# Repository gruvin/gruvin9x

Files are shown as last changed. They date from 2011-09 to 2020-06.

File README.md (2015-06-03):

# This project has been superseded by [openTx](https://github.com/opentx/opentx) and [Fr-Sky's Taranis](http://www.frsky-rc.com/product/pro.php?pro_id=113) RC Transmitter

## gruvin9x
### This outdated archive was recreated from [https://gruvin9x.googlecode.com/](https://gruvin9x.googlecode.com/) for historical reference and for the many still running gruvin9x boards or its dirivitives. A friendly shout out to you all! :-)

<h2>G9X v4.x BOARD (DISCONTINUED)</h2>

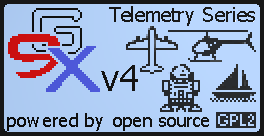
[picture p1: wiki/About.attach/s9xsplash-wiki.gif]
Why? Because there's much better things on the horizon -- we think. Trusted sources confirm the ongoing development of a Fr-Sky X9D transmitter, which we understand will be supporting open9x firmware form launch. The board will be ARM 32-bit based and is rumoured to be targeting sub-USD$100 retail -- complete with Fr-Sky 16-channel transmitter module, built in. If this all turns out to be true, then the complete radio will cost less than the G9X board (in the small qty's we can manage) whilst having all the same features and more. So we wait.

We simply don't know if demand for the G9X system will continue -- or not. Whilst orders seem to still be trickling in -- now even for blank boards (wow!) -- we don't expect that to last. Right or wrong, Gruvin made the choice, not to risk funds on another batch of G9X v4.2 boards. Was it the right choice? Have your say at <a href='http://9xforums.com/forum/viewforum.php?f=66'>9xforums.com</a>.<br>

<h2>We recommend openTx firmware</h2>

Please visit the [openTx website](http://open-tx.org) or the [openTx project on GitHub](https://github.com/opentx/opentx) for more information.

---

<h2>Gruvin9X Project Brief</h2>
<blockquote><i>First off, we especially wish to thank all the amazing original and ongoing work by</i>Thomas Husterer<i>of the <a href='http://code.google.com/p/th9x/'>th9x project</a>. A good number of other people have also contributed ideas, code and more to his, this and other related projects. THANK YOU all!</i></blockquote>

The gruvin9x project was originally forked from <code>er9x v1.1 r262</code> (<a href='http://code.google.com/p/er9x/source/browse/?r=262'>http://code.google.com/p/er9x/source/browse/?r=262</a>) which was based on a earlier version of the original th9x code. A huge amount effort was later put into the gruvin9x code base by contributor bsongis, of the <a href='http://open9x.googlecode.com'>open9x</a> and <a href='http://companion9x.googlecode.com'>companion9x</a> projects, which later became the sole point of focus for our custom hardware firmware support.<br>

<b>Highlights ...</b>
<ul><li><a href='wiki/About.md'>Project Wiki Documentation</a>
</li><li><a href='wiki/ReProgram.md'>Re-programming Your 9X Radio</a> -- firmware downloads, flashing, etc.<br>
</li><li><a href='wiki/PCB.md'>Custom Main Board Development</a> -- <b>upgrade your '9X controller board!</b></li></ul>

<h2>But what <i>is</i> it?</h2>
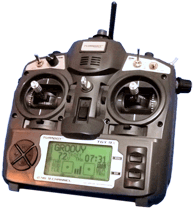
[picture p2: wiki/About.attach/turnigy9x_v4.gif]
In short, this is an RC modeller/hacker's dream come true. We get to use your own custom firmware in our radios, adding features and making changes whenever we like and all (generally) at much lower cost than comparable commercial gear -- especially in terms of firmware features and programmability. We currently support any PPM transmitter module, with a focus on Fr-Sky two-way products, as well as DSM, DSM2 and DSMX 'retro-fitted' modules, usually salvaged from cheap 4-ch bind'n'fly models, as found on eBay.<br>

Open9x firmware is written and maintained by active RC modellers. It is mature, stable and very powerful. Based on th9x's 'multiplexer' implementation, it is arguably a little difficult to learn compared to other systems -- but is much more flexible. Open9x firmware is a significantly more powerful replacement for the comparatively simple default factory firmware that comes with the '9X radios.<br>

The <a href='wiki/PCB.md'>gruvin9x custom controller board</a> was developed using a larger version of the original Atmel AVR chip, to give us more RAM, firmware code space and more I/O connections for additional peripherals, such as telemetry data port, RTC/SD-card interface and more.<br>

If your existing transmitter doesn't do something you wish it would, chances are that open9x already does. If it doesn't, then put in a feature request and, if it makes sense to others, then the firmware will likely soon perform your new function.<br>

Both the open9x firmware and the companion9x (desktop) projects support our poplar <a href='wiki/PCB.md'>G9X v4 Custom Controller board</a>.<br>

<blockquote><i><b>Caveat</b>: Firmware is  half the story -- quality of hardware is not a given and should also be carefully considered. Whilst the build quality of most 9X radios seems just fine, there have been notable exceptions. We therefore strongly recommend that all firmware functions as well as internal radio soldering joints and physical gimbal assembly be carefully checked, before committing a 'cheap' 9X radio controlled aircraft to the skies. SAFETY FIRST!</i></blockquote>

The original <a href='http://code.google.com/p/th9x/'>TH9X project</a> was (and very much still is) about completely replacing the factory supplied operating system in the Turnigy/Eurgle/iMax/Fly-Sky/etc 9X Remote Control transmitter from China -- currently retailing for around USD$40 -- HOW, we do not know!<br>

From there, other projects then spawned (were forked forked) from TH9X, including ER9X and gruvin9x. More are likely to follow as different interest focuses emerge. In our case, the focus was originally on providing practical Fr-Sky telemetry support and more recently, the design and production of an <a href='PCB.md'>custom controller board</a>, to be a drop-in, upgrade replacement for the stock '9X system controller.<br>

There's more about gruvin9x on the <a href='wiki/About.md'>About</a> wiki page.<br>

<h3>Documentation</h3>

## Best Source of Information for openTx (June 2015)
Head over to <a href='http://www.open-tx.org/'>http://www.open-tx.org/</a>

For G9X hardware or historical information, please consult the <a href='wiki/About.md'>project wiki</a> in the first instance, as well as the <a href='firmware/doc'>firmwar/doc/ directory</a>  for ~~all currently available~~ archival gruvin9x documentation.<br>

<h3>Other '9X OS Replacements</h3>

There's also at least one other project taking on the same basic goal, but of completely different design and unrelated to the TH/ER/gruvin9X projects. It's named Radio Clone, can be found at <a href='http://radioclone.sourceforge.net/'>http://radioclone.sourceforge.net/</a> and is well worth checking out.<br>

<h2>Downloading gruvin9x Firmware and Flashing Your Radio</h2>

For details on installing new firmware into you Turnigy/iMax/Eurgle/etc 9X RC Radio, see the <a href='FlashGuide.md'>Flash Guide</a> wiki page.<br>

<h2>Getting the gruvin9x Source Code</h2>
See the <a href='wiki/CompilingFromSource.md'>Compiling from Source</a> wiki page.<br>

<h2>Get Involved!</h2>
An independent group maintain an, 'all things 9X' forum over at <a href='http://openrcforums.com'>http://openrcforums.com</a>. The forum caters to several different firmware projects, has a documentation wiki attached and is probably the most popular hang-out for '9X enthusiasts and much more besides. Frankly, it's freaking AMAZING! Go check it out.

## Gruvin9X Project Wiki</a>
(converted from old Google Code site)

* [About gruvin9x](wiki/About.md)
* [G9X Features](wiki/Features.md)
* [Screen Shots](wiki/Features.md)
* [General FAQ](wiki/FAQ.md)
* [Re-progamming Your Radio](wiki/ReProgram.md)
 * [Latest Stable Binaries](wiki/LatestRelease.md)
 * [Development Binaries](wiki/DevBinaries.md)
 * [Flashing Binary Versions](wiki/FlashGuide.md)
 * [Compiling from Source](wiki/CompilingFromSource.md)
 * [Make Options](wiki/MakeOptions.md)
* [Custom PCB (v4.x)](wiki/PCB.md)
 * [Custom Schematics](wiki/Circuitry.md)
 * [Build Your Own Board](wiki/PcbAssembly.md)
 * [SD Card Installation](wiki/SdcardBoard.md)
 * [9X Reference Data](wiki/TurnigyV2.md)
  * [Reference Images](wiki/ReferenceImages.md)
  * [V2 Circuit Schematic](wiki/SchematicV2.md)
  * *[v4.x Custom Board FAQ](wiki/V41FAQ.md)*
  * *[Get your own PCB made](wiki/PCBFab.md)*
* [USB Programmer](wiki/GProg.md)
* [Telemetry](wiki/Telemetry.md)
 * [Fr-Sky Support](wiki/FrSky.md)
 * [Fr-Sky Interfacing](wiki/FrskyInterfacing.md)
 * [Fr-Sky on your Mac](wiki/FrSkyTerminalOSX.md)
 * [Porting to ER9X](wiki/FrskyToER9X.md)
* [Donator Recognition](wiki/Recognition.md)
* [Random Notes](wiki/RandomNotes.md)
 * [AoA / LRI Notes/Ideas](wiki/AoA.md)
 * [Backlight Information](wiki/BackLight.md)
 * [eePe EEPROM file manager](wiki/eePe.md)
 * [PPM-in Compatibility (Hack)](wiki/PpmIn.md)
 * [Ni-Mh packs! Or not?](wiki/PowerCells.md)
 * [Repeat Delay](wiki/RepeatDelay.md)
 * [Speaker Upgrade](wiki/SpeakerReplacement.md)
 * [Voltage Averaging](wiki/VoltageAveraging.md)

## External Links
 * <a href="http://open-tx.org" rel="nofollow" style="font-size:2.0em"><b>openTx</b></a>
 * <a href='http://code.google.com/p/er9x/'>Original ER9X Project Home</a>
 * <a href='http://code.google.com/p/th9x/'>ORIGINAL, Original TH9X Project Home</a> "Respect!" :-D
 * <a href='http://sourceforge.net/apps/mediawiki/radioclone/'>Radio Clone Project</a> -- Something different and well worth checking out.
 * <a href='http://www.rcmodelreviews.com/tendollarbattery.shtml'>$10 Li-Ion Battery Pack Upgrade</a>
 * <a href="http://code.google.com/p/frsky-terminal/" rel="nofollow">FrSky Terminal (OS X)</a>
 * <a href="http://openpnp.org/wiki/index.php/Main_Page" rel="nofollow">OpenPnP</a>
 * <a href="http://www.rcgroups.com/forums/member.php?u=301789" rel="nofollow">Argos&#39;s &#39;9X Modd&#39;ing Blog</a>
 * <a href="http://code.google.com/p/er9x/" rel="nofollow">er9x</a>
 * <a href="http://code.google.com/p/th9x/" rel="nofollow">th9x</a>
 * <a href="http://radioclone.org/" rel="nofollow">radioclone</a>
 * <a href="http://9xforums.com/forum/" rel="nofollow">9X Forums</a>
 * <a href="http://companion9x.googlecode.com" rel="nofollow">companion9x</a>
 * <a href="http://www.fsf.org/about/what-is-free-software" rel="nofollow">What is &#39;free&#39; software?</a>

```

```
<h3>DISCLAIMER</h3>
Whilst the gruvin9x project owner(s) aim to provide as much help to as many Turnigy/iMax/Eurgle/etc '9X users as practical, any perceived enthusiasm on their part to lure people into using gruvin9x over any other version, would be erroneous. This project was originally created primarily for the author's own use -- and of course to 'give back' to the Open Source Community, as the <a href='http://www.gnu.org/licenses/gpl-2.0.html'>GNU General Public License (V2)</a> requests. Anyone is welcome to use this code according to said license, as is, where is and indeed to submit suggestions for changes, improvements, additions, etc. The author welcomes comments, constructive criticism, assistance and general feedback but accepts no responsibility for anything what-so-ever that use of any information contained on this website may or may not be claimed to cause. Use at your own risk. Any opinions offered by this internet resource are expressly, only opinions. (Any information claiming to be fact but not legally verified as fact in actuality, must of course be considered mere opinion, regardless of context.) All care is taken, but no responsibility is accepted for the level of accuracy of any information here or anywhere the author may post text, images, video, audio or other content. Any and all images, photographs, charts, lists or graphical representations of any kind are intended for educational or indicative purposes only and may or may not accurately represent any given subject, topic or fact at any given time. Indeed, any such depictions are subject to change at any time for any reason without notice. Any monetary figures, presented by whatever means, are for indicative, informational or educational purposes only and all such figures are subject to change at any time without notice. The use of sarcasm may or may not feature throughout this internet resource and other, related or linked media, and as such is intended purely as light-hearted humour. No responsibility is accepted for anything what-so-ever relating to perceived truths related to such believed communications. Reader/viewer/listener beware! Any views expressed by individuals other than project owner(s) may or may not agree with the projects goals, intentions or license and no responsibility is taken for any such view or views under any circumstance. Any views so interpreted as being those of the gruvin9x project owner(s) should be taken as potentially inaccurate and with the acceptance that any views, expressed or implied, are at all times subject to change without notice. This disclaimer falls within the above conditions, being itself subject to change at any time without notice. In light of the afore mentioned disclaimers, readers should take heed of the possibility that they may be, a) potentially crazy for reading this far in the first place and, b) that this disclaimer itself, though quite serious, is in part also intended for entertainment purposes. Etc, etc, blah blah. You know the drill. Love and peace to all! Now let's get on with it. :-D

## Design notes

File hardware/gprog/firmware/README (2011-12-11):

USBasp Firmware, modified for use with gruvin9x custom controller board.

The USBasp original author's project site is at: http://www.fischl.de/usbasp/

NOTES ...

As at 2011-12-11, GPROG is NOT ready for use. There's a problem with the buffer
chip tying up the MOSI/MISO/SCK/RESET lines. The fix will required changed to the
hardware design.

This version of USBasp is based on the original 2009-02-28 version -- the last
one to fit in the ATmega48P -- with the support added from the 2011-05-28
version to implement extended addressing for target AVR chips with greater than
128KBytes Flash, like the ATmega2560 that we use.

There was (still is as at 2011-05-28 version) a bug  in the original USBasp
code for extended addressing in that it assumed that the target chip's extended
address would be automatically reset to 0x00 after power-up and/or entering
programming mode. This is not the case. In fact, I found the extended addresses
contents to be somewhat random, usually causing all the programmed code to wind
up 64KBytes higher in address space than it should have been.

The default SCK clock speed has been increased from 375KHz to 1.5MHz, although
the gain is not that much, due to the software implemented USB stack taking up
quite a lot of CPU time.

Strangely, having the brown-out detector on the ATmega48 enabled causes my
(Gruvin) Mac (running OS X 10.7) to not detect the USBasp device. So I've
disabled the BOD feature, apaprently without ill effect.

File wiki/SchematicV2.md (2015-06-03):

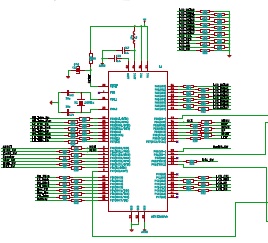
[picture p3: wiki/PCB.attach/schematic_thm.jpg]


<h1>Turnigy/iMax/Eurgle/etc 9X RC Transmitter Version 2 (V2) Schematic</h1>

There exists (in trunk/doc) a PDF circuit schematic, which appears to be from the version 1 radio. Here is link to a V2 schematic, which includes a couple of changes, most notable being the addition of a regulator and voltage-splitter resistor network to drive a 3.3V LCD display.<br>
<br>
Here is a link to the our version of the <a href='https://code.google.com/p/gruvin9x/source/browse/#svn%2Freference%2Fv2_stock_9x'>factory stock 9X schematic</a> files.

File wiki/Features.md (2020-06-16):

# This project has been superseded by [opentx](http://opentx.googlecode.com/) #

The following data is likely obsolete, kept here for mostly just for historical record.

# G9X Features

## Screen Shots

### Main Screen
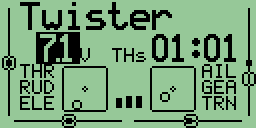
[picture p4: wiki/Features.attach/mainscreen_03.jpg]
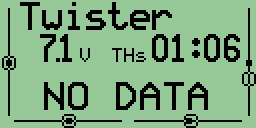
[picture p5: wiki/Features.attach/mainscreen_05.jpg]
 

### Model selection
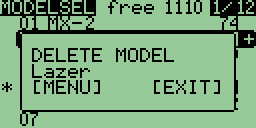
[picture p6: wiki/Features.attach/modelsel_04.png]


### Flight Phases
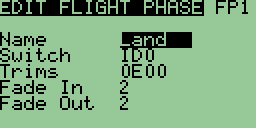
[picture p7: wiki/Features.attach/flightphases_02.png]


### DR/Expos Screens
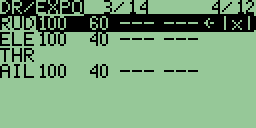
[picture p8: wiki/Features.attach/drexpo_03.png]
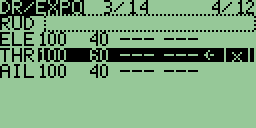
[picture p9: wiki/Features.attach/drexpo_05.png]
 

### Calibration
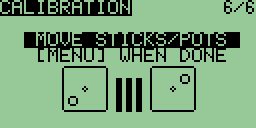
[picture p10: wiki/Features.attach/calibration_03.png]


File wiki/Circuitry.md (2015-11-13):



<h1>Custom '9X Logic Board PCB Schematics</h1>

The custom circuitry for Gruvin's '9X has gone through a number of versions, and continues to evolve.<br>
<br>
<h2>Current Design</h2>
The final version of the G9X board was v4.2d.

- - - -

Archival information ...

Ongoing schematic and PCB design currently takes place at <a href='http://gruvin9x.googlecode.com/svn/trunk/hardware/pcb/'>http://gruvin9x.googlecode.com/svn/trunk/hrdware/pcb/</a>. There you'll find a <a href='http://kicad.sourceforge.net/wiki/Main_Page'>KiCAD</a> project file named <code>gruvin9x.pro</code>, with internal references to <a href='http://gruvin9x.googlecode.com/svn/trunk/pcbv4/gruvin9x.sch'>gruvin9x.sch</a> and <a href='http://gruvin9x.googlecode.com/svn/trunk/hardware/pcb/gruvin9x.pcb'>gruvin9x.pcb</a>.<br>
<br>
<b>As at 22 September 2011, we've progressed to v4.0</b> and are working hard to release a board for general consumption. It is our firm intention to finally do just that with v4.1, hopefully before December, 2011. Version 4.0, final prototypes have been assembled (x4) and are being tested and debugged. A number of beta testers are being lined up for the first few v4.1 production boards. Simply put, we're going as fast as we can.<br>
<br>
You can find detailed information about the new board's intentions, current functionality and progress on the <a href='PCB.md'>Custom PCB</a> wiki page.<br>
<br>
Check out the source tree in the <a href='http://code.google.com/p/gruvin9x/source/browse/#svn%2Ftrunk%2Fhardware%2Fpcb'>/trunk/hardware/pcb</a> folder for the latest work-in-progress design files.<br>
<br>
<h1>Historical Data</h1>

<h2>First Prototype</h2>
The first physical prototype, 'rev 2.14' PCB design, schematic and production files, as sent to the PCB fabrication factory in December of 2010, can be found at <a href='http://gruvin9x.googlecode.com/svn/archive/pcb/pcb-v2.14-frozen'>http://gruvin9x.googlecode.com/svn/archive/pcb/pcb-v2.14-frozen</a>. There's a PDF version of the schematic, <a href='http://gruvin9x.googlecode.com/svn/trunk/pcb/rev2.14-frozen/gruvin9x.pdf'>here</a>.<br>
<br>
<h3>Original 'Hacked' Radio</h3>
Gruvin's original '9X radio was the original test bed for much of pre-v3-PCB work. As such, it remains a reference for people wishing to manually modify factory stock '9X radios for use with Fr-Sky telemetry. There's an historical PDF version of the schematic for this 'hacked' board, <a href='http://gruvin9x.googlecode.com/svn-history/r800/trunk/pcb/hacked/gruvin9x-hacked.pdf'>here</a>.<br>
<br>
If you have a stock '9X radio and would just like to add basic Fr-Sky telemetry functionality to it, then there are (hopefully) easy to follow instructions on the <a href='FrskyInterfacing.md'>Fr-Sky Interfacing</a> wiki page.

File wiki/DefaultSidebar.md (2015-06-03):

# G9X Wiki
## Table Of Contents

* [About gruvin9x](About.md)
* [G9X Features](Features.md)
* [Screen Shots](Features.md)
* [General FAQ](FAQ.md)
* [Re-progamming Your Radio](ReProgram.md)
 * [Latest Stable Binaries](LatestRelease.md)
 * [Development Binaries](DevBinaries.md)
 * [Flashing Binary Versions](FlashGuide.md)
 * [Compiling from Source](CompilingFromSource.md)
 * [Make Options](MakeOptions.md)
* [Custom PCB (v4.x)](PCB.md)
 * [Custom Schematics](Circuitry.md)
 * [Build Your Own Board](PcbAssembly.md)
 * [SD Card Installation](SdcardBoard.md)
 * [9X Reference Data](TurnigyV2.md)
  * [Reference Images](ReferenceImages.md)
  * [V2 Circuit Schematic](SchematicV2.md)
  * *[v4.x Custom Board FAQ](V41FAQ.md)*
  * *[Get your own PCB made](PCBFab.md)*
* [USB Programmer](GProg.md)
* [Telemetry](Telemetry.md)
 * [Fr-Sky Support](FrSky.md)
 * [Fr-Sky Interfacing](FrskyInterfacing.md)
 * [Fr-Sky on your Mac](FrSkyTerminalOSX.md)
 * [Porting to ER9X](FrskyToER9X.md)
* [Donator Recognition](Recognition.md)
 * [Random Notes](RandomNotes.md)
 * [AoA / LRI Notes/Ideas](AoA.md)
 * [Backlight Information](BackLight.md)
 * [eePe EEPROM file manager](eePe.md)
 * [PPM-in Compatibility (Hack)](PpmIn.md)
 * [Ni-Mh packs! Or not?](PowerCells.md)
 * [Repeat Delay](RepeatDelay.md)
 * [Speaker Upgrade](SpeakerReplacement.md)
 * [Voltage Averaging](VoltageAveraging.md)

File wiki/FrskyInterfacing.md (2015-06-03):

# This project has been superseded by [opentx](http://opentx.googlecode.com/) #

The following data is likely obsolete, kept here for mostly just for historical record.

# Fr-Sky Interfacing #

Gruvin (more or less) followed the original TH/ER9X 'JETI' wiring instructions to get RS-232 (TTL level) TX and RX signal for my Fr-Sky two-way transmitter module. Those instructions can be found [here](http://code.google.com/p/er9x/wiki/JETI).

Below, you'll find similar and extra detail of exactly how I hooked up my Fr-Sky unit.

## Accessing TXD and RXD on the ATmega ##

The ATmega RXD and TXD special-purpose pins are used for simple switch inputs in the factory '9X -- namely, Throttle-Cut and Aileron-D/R, respectively.

To free these pins up for use with serial data, we need to move those two switches elsewhere. The two pins chosen for their new home were pins 41 and 42, or PC6 and PC7 respectively.

The modification requires the use of _really fine_ wire. I used 0.2mm, enamelled copper wire. You can also use fine, insulated wire, salvaged from the newer (yet now old) high-density computer IDE cables. Each of these wires is a _single-core_, PVC insulated wire. You most definitely do _not_ want to try and use any kind of multi-strand wire -- no matter how fine it it is.

**IMPORTANT**: The main reason to use _really_ fine wire may not be what you think. It is certainly possible (though more difficult) to use heavier, stronger wire. But doing so will increase the risk of accidentally damaging the delicate ATmega chip's pins. (Think of it as using a wrecking bar to pick your teeth -- or something like that! :P) In practice, the slightest accidental tug by 'big fat, shaky, human hands on a big fat wire', can quite literally rip an ATmega pin right of the chip. Trust me -- _use really fine wire!_

### Re-wiring Procedure ###

Referring to the image below ...

  * Remove the two left-hand-most resistors as indicated in yellow
  * Hot glue a couple of 220ohm resistors (1/8th or 1/4watt are OK) to a nearby, clearish area of the PCB
  * Solder your 'super fine' wires to pins 41 and 42 of the ATmega and connect to the top end of the resistors as shown. Use alcohol if required -- to steady your hands! (Just joking -- but if it works for you -- go right ahead. :p)
> _HINT: Pre-solder the wire end and the ATmega pins. Use a solder sucker or de-soldering wick to clear away excess solder from the two pins and to remove any solder bridge. Then lay the first wire end over the pin and apply the soldering iron directly down on top of it for half a second, then directly straight up -- then let go the wire. Give the wire a gentle tug in the direction directly away from the chip (in line with the pin).If it holds -- you're done. Don't futz with it. If you're right handed, solder the left hand wire first, so the the soldering iron does not lay over the first wire when trying to solder the second._
  * Solder wires from the bottom ends of the hot-glued resistors to the little vias (holes) near where the two removed resistors were, as shown in the image.

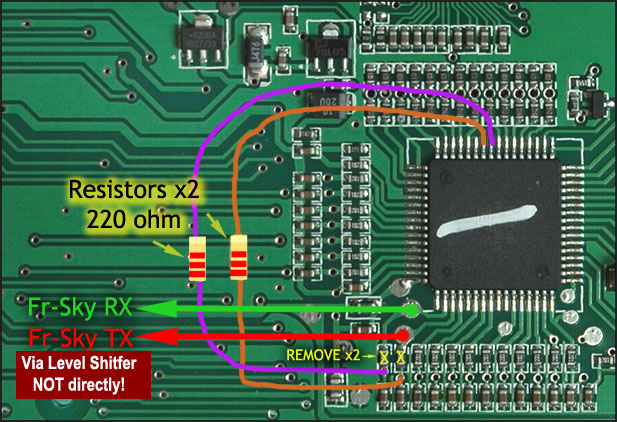
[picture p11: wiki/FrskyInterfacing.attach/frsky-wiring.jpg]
> 

**NOTE:** It pays to use small dabs of hot-glue near the ATmega pins and in a couple of places along the wires to hold them in place. The last thing you want is for something to get hooked under them and rip them off, possibly damaging the ATmega pins in the process!

## The Interface ##

Fr-Sky, in their wisdom, decided to use RS-232 voltage levels for their interface, rather than provide a more modern 5V TTL-to-serial USB interface. We tried to talk them out of it, but they stuck to their guns. Oh well.

What this means is that you need to invert and voltage-shift the signals to and from the Fr-Sky transmitter module, so they can play happily with the 5 Volt ATmega chip. There are specialised 5V TTL to RS-232 chips to do this, "properly". But we show here is a simple and in fact _advantageous_, discrete transistor method.

> _Advantageous? Well yes, actually. The method shown below allows the transmitter module to still operate -- for both hosts simultaneously -- when connected to an external serial interface, say on a computer -- while not having to disconnect the internal wiring to the '9X. With the values shown, most computers will take precedence over the internal 9X ATmega micro in terms of sending (transmitting) data to the Fr-Sky module. **More useful even**, is that you don't have to disconnect the telemetry interface for re-Flashing. Clever huh! (In truth, this was a lucky fluke! :P)_

> _That said, be careful not to have your Fr-Sky two-way receiver switched on during re-flashing, as the stream of data_will_collide with the ISP programming signals and could mess up your ATmega chip._

Here is the discrete transistor circuit ...

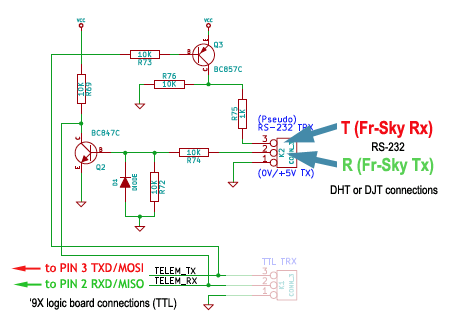
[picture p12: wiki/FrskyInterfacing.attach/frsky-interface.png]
> <br />
**NOTE** An earlier version of the above circuit had the collector and emitter of Q3 reversed. The circuit as shown here now is correct. (This circuit is clipped from the full schematic of the gruvin9x [custom controller board](PCB.md).)

Any general purpose NPN and PNP transistors should work for the components marked Q2 and Q3, respectively. The BC847/857 devices are in fact SMD surface mount versions, as used in the new PCB design we're working on.

For the prototype, Gruvin actually used a dremel too to carve up the mostly unused, legacy PCB mounted inside the '9X rear casing to build the above circuit 'dead bug' style. (A photo is not presently available.)

**ADDENDUM**: A future version of this circuit (v4.2) uses 5.1K-Ohm resistors in place of all the 10K and a 1K across Q3's E/C leads to improve the 'squareness' of the TX signal for use with DSM2 modules at 125,000bps. This change is in no way required for 9600 Baud Fr-Sky operation however.

## Ground Loops (WARNING) ##

Gruvin found that the Fr-Sky module refused to operate correctly if a ground (GND) wire was connected between the Fr-Sky module's rear RX/TX/GND pins and the level-shifting circuit above. The problem was probably RF energy pick-up through the ground-loop created by having two ground wires -- one where the module plugs into the 9X and the other from the serial data port. **Solution:** simply do not connect the ground wire as shown as pin-1 on the connector-K2 in the circuit above. Others have since said that they had no such problem. YMMV

### ER9X Compatible ###

In case you're wondering, this wiring modification is 100% compatible with the JETI and Fr-Sky telemetry extensions in the [ER9X](http://er9x.googlecode.com/) firmware, too.

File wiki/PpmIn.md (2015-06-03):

# This project has been superseded by [opentx](http://opentx.googlecode.com/) #

The following data is likely obsolete, kept here for mostly just for historical record.

# PPM-in Compatibility (Hack) #
**Relates to [Issue 15](https://code.google.com/p/gruvin9x/issues/detail?id=15)**

While working on various problems with PPM-in (aka. trainer/trainee) system, I discovered that Spektrum branded radios do not supply a signal capable of being used by the stock '9X radio's electronics.

Spektrum (and I presume JR? And Futaba?) output their PPM signal (via the phono jack on the back) as an approx. 1.5V peak-to-peak signal, which is also capacitively decoupled.

This scheme actually makes sense to me because it, a) prevents potential damage if the lead is somehow shorted out and, b) is much less likely to in any way inadvertently load or 'spike' the host or slave device in a way that could crash the CPU.

I have no idea what the Futaba/JR/Hi-tech scheme for this is, but I do have two Spektrum radios and I wanted them to be usable as trainer/trainee slaves with my Turnigy '9X. So, out came the soldering iron, once again.

I broke the track leading from the 4066 quad-switch chip (pin 8) and into PE7 on the ATmega, then inserted an NPN buffer transistor -- essentially to 'amplify' the 1.5V signal back up to 5V-TTL for the ATmega. A side-effect of this that the signal gets inverted. (I could have used a PNP transistor to prevent the inversion, but that would have created other issues.) The inversion was easily fixed by changing a single binary bit in the program code. This is optional of course -- please see the notes for `PPMIN=` on the [Make Options](MakeOptions.md) wiki page.

> _As of this writing, this code change is only available in the `branches/frsky` development repository. But I'm sure it will make its way into the `trunk/` area quite soon._

Here is the additional circuitry, which has been tested to work well with two Spektrum and one '9X radio, thus far.

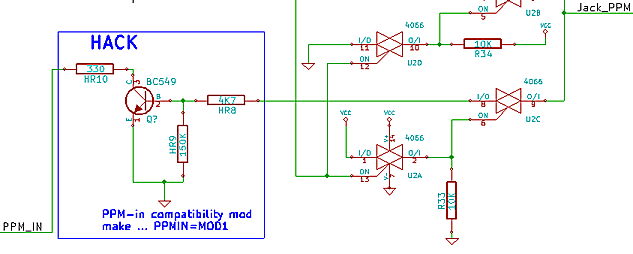
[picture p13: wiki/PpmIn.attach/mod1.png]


> _Resistor HR10 (330ohm is what I had on hand) proved important. Without it, the relatively high current sink from the transistor against the ATmega's internal pull-up was able to spike the ATmega's power supply sufficiently to cause the odd crash. I imagine the net resistance of the 4066 was sufficient 'spike' protection, before this mod. **shrug**_

# The Future (Custom PCB V3+) #

I will definitely include at least this mod in the V3 PCB (after the V2 prototype has had its potential bugs ironed out). I may go further to include a capacitive decoupling arrangement, and hopefully remove the need for the 4066 altogether.

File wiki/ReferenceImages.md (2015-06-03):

# Hardware Reference Images #

Here are some annotated photos of various '9X hardware components to assist with part identification, PCB replication, LCD replacement, etc.

Note: Some of the images are fairly high resolution on purpose.

## LCD Screen ##
We believe the following are the main specifications of this display ...
  * Dimensions:  77 x 48mm.
  * Pixel View Area: 66.52mm x 33.24mm -- 2.9" diagonal (0.48mm sq. pixels with 0.04mm gaps)
  * Front Polariser: Transmissive (Adhesive)
  * Back Polariser: Transflective (Adhesive)
  * Display Mode: FSTN
  * Viewing Angle: 90-degrees perpendicular (6:00 o'clock)
  * Controller IC: **ST7565P** (very common) -- "chip on glass" version
  * Operating Voltage: 3.3V (not 3.0V)
  * Connector: COG+FPC 30-pin, 0.5mm pitch
  * Manufacturer: Unknown
  * [Mechanical data sheet](ReferenceImages.attach/lcd-display-mechanical.pdf) for similar display,  [here](ReferenceImages.attach/lcd-display-mechanical.pdf). (Thanks [@devnow](https://code.google.com/u/100578513419733812290/).)

  * **Replacement part availability** ...
    * Try [eBay.com](http://www.ebay.com)
    * Or [www.BuyDisplay.com](http://www.buydisplay.com). I found nothing the same size with the same 30-pin connector, at BuyDisplay. But there is [this one](http://www.buydisplay.com/default/2-9-inch-cog-lcd-module-128x64-display-arduino-st7565p-white-on-black.html) at US$6.52, which is the right size and controller chip, but a 26 contact cable. :-/ There is also a smaller 2.1" display, which would fit in a '9X and does have the right 30-pin cable.
    * The [R2Hobbies](http://www.r2hobbies.com/eng/proddetail.php?prod=rcps2845001) supply of TH9X spare part displays has dried up.

- - -

I've not personally owned a V1 '9X, but apparently the V2 changed from a 5V LCD screen to a 3.3V version. An additional 3.3V regulator and a bunch of voltage-divider resistors are used to interface this to the 5V ATmega64A MCU.

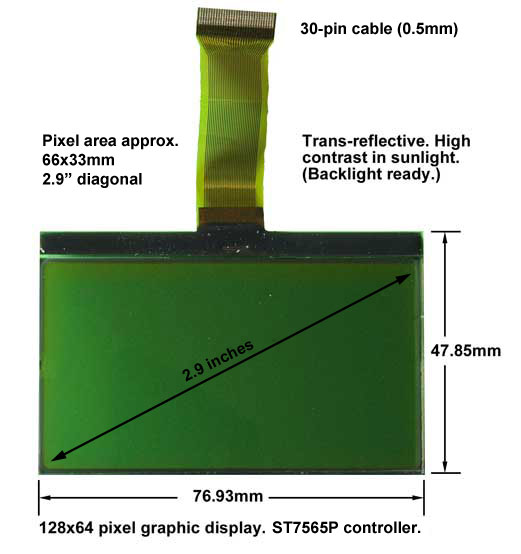
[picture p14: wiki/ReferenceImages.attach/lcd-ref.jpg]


## Connectors ##
See the PCB reference images for approx. dimensions. (Ignore the strange looking coil of wire to the middle-left. It's not part of the stock hardware.)

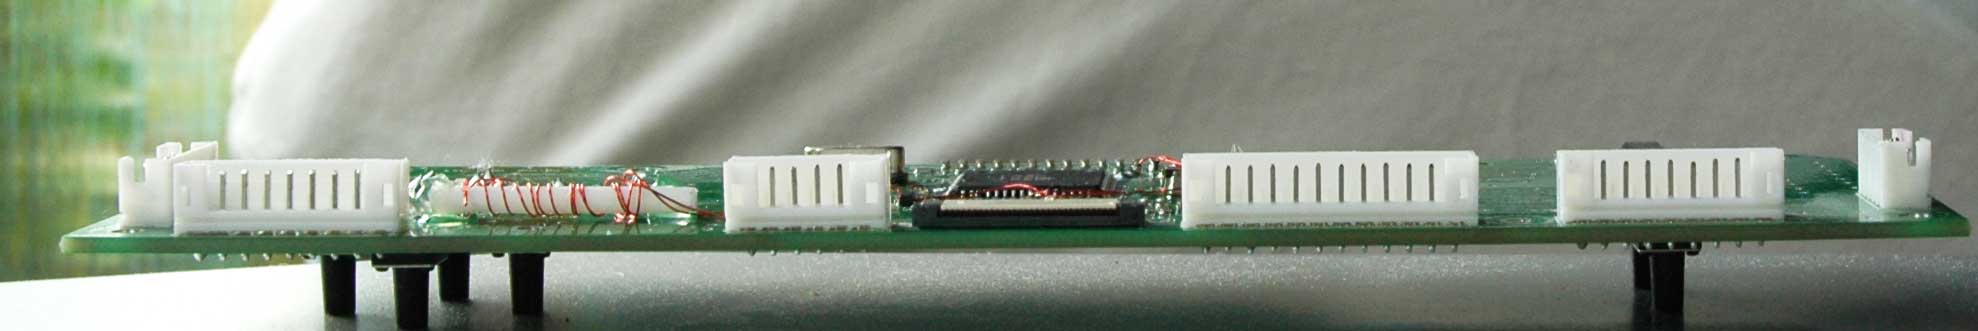
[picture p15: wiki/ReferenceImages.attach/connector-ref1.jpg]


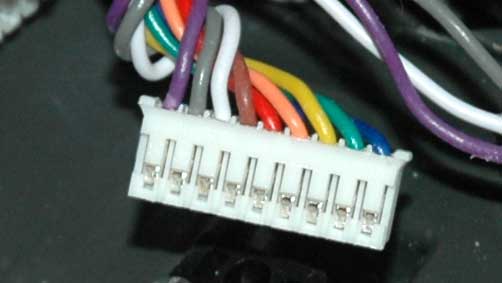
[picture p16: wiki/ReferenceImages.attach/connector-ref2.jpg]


Japanese "JST" brand -- 2mm pitch (there's a larger version as well.) Quite common.<br>
<br>
<h2>Inside</h2>

Inside the front section of the cabinet (main PCB removed).<br>
<br>
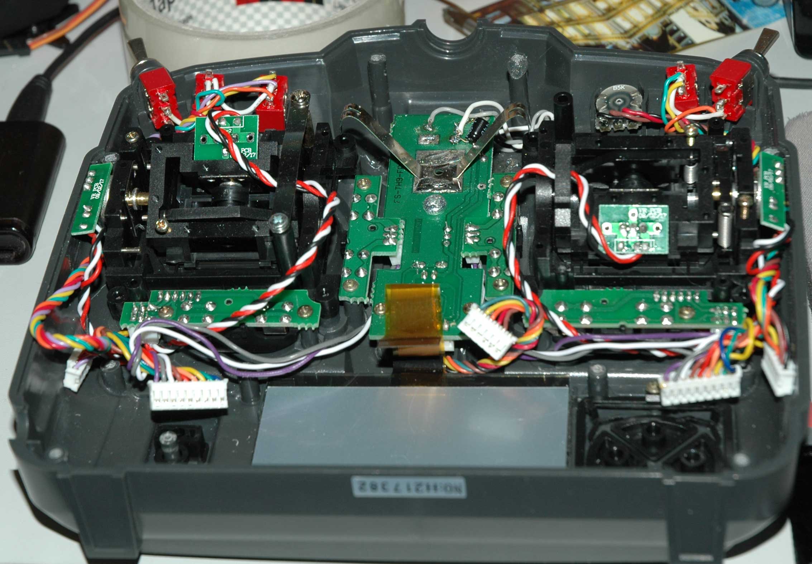
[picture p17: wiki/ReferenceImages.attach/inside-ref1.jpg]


<h2>Main PCB</h2>

My '9X is a Turnigy 9X from HobbyKing.com. This is the "V2" version. Note the additional 3.3V regulator (left of the 5V one) and bunch of resistors above the ATmega64A MCU for driving the 3.3V LCD screen.<br>
<br>
<h3>Top</h3>

NOTE: These images are fairly high resolution -- Right-Click, View Image (or Save as...) to see full size. WARNING: Perspective errors in the camera lens mean the reference lines are approximate only.<br>
<br>
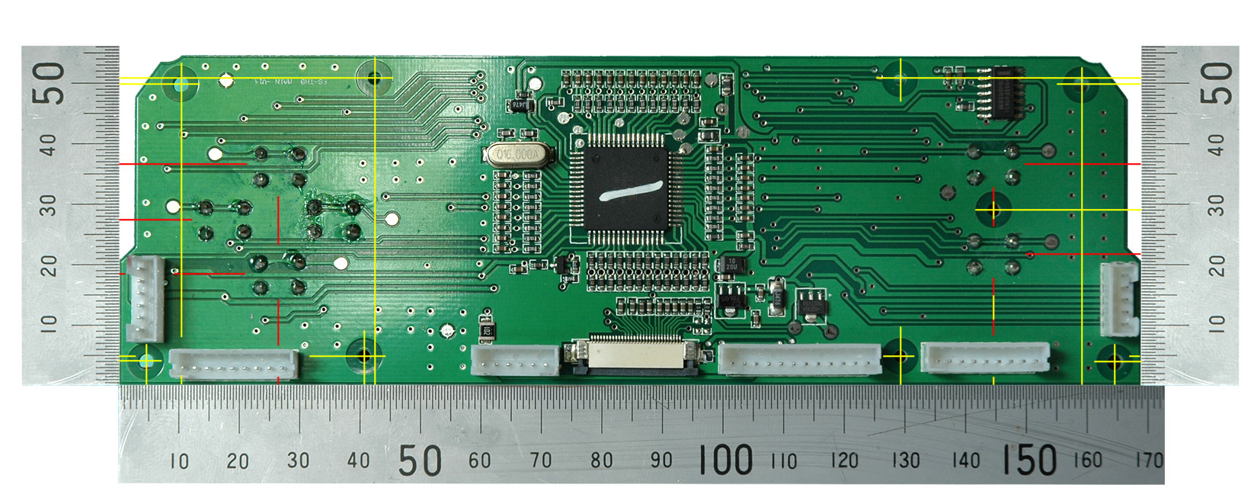
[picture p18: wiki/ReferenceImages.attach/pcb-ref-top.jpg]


<h3>Bottom</h3>

This is the bottom of my second unit (to match image above).<br>
<br>
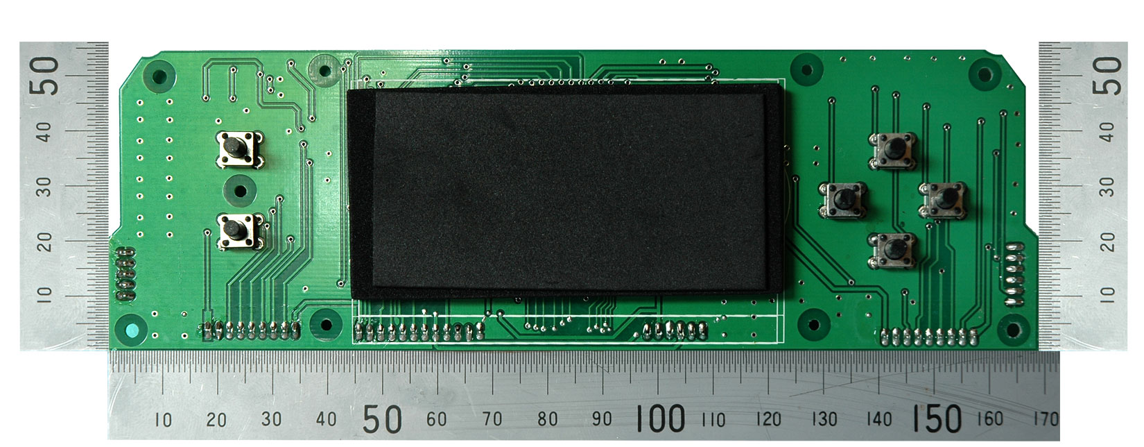
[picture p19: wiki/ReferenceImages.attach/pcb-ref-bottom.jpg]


I removed the LCD screen's foam packer on my original unit to reveal all the traces. (Hi-res.)<br>
<br>
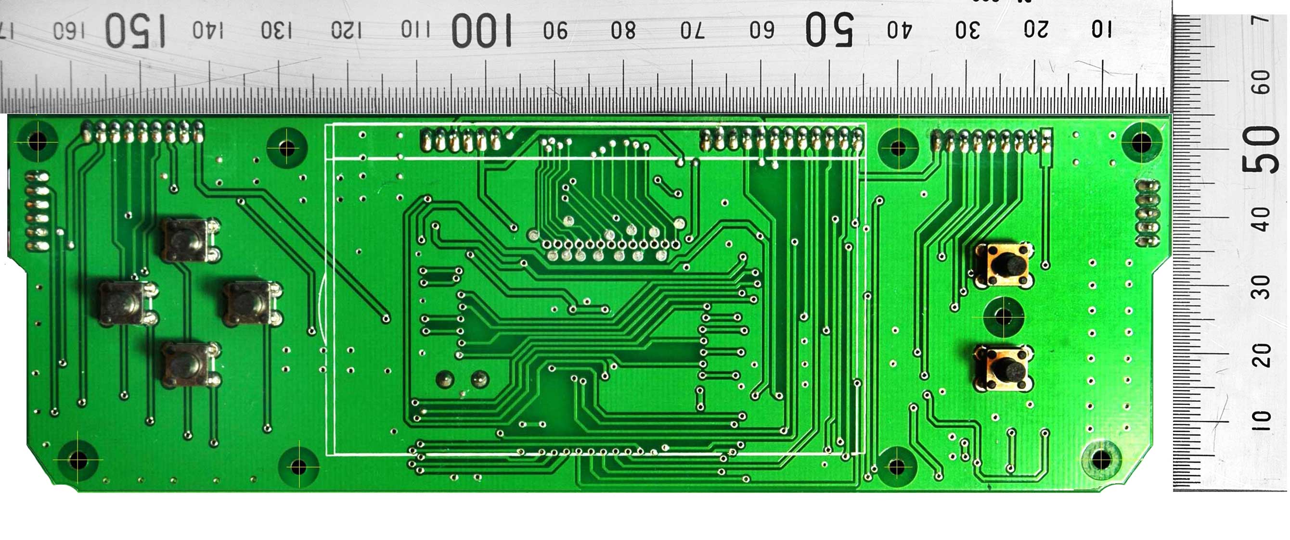
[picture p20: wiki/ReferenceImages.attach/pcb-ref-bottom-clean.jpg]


<h3>PhotoShop Layered Originals</h3>

PhotoShop is one of, if not <i>the</i> most expensive pieces of software I've ever bought. But it's been worth every penny.<br>
<br>
Here are the layered originals of the top and bottom images above -- at double the resolution, too. (Approx. 22MB each.)<br>
<br>
<br>
<a href='ReferenceImages.attach/pcb-ref-top.psd'>pcb-ref-top.psd</a>

<a href='ReferenceImages.attach/pcb-ref-bottom.psd'>pcb-ref-bottom.psd</a>

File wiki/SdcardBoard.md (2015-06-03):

# SD Card / RTC Board Installation #

Here's some pictures showing where Gruvin installed his SD card board -- and where it was designed to fit from the start, if that helps. :-D

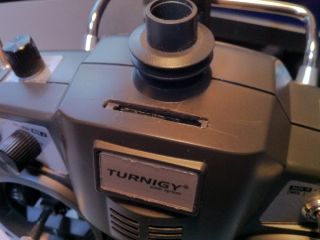
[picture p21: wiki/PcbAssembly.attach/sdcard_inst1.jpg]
|  |
|:------------------------------------------------------------------------------------------------------------------------------------------------------------|
| Almost flush. Could have done better with more care. |

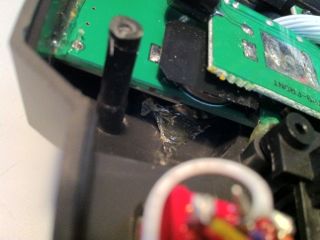
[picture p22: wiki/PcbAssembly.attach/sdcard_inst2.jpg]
|  |
|:------------------------------------------------------------------------------------------------------------------------------------------------------------|
| Speaker is lowest, then SD card, then original power switch board. |

I put tape over the button battery holder, just in case it
shorts out on something. Probably not required.

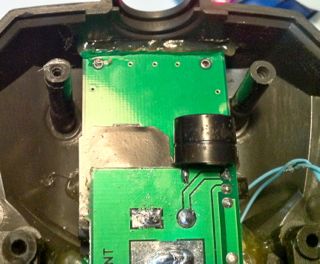
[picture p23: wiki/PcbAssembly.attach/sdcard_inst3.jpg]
|  |
|:------------------------------------------------------------------------------------------------------------------------------------------------------------|
| The original piezo "beeper" is removed and re-soldered as shown, to make room. |

**NOTES**

A recent Turnigy branded '9X was converted and found to have slightly **different piezo beeper circuitry** (a different switching transistor and PCB design around it) which doesn't quite match the photo above. In this case, the piezo was changed by simply 'swapping sides' of the board, such that it end up pointing 'up' (toward the back of the case.)

I probably over-did the hot glue a little. :-D

Oh by the way ... do NOT put a fancy, bulky, plastic connector on the SD card board where the wiring terminates. There isn't room for it. Just solder wires directly and apply some hot-glue to prevent them breaking over time.

An MMC card in an SD-card adapter works just fine. (Gruvin uses a 2GB MMC in this manner.)

The card should be pre-formatted in a computer as "Windows FAT32" -- _not_ NTFS. Most cards are supplied already formatted in FAT32 format. If you have problems, try formatting again yourself. Some people have reported problems with older, slower cards. However, this system should not require anything fancy. Class 2 or higher should be OK -- the higher the better but definitely no need to get the expensive, ultra high speed video recorder versions.

### Some more photos, of a different install ###

These photos show a different installation Gruvin did. Note that the Turnigy power switch board in this one is a later version, with different PCB trace layout around the piezo beeper area. So we simply mount the piezo on the opposite side of the board. **shrug** ...
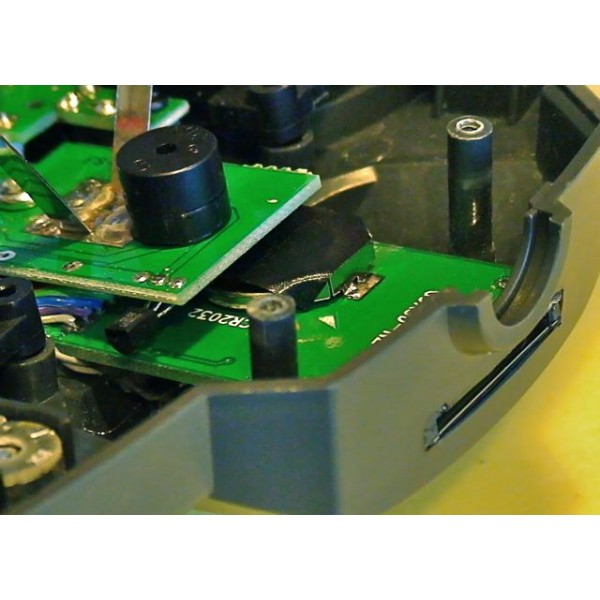
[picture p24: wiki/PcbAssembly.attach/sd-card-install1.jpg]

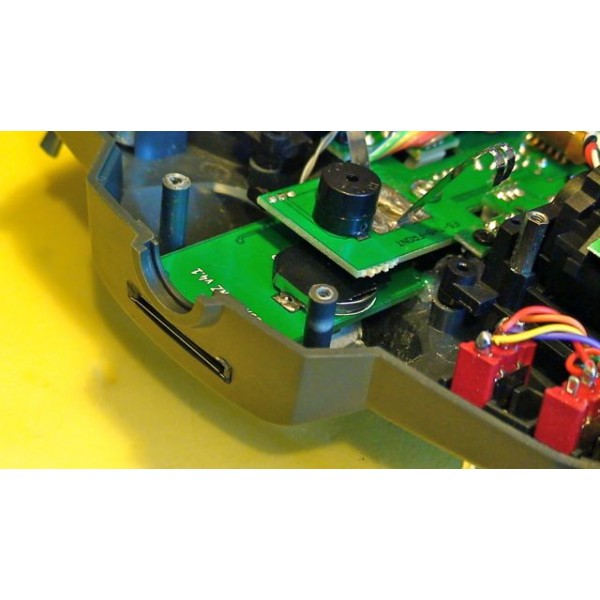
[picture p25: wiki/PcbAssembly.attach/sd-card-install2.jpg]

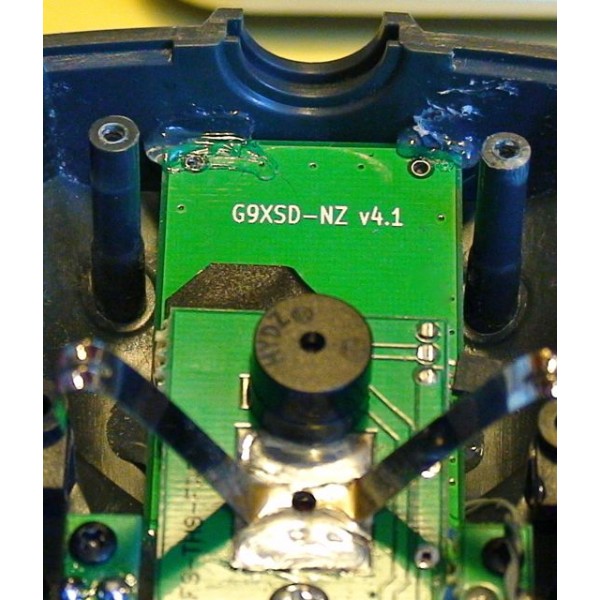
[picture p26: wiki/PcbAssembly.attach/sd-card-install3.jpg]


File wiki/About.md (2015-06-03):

# This project has been superseded by [opentx](https://github.com/opentx/opentx) and [Fr-Sky's Taranis](http://www.frsky-rc.com/product/pro.php?pro_id=113) RC Transmitter

The gruvin9x project was launched in October of 2010 and retired some time in 2012. A massive amount of work has since been done over at the [opentx](https://github.com/opentx/opentx) project, which was forked from gruvin9x by Bertrand Songis, in France. Bertrand is an incredibly talented programmer and has achieved far more than I (Gruvin) ever could have. I fully support [opentx](https://github.com/opentx/opentx) and _highly_ recommend it.

Fr-Sky's [X9D Taranis](http://www.frsky-rc.com/product/pro.php?pro_id=113) is a high quality unit, shipped with open source [opentx](https://github.com/opentx/opentx) firmware as standard. The [Taranis](http://www.frsky-rc.com/product/pro.php?pro_id=113) represents just about everything the gruvin9x project could have ever wished for and at a very fair price. Indeed, the G9X project was originally inspired by our desire to utilise Fr-Sky's two way telemetry radio modules. So we are thrilled that Fr-Sky were the ones to create the world's first commercial open source RC controller and we support their ongoing endeavours enthusiastically.

(Note: Gruvin has absolutely no affiliation with Fr-Sky. I doubt they even know who I am. :P)

The **openrc community** now resides at [Open RC Forums](http://openrcforums.com/forum/). They're a great bunch. Go check them out.

**This site/wiki remains online as a historical record, only.** 

Original content follows ...

<h1>Summary Introduction</h1>
Turnigy 9XThis project started out as a kind of 'place holder' for the author's personal circuitry upgrades, hacks and mods to his [ER9X](http://code.google.com/p/er9x/)-powered Turnigy 9X V2 RC transmitter. Over time, some more supporting documentation and random notes were added. Then Gruvin went kind of crazy one weekend and wondered if he could create a whole new, replacement controller board, to make wiring extra things to his transmitter easier. KiCAD PCB design software was chosen, because it is open source. A few prototype boards came to fruition. Then Cam (UK) came along and asked if it would be OK to have a go at installing the 100-pin ATmega2560 MCU, instead of the 64-pin ATmega2561, which Gruvin used. "Sure! Go for you life!" Cam did a great job and all that eventually resulted in what the, "G9X v4.2 Custom Controller Board".<br>
<br>
Several additional utility board designs were started and added to the project, including an RTC/SD-card interface, a custom USBasp Flash programmer and a multiplexer system, which enables the splitting of a single receiver channel into several additional control outputs. There's also been work on an audio playback module (for spoken telemetry warning etc) which appears to have mostly moved to the open9x project, as at this writing.<br>
<br>
<h1>Project Detail</h1>

The initial main focus was around adding and enhancing Fr-Sky telemetry support and the development of an <a href='PCB.md'>upgraded main logic board</a> -- for <a href='Telemetry.md'>telemetry</a> support in general, as well as a better ATmega chip and MMC/SDCARD support for model data and general mass storage in FAT16/32 format.<br>
<br>
Compatibility with the stock V2 '9X transmitter will be retained as far as possible. So fear not. There will "always" be a gruvin9x version available to run on the stock unit. There will also be different binary versions available to support the most common manual circuit hacks for telemetry (and other things) that do <i>not</i> require the <a href='PCB.md'>new PCB</a>.<br>
<br>
The first true stable, public release of gruvin9x was made in January, 2012. The release is code named, 'Frisky', is community verified 'stable' and thus believed to be essentially 'bug free'. (I hope I haven't jinxed anything by typing that! :-P)<br>
<br>
Work continues for the next version, being mostly focussed on the new V4 custom controller board, though with improvements and added features also slated for the stock radio controller board.

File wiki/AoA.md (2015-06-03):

# This project has been superseded by [opentx](http://opentx.googlecode.com/) #

The following data is likely obsolete, kept here for mostly just for historical record.

# DIY AoA Sensor Ideas / Notes #

## Links ##

  * http://diydrones.com/forum/topics/angle-of-attack-sensor

  * [Apparently working sensor using magnetic Hall effect sensors and magnets](http://www.charlesriverrc.org/articles/asfwpp/lelke_launch.htm)

> The [9SS series magnetic flux sensor](http://www.honeywell-sensor.com.cn/prodinfo/magnetic_position/installation/p87644_1.pdf) (though they call it a micro switch) used in this project has a magnetic 'input' range of -400 to +400 gauss. Plenty! The output is said to be linearly associated with input gauss, with 0 gauss being at about half the supply voltage -- 8-16V at 15mA (max).

> The AoA design uses two magnets and one Honeywell 9SS-series sensor. No detail seems to be provided as to how the magnet poles should be oriented. I'm guessing that one is configured 180 deg. (north vs. south) to the other, such that as one magnet moves away from the Hall sensor, the other gets closer. That would seem to make sense.

## Random Notes (changes regularly) ##

I dreamt up an idea involving two LDR's (light dependant resistors) with a wedge shaped 'light-blocker' that swings into the light path of one or the other, depending on the AoA. The more light that gets blocks, the higher the resistance becomes. Given a constant internal light source and the two LDR's wired as a resistive divider, this should produce some form of AoA:voltage output. I'm certain it will be anything but linear, no matter how I try to shape the light-path-blocker bit. But it might work. Experimentation is needed.

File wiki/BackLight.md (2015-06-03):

# This project has been superseded by [opentx](http://opentx.googlecode.com/) #

The following data is likely obsolete, kept here for mostly just for historical record.

# Backlight Information #

**BRIEF NOTES ONLY**

## 9x Add-on Board with built-in Programmer and EL Back-light ##

[SmartieParts.com](http://SmartieParts.com) (Steven / s\_mack on [RCGroups forum](http://www.rcgroups.com/forums/)) designed and sells a really cool, solder-less PCB that includes EL backlight driver, USB programmer interface. The board makes all its connections to your '9X PCB without a drop of solder -- using '[Pogo-pins](http://en.wikipedia.org/wiki/Pogo_pin)' -- gold plated, spring loaded, electrical contacts. (This is how the factory or retailer makes connection to the board for testing or for firmware upgrade, etc.)

See [here](http://www.rcgroups.com/forums/showthread.php?t=1338412#post16549680) for some detailed information with images, in the form of an mini-review, by Erazz (of ER9X).

I don't know how SmartieParts gets the price so low -- but I aim to find out! :-D

## Stand-alone EL Driver and EL Panel ##

If you just want an inverter and EL panel to add to your already custom '9X, [SmartieParts.com](http://SmartieParts.com) can sort you out there too. This is [revision 2](https://code.google.com/p/gruvin9x/source/detail?r=2) of Steven's design and is, by all accounts, excellent. The board includes a low-level drive control input, which you can connect directly to PB7 to control the back-light using ER/gruvin9x (and now TH9X, I think) firmware.

See [here](http://www.rcgroups.com/forums/showpost.php?p=16713596&postcount=3265) for information or [here](http://www.smartieparts.com/shop/index.php?main_page=product_info&cPath=3&products_id=333) to order.

## trunk/doc/Backlight Installation.pdf ##

There's also a back-light installation how-to written by Earl in the project documentation folder. See [/doc/Backlight Installation.pdf](http://gruvin9x.googlecode.com/svn/trunk/doc/Backlight%20Installation.pdf).

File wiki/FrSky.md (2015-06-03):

# This project has been superseded by [opentx](http://opentx.googlecode.com/) #

The following data is likely obsolete, kept here for mostly just for historical record.

# Fr-Sky Two-Way Telemetry Module Support #

The gruvin9x project was born mostly out of a desire to add support for [Fr-Sky](http://www.frsky-rc.com) telemetry data, including the ability to program the built-in [Fr-Sky](http://www.frsky-rc.com) alarm settings and utilise 'User Data' sent through the system for some purpose.

As of `trunk/` [r377](https://code.google.com/p/gruvin9x/source/detail?r=377), the above goals have been completed (excluding User Data).

Bearing in mind that one would not typically be looking at the '9X LCD screen while actually flying a plane, for example, following is how it looks, so far ...

## Screen Shots ##

### The Main FRSKY Page ###
After pressing `[DOWN (LONG)]`, one is presented with the **FRSKY 1/3** menu page.

> 

Here, we see the page with the Fr-Sky receiver powered off and thus no telemetry data being received. In this state, a large "NO DATA" message is displayed and the last known values, for A1, A2, RSSI, RX Batt and the graphical voltage bar, blink on and off to further accentuate the fact that data in this state is out of date.

And here is the same page with the Fr-Sky receiver powered on ...

> 

### FRSKY SETTINGS ###
Pressing `[RIGHT]` takes us to the **FRSKY SETTINGS 2/3 menu page.**

> 

Here we can set ...
  * which analog port (A1 or A2) is used for battery voltage (if any)
  * the maximum electrical voltage for the voltage adapter in use
  * a voltage calibration offset in 0.1V increments
  * the minimum and maximum voltages for the graphical voltage bar on page 1/3
  * whether or not we want an audible alarm when no telemetry data is being received

(I suppose that support for a second voltage display on the other available channel should be added. I'll wait to see how much interest there is, since the entire layout of this screen is bound to change anyway.)

### FRSKY ALARMS ###
Pressing `[RIGHT]` again takes us to the **FRSKY ALARMS 3/3 menu page.**

> 

Here we immediately see existing alarms values, as retrieved from the Fr-Sky transmitter module. (If for some reason you want to manually reload that data, you can press `[MENU (LONG)]`, while at the page/pages position, top right.)

Each of the four alarms as supported by the Fr-Sky transmitter module can be configured with a "Level" (of urgency), a mode -- greater than or less than -- and the value to which that mode applies. Each of the corresponding fields on this screen is editable. Select a field using `[UP]`, `[DOWN]`, `[LEFT]` and `[RIGHT]`. Press `[MENU]` to enter edit mode and make your selection using `[LEFT]` and `[RIGHT]`.

Pressing `[MENU]` again exits edit mode and it is at this point that the new alarm settings for that row are written out to the Fr-Sky transmitter module.

In case you're wondering, the 'GT' and 'LT' letters are '>' and '<' symbol memory aids, for those who may need same. **GT** stands for '<b>G</b>reater <b>T</b>han' and **LT** is for '<b>L</b>ess <b>T</b>han'.

Incidentally, the ordering of the alarm settings -- with A2 above A1 -- is intentional. For some reason, the Chinese designers ordered things in this way numerically, and it simply saves code and RAM space to not bother buffering and re-organising that fact for display. Even on the receiver casing, we see the input channels labelled 'backwards' (to the Western mind?) -- 'A2 A1', left to right. `*shrug*`

# TO DO #

  * Addition of graphical bar for signal strength

  * Allowance for two voltage bars, example: receiver batt. and main batt.

As at [r377](https://code.google.com/p/gruvin9x/source/detail?r=377), these TODOs have been postponed, pending user interest.

## Miscellaneous ##

The Fr-Sky Settings (page 2/3)are stored in local EEPROM. When I started developing this, there were two file types in use by the dynamic file storage system created by TH. These are, 'Type 1' -- for General Settings and 'Type 2' -- for Model data. I've now added a 'Type 3' -- for Fr-Sky settings.

> (As at [r377](https://code.google.com/p/gruvin9x/source/detail?r=377), EEPROM Fr-Sky Settings file format "3" has now been finalised. Changes to the format will include incrementing the the file's `myvers` field. So it should be safe to to write code for or record backups of EEPROM files including Fr-Sky settings as of [r377](https://code.google.com/p/gruvin9x/source/detail?r=377),as future code will try to be backward compatible and perform auto-format-upgrades where needed.)

Since my last update, I've also discovered TH's Ruby script, 'eeprom.rb'. The script analyses a binary dump file of the '9X EEPROM data and shows us the contents. (It's also for debugging data issues and converting data versions, I think.)

Here's what the output of eeprom.rb produces (having been upgraded to gruvin9x awareness) ...

```
   version     4 0x4 (Uint8_t)
    mySize    64 0x40 (Uint8_t)
  freeList    35 0x23 (Uint8_t)
        bs    16 0x10 (Uint8_t)

freeBlks=90 freeSz=1440
allocation map
////////////////r00 r01 r02 r03 c12 c13 b03 a00 a01 a02 a03 a04 
b04 r04 b05 b02 c03 b06 c04 c05 c06 c07 c08 c09 c10 c00 c01 c02 
b00 b01 s00  +1  +1  +1  +1  +1  +1  +1  +2 c11  +2 c14  +3 c15 
 +2  -1  +1  +1  +1  +1  +1  +1  +1  +1  +1  +1  +1  +1  +1  +1 
 +1  +1  +1  +1  +1  +1  +1  +1  +1  +1  +1  +1  +1  +1  +1  +1 
 +1  +1  +1  +1  +1  +1  +1  +1  +1  +1  +1  +1  +1  +1  +1  +1 
 +1  +1  +1  +1  +1  +1  +1  +1  +1  +1  +1  +1  +1  +1  +1  +1 
 +1  +1  +1  +1  +1  +1  +1  +1  +1  +1  +1  +1  +1  +1  +1 -127 

name sz typ sz2 Comments                   blocks
-------------------------------------------------
a    61  1   76 EEGeneral_r250             11, 12, 13, 14, 15,
b    99  2  619 ModelData_r250'GROOVY    ' 32, 33, 19, 10, 16, 18, 21,
c   238  2  619 ModelData_r250'TREX500   ' 29, 30, 31, 20, 22, 23, 24, 25, 26, 27,
d     0  2    0 
e     0  0    0 
f     0  0    0 
g     0  0    0 
h     0  0    0 
i     0  0    0 
j     0  0    0 
k     0  0    0 
l     0  0    0 
m     0  0    0 
n     0  0    0 
o     0  0    0 
p     0  0    0 
q     0  0    0 
r    61  1   76 EEGeneral_r250             4, 5, 6, 7, 17,
s     8  3    7 Freesky_r250               34,[Ver:1 Ch:A1 Vmax:6.6 Vofs:-0.10 BMin:4.0 BMax:6.6]
t     0  0    0 
```

**Even more impressive** is Erazz's `eePe` software, which I have not yet had time to teach about the new 'file type 3' for Fr-Sky settings. See [here](eePe.md) for more details.

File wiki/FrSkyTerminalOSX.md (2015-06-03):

# Fr-Sky Terminal for OS X #

I (Gruvin) wanted a Mac OS X native application for viewing Fr-Sky telemetry data and setting the transmitter module's four on-board alarms. Thus was born, "Fr-Sky Terminal for OS X"

This application now has its own open source project site at http://code.google.com/p/frsky-terminal/. Full usage and downloading information can be be found there on the [About](http://code.google.com/p/frsky-terminal/wiki/About) wiki page.

# Screen-Shot #



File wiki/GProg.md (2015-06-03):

# G9X USBasp Compatible Programmer #
**gProg v1.2 Release** (now available from http://gruvin9x.com)

**gProg** is another freely published part of our open hardware project. It is based on the popular [USBasp open source project](http://www.fischl.de/usbasp/). This AVR programmer board is designed to be used with [companion9x](http://companion9x.googlecode.com) or any other AVRDUDE compatible system. With it, you can upload and download EEPROM stored model data as well as perform firmware upgrades. The device is especially designed to fit the [G9X v4.x custom controller board](PCB.md), but could also be used as a generic AVR flash programmer.

This board has a couple features compared to most USBasp programmers at the time of writing.

  1. A bug in the USBasp firmware preventing proper addressing of Flash memory on ATmega devices with more than 64Kbytes ROM has been fixed.

> 2. gProg has a switched buffer interface, enabling it to remain connected permanently to its host MCU without drawing power or otherwise interfering with the MISO/MOSI/CLK lines.

You can build your own gProg or buy one from our online [gruvin9x online store](http://gruvin9x.com/). Blank PCB's can be supplied upon request -- or use the excellent [ITead Studio PCB prototype service](http://imall.iteadstudio.com/open-pcb/pcb-prototyping.html).

> _Special thanks to Jim (JWB) of Spring Valley, CA, USA for his proactive and generous assistance in this project._

**Image of the version 1.1 prototype**


**The prototype gProg installed atop a hand-built v4.1 main board**


The white, tubular stand-off shown in the above image (beneath the gProg the mounting screw) is 10.5 - 11mm in length -- PVC 2.5mm I.D. tubing, available from most model shops. The screw itself is a (USA) 2-56 (2.2mm) x 3/4 inch. A 2mm x 20mm hex-head machine screw is also suitable (even though it's longer) and actually screws in a little easier.

**The USB socket can be mounted in the battery compartment.**


> This idea was shamelessly copied from SmartieParts.com "pogo board", which is an excellent solution for stock standard '9X controller boards. (Full product name, _**9x Solderless Programmer Board with LED Backlight Support**_. Check it out [here](http://www.smartieparts.com/shop/index.php?main_page=product_info&cPath=3&products_id=331).)

**WARNING** To get a snug _**but not too tight**_ fit in the slot, you may need to file down one or both sides of the USB socket carrier board, a little. DO NOT apply any pressure directly to the USB socket itself. Use a broad, blunt tool, like large, flat edge screwdriver and apply only low to moderate force. If the board does not slide in easily, then STOP and file the board, else something _will_ break.

If you end up with too loose a fit, then try the other slot (one is a little more narrow than the other) or use hot-glue or a drop of blue thread locking cement (loctite™ 243) to secure the board, yet enable later removal if needed.

Of course, you cn also mount the USB socket almost anywhere else you like, using hot-glue or some other supporting arrangement, along with a suitable access hole, for example.

## Wiring gProg to a stock standard '9X ... ##





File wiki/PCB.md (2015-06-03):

<h1>Custom Main Board Development</h1>

<i>Photo to the right is the v4.0 prototype (R.I.P). An image of the V4.1 board can be found below, in the 'Progress' section.</i>
```

```
<h2>Update 2012-09-23</h2>
The second batch of <a href='http://gruvin9x.com/shop/gruvin9x/22-gruvin9x-v41-pcb-fully-assembled.html'>G9X v4.2 fully assembled and tested boards</a> have been on sale at gruvin9x.com for a few weeks now. Sales are progressing steadily, indicating continually expanding interest.<br>
<br>
Meanwhile, we are having the Chinese factory also do small runs of the RTC/SD-card and gProg boards, which should result in further resale price reductions. <i>Yay!</i> \o/ More to come on this, as information comes to hand.<br>
<br>
<h2>Past Update 2012-05-14</h2>
The first test run of v4.1 fully assembled boards is sold out. We are in the quoting phase with the factory over the latest v4.2 design. (Very little difference from v4.1.) We hope to have some stock of the v4.2 boards by the end of July. Timing is very difficult to predict, due to several factors.<br>
<br>
Blank v4.1 boards are still available for purchase at <a href='http://gruvin9x.com/shop'>http://gruvin9x.com/shop</a>. There's also still the "pre-soldered tricky parts" version, with the MCU and LCD ZIF socket pre-soldered, while stocks last.<br>
<br>
<b>gruvin9x firmware is now <a href='http://en.wikipedia.org/wiki/Deprecation'>deprecated</a></b>, having been replaced by the far more advanced <a href='http://open9x.googlecode.com'>open9x</a>.<br>
<br>
<i>Gruvin</i>

<hr />

<h2>Why a custom PCB?</h2>

The primary intention with this new main board is to provide a more powerful and flexible platform for the TH/ER/gruvin9x/(RadioClone?) open source firmware to run on – basically, because we want to and we can. :p (See project home page if you don't know what that even is :-)<br>
<br>
The design is "open", so you can follow its progress in all details, as well as make requests and suggestions for additions or improvements – and, of course, you can get involved more directly and do those for yourself. (There are currently two contributors working on the PCB board design.)<br>
<br>
Initial intentions were to ...<br>
<br>
<ul><li>provide a programming header capable of supporting an onboard USB programming board. (For now, this header simply enables connection of an AVR ISP programmer.) <b>done</b>
</li><li>add RS-232 and TTL level telemetry serial data send/receive ports <b>done</b>
</li><li>free up most of PORTB for use with an MM/SD card interface for mass storage <b>done</b>
</li><li>upgrade the processor for more program, RAM and EEPROM storage memory <b>done</b> (v3.2)<br>
</li><li>upgrade processor yet again to 100-pin version, for even greater "plug'n'play" flexibility. <b>done</b> (v4.0)</li></ul>

Thanks to the enthusiastic support of several people over the months, there have been many ideas to come along since those first intentions were realized. These include ...<br>
<br>
<ul><li>USB port for potential 'game controller' interface -- for use with PC flight simulators, giving access to all switches and rotary inputs controls. <i><code>[</code> Sadly, a USB boot loader cannot happen due to space needed for SD card version of the same.<code>]</code></i>
</li><li>SD card boot loader. This would allow re-Flashing by simply copying the firmware file to the SD card. No more programmers or cables to connect and get working.<br>
</li><li>Two continuous rotation control dials with push switch action (rotary encoders) for improved menu navigation, value settings and in flight adjustment (yet to be coded.)<br>
</li><li>At least eleven (11) spare I/O ports including three ADC inputs for uses mostly not even planned yet.<br>
</li><li>Onboard support for both the Smartieparts.com EL backlight board and also now a dedicated LED backlight regulator.<br>
</li><li>Support for both the stock buzzer and a variable tone speaker at the same time, as well as a separate vibrator motor port with it's own regulated supply.<br>
</li><li>JTAG programming/debug port in addition to the separate SPI programming port. (Should prove invaluable for the code developers.)<br>
</li><li>RS232 and TTL level telemetry data interface, supporting shared simultaneous three-way connection with a host computer for debugging and analysis<br>
</li><li>Onboard precision voltage refserence to improve safety main battery voltage monitoring over the Atmega's slow-to-stabalise internal band gap reference.<br>
</li><li>A theoretically much more robust and multi-vendor compatible trainer port circuit, hopefully meaning that your upgraded '9X will work seamlessly with just about any other make of radio currently on the market.</li></ul>

... and more besides.<br>
<br>
<b>Why not an ARM chip?</b>

We looked at basing the new board around a STM32 ARM based chip. But we decided against this, for a number of reasons. The ATmega2560 chip will do everything we need with the confidence that our highly timing-sensitive code is already tested and reliable on the ATmega platform.<br>
<br>
When we want more CPU power, say for on-board wireless video feed processing and other advanced features we have in mind, then we're more likely to add a second processor, so as to maintain the required high reliability of the core function -- that is, solid and safe remote control of our models.<br>
<br>
<h2>License</h2>

The custom board design is licensed under the <a href='http://www.tapr.org/TAPR_Open_Hardware_License_v1.0.txt'>TAPR Open Hardware License v1.0</a>. The license is very similar to the GPL of this project's related firmware source code, but includes additional protection against what your author terms, 'hostile patent acts'. In other words, like the GPL license for software source code, the TAPR Open Hardware License seeks to ensure that the openness of the design will endure. The license is NOT a non-commercial license. This design <i>is</i> able to be used by licensees for commercial purposes, under the terms of the <a href='http://www.tapr.org/TAPR_Open_Hardware_License_v1.0.txt'>OHL License</a>.<br>
<br>
<h2>Where it Started</h2>

As a starting point -- and in fact initially only as a test case to help learn to use the CAD software -- a PCB design was worked up from scratch in <a href='http://kicad.sourceforge.net/'>KiCAD</a> (itself also open source) to closely replicate the wiring and functions of Turnigy V2 '9X logic board. See <a href='http://code.google.com/p/gruvin9x/source/browse/#svn/trunk/pcb/original'>/trunk/pcb/original/</a> (as of <a href='https://code.google.com/p/gruvin9x/source/detail?r=155'>r155</a>). From there, things just kept growing, with numerous changes and additions being made, until eventually an actual new board ended up being produced.<br>
<br>
The first custom prototype PCB actually built was (somewhat oddly) named, "version 2.14". This was Gruvin's first ever PCB using tiny surface mount components and a lot was learned through the exercise. That said, the board fired up and worked from the moment power was first connected, which was quite astonishing at the time, to say the least! A few minor bugs were found, additions and changes made and another design quickly got underway.<br>
<br>
Version 3.2 used the same ATmega2561 chip, which was an upgrade over the original but with still only 64 pins. At the time, Gruvin was basically too scared to attempt a design for the 100 pin ATmega2560 version of the chip. As fate would have it however, a British gent by the name of Cameron happened across the project and asked if he might have a crack at the 100 pin design. "Well sure you can!" The rest is now history and as of 2011-09-13, we're about to start beta testing custom PCB version 4, which will finally (most hopefully) be offered up for retail, as a fully assembled unit. (As of said date, the first v4 test board is already up and running with no bugs yet found.)<br>
<br>
- - - -<br>
<br>
<blockquote>I was asked to make a video of the actual v3.2 board that I had hand constructed.<br>
Here it is ...</blockquote>

<blockquote> -- gruvin (on a bad hair day.)</blockquote>

<blockquote>Note: Video is X-Y mirrored, for some strange reason.</blockquote>

<blockquote>- - - -</blockquote>

<blockquote>And here I am again, flipped 'round the right way this time, showing the v4.1 board ...</blockquote>

<blockquote></blockquote>

<h2>Progress</h2>
<h3>The V4.1 Board -- Now Available</h3>

The v4.1 (final v4 production version) board is now available for purchase at <a href='http://gruvin9x.com/shop'>http://gruvin9x.com/shop</a>. We encourage all early adopters and home electronics constructors to grab yourselves a board or two and get building. :-D We'll be here to assist with any problems.<br>
<br>


A high resolution version of the above photo is available <a href='PCB.attach/pcbv41_photo_fs.jpg'>here</a>.<br>
<br>
Interestingly, this board was mainly constructed through concurrent, ambidextrous use of two hand soldering irons (one in each hand), to transfer components from the v4.0 prototype to the new v4.1 PCB. The process took about four hours in total. One resistor was apparently heat-damaged and needed replacing. Everything else seems to be working 100%. Yay \o/<br>
<br>
The back of the board has the HobbyKing LED back-light kit supplied self-adhesive foam pad stuck to it. I would recommend that specific LED back-light kit to all V4.1 board adopters. There's a dedicated driver output for it at the upper right of the board. <i>Be SURE to use the center GND and <b>RIGHT</b>-hand pin to get the current limited LED-safe connection</i> -- because the left terminal is a full current, 5V supply!<br>
<br>


<h3>The v4.0 Prototype Board</h3>

Here's a recent V4.0 3D visualization from KiCAD...<br>
<br>


<h2>Current Status</h2>

2011-12-08: First v4.1 board fully built and tested all OK. Boards in stock and available for purchase at <a href='http://gruvin9x.com/shop'>http://gruvin9x.com/shop</a>

2011-11-16: v4.1 blank production boards have arrived. Also, v4.1 factory assembled 'beta' boards are underway and expected before Christmas.<br>
<br>
2011-10-11: We are satisfied that the v4.1 board is ready for its first test factory production run of ten Beta test boards. All of the testing is finished and the bugs found have been corrected. Meanwhile, we continue to develop and test on the three existing and working v4.0 boards, which have all been patched using track-cuts and wire links to the new v4.1 bug-fixed design version. It is likely that Cam will finalise the decision to freeze and deliver the v4.1 design to Leo for factory processing within the next 24 hours.<br>
<br>
2011-09-22: A number of circuitry bugs have been found and corrected, as testing continues on schedule. Four v4.0 boards are known to exist at this time. We expect to be ordering the first small factory test batch by mid October, but will not rush the date if all testing has not been completed satisfactorily.<br>
<br>
2011-09-13: The first v4.0 beta test board was assembled and powered up by Gruvin in New Zealand, who was excited to see it perform all its primary functions without fault, right from the get go! :-D The additional v4 features are yet to be tested. There are two or three others at different locations around the globe also building the same v4 board as this is being typed. Assuming all goes well, thanks to a generous donation offered by Swiss supporter, Leo, ten v4.1 boards are planed to be factory assembled in China, with about half of those being offered at near cost to the first group of beta testers outside of the core project team. If all that goes well, then we plan to try and raise funds for assembly batches of 50 to 100 boards at a time, with a target retail price of around USD$149. No promises can be made at this stage.<br>
<br>
<b>Past Milestones in descending date order ...</b>

2011-08-21: The fist ten (blank) V4 prototype boards have arrived in cam's hands. At least two other project followers have asked for blank boards to build up from scratch themselves. Great stuff -- more beta testers! :D<br>
<br>
In the meantime, we have received several expressions of interest from people wanting to purchase a new controller board for themselves. <b>But we are not currently accepting pre-orders</b>. We need to wait until, a) the V4 board is tested to be without errors, b) the Chinese manufacturer lined up to assemble the small quantities of boards involved has proven practical and c) a fair and proper mechanism for placing orders is available. We're working on it. Please be patient. We do hope to have assembled and tested boards available before the end of 2011.<br>
<br>
2011-07-07: First test run V3 PC boards confirmed in production.<br>
<br>
2011-07-04: New SD card board (smaller/better size) sent away for production. Also, Cam has made an alternative design for UK builders who, like him, cannot find local stock for the SD card socket used in the previous design.<br>
<br>
2011-06-25: SD card PCB assembled, installed and test OK. Physical size of board found to be 8mm too long for its decided installation position and the SD card socket should protrude beyond the board edge by 2.5mm also. Changes made to the design accordingly, awaiting ordering process. (Real Time Clock (RTC) on the same board also tested and working.)<br>
<br>
2011-06-01: SD card prototype PCBs arrive. Construction begins, noting that the custom component pads are all perfectly correct. Yay \o/.<br>
<br>
2011-01-14: First prototype board fully constructed, code updated and functioning. There were some issues with the wiring layout of the trim switches that will need to be fixed on the V3 board. But otherwise, everything seems to be working.  All in all, it doesn't make much sense to produce another V2 prototype board, since the V3 board will include several fixes and enhancements.<br>
<br>
Next step is probably going to be to take advantage of the extra Flash space (now 256KBytes) and start playing with MM/SDCARD mass storage.<br>
<br>
2010-12-30: Components and PCBs have arrived (ahead of schedule). Have ordered components to make up the 'plug' end of the 2-way, 3-way and 8-way JST sockets, which I had thought were included with same. I'm elated to report that the PCB mounting holes and push-button-switch physical locations are within spec and fit well into the actual radio '9X cabinet. (That had been one of my greater concerns during the design process.)<br>
<br>
2010-12-22: <a href='http://gruvin9x.googlecode.com/svn/trunk/pcb/rev2.14-frozen/production/gruvin9x-bom.xls'>Components</a> to build three prototypes ordered from Digikey.com<br>
<br>
2010-12-15: A first batch of 10 (MOQ) prototype PCB's (<a href='http://gruvin9x.googlecode.com/svn/trunk/pcb/rev2.14-frozen'>rev2.14</a>) ordered.<br>
<br>
<h2>Schematics and PCB Design Files</h2>

See the <a href='Circuitry.md'>Custom Schematics</a> page for details.<br>
<br>
<br>
<h1>Historical Data</h1>
<h2>Preview</h2>

2010-12-02: A final draft of the PCB based on <a href='http://gruvin9x.googlecode.com/svn/trunk/pcb/rev2.1/gruvin9x_rev21.pdf'>schematic rev2.1</a> has been completed. (All files updated in <code>/trunk/pcb</code> as at <a href='https://code.google.com/p/gruvin9x/source/detail?r=159'>r159</a>). I'm waiting on some peer review and comments before committing this to a manufacturer. Time frame unknown.<br>
<br>
The board includes the total re-wire of all trim and button switches into a 4x4 scanned matrix to free up most of Port B. This gives us dedicated I/O ports for the MMC/SDCARD and a couple spares as well -- with theoretically only very minor CPU load for scanning the inputs.<br>
<br>
The connector for the MMC/SDCARD interface can be seen at lower/middle of the image below. The two connectors to the lower right are the TTL and RS-232 level telemetry TX/RX ports. A 2-pin connector on the upper edge is for the left-hand and right-hand trim switch 'common' connections. These replace their respective connections to ground, in order to work with the new 4x4 input matrix.<br>
<br>
This new main board will receive an <b>ATmega2561</b> (256K Flash, 4K EEPROM, 8K SRAM). I have thus far decided to keep ATmega running at 5V, though it's certainly tempting to move down to 3.3V, since the LCD screen and SDCARD currently need a total of 31 resistors just to down-convert the voltage! However, I'm concerned about possible noise increase on the ADC inputs, should the operating voltage be lowered, and a couple of other minor issues too. So at 5 Volts we stay.<br>
<br>
<b>The 3D image from KiCAD</b> as at <a href='https://code.google.com/p/gruvin9x/source/detail?r=155'>r155</a> ...<br>
<br>


NOTE: Since moved on to rev2.11 with a few minor changes/additions, like RF decoupling caps on the KEYXn inputs and some tidying up here and there. Work continues! :-D<br>
<br>
<br>
<h3>Previously</h3>

NOTE: These images (below) as at <a href='https://code.google.com/p/gruvin9x/source/detail?r=122'>r122</a> ...<br>
<br>


The above image is merely a PhotoShop mock-up based on the various layer outputs from KiCAD.<br>
<br>
<h3>Cost</h3>

The present best quote for low volume PCB manufacture is around the USD$15 mark -- for one of 10 boards with no components installed. Manufacturing of a prototype board will likely not happen until at least the telemetry and mass storage mods have been done. That will include break-outs for any remaining spare port pins and should get the hardware to a point where nothing additional is needed.<br>
<br>




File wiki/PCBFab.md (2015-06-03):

# Getting your own G9X v4.2d PCB's made #

A Hong Kong based organisation, "ITead Studio" is the cheapest
and most accessible PCB prototyping service we have yet found. They can supply
five (5) HASL (hot air solder levelled) professionally produced and fully silk screened etc
G9X v4.2d PCBs for about USD$61, plus shipping. Shipping costs are typically under USD$10 for
registered air mail.

That's less than USD$15 for each board, landed at your door! Here's how you do it ...

## How to Order five G9X v4.2d Boards from ITead Studio ##

Go to http://imall.iteadstudio.com/open-pcb/pcb-prototyping/im120418010.html

That should be a direct link to their PCB prototyping service, for _2LAYER PCB
LARGER THAN 10CM X 10CM._

You need to select some options. Here's an image of that, which I just did on
their site ...



Once you have paid for your order, ITead will send a confirmation email
containing instructions for sending the Gerber files to them. That amounts to
sending an email to pcb[=at=]iteadstudio[=dot=]com, with the Gerber
files attached. Put your order number in the subject and message body.

Here is a link to the Gerbers files, already in a convenient ZIP file.  <a href="../archive/pcb-v4.2d-frozen/production/g9x_v4-2d_gerbers.zip?raw=true">ZIPped Gerber files for ITead</a>

Just send the ZIP as a single file.

That's it!

Time from placing order to receiving the boards (way down here in New Zealand)
is usually inside two weeks. (They come from Hong Kong, China.)

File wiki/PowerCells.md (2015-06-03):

# Ni-Mh vs. Other Power Sources #

**In brief:** Dry-Cell < Alkaline < Ni-MH < Ni-Cd (!) < Li-Fe-PO4 < BEC

It is surprising to see how various types of power cells allow an RC model receiver's operating voltage to dip when moving three servos about. This dip can be _significant_ and even _dangerous_.

Using four alkaline cells, for example, with just a little load on a couple of servos, one can observe receiver voltage dip right down below 4.2 Volts!

This is due to the relatively high internal resistance of such cells.

**Word to the wise:** I certainly wouldn't recommend using alkaline cells to power a 2.4GHz, CPU-utilising receiver in a model air plane!

Shock of horrors! -- It turns out that Ni-Mh cells aren't actually that much better -- especially not the more expensive, longer shelf life versions it seems!

A 4.8V (4S) Ni-Mh pack can readily be made to dip way below 3.6V with only moderate load on three or four servos. This is bad news for RC receivers that will fail or reset when even the shortest, intermittent pulse below about 3.8V occurs. (Think Spektrum DSM2 receivers for just one example -- and just about all modern 2.4GHz, CPU employing receivers not far behind.)

What's the best solution to protect your receiver from possible brownouts under load? In my opinion, that would be either running 2 x Li-Fe-PO4 (A123) cells (make sure your servos can in fact operate above 5V. Not all can!), or doing what electric models do -- use a 7.4V (2S) or 11.1V (3S) Li-Po and a 5V or 6V (S/U)BEC.

In the latter case, assuming your total load is under the stated capabilities of the BEC in question, you will get a (nearly) rock-solid receiver and servo power supply -- right up to maximum stated load. You'll also enjoy better peace of mind and faster, more responsive servos as a bonus.

**So then, another word to the wise:** This is why more and more people are becoming convinced of the merits of moving up to a 5S Ni-Mh pack for their on-board power supply in nitro propelled planes -- or better, as mentioned above.

> _Perhaps surprisingly, as a direct replacement for Ni-Mh cells, modern Ni-Cd cells are actually among the best technology available for low internal resistance and current output current. They're more robust than Li-Ion solutions, though of course also heavier. My point here is that, **just because everyone's using them, doesn't mean that Ni-Mh are necessarily the best**._

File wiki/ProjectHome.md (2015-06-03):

<h2>G9X v4.x BOARD (DISCONTINUED)</h2>

Why? Because there's much better things on the horizon -- we think. Trusted sources confirm the ongoing development of a Fr-Sky X9D transmitter, which we understand will be supporting open9x firmware form launch. The board will be ARM 32-bit based and is rumoured to be targeting sub-USD$100 retail -- complete with Fr-Sky 16-channel transmitter module, built in. If this all turns out to be true, then the complete radio will cost less than the G9X board (in the small qty's we can manage) whilst having all the same features and more. So we wait.<br>
<br>
We simply don't know if demand for the G9X system will continue -- or not. Whilst orders seem to still be trickling in -- now even for blank boards (wow!) -- we don't expect that to last. Right or wrong, Gruvin made the choice, not to risk funds on another batch of G9X v4.2 boards. Was it the right choice? Have your say at <a href='http://9xforums.com/forum/viewforum.php?f=66'>9xforums.com</a>.<br>
<br>
<br>
<h2>We recommend open9x firmware</h2>

Please visit the open9x <a href='http://open9x.googlecode.com'>project site</a> for more information.<br>
<br>
Also highly recommended is the <a href='http://companion9x.googlecode.com'>companion9x</a> project -- the easiest way to obtain the latest release version of open9x firmware for your radio -- and much more. (Based on the original eePe from er9x.)<br>
<br>
<h2>Project Brief</h2>
<blockquote><i>First off, we especially wish to thank all the amazing original and ongoing work by</i>Thomas Husterer<i>of the <a href='http://code.google.com/p/th9x/'>th9x project</a>. A good number of other people have also contributed ideas, code and more to his, this and other related projects. THANK YOU all!</i></blockquote>

The gruvin9x project was originally forked from <code>er9x v1.1 r262</code> (<a href='http://code.google.com/p/er9x/source/browse/?r=262'>http://code.google.com/p/er9x/source/browse/?r=262</a>) which was based on a earlier version of the original th9x code. A huge amount effort was later put into the gruvin9x code base by contributor bsongis, of the <a href='http://open9x.googlecode.com'>open9x</a> and <a href='http://companion9x.googlecode.com'>companion9x</a> projects, which later became the sole point of focus for our custom hardware firmware support.<br>
<br>
<b>Highlights ...</b>
<ul><li><a href='About.md'>Project Wiki Documentation</a>
</li><li><a href='ReProgram.md'>Re-programming Your 9X Radio</a> -- firmware downloads, flashing, etc.<br>
</li><li><a href='PCB.md'>Custom Main Board Development</a> -- <b>upgrade your '9X controller board!</b></li></ul>

<h2>But what <i>is</i> it?</h2>
In short, this is an RC modeller/hacker's dream come true. We get to use your own custom firmware in our radios, adding features and making changes whenever we like and all (generally) at much lower cost than comparable commercial gear -- especially in terms of firmware features and programmability. We currently support any PPM transmitter module, with a focus on Fr-Sky two-way products, as well as DSM, DSM2 and DSMX 'retro-fitted' modules, usually salvaged from cheap 4-ch bind'n'fly models, as found on eBay.<br>
<br>
Open9x firmware is written and maintained by active RC modellers. It is mature, stable and very powerful. Based on th9x's 'multiplexer' implementation, it is arguably a little difficult to learn compared to other systems -- but is much more flexible. Open9x firmware is a significantly more powerful replacement for the comparatively simple default factory firmware that comes with the '9X radios.<br>
<br>
The <a href='PCB.md'>gruvin9x custom controller board</a> was developed using a larger version of the original Atmel AVR chip, to give us more RAM, firmware code space and more I/O connections for additional peripherals, such as telemetry data port, RTC/SD-card interface and more.<br>
<br>
If your existing transmitter doesn't do something you wish it would, chances are that open9x already does. If it doesn't, then put in a feature request and, if it makes sense to others, then the firmware will likely soon perform your new function.<br>
<br>
Both the open9x firmware and the companion9x (desktop) projects support our poplar <a href='PCB.md'>G9X v4 Custom Controller board</a>.<br>
<br>
<blockquote><i><b>Caveat</b>: Firmware is  half the story -- quality of hardware is not a given and should also be carefully considered. Whilst the build quality of most 9X radios seems just fine, there have been notable exceptions. We therefore strongly recommend that all firmware functions as well as internal radio soldering joints and physical gimbal assembly be carefully checked, before committing a 'cheap' 9X radio controlled aircraft to the skies. SAFETY FIRST!</i></blockquote>

The original <a href='http://code.google.com/p/th9x/'>TH9X project</a> was (and very much still is) about completely replacing the factory supplied operating system in the Turnigy/Eurgle/iMax/Fly-Sky/etc 9X Remote Control transmitter from China -- currently retailing for around USD$40 -- HOW, we do not know!<br>
<br>
From there, other projects then spawned (were forked forked) from TH9X, including ER9X and gruvin9x. More are likely to follow as different interest focuses emerge. In our case, the focus was originally on providing practical Fr-Sky telemetry support and more recently, the design and production of an <a href='PCB.md'>custom controller board</a>, to be a drop-in, upgrade replacement for the stock '9X system controller.<br>
<br>
There's more about gruvin9x on the <a href='About.md'>About</a> wiki page.<br>
<br>
<h3>Documentation</h3>

For G9X hardware or historical information, please consult the <a href='About.md'>project wiki</a> in the first instance, as well as the <a href='http://code.google.com/p/gruvin9x/source/browse/#svn%2Ftrunk%2Fdoc'>doc/ directory</a> in the source tree for all currently available gruvin9x documentation.<br>
<br>
There is also now a growing user maintained wiki documentation project over at <a href='http://9xforums.com'>9xforums.com</a>. The wiki could use <i>your</i> input.  Please consider helping out by providing your own documentation, as you gain familiarity with the related projects.<br>
<br>
<h3>Other '9X OS Replacements</h3>

There's also at least one other project taking on the same basic goal, but of completely different design and unrelated to the TH/ER/gruvin9X projects. It's named Radio Clone, can be found at <a href='http://radioclone.sourceforge.net/'>http://radioclone.sourceforge.net/</a> and is well worth checking out.<br>
<br>
<br>
<h2>Downloading gruvin9x Firmware and Flashing Your Radio</h2>

For details on installing new firmware into you Turnigy/iMax/Eurgle/etc 9X RC Radio, see the <a href='FlashGuide.md'>Flash Guide</a> wiki page.<br>
<br>
<br>
<h2>Getting the gruvin9x Source Code</h2>

See the <a href='CompilingFromSource.md'>Compiling from Source</a> wiki page.<br>
<br>
<br>
<h2>Get Involved!</h2>

An independent group maintain an, 'all things 9X' forum over at <a href='http://9xforums.com/'>9xforums.com</a>. The forum caters to several different firmware projects, has a documentation wiki attached and is probably the most popular hang-out for '9X enthusiasts nowadays.<br>
<br>
There is also the original <a href='http://groups.google.com/group/gruvin9x-discuss'>gruvin9x discussion group</a>. All you need to participate there is a valid Google account.<br>
<br>
To <b>submit bug reports</b> or <b>feature requests</b>, please use the <a href='http://code.google.com/p/gruvin9x/issues'>issues</a> menu link. The issues area lets you log bug reports and make feature requests in an organised and trackable manner. Don't be shy! Give it a go.<br>
<br>
<h2>External Links</h2>

<ul><li><a href='http://code.google.com/p/er9x/'>Original ER9X Project Home</a>
</li><li><a href='http://code.google.com/p/th9x/'>ORIGINAL, Original TH9X Project Home</a> "Respect!" :-D</li></ul>

<ul><li><a href='http://sourceforge.net/apps/mediawiki/radioclone/'>Radio Clone Project</a> -- Something different and well worth checking out.</li></ul>

<ul><li><a href='http://www.rcmodelreviews.com/tendollarbattery.shtml'>$10 Li-Ion Battery Pack Upgrade</a></li></ul>

.<br>
.<br>
.<br>
<br>
<h3>DISCLAIMER</h3>
Whilst the gruvin9x project owner(s) aim to provide as much help to as many Turnigy/iMax/Eurgle/etc '9X users as practical, any perceived enthusiasm on their part to lure people into using gruvin9x over any other version, would be erroneous. This project was originally created primarily for the author's own use -- and of course to 'give back' to the Open Source Community, as the <a href='http://www.gnu.org/licenses/gpl-2.0.html'>GNU General Public License (V2)</a> requests. Anyone is welcome to use this code according to said license, as is, where is and indeed to submit suggestions for changes, improvements, additions, etc. The author welcomes comments, constructive criticism, assistance and general feedback but accepts no responsibility for anything what-so-ever that use of any information contained on this website may or may not be claimed to cause. Use at your own risk. Any opinions offered by this internet resource are expressly, only opinions. (Any information claiming to be fact but not legally verified as fact in actuality, must of course be considered mere opinion, regardless of context.) All care is taken, but no responsibility is accepted for the level of accuracy of any information here or anywhere the author may post text, images, video, audio or other content. Any and all images, photographs, charts, lists or graphical representations of any kind are intended for educational or indicative purposes only and may or may not accurately represent any given subject, topic or fact at any given time. Indeed, any such depictions are subject to change at any time for any reason without notice. Any monetary figures, presented by whatever means, are for indicative, informational or educational purposes only and all such figures are subject to change at any time without notice. The use of sarcasm may or may not feature throughout this internet resource and other, related or linked media, and as such is intended purely as light-hearted humour. No responsibility is accepted for anything what-so-ever relating to perceived truths related to such believed communications. Reader/viewer/listener beware! Any views expressed by individuals other than project owner(s) may or may not agree with the projects goals, intentions or license and no responsibility is taken for any such view or views under any circumstance. Any views so interpreted as being those of the gruvin9x project owner(s) should be taken as potentially inaccurate and with the acceptance that any views, expressed or implied, are at all times subject to change without notice. This disclaimer falls within the above conditions, being itself subject to change at any time without notice. In light of the afore mentioned disclaimers, readers should take heed of the possibility that they may be, a) potentially crazy for reading this far in the first place and, b) that this disclaimer itself, though quite serious, is in part also intended for entertainment purposes. Etc, etc, blah blah. You know the drill. Love and peace to all! Now let's get on with it. :-D

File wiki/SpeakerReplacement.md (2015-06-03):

# This project has been superseded by [opentx](http://opentx.googlecode.com/) #

The following data is likely obsolete, kept here for mostly just for historical record.

# Replacing the Stock Beeper with a Speaker #

## Why? ##

One could easily wonder why beeps and buzzes are so important that I had to write a bunch of code and change my hardware for it. Well, let me explain my motives ...

 Aside from replicating features found on other brand radios, such as low/mid/high point trim tones and the like, the one thing I have always most wanted from telemetry is an AoA (<a href='http://en.wikipedia.org/wiki/Angle_of_attack'>Angle of Attack</a>) instrument. What's an AoA instrument? ... Well in short, it's used to assist in landing and as I understand it, is usually calibrated as a Lift Reserve Indicator or LRI.<br>
<br>
AoA or LRI is an analogue feedback device, intended to be superior to the basic stall warning. Many argue that's it's completely redundant and that we've got along fine for years without it. However, I'm not one of them and this project is not about full-size air craft anyway.<br>
<br>
Now, I am perfectly capable of putting most any plane down like a feather just visually from my years of experience to date. And I no longer care much for stall warning switches or airspeed indication, as I've come to doubt such would really help much in practice, if at all. Never the less, at this stage, I still believe that appropriately configured audio LRI feedback could at least be fun, if not reassuring. It should not even need much calibration, since our ears/brain will remember what sounds 'about right', near the point of minimum lift reserve, after a just a few landings.<br>
<br>
<h2>How?</h2>

Some kind of AoA sensor will be added to an available model plane, in at least the 40-size category. Fr-Sky telemetry will be used to send data back to my custom '9X radio.<br>
<br>
What I plan is to use varying pitch tones, similar to the sensitive rise/sink tones from a modern sail plane variometer. Typically, sink comes across as a constant, relatively low tone, falling more in pitch as the sink is greater. Rise is usually an intermittent "bip bip bip" tone, rising in pitch and frequency as lift increases. The sounds are very intuitive and allow you to know exactly what's going on without staring at an instrument panel. Of course, my tones will aim to indicate relative angle-of-attack or lift reserve, not rise/sink.<br>
<br>
With that, and a suitably functional AoA sensor on my aircraft (and that's a whole other story!) ... I should be able to gauge an appropriate landing approach for the plane with more certainty. In general of course, my own eyes and brain can do this pretty well, most of the time.<br>
<br>
Now, if you fly on a relatively flat chunk of land somewhere, you might be wondering what this is really all about. Well, I/we don't have such luxuries around here. One of the fields (especially) that I frequent is located in an undulated area of varying ground types, including water. One experiences a multitude of essentially unpredictable lift, sink, rotor and general turbulence, often on final approach. We cope with it all perfectly well without fancy AoA gadgets of course. But that's besides the point. :-D<br>
<br>
Now, I don't know if, in practice, any LRI feedback system of my own design will be accurate or responsive enough, or even help much at all for that matter. But I do want to find out. Will it make my landings any better and will anyone else even care? Well, maybe not. But I'm going to have fun making it all happen. That much is certain.<br>
<br>
<br>
<h2>Speaker Installation</h2>

Below is an image showing the first ugly speaker install I did. Hey! It works mmmkay? :-P Later I'll probably add some resistor and another capacitor or two to smooth out the square wave for a nicer tone.<br>
<br>


<h2>Results to Date</h2>

As of gruvin9x <a href='https://code.google.com/p/gruvin9x/source/detail?r=46'>r46</a>, all trim switches and general +/- keypad operations have lower/mid/higher tone for down/reached-zero/up value inputs respectively. The tones are much more pleasant to the ear (IMHO) than the stock internal beeper. (I have since also noted that different batches of these '9X radios can have significantly different sounding beepers. Some of them aren't actually that bad. Mine was truly horrid. :-/)

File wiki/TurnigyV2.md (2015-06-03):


<h1>The Turnigy 9X</h1>
<i>Also marketed under brand names: Eurgle, iMax, FlySky and others</i>

The author purchased his '9X radio set from <a href='http://hobbyking.com'>HobbyKing.com</a>, where they sell it under the brand name 'Turnigy'.<br>
<br>
<h2>Reference Images</h2>
Some <a href='ReferenceImages.md'>reference images</a> of the internals of the '9X hardware (including some detail about the LCD display) are posted <a href='ReferenceImages.md'>here</a> for convenient reference. (It saves opening up the case every time we need to check some minor detail.)<br>
<br>

<hr />


<h2>Circuit Schematics</h2>

A TH/ER9X project contributor(?) provided PDF circuit schematics of the V1(?) stock transmitter and receiver. You can find this <a href='http://gruvin9x.googlecode.com/svn/trunk/doc/9X_Schematic.pdf'>here</a>.<br>
<br>
The V2 circuitry is almost identical, except it has a new 3.3V LCD display plus supporting components. <a href='Circuitry.md'>More information</a>, including a <a href='http://gruvin9x.googlecode.com/svn/trunk/pcb/actual_v2_9x/gruvin9x_v2_actual.pdf'>new V2 schematic</a> for the V2 hardware is <a href='Circuitry.md'>here</a>.<br>
<br>
<br>
<h1>Turnigy V2 Firmware Backup</h1>

Having originally managed to lose my factory Turnigy 9X V2 firmware, I eventually purchased another unit and this time took a full backup and copied it up to the wiki, lest I lose it again! (A year later now and I've never had a desire to even look at this again. Oh well.)<br>
<br>
<a href='TurnigyV2.attach/Turnigy9X_V2.zip'>Turnigy9X_2.zip</a> contains all the <code>.bin</code> files from said backup.<br>
<br>
Or you can browse the individual files at <a href='http://code.google.com/p/gruvin9x/source/browse/#svn/wiki/TurnigyV2.attach'>http://code.google.com/p/gruvin9x/source/browse/#svn/wiki/TurnigyV2.attach</a>.

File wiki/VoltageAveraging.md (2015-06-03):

# This project has been superseded by [opentx](http://opentx.googlecode.com/) #

The following data is likely obsolete, kept here for mostly just for historical record.

**NOTE:** Much of this is no longer relevant since incorporating new code to work with self-calibrating band gap reference, which was done to prevent falsely high battery voltage levels when actually below 6v -- when the external ADC reference voltage also starts to fall.

# Why #

Whilst my own Lithium-Ion powered '9X seems fairly stable when taking ADC samples of battery voltage, I've come across several that have considerably more 'jitter' -- especially when powered by relatively high internal resistance cells, like alkaline AA-8-packs for example.

This results in the battery voltage flickering up and down significantly -- in one example, between 8.8V and 9.4V, when a fluke multimeter sat on a steady 9.2V.

Apart from the displeasing visual effect this has for the user, it can also cause annoying intermittent and false low-bat alarms. Not so good.

# The Fix #

Implemented a simple running average -- `new_value = (last_value * 7 + new_sample) / 8`.

The use of 7 'virtual' last values vaguely simulates recording of 7 previous samples and slows down the response to rapidly changing samples -- but is not _too_ slow. This effectively eliminates 'the jitters', where unstable battery voltage samples are occurring, for whatever reason.

## Make Options ##

None. The option to turn this feature off using a `Make` directive was removed some time around [r200](https://code.google.com/p/gruvin9x/source/detail?r=200). Why? Because too many `Make` directives was getting messy and I felt this feature was of benefit to everyone.

# Overflow Bug for Some 8-pack Alkaline Installations #

Interesting fault with new unit. Sample is reading `0x06D0` (around 12.3V) but we're only seeing around 0.2V displayed! (Calibrate = 0)

Long story short, the higher voltage of the new 8-pack of AA alkaline cells I put in the stock'9X, plus just a tiny bit of calibration applied, were causing an overflow in the 16-bit math, causing a wrap-around to a very small voltage. I fixed this, in the end, by changing (improving?) the way I handle calibration.

> READ NO FURTHER, unless you want to waste away some time :-P ...

So, here's an edit of my notes as I worked through this problem ...

The original code comments mention voltage divider resistor values of 5.07K and 2.65K, which I presume must have measured, since the components are marked 502 (5.1K) and 272 (2.7K). My Fluke meter tells me 5.08K and 2.70K for my particular unit. I think we should go with the marked values, using calibration to account for any variances.

So here's me working it out in my slow, half dead brain in the hot, muggy weather of the time ...

> `(2.7+5.1)/2.7*5/1024*1000` -> 14.105V maximum possible reading (assuming perfect resistors and a perfect 5.00V reference.)
> -- therefore, `vbatVolts = 78 * sampleVolts / 27` (tested with sample - 4.27 to yield 12.33V. CORRECT)
> -- therefore, `vbat100mV = 780 * sampleVolts / 27`
> -- where `sampleVolts = sampleValue * 5 / 2048` (because are samples are x2 normalised)
> -- thus `vbat100mV = 780 * sampleValue * 5 / 2048  / 27`
> (Checked with 1744 sample val. to yield 123. CORRECT)

Simplifying that, we come down to...

> `vbat100mV = sampleValue * 3900 / 2048 / 27` (checked)

, therefore

> `vbat100mV = sampleValue * 190 / 2700` (accuracy approx. +/-50mV)

To make the final divide less resource hungry, we'll normalise to an even power of 2. Thus we get,

> `g_vbat100mV = ((uint32_t)ab + 4 * g_eeGeneral.vBatCalib) * 144 / 2048`

Phew! Now onto calibration.

The original code allows adding entire 0.1V steps at each click -- so plus or minus a whopping 12.7V. I don't really need (or like) that, so will likely change it. But first to figure out this overload issue ...

Ah ... the `(ad*35 + ad / 4 * vBatCalib)` in the original code is overflowing on higher voltages if even just one (positive) click of calibration is in effect.

> Example: An input voltage of 12.30V was seen to provide a sample of 1744 (decimal). Thus, `1744*35 + 1744 / 4 * 1 = 76,300` -- more than the 65,535 maximum. Oops.

I originally fixed this by simply type-casting to 32-bit math. But that chews up more RAM than I hoped would be necessary. So I'll keep playing around.

`[Hint: By total fluke, changing the calibration scheme (as below) fixed the problem on its own -- for voltages up to about 13.8V.]`

Moving on then ...

Turns out `vBatCalib` is a signed 8-bit (int8\_t), allowing for values in the range -127 to +127, which if added to the initial sample gives +/-0.89V (after the above math has been applied.) A reasonable calibration range might be +/-3.56V, or in this case +/-(127x4)

Thus, we arrive at `vbat100mV = (sampleValue + 4 x vBatCalib) * 144 / 2048`.

But this still requires 24-bit math for higher voltages, whereas we want to keep within 16-bit. OK then ...

> `g_vbat100mV = ((uint32_t)ab + 4 x g_eeGeneral.vBatCalib) x 36 / 512`

..., which should be good to about 13.8V without overflowing -- including +127 calibration offset to get to that figure. Input voltages above 13.8V _will_ surely still be a problem. But I think I can live with that, in all practicality!

Wow. So, in the end, all I really changed is how the calibration figure affects the final result -- which just happens to have fixed the original overflow issue.

For people who prefer the original system, and who have 7.4V batteries (I guess!), TH's original formula has been reserved and can be used instead by supplying a `-DTHBATVOLTS` command line directive to the compiler.

Some time after the above brain exercise, we added the bandgap reference thing into the mix and I pretty much lost it about there. It took me another day of massive frustration to work out how to make that work to 2 decimal places for calibration (with rounding, I think) and I honestly cannot remember how I did it or how to do it again for these notes. **sigh**

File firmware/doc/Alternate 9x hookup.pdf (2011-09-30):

Alternate Hookup for Flashing the 9x Transmitter

The guide that I wrote has the most straightforward connection between the programmer and the 9x that I could come up with. The color coding makes things easy to hook up, with little chance of getting the wiring wrong if you hook up to the right pads on the 9x. The only problem with it is getting access to the programming connector from the outside requires making a pretty large hole in the bottom of the case of the transmitter. It is difficult to make it neat and pretty. In addition, the 4x2 connector is not particularly cheap. The following method is pretty easy, and is neat and clean as the pictures show. It requires you to fabricate a custom cord between your programmer and the connector on the bottom of the 9x, which requires you to use a volt-ohm meter to figure out the hookup. This guide assumes you have read and understand the main guide on flashing the 9x. This guide only covers the mechanical differences in hookup.

Here's a couple of pictures to get your interest.


Hardware

You will need the following items from DigiKey:

Mini DIN Receptacle, 6 pin; CP-2960-ND: http://search.digikey.com/scripts/DkSearch/dksus.dll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 (http://search.digikey.com/scripts/DkSearch/dksus.dll?WT.z_header=search_go%E2%8C%A9=en&site=us&x=0&y=0)

5x2 Socket Assembly with polarizing key and strain relief; H1DXH-1036M-ND http://search.digikey.com/scripts/DkSearch/dksus.dll?vendor=0&keywords=H1DXH-1036M-ND
It will look something like this when you get it, only it will have a 36” long piece of multicolor ribbon cable on it.


Keyboard Extension Cable, PS/2 http://search.digikey.com/scripts/DkSearch/dksus.dll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 (http://search.digikey.com/scripts/DkSearch/dksus.dll?WT.z_header=search_go%E2%8C%A9=en&site=us&x=0&y=0)

Heat shrink tubing of various sizes.


15-30 watt GROUNDED soldering pencil iron.

Rosin core solder.

Various drill bits, small sheet metal screws, small side cutters, wire strippers, etc.

Optional:
Spare Connector with strain relief for ribbon cable in case you screw something up!; HKR10H-ND: http://search.digikey.com/scripts/DkSearch/dksus.dll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 (http://search.digikey.com/scripts/DkSearch/dksus.dll?WT.z_header=search_go%E2%8C%A9=en&site=us&x=0&y=0)

Installation

As you can see, this uses a nice 6 pin mini-DIN connector to use on the 9x. You use the 5x2 cable assembly, along with a section of the PS/2 keyboard extension cable to make an adapter cable from your programmer to the mini-DIN connector on the 9x. The good news is that the min-DIN connector already has the wires you need to solder to the mainboard on the 9x. The bad news is that the PS/2 extension cables, do NOT use the same color code, hence the need for a volt-ohm meter to figure out the right connections.

Plug in your soldering iron, and let it get hot.

The first step in this case is to make the adapter cable between the programmer and the mini-DIN connector. Do NOT solder the mini-DIN connector in the 9x yet! Using your side cutters, cut off one end of the PS/2 cable, about 6-8” from the end. Carefully strip the outer insulation off the cable about 1 “ from the end of the cable. Note that there will be an uninsulated ground wire along with the colored wires inside the cable. You don't need it, so cut it off close to where the wires come out of the cable. Strip each wire about 1/8” from the end.

Now plug the cable you just prepared into the min-DIN socket assembly. You are now going to check continuity on each wire end to end to figure out what color wire on the mini-DIN connector matches what color wire on the cable. Write this down as you will need it in a couple of minutes. You notes should look something like this:

Mini-DIN | Cable
Black | Red
Yellow | Yellow
Red | Green
White | Brown
Brown | Black
Green | Orange

Please note that the above is ONLY an example. Yours may, and probably will be different, especially if you got your cable from a source other than DigiKey. Check and recheck your setup carefully.

Now take your 5x2 connector assembly with the colored ribbon cable. We are going to match the colors between the mini-DIN cable and the ribbon cable as best we can. Given that, add another column to your color code notes as above:

Mini-DIN | PS/2Cable | 5x2 Ribbon Cable assembly
Black | Red | Black
Yellow | Yellow | Purple
Red | Green | Red
White | Brown | White
Brown | Black | Brown
Green | Orange | Green

Note that all of the colors in the first column align with the last column, except for purple. So now you will solder Red on the PS/2 cable to Black on the Ribbon cable, Yellow to Purple, Green to Red, etc. Again, check your own cables!

Cut the ribbon cable about 6” from the end of the cable. Carefully separate each of the wires in the ribbon to about 1” from the end. You won't need any colors except the ones above in the last column, so cut off the rest of them back to the separation point. Strip each wire about 1/8”. Tin each of the wires on the ribbon cable and the PS/2 cable. Cut 6, 1/2” pieces of small heatshrink tubing and push one piece over each of the wires you separated on the ribbon cable back to the separation point.


You can also tin the ends on the mini-DIN cable while you are at it, but you won't be soldering anything to it at the moment. Cut a 3” piece of 3/8” heat shrink tubing, and push it over the PS/2 cable end.


Now solder each of the wires in column two to those in column three. Check each wire to wire connection against the color codes above carefully. After you are SURE you connected the correct wires, push the small heat shrink over each solder joint.

Use a heat gun and shrink the tubing, making sure each solder joint is completely insulated. Now push the 3/8” heat shrink over the whole joint, and shrink it down. You should end up with a cable looking like this:

Now, you are ready to mount the PS/2 cable assembly in your 9x. This is a case of measure twice and cut once. I made a small mistake on mine, and mounted the connector assembly too close to the opening on the back. I should have mounted it as close to the circuit board as I could to keep it from interfering with the battery compartment. As it is, I had to slightly shave both the connector and the compartment to clear.


After measuring twice to ensure everything will clear, drill a hole in the bottom of the case, starting with about a 1/8” bit, and enlarging until the barrel of the connector on the cable will clear it and go into the connector held in place in the case. Once you have done that, drill two smaller holes and use small sheet metal screws to hold it in place.

Refer to the soldering guide in my main flashing document on where to solder the various wires. The ONLY difference in colors is replacing the purple wire in the original guide, with the yellow wire from the mini-DIN connector.


Hook everything up, and test it out, as I explain in my main guide.

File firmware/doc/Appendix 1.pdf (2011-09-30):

Installing the AVR Pocket Programmer Drivers on a Vista/Windows 7 x64 System

Unfortunately, Microsoft has seen fit to make installation of so-called unsigned drivers on x64 systems a real pain. Unless a driver is signed, a process which can cost a developer several hundred dollars to let Microsoft “bless” it, it can be put on the system, but Windows refuses to use it because it may be a security risk. Why this is different than a x86 system is beyond me. Anyway, the Pocket Programmer drivers are unsigned as are most others for programmers. Several people have asked Sparkfun to make a signed driver, but they haven't done so yet, and I wouldn't hold your breath.

My recommendation is to skip this headache if you have a 32bit system you can use. If the only thing you've got is a x64 system, then you will have to go thru this.

I have not included all of the dialog boxes and graphics in this guide. If there is enough demand, I will do so. But if you are here, you are willing to wade in pretty deep into the bowels of Windows anyway, so following these instructions shouldn't phase you.

You will need two more programs to fool Windows into thinking your driver is signed, and get rid of a “watermark” that Windows puts on your desktop as a result of this fix. Get the following programs:

Driver Signature Enforcement Overrider 1.3b, available here: http://www.softpedia.com/get/Tweak/Video-Tweak/Driver-Signature-Enforcement-Overrider.shtml

RemoveWatermark
http://soft3.wmzhe.com/download/deepxw/RemoveWatermark_20090509.zip

I successfully did this on an x64 computer I have. There have been no ill effects of doing this, but your experiences may be very different from mine.

Instructions:

Follow my guide for 32 bit systems for installing the driver for the Pocket Programmer. Windows will still complain about unsigned drivers, and will install the the x64 version, and you will think all is good. But, it won't actually use them. They will be blocked from working, if you look in the Device Properties for the Pocket AVR.

First, go to the Start menu, and select items in the following order:

Start/Control Panel/User Accounts/Change User Account Control settings

In the resulting dialog box, set the control to “Never Notify”. You can change this back later if you wish.

Right click on the Driver Signature Enforcement Overrider (dseo) Program that you downloaded, titled “dseo13b.exe”. Select “Run as Administrator” in the menu that comes up. You will get the usual Windows warning, click thru it, and then you will get a couple of windows from dseo itself. Good reading if you are so inclined. Anyway, click thru them, and you will get a dialog box with a bunch of buttons.

Select “Enable TestMode”, and click Next.

You will get a dialog box, saying that TestMode has been enabled, and restart the computer. Go ahead and do so now.

After restarting the computer, restart dseo as an administrator, and select the button “Sign a System File”, and click Next. You will now get a dialog box where you have to type in the complete path to the file you want to sign. So what files do you sign? Well, go to the Device Manager in the Control Panel, and click on “LibUSB-Win32 Devices”. “AVR Pocket Programmer” should now appear. Double click on it, and select the “Driver” tab in the resulting window. Click on the “Driver Details” button in the resulting window. The three driver files there, with their paths (e.g. c:\Windows\System32\drivers\libusb0.sys) are the ones you have to type in the the dseo window. I haven't been able to figure out how to cut and paste them from the window, so just type them into dseo EXACTLY as they appear. Type in the first one, and hit “Ok”. You will get a window saying that it has been fixed, and that if you restart, it should load. Don't restart yet. Click ok, and do the same thing for the other two files in the Driver File Details window. After you have done all three, restart your computer. Now if you go to the Device manager and look at the AVR Pocket Programmer info, it should be loaded.

HOWEVER, now you will probably have a watermark in the lower right hand portion of your screen with “Test Mode” and some other info in it. It won't harm anything, but if you want to get rid of it, do the following:

Open the folder for RemoveWatermark_20090509. I'd advise reading the ReadMeEn.txt file. Right click on the “RemoveWatermarkx64.exe” program you downloaded. It will start up a command line window. Type “y” . It will run a few seconds, and complete. Close the window, and restart your computer. If the watermark is still there, restart RemoveWatermark64, and hit “R” . It will take a few seconds and rebuild a cache. When it is done, either log off and back on, or restart. Now your watermark should be gone.

By the way, dseo has a button called “Remove Watermark” but all it does is take you to webpage to download RemoveWatermark.

The rest of my regular guide should now work ok.

Now wasn't that a pain in the butt? Why Microsoft made x64 different than x86, I don't know.

Version 1, 20 Sep 2010

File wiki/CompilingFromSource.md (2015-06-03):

# This project has been superseded by [opentx](http://opentx.googlecode.com/) #

The following data is likely obsolete, kept here for mostly just for historical record.

# Compiling gruvin9x from Source #
**NOTE:** Intended for Mac OS X audiences. Details for Windows (and mention of Linux) can be found in the original TH/ER9X project document [Flashing the 9x.pdf](http://gruvin9x.googlecode.com/svn/trunk/doc/Flashing%20the%209x.pdf).

## Downloading the gruvin9x Source Code ##

The gruvin9x project is fully version-tracked using Subversion, or `svn`. There are various way s of getting Subversion installed on your Mac, but in the author's opinion, the best way for a OS X based code developer is to simply install Apple's Xcode AKA Apple Developer Tools, with the Unix Dev option ticked. Xcode comes free with each version of OS X on the installation DVD. Subversion will be installed as part of all that.

To download the complete gruvin9x project source, enter the following command at a shell prompt ...

```
~$ svn checkout http://gruvin9x.googlecode.com/svn/trunk/ gruvin9x
```

This will create a folder named `gruvin9x` in the folder you were in when you ran the command. Of course, the gruvin9x folder can then be safely renamed or moved anywhere you like.

To build the firmware code ready for programming (having first installed [CrossPack](http://www.obdev.at/products/crosspack/) for that purpose), change to the `gruvin9x/src/` directory and execute `make`. Briefly ...

Our default Makefile is supplied as Makefile.dist. So you should initially copy that to Makefile ...

```
cp Makefile.dist Makefile
```

To build the correct version of gruvin9x to work on an not-modified, factory standard '9X, use ...

```
make clean; make PCB=STD
```

or, if you want variable tone frequency beeps etc., this will also work without installing a speaker ...

```
make clean; make PCB=STD BEEPER-SPEAKER
```

To build for the v4.1 custom controller board (with all default feature options) ...

```
make clean; make PCB=V4
```

Running make with no parameters is not really encouraged. Doing so will build the project in such a way as matches the latest development controller board and Gruvin's default options.

To build gruvin9x for a modified stock controller board, with the [telemetry](TelemetryMod.md) and [speaker](SpeakerReplacement.md) mods enabled ...

```
make clean; make PCB=STD EXT=FRSKY BEEPER=SPEAKER
```

Please see the comments throughout `Makefile.dist` itself or the [Make Options](MakeOptions.md) wiki page for more detail.

## Flashing the 9X Using Make ##

You can manually flash the ATmega64A using AVRDUDE as described on the [Connecting a Flash programmer to your '9X](FlashGuide.md) wiki page. Or you can use the more conveninet `make` method, which includes all the necessary options for you. (You may want to edit Makefile for your particular programmer set-up.) ...

```
make wflash
```

HINT: Add something like `AVRDUDE_PROGRAMMER=usbtiny` to specify a different programmer, or edit Makefile to change the default.
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

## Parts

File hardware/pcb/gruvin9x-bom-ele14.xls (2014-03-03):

nz.element14.com 'next day delivery' cheapest pricing BOM
v4.2 Main and RTC/SD-card Boards |  |  |  | as at 2012-04-17
 |  |  |  | Farnell UK |  |  |  |  | Pricing |  | significant | Pricing for 10 units
Farnell Part No. | Price Ea. | MOQ | Qty | Manufacturer Name | Mfr Part No. | Description | Value | Footprint | Raw Amount | MOQ Amount | MOQ impact | Raw Amount | MOQ Amount
MAIN BOARD V4.1
1710190 (http://nz.element14.com/multicomp/mc0603n180k500ct/capacitor-ceramic-18pf-50v-c0g/dp/1710190) | 0.03 | 1 | 2 | Multicomp | MC0603N180K500CT | Capacitor ceramic | 18pF | SM0603 | 0.06 | 0.06 |  | 0.60 | 0.60
1709957 (http://nz.element14.com/multicomp/mc0603b104m250ct/capacitor-ceramic-0-1uf-25v-x7r/dp/1709957) | 0.03 | 1 | 51 | Multicomp | MC0603B104M250CT | Capacitor ceramic | 0.1uF 25V | SM0603 | 1.53 | 1.53 |  | 15.30 | 15.30
1710292 (http://nz.element14.com/multicomp/mc0603x105m160ct/capacitor-ceramic-1uf-16v-x5r-0603/dp/1710292) | 0.057 | 1 | 11 | Multicomp | MC0603X105M160CT | Capacitor ceramic | 1uF 16V | SM0603 | 0.63 | 0.63 |  | 6.27 | 6.27
1759445 (http://nz.element14.com/multicomp/mcca000564/mlcc-12065v-16v-10uf/dp/1759445) | 0.156 | 10 | 4 | Multicomp | MCCA000564 | Capacitor ceramic | 10uF 16V | SM1206 | 0.62 | 1.56 |  | 6.24 | 6.24
1844348 (http://nz.element14.com/tdk/c3225x5r1c226k/capacitor-ceramic-22uf-16v-x5r/dp/1844348) | 1.18 | 1 | 1 | TDK | C3225X5R1C226K | Capacitor ceramic | 22uF 16V | SM1210 | 1.18 | 1.18 |  | 11.80 | 11.80
1432351 (http://nz.element14.com/avx/taja476k006rnj/capacitor-case-a-47uf-6-3v/dp/1432351) | 0.396 | 1 | 4 | AVX | TAJA476K006RNJ | Capacitor tant | 47uF 6.3V | SM1206 | 1.58 | 1.58 |  | 15.84 | 15.84
1692453 (http://nz.element14.com/multicomp/mc0603wg00000t5e-tr/resistor-0603-0-063w-0r/dp/1692453) | 0.01 | 50 | 4 | Multicomp | MC0603WG00000T5E-TR | Resistor | 0R | SM0603 | 0.04 | 0.50 |  | 0.40 | 0.50
9331484 (http://nz.element14.com/multicomp/mc-0-063w-0603-1-68r/resistor-0603-68r/dp/9331484) | 0.01 | 50 | 2 | Multicomp | MC 0.063W 0603 1% 68R | Resistor | 68R | SM0603 | 0.02 | 0.50 |  | 0.20 | 0.50
9330364 (http://nz.element14.com/multicomp/mc-0-063w-0603-1-100r/resistor-0603-100r-0-063w-1/dp/9330364) | 0.01 | 50 | 2 | Multicomp | MC 0.063W 0603 1% 100R | Resistor | 100R | SM0603 | 0.02 | 0.50 |  | 0.20 | 0.50
9330755 (http://nz.element14.com/multicomp/mc-0-063w-0603-1-200r/resistor-0603-200r/dp/9330755) | 0.01 | 50 | 40 | Multicomp | MC 0.063W 0603 1% 200R | Resistor | 200R | SM0603 | 0.40 | 0.50 |  | 4.00 | 4.00
9330380 (http://nz.element14.com/multicomp/mc-0-063w-0603-1-1k/resistor-0603-1k-0-063-1/dp/9330380) | 0.01 | 50 | 5 | Multicomp | MC 0.063W 0603 1% 1K | Resistor | 1K | SM0603 | 0.05 | 0.50 |  | 0.50 | 0.50
9330607 (http://nz.element14.com/multicomp/mc-0-063w-0603-1-1k5/resistor-0603-1k5/dp/9330607) | 0.01 | 50 | 1 | Multicomp | MC 0.063W 0603 1% 1K5 | Resistor | 1K5 | SM0603 | 0.01 | 0.50 |  | 0.10 | 0.50
9330925 (http://nz.element14.com/multicomp/mc-0-063w-0603-1-2k7/resistor-0603-2k7/dp/9330925) | 0.01 | 50 | 1 | Multicomp | MC 0.063W 0603 1% 2K7 | Resistor | 2K7 | SM0603 | 0.01 | 0.50 |  | 0.10 | 0.50
9331301 (http://nz.element14.com/multicomp/mc-0-063w-0603-1-5k1/resistor-0603-5k1/dp/9331301) | 0.01 | 50 | 31 | Multicomp | MC 0.063W 0603 1% 5K1 | Resistor | 5K1 | SM0603 | 0.31 | 0.50 |  | 3.10 | 3.10
9330399 (http://nz.element14.com/multicomp/mc-0-063w-0603-1-10k/resistor-0603-10k-0-063w-1/dp/9330399) | 0.01 | 50 | 15 | Multicomp | MC 0.063W 0603 1% 10K | Resistor | 10K | SM0603 | 0.15 | 0.50 |  | 1.50 | 1.50
1170889 (http://nz.element14.com/multicomp/mc-0-063w-0603-1-10k2/resistor-0603-10k2/dp/1170889) | 0.01 | 50 | 3 | Multicomp | MC 0.063W 0603 1% 10K2 | Resistor | 10K2 | SM0603 | 0.03 | 0.50 |  | 0.30 | 0.50
9330402 (http://nz.element14.com/multicomp/mc-0-063w-0603-1-100k/resistor-0603-100k-0-063w-1/dp/9330402) | 0.01 | 50 | 5 | Multicomp | MC 0.063W 0603 1% 100K | Resistor | 100K | SM0603 | 0.05 | 0.50 |  | 0.50 | 0.50
9330623 (http://nz.element14.com/multicomp/mc-0-063w-0603-1-150k/resistor-0603-150k/dp/9330623) | 0.01 | 50 | 2 | Multicomp | MC 0.063W 0603 1% 150K | Resistor | 150K | SM0603 | 0.02 | 0.50 |  | 0.20 | 0.50
9330739 (http://nz.element14.com/multicomp/mc-0-063w-0603-1-180k/resistor-0603-180k/dp/9330739) | 0.01 | 50 | 1 | Multicomp | MC 0.063W 0603 1% 180K | Resistor | 180K | SM0603 | 0.01 | 0.50 |  | 0.10 | 0.50
1081244 (http://nz.element14.com/nxp/bc857/transistor-pnp-sot-23/dp/1081244?Ntt=1081244) | 0.091 | 10 | 1 | NXP | BC857C | Transistor | PNP gen. purp. switch | SOT-23 | 0.09 | 0.91 |  | 0.91 | 0.91
1081235 (http://nz.element14.com/nxp/bc847c/transistor-npn-sot-23-45v/dp/1081235) | 0.1 | 10 | 7 | NXP | BC847C | Transistor | NPN gen. purp. switch. | SOT-23 | 0.70 | 1.00 |  | 7.00 | 7.00
1456534 (http://nz.element14.com/bourns/cd0603-b00340/diode-schottky-30ma-45v-603/dp/1456534?Ntt=1456534) | 0.45 | 1 | 3 | BOURNS | CD0603-B00340 | Diode | Schottky 30mA | SM0603 | 1.35 | 1.35 |  | 13.50 | 13.50
1456535 (http://nz.element14.com/bourns/cd0603-s01575/diode-signal-150ma-100v-603/dp/1456535) | 0.149 | 1 | 1 | BOURNS | CD0603-S0180 | Diode | Silicone signal (150mA) | SM0603 | 0.15 | 0.15 |  | 1.49 | 1.49
8735654 (http://nz.element14.com/nxp/bzx384-c3v6/diode-zener-3-6v-5-sod-323/dp/8735654) | 0.174 | 10 | 2 | NXP | BZX384-C3V6 | Diode | Zener 3.6v | SOD323 | 0.35 | 1.74 | 1.39 | 3.48 | 3.48
8735735 (http://nz.element14.com/nxp/bzx384-c5v1/diode-zener-5-1v-5-sod-323/dp/8735735) | 0.174 | 10 | 1 | NXP | BZX384-C5V1 | Diode | Zener 5.1v | SOD523 | 0.17 | 1.74 | 1.57 | 1.74 | 1.74
9491856 (http://nz.element14.com/jst-japan-solderless-terminals/b2b-ph-k-s-lf-sn/header-top-entry-2way-2mm/dp/9491856) | 0.329 | 10 | 2 | JST | B2B-PH-K-S(LF)(SN) | JST PH series header | 2-way | SIL 2mm | 0.66 | 3.29 |  | 6.58 | 6.58
9492429 (http://nz.element14.com/jst-japan-solderless-terminals/b3b-ph-k-s-lf-sn/header-top-entry-3way/dp/9492429) | 0.435 | 10 | 4 | JST | B3B-PH-K-S(LF)(SN) | JST PH series header | 3-way | SIL 2mm | 1.74 | 4.35 |  | 17.40 | 17.40
9492437 (http://nz.element14.com/jst-japan-solderless-terminals/b4b-ph-k-s-lf-sn/header-top-entry-4way-2mm/dp/9492437) | 0.541 | 10 | 2 | JST | B4B-PH-K-S(LF)(SN) | JST PH series header | 4-way | SIL 2mm | 1.08 | 5.41 |  | 10.82 | 10.82
9492445 (http://nz.element14.com/jst-japan-solderless-terminals/b5b-ph-k-s-lf-sn/header-top-entry-5way/dp/9492445) | 0.764 | 10 | 2 | JST | B5B-PH-K-S(LF)(SN) | JST PH series header | 5-way | SIL 2mm | 1.53 | 7.64 |  | 15.28 | 15.28
9492453 (http://nz.element14.com/jst-japan-solderless-terminals/b6b-ph-k-s-lf-sn/header-top-entry-6way/dp/9492453) | 0.859 | 10 | 2 | JST | B6B-PH-K-S(LF)(SN) | JST PH series header | 6-way | SIL 2mm | 1.72 | 8.59 |  | 17.18 | 17.18
9492461 (http://nz.element14.com/jst-japan-solderless-terminals/b8b-ph-k-s-lf-sn/header-top-entry-8way/dp/9492461) | 1.09 | 10 | 1 | JST | B8B-PH-K-S(LF)(SN) | JST PH series header | 8-way | SIL 2mm | 1.09 | 10.90 |  | 10.90 | 10.90
9491872 (http://nz.element14.com/jst-japan-solderless-terminals/b9b-ph-k-s-lf-sn/header-top-entry-9way/dp/9491872) | 1.18 | 10 | 2 | JST | B9B-PH-K-S(LF)(SN) | JST PH series header | 9-way | SIL 2mm | 2.36 | 11.80 |  | 23.60 | 23.60
9492470 (http://nz.element14.com/jst-japan-solderless-terminals/b12b-ph-k-s-lf-sn/header-top-entry-12way/dp/9492470) | 0.56 | 10 | 1 | JST | B12B-PH-K-S(LF)(SN) | JST PH series header | 12-way | SIL 2mm | 0.56 | 5.60 |  | 5.60 | 5.60
3616186 (http://nz.element14.com/jst-japan-solderless-terminals/phr-2/housing-2way-2mm/dp/3616186?Ntt=3616186) | 0.101 | 1 | 2 | JST | PHR-2 | JST PH series housing | 2-way | SIL 2mm | 0.20 | 0.20 |  | 2.02 | 2.02
3616198 (http://nz.element14.com/jst-japan-solderless-terminals/phr-3/housing-3way-2mm/dp/3616198?Ntt=3616198) | 0.122 | 1 | 4 | JST | PHR-3 | JST PH series housing | 3-way | SIL 2mm | 0.49 | 0.49 |  | 4.88 | 4.88
3616204 (http://nz.element14.com/jst-japan-solderless-terminals/phr-4/housing-4way-2mm/dp/3616204?Ntt=3616204) | 0.122 | 1 | 2 | JST | PHR-4 | JST PH series housing | 4-way | SIL 2mm | 0.24 | 0.24 |  | 2.44 | 2.44
3617210 (http://nz.element14.com/jst-japan-solderless-terminals/bph-002t-p0-5s/contact-loose-piece-0-05-0-22mm/dp/3617210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) | 0.061 | 1 | 29 | JST | BPH-002T-P0.5S | Terminals (JST) | JST 28-24-AWG | N/A | 1.77 | 1.77 |  | 17.69 | 17.69
1509141 (http://nz.element14.com/molex/52435-3071/socket-zif-0-5mm-30way/dp/1509141?Ntt=1509141) | 4.84 | 1 | 1 | MOLEX | 52435-3071 | Connector | 30-way flat ZIF | Contacts on TOP | 4.84 | 4.84 |  | 48.40 | 48.40
3418510 (http://nz.element14.com/te-connectivity-amp/826632-5/header-2row-10way/dp/3418510) | 0.772 | 1 | 1 | AMP | 826632-5 2ROW 10WAY (Gold) | 5x2 + 3x2 Header (pins) | Split into a 2x3 and a 2x5 | 2.54mm male pins | 0.77 | 0.77 |  | 7.72 | 7.72
1463501 (http://nz.element14.com/taiyo-yuden/lb2012t100kr/wirewound-inductor-10uh-100ma-10/dp/1463501?Ntt=1463501) | 0.865 | 1 | 2 | TAIYO YUDEN | LB2012T100KR | Inductor/Choke | 10uH 60mA +/-20% | SM0805 | 1.73 | 1.73 |  | 17.30 | 17.30
1842216 (http://nz.element14.com/txc/9b-16-000maaj-b/xtal-16-000mhz-18pf-hc-49s/dp/1842216?Ntt=1842216) | 0.867 | 1 | 1 | TXC | 9B-16.000MAAJ-B | Crystal | 16MHz 18pF +/-50ppm | HC-49US | 0.87 | 0.87 |  | 8.67 | 8.67
1555985 (http://nz.element14.com/te-connectivity-alcoswitch/fsm8jh/switch-tactile-spno/dp/1555985?Ntt=FSM8JH) | 0.256 | 25 | 6 | TE Connectivity | FSM8JH | Push Switch NO/MC | TACT 6MM BLACK 160GF | 6x4mm pins 9.5mm H. | 1.54 | 6.40 | 4.86 | 15.36 | 15.36
3605772 (http://nz.element14.com/torex/xc6202p502pr/v-reg-ldo-5-0v-smd-6202-sot893/dp/3605772?Ntt=3605772) | 2.9 | 1 | 2 | TOREX | XC6202P502PR | 5 Volt Regulator 200mA | 5V LDO OUT / GND / IN | SOT-89-3 | 5.80 | 5.80 |  | 58.00 | 58.00
3605784 (http://nz.element14.com/torex/xc6203e332pr/v-reg-ldo-3-3v-smd-6203-sot893/dp/3605784?Ntt=3605784) | 2.9 | 1 | 1 | TOREX | XC6203E332PR | 3.3V Regulator 400mA | 3.3V LDO GND / IN / OUT | SOT-89-3L | 2.90 | 2.90 |  | 29.00 | 29.00
1235041 (http://nz.element14.com/texas-instruments/tps77601dg4/ic-v-reg-ldo-0-5a-adj-smd-soic8/dp/1235041?Ntt=1235041) | 5.38 | 1 | 1 | Texas Instruments | TPS77601DG4 | Variable regulator | With Enable | SOIC-8 | 5.38 | 5.38 |  | 53.80 | 53.80
1288330 (http://nz.element14.com/atmel/atmega2560-16au/8bit-mcu-256k-flash-5v-smd-2560/dp/1288330?Ntt=1288330) | 33.28 | 1 | 1 | Atmel | ATMEGA2560-16AU | IC (MCU) | ATmega2560 | TQFP 0.5mm | 33.28 | 33.28 |  | 332.80 | 332.80
1838961 (http://nz.element14.com/bourns/pec11-4220f-s0012/increm-encoder-dual-60rpm-12mm/dp/1838961?Ntt=1838961) | 2.9 | 1 | 2 | Bourns | PEC11-4220F-S0012 | Rotary encoder | Bi-Phase with switch (must have a detent-to-pulse ratio of 2:1 to work with the current code) | NO STOCK | 5.80 | 5.80 |  | 58.00 | 58.00
1282553 (http://nz.element14.com/mentor/505-613/knob-aluminium-setscrew/dp/1282553?Ntt=1282553) | 4.34 | 1 | 2 | Mentor | 505.613 | Knob | Splined with 6mm bore | 6 - 7 days delivery | 8.68 | 8.68 |  | 86.80 | 86.80
1858942 (http://nz.element14.com/vishay-siliconix/si2319cds-t1-ge3/mosfet-p-ch-40v-4-4a-diode-sot23/dp/1858942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) | 0.78 | 1 | 2 | Vishay/Siliconix | SI2319CDS-T1-GE3 | P-Channel MOSFET | Si2319DS | SOT-23 | 1.56 | 1.56 |  | 15.60 | 15.60
1234836 (http://nz.element14.com/texas-instruments/ref3012aidbztg4/ic-sm-volt-ref-1-25v/dp/1234836) | 4.32 | 1 | 1 | Texas Instruments | REF3012AIDBZTG4 | Voltage Reference | REF3012 | SOT-23 | 4.32 | 4.32 |  | 43.20 | 43.20
1596990 (http://nz.element14.com/littelfuse/1206l025yr/fuse-resettable-1206-16v-250ma/dp/1596990?Ntt=1596990) | 0.546 | 10 | 1 | Littlefuse | 1206L025YR | Fuse | 250mA | SM1206 | 0.55 | 5.46 | 4.91 | 5.46 | 5.46
 |  |  |  |  |  |  |  |  | 100.99 | 168.00 | 12.736 | 1009.87 | 1012.27
 |  |  |  |  |  |  |  |  |  |  |  |  | 101.23 | ea.
RTC/SD-card Board v4.1
1709957 (http://nz.element14.com/multicomp/mc0603b104m250ct/capacitor-ceramic-0-1uf-25v-x7r/dp/1709957) | 0.03 | 1 | 2 | Multicomp | MC0603B104M250CT | Capacitor ceramic | 0.1uF 25V | SM0603 | 0.06 | 0.06 |  | 0.60 | 0.60
9330380 (http://nz.element14.com/multicomp/mc-0-063w-0603-1-1k/resistor-0603-1k-0-063-1/dp/9330380) | 0.01 | 50 | 1 | Multicomp | MC 0.063W 0603 1% 1K | Resistor | 1K | SM0603 | 0.01 | 0.50 |  | 0.10 | 0.50
9331301 (http://nz.element14.com/multicomp/mc-0-063w-0603-1-5k1/resistor-0603-5k1/dp/9331301) | 0.01 | 50 | 4 | Multicomp | MC 0.063W 0603 1% 5K1 | Resistor | 5K1 | SM0603 | 0.04 | 0.50 |  | 0.40 | 0.50
9330399 (http://nz.element14.com/multicomp/mc-0-063w-0603-1-10k/resistor-0603-10k-0-063w-1/dp/9330399) | 0.01 | 50 | 5 | Multicomp | MC 0.063W 0603 1% 10K | Resistor | 10K | SM0603 | 0.05 | 0.50 |  | 0.50 | 0.50
1379714 (http://nz.element14.com/maxim-integrated-products/ds1338z-33/rtc-56b-nvram-i2c-1338-soic8/dp/1379714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) | 6.32 | 1 | 1 | Maxim | DS1338Z-33+ | RTC | DS1338-33 | 8-SOIC 3.90mm | 6.32 | 6.32 |  | 63.20 | 63.20
1278036 (http://nz.element14.com/epson-toyocom/fc-135-32-768khz-20ppm-12-5pf/crystal-sm-watch/dp/1278036?Ntt=1278036) | 4.06 | 1 | 1 | Epson Toyocom | FC-135 32.768KHZ | Xtal | 32.768KHz 12.5pf | 2-SMD 3.2x2.5mm | 4.06 | 4.06 |  | 40.60 | 40.60
3616241 (http://nz.element14.com/jst-japan-solderless-terminals/phr-8/housing-8way/dp/3616241?Ntt=3616241) | 0.202 | 1 | 1 | JST | PHR-8 | JST PH series housing | 8-way | SIL 2mm
3617210 (http://nz.element14.com/jst-japan-solderless-terminals/bph-002t-p0-5s/contact-loose-piece-0-05-0-22mm/dp/3617210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) | 0.061 | 1 | 8 | JST | BPH-002T-P0.5S | Terminals (JST) | JST 28-24-AWG | N/A | 0.49 | 0.49 |  | 4.88 | 4.88
1650693 (http://nz.element14.com/keystone/3002/battery-smd-retainer-20mm/dp/1650693?Ntt=1650693) | 1.54 | 1 | 1 | Keystone | 3002 | Battery Holder | Metal frame-only type | 20MM COIN CR2032 | 1.54 | 1.54 |  | 15.40 | 15.40
9186174 (http://nz.element14.com/multicomp/sdbmf-00915b0t2/pcb-socket-connector-9way/dp/9186174?Ntt=9186174) | 8.17 | 1 | 1 | Mutlicomp | SDBMF-00915B0T2 | SD Card Socket |  | SMD see datasheet | 8.17 | 8.17 |  | 81.70 | 81.70
1823479 (http://nz.element14.com/renata/cr-2032-mfr-1bl/cell-lithium-button-3v/dp/1823479?Ntt=1823479) | 1.93 | 1 | 1 | Renata | CR 2032 MFR (1BL) | Lithium Battery | 3V 20mm |  | 1.93 | 1.93 |  | 19.30 | 19.30
 |  |  |  |  |  |  |  |  | 22.67 | 24.07 |  | 226.68 | 227.18
The Atmega2560 is about US$11 ea. from DigiKey, who have a US$33 shipping fee. Better to use Digikey if ordering in quantity. The 6mm Knob is non-essential. Buy it locally or select alternate part from nz.element14.com catalogue. |  |  |  |  |  |  | 1833023 (http://nz.element14.com/abracon/abs09-32-768khz-t/crystal-32-768khz-12-5pf-smd/dp/1833023?Ntt=1833023) | $1.69 |  |  |  |  | 22.718 | ea.
 |  |  |  |  |  | NOTE: A cheaper Xtal exists: 1833023. But it's 4.1x1.5mm and wont quite fit. :-( However, the originally specified Xtal is available from Digikey at under $2.
NOTE: These parts go with Cam's UK version of the SD card PCB, because the DigiKey (Asia) versions are not available from element14 / Farnell. (By the way, Gruvin prefers the spring-loaded ejection, DigiKey socket.)
 |  |  |  |  |  |  |  |  | Pricing
Expensive but better(?) alternatives ... |  |  |  |  |  |  |  |  | Raw Amount | MOQ Amount
1248132 (http://nz.element14.com/te-connectivity-amp/826925-3/header-straight-2x3way/dp/1248132) | 0.95 | 10 | 1 | AMP | 826925-3 | Header 2ROW, 3WAY | ISP Header | 2.54mm 3x2 IDC header | 0.95 | 9.50
1022235 (http://nz.element14.com/harwin/m20-9980545/header-2row-5way/dp/1022235) | 2.01 | 10 | 2 | AMP | M20-9980545 | Header 2ROW, 5WAY | JTAG Header | 2.54mm 5x2 IDC header | 4.02 | 20.10

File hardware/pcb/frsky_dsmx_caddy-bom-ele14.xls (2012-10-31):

nz.element14.com 'next day delivery' cheapest pricing BOM
Fr-Sky DSM2 TX Module Caddy Board v2.0 |  |  |  | as at 2012-10-29
nz.element14.com
ele14 Part No. | Price Ea. | MOQ | Qty | Manufacturer Name | Mfr Part No. | Description | Value | Footprint
1236598 (http://nz.element14.com/texas-instruments/ua78m05cdcyg3/v-reg-0-5a-5-0v-smd-sot-223-4/dp/1236598) | 0.74 | 1 | 1 | Texas Instruments | UA78L05ACPKG3 | 1A linear regulator | 5V | TO-223

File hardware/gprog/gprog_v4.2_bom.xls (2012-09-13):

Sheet: nz.element14.com
GPROG v1.20 Bill of Materials |  | See second Worksheet for DigiKey USA version.
2012-04-17 (Gruvin)
 |  |  |  |  | nz.element14.com
Description | Value | Qty | Package |  | Part No. | Price ea. | MOQ | Amount
Capacitor (ceramic) | 18p | 2 | SM0603 | C3, C4 | 721992 (http://nz.element14.com/yageo-phycomp/cc0603jrnpo9bn180/capacitor-0603-18pf-50v/dp/721992) | 0.057 | 10 | 0.57
Capacitor (ceramic) | 0u1 | 2 | SM0603 | C1, C5 | 1362556 (http://nz.element14.com/yageo-phycomp/cc0603krx7r9bb104/capacitor-0603-100nf-50v-x7r/dp/1362556) | 0.051 | 10 | 0.51
Capacitor (tantalum) | 22u | 1 | SM1210 | C2 | 1862119 (http://nz.element14.com/avx/tajb226k016rnj/capacitor-tant-22uf-16v-2-3ohm/dp/1862119) | 0.939 | 1 | 0.94
Resistor (thick-film) | 27R | 2 | SM0603 | R1, R2 | 9330950 (http://nz.element14.com/multicomp/mc-0-063w-0603-1-27r/resistor-0603-27r/dp/9330950) | 0.01 | 50 | 0.50
Resistor (thick-film) | 47R | 2 | SM0603 | R5, R6 | 9332138 (http://nz.element14.com/multicomp/mc-0-063w-0603-5-47r/resistor-0603-47r/dp/9332138) | 0.01 | 50 | 0.50
Resistor (thick-film) | 1K | 2 | SM0603 | R4, R9 | 9330380 (http://nz.element14.com/multicomp/mc-0-063w-0603-1-1k/resistor-0603-1k-0-063-1/dp/9330380) | 0.01 | 50 | 0.50
Resistor (thick-film) | 3K9 | 1 | SM0603 | R3 | 9331140 (http://nz.element14.com/multicomp/mc-0-063w-0603-1-3k9/resistor-0603-3k9/dp/9331140) | 0.01 | 50 | 0.50
Resistor (thick-film) | 5K6 | 2 | SM0603 | R7, R8 | 9331352 (http://nz.element14.com/multicomp/mc-0-063w-0603-1-5k6/resistor-0603-5k6-1-0-063w/dp/9331352) | 0.01 | 50 | 0.50
LED | RED | 2 | SM1206 | D5 | 1318257 (http://nz.element14.com/kingbright/kpc-3216src-prv/led-algaas-smd-red/dp/1318257) | 0.133 | 10 | 1.33
LED | GREEN | 2 | SM1206 | D6 | 1318255 (http://nz.element14.com/kingbright/kpc-3216sgd/led-smd-1206-diffused-green/dp/1318255) | 0.212 | 10 | 2.12
Zenor Didoe 3.6V | DO-213AC (Glass) | 2 | SM1206 | D3, D4 | 8735450 (http://nz.element14.com/nxp/bzv55-c3v6/diode-zener-3-6v-5-sod-80/dp/8735450) | 0.061 | 5 | 0.30
Schottky Diode (fast recovery) | Sctky 30mA | 2 | SM0603 | D1, D2 | 1456534 (http://nz.element14.com/jsp/search/productdetail.jsp?sku=1456534) | 0.441 | 1 | 0.88
Schottky Diode | Sctky 500mA | 1 | SM1206 | D7 | 1863141 (http://nz.element14.com/taiwan-semiconductor/b0520lw/diode-rectif-20v-0-5a-sod123/dp/1863141) | 0.174 | 1 | 0.17
ATmega88P (20MHz) | ATMEGA88P-20AU | 1 | 32QFN | IC1 | 1636946 (http://nz.element14.com/atmel/atmega88p-20au/8-bit-mcu-8k-fla-2-7-5-5v-tqfp32/dp/1636946) | 7.98 | 1 | 7.98
4-way tri-state buffer | SN74HC125DR | 1 | 14-TSSOP (4.40mm) | U1 | 1607617 (http://nz.element14.com/fairchild-semiconductor/mm74hc125mtc/ic-sm-logic-74hc-buffer/dp/1607617) | 0.865 | 1 | 0.86
Cystal | 12MHz / 18pf | 1 | HC49/US | X1 | 7940142 (http://nz.element14.com/abracon/abl-12-000mhz-b2/crystal-12mhz-18pf-through-hole/dp/7940142) | 0.919 | 1 | 0.92
USB-B mini socket | USB-B mini | 1 | SMD | USB | 1125348 (http://nz.element14.com/molex/675031020/socket-usb-mini-b-smt-w-pegs/dp/1125348) | 2.88 | 1 | 2.88
Target ISP Header | 2.54mm hdr 3x1 | 2 | 2 x 3:1 is cheaper | P1 | 1513501 (http://nz.element14.com/molex/90147-1103/header-pcb-3way/dp/1513501) | 0.7 | 1 | 1.40
USB Header (male) | 2.54mm hdr 4x1 | 1 | Unshrouded | P2 | 9733469 (http://nz.element14.com/molex/90121-0764/header-right-angle-1row-4way/dp/9733469) | 0.464 | 2 | 0.93
 |  |  |  |  |  |  | TOTAL | 23.37
USB Board to Programmer Wiring Options ...
The cheap, easy way ...
eBay item 280777612850 "10pcs 4pin Arduino 30cm jumper wire for Shield or EQUIV" $4.50
This will get you 20 sockets with wires already attached! Just cut the cables in half.
The hard, expensive way ....
Crimp Housing (4-way) | 2.54mm hdr 4x1 | 1 | Plastic |  | 1822585 (http://nz.element14.com/te-connectivity-amp/102241-2/wire-board-connector-receptacle/dp/1822585) | 1.06 | 1 | 1.06
Crimp sockets | 24-28AWG | 4 | N/A |  | 1823218 (http://nz.element14.com/te-connectivity-amp/87756-7/crimp-socket-26-22awg/dp/1823218) | 0.304 | 10 | 3.04
Optional ...
Hook-up Wire 26AWG x 25ft | Black | 1 | Reel |  | 1662108 (http://nz.element14.com/nte-electronics/wh26-00-25/hook-up-wire-25ft-26awg-cu-black/dp/1662108) | 8.92 | 1 | 8.92
Hook-up Wire 26AWG x 25ft | Green | 1 | Reel |  | 1662115 (http://nz.element14.com/nte-electronics/wh26-05-25/hook-up-wire-25ft-26awg-cu-green/dp/1662115) | 9.35 | 1 | 9.35
Hook-up Wire 26AWG x 25ft | Red | 1 | Reel |  | 1662110 (http://nz.element14.com/nte-electronics/wh26-02-25/hook-up-wire-25ft-26awg-cu-red/dp/1662110) | 8.92 | 1 | 8.92
Hook-up Wire 26AWG x 25ft | Yellow | 1 | Reel |  | 1662113 (http://nz.element14.com/nte-electronics/wh26-04-25/hook-up-wire-25ft-26awg-cu-yellow/dp/1662113) | 9.35 | 1 | 9.35
Or ...
Ribon Cable - 4-way / 4 colour | (per metre) | 1 |  |  | 150431 (http://nz.element14.com/pro-power/05006684/ribbon-cable-4way-per-m/dp/150431) | 1.32 | 5 | 6.60

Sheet: DigiKey USA
GPROG v1.00 Bill of Materials -- DigiKey USA Version
2012-09-13 (Original by JWB. Updated by Gruvin.)
Main Board
DigiKey Part No. | Manufacturer Name | Mfr Part No. | Description | Value | Package | Qty
609-3582-ND (http://search.digikey.com/scripts/DkSearch/dksus.dll?Detail&name=609-3582-ND) | FCI (http://digikey.com/Suppliers/nz/FCI.page?lang=EN) | 68002-303LF | 2x3 fPCB | P1 ISP out | 2.54mm female pins | 1
609-3312-ND (http://search.digikey.com/scripts/DkSearch/dksus.dll?Detail&name=609-3312-ND) | FCI (http://digikey.com/Suppliers/nz/FCI.page?lang=EN) | 68002-104HLF | 1 x 4pin | P2 USB in | 2.54mm male pins | 1
ATMEGA88PA-AU-ND (http://search.digikey.com/scripts/DkSearch/dksus.dll?Detail&name=ATMEGA88PA-AU-ND) | Atmel (http://digikey.com/Suppliers/us/Atmel.page?lang=EN) | ATmega88PA | Micro |  | TQFP | 1
296-26462-1-ND (http://www.digikey.com/product-detail/en/SN74HC126PWR/296-26462-1-ND/2255010) | Texas Instruments (http://digikey.com/Suppliers/us/Texas-Instruments.page?lang=EN) | SN74HC126PWR | Buffer driver non-invert | U1 | TSSOP | 1
641-1006-1-ND (http://search.digikey.com/scripts/DkSearch/dksus.dll?Detail&name=641-1006-1-ND) | Comchip Technology (http://digikey.com/Suppliers/us/Comchip-Technology.page?lang=EN) | CDBU00340 | Diode | Schottky | SM0603 | 2
BZV55C3V6-TPMSCT-ND (http://search.digikey.com/scripts/DkSearch/dksus.dll?Detail&name=BZV55C3V6-TPMSCT-ND) | Micro Commercial Co (http://digikey.com/Suppliers/us/Micro-Commercial-Components.page?lang=EN) | BZV55C3V6-TP | 3.6vz | Zener Diode | DO-213AC (Glass) | 2
P27GCT-ND (http://search.digikey.com/scripts/DkSearch/dksus.dll?Detail&name=P27GCT-ND) | Panasonic - ECG (http://digikey.com/Suppliers/us/Panasonic-Industrial-Products.page?lang=EN) | ERJ-3GEYJ270V | Resistor | 27R | SM0603 | 2
P47GCT-ND (http://search.digikey.com/scripts/DkSearch/dksus.dll?Detail&name=P47GCT-ND) | Panasonic - ECG (http://digikey.com/Suppliers/us/Panasonic-Industrial-Products.page?lang=EN) | ERJ-3GEYJ470V | Resistor | 47R | SM0603 | 2
P1.0KGCT-ND (http://search.digikey.com/scripts/DkSearch/dksus.dll?Detail&name=P1.0KGCT-ND) | Panasonic - ECG (http://digikey.com/Suppliers/us/Panasonic-Industrial-Products.page?lang=EN) | ERJ-3GEYJ102V | Resistor | 1K0 | SM0603 | 2
P3.9KGCT-ND (http://search.digikey.com/scripts/DkSearch/dksus.dll?Detail&name=P3.9KGCT-ND) | Panasonic - ECG (http://digikey.com/Suppliers/us/Panasonic-Industrial-Products.page?lang=EN) | ERJ-3GEYJ392V | Resistor | 3K9 | SM0603 | 1
P5.6KGCT-ND (http://search.digikey.com/scripts/DkSearch/dksus.dll?Detail&name=P5.6KGCT-ND) | Panasonic - ECG (http://digikey.com/Suppliers/us/Panasonic-Industrial-Products.page?lang=EN) | ERJ-3GEYJ562V | Resistor | 5K6 | SM0603 | 2
445-1272-1-ND (http://search.digikey.com/scripts/DkSearch/dksus.dll?Detail&name=445-1272-1-ND) | TDK Corporation (http://digikey.com/Suppliers/us/TDK.page?lang=EN) | C1608C0G1H180J | Capacitor ceramic | 18pF | SM0603 | 2
445-5122-1-ND (http://search.digikey.com/scripts/DkSearch/dksus.dll?Detail&name=445-5122-1-ND) | TDK Corporation (http://digikey.com/Suppliers/us/TDK.page?lang=EN) | C1608X7R1C104M | Capacitor ceramic | 0.1uF 16V | SM0603 | 2
478-1682-1-ND (http://search.digikey.com/scripts/DkSearch/dksus.dll?Detail&name=478-1682-1-ND) | AVX Corporation (http://digikey.com/Suppliers/us/AVX.page?lang=EN) | TAJB226K016RNJ | Capacitor tant | 22uF 16V | SM1210 | 1
XC1744-ND (http://search.digikey.com/scripts/DkSearch/dksus.dll?Detail&name=XC1744-ND) | ECS Inc (http://digikey.com/Suppliers/us/ECS.page?lang=EN) | ECS-120-18-23A-TR | Crystal | 12MHz 18pF +/-50ppm | HC-49S | 1
DFLS140DICT-ND (http://search.digikey.com/scripts/DkSearch/dksus.dll?Detail&name=DFLS140DICT-ND) | Diodes Inc (http://digikey.com/Suppliers/us/Diodes.page?lang=EN) | DFLS140-7 | Diode | Schottky | DI123 | 1
160-1405-1-ND (http://search.digikey.com/scripts/DkSearch/dksus.dll?Detail&name=160-1405-1-ND) | Lite-On Inc (http://digikey.com/Suppliers/us/Lite-On.page?lang=EN) | LTST-C150KRKT | Diode | LED Red | SM1206 | 1
160-1404-1-ND (http://search.digikey.com/scripts/DkSearch/dksus.dll?Detail&name=160-1404-1-ND) | Lite-On Inc (http://digikey.com/Suppliers/us/Lite-On.page?lang=EN) | LTST-C150KGKT | Diode | LED Green | SM1206 | 1
USB Socket Board
DigiKey Part No. | Manufacturer Name | Mfr Part No. | Description | Value | Package | Qty
670-1190-1-ND (http://search.digikey.com/scripts/DkSearch/dksus.dll?Detail&name=670-1190-1-ND) | JAE Electronics (http://digikey.com/Suppliers/us/JAE-Electronics.page?lang=EN) | DX2R005HN2E700 | miniUSB | miniUSB comm | miniUSB | 1
609-2339-ND (http://search.digikey.com/scripts/DkSearch/dksus.dll?Detail&name=609-2339-ND) | FCI (http://digikey.com/Suppliers/us/FCI.page?lang=EN) | 65039-033LF | 1x4 female | USB conn (+cable,pins) | 2.54mm female conn | 1
609-4536-1-ND (http://search.digikey.com/scripts/DkSearch/dksus.dll?Detail&name=609-4536-1-ND) | FCI (http://digikey.com/Suppliers/us/FCI.page?lang=EN) | 75231-013LF | USB connector pin | USB conn pin | 2.54mm female pins | 4
 |  |  |  |  | Total Part Count | 32
Alternate Items
DigiKey Part No. | Manufacturer Name | Mfr Part No. | Description | Value | Package | Qty
EDZTE613.6BCT-ND (http://search.digikey.com/scripts/DkSearch/dksus.dll?Detail&name=EDZTE613.6BCT-ND) | Rohm Semiconductor (http://digikey.com/Suppliers/us/ROHM.page?lang=EN) | EDZTE613.6B | 3.6vz | Zener Diode |  | 2
609-3253-ND (http://search.digikey.com/scripts/DkSearch/dksus.dll?Detail&name=609-3253-ND) | FCI (http://digikey.com/Suppliers/nz/FCI.page?lang=EN) | 68002-120LF | 1x20pin, 2x3 (optional) | P3 ISP in | 2.54mm male pins | 1

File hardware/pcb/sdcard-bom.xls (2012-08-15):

SD Card Board | 2011-08-15
v4.2 NZ / DigiKey version
Digi-Key Part No. | MOQ | Qty | Manufacturer Name | Mfr Part No. | Description | Value | Footprint
445-5122-1-ND (http://search.digikey.com/scripts/DkSearch/dksus.dll?Detail&name=445-5122-1-ND) |  | 2 | TDK Corporation (http://digikey.com/Suppliers/us/TDK.page?lang=EN) | C1608X7R1C104M | Capacitor | 0.1uF 16v | SM0603
P1.0KGCT-ND (http://search.digikey.com/scripts/DkSearch/dksus.dll?Detail&name=P1.0KGCT-ND) |  | 1 | Panasonic - ECG (http://digikey.com/Suppliers/us/Panasonic-Industrial-Products.page?lang=EN) | ERJ-3GEYJ103V | Resistor | 1K | SM0603
P5.1KGCT-ND (http://search.digikey.com/scripts/DkSearch/dksus.dll?Detail&name=P5.1KGCT-ND) |  | 4 | Panasonic - ECG (http://digikey.com/Suppliers/us/Panasonic-Industrial-Products.page?lang=EN) | ERJ-3GEYJ512V | Resistor | 5K1 | SM0603
P10KGCT-ND (http://search.digikey.com/scripts/DkSearch/dksus.dll?Detail&name=P10KGCT-ND) |  | 5 | Panasonic - ECG (http://digikey.com/Suppliers/us/Panasonic-Industrial-Products.page?lang=EN) | ERJ-3GEYJ103V | Resistor | 10K | SM0603
DS1338Z-33+-ND (http://search.digikey.com/scripts/DkSearch/dksus.dll?Detail&name=DS1338Z-33%2B-ND) |  | 1 | Maxim Integrated Products (http://digikey.com/Suppliers/us/Maxim.page?lang=EN) | DS1338Z-33+ | RTC | DS1338-33 | 8-SOIC 3.90mm
300-8340-1-ND (http://www.digikey.com/product-detail/en/CMR200T-32.768KDZF-UT/300-8340-1-ND/862984) | 1 | 1 | Citizen Finetech Miyota (http://digikey.com/Suppliers/us/Citizen.page?lang=EN) | CMR200T-32.768KDZF-UT | Xtal | 32.768KHz 12.5pf | CMR200T
BAT-HLD-001-ND (http://search.digikey.com/scripts/DkSearch/dksus.dll?Detail&name=BAT-HLD-001-ND) |  | 1 | Linx Technologies Inc (http://digikey.com/Suppliers/nz/Linx-Technologies.page?lang=EN) | BAT-HLD-001 | Battery Holder | frame-only type | 20MM COIN CR2032
609-3956-1-ND (http://search.digikey.com/scripts/DkSearch/dksus.dll?Detail&name=609-3956-1-ND) |  | 1 | FCI (http://digikey.com/Suppliers/nz/FCI.page?lang=EN) | 10067847-001RLF | SD Card Socket |  | SMD see datasheet
P189-ND (http://search.digikey.com/scripts/DkSearch/dksus.dll?Detail&name=P189-ND) |  | 1 | Panasonic - BSG (http://digikey.com/Suppliers/nz/Panasonic-Industrial-Products.page?lang=EN) | CR2032 | Lithium Battery | 3V 20mm
TThese part numbers are for sdcard.brd only |  |  | The reason for the two designs is we couldn't find a UK source for the parts highlighted here.
Other parts are common to both designs. |  |  | The NZ version was also later updated to use a cheaper, barrel type crystal.
\ |  |  | The two designs share identical schematic. It's only the PCB layout that differs.
Xtalk also available from element14 ...
nz.element14 Part No. |  |  | Manufacturer Name | Mfr Part No.
1078958 (http://nz.element14.com/citizen-america/cmr200t32-768kdzf-ut/crystal-32-768khz-12-5pf-smd/dp/1078958) | 1 | 1 | Citizen America | CMR200T32.768KDZF-UT

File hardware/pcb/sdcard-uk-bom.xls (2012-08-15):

SD Card Board | 2012-08-15
v4.2 UK / Farnel version
Farnell Part No. | MOQ | Qty | Manufacturer Name | Mfr Part No. | Description | Value | Footprint
1740612 (http://uk.farnell.com/avx/0603yc104jat2a/capacitor-mlcc-0603-16v-100nf/dp/1740612) | 10 | 2 | AVX | 0603YC104JAT2A | Capacitor | 0.1uF 16v | SM0603
1469740 (http://uk.farnell.com/vishay-draloric/crcw06031k00fkea/resistor-0603-1kr-1-0-1w/dp/1469740) | 50 | 1 | VISHAY DRALORIC | CRCW06031K00FKEA | Resistor | 1K | SM0603
1469819 (http://uk.farnell.com/vishay-draloric/crcw06035k10fkea/resistor-0603-5-1kr-1/dp/1469819) | 50 | 4 | VISHAY DRALORIC | CRCW06035K10FKEA | Resistor | 5K1 | SM0603
1469749 (http://uk.farnell.com/vishay-draloric/crcw060310k0jnea/resistor-10kr-0-1w-5/dp/1469749) | 50 | 5 | VISHAY DRALORIC | CRCW060310K0JNEA | Resistor | 10K | SM0603
1379714 (http://uk.farnell.com/maxim-integrated-products/ds1338z-33/rtc-56b-nvram-i2c-1338-soic8/dp/1379714) | 1 | 1 | Maxim | DS1338Z-33+ | RTC | DS1338-33 | 8-SOIC 3.90mm
1278036 (http://uk.farnell.com/epson-toyocom/fc-135-32-768khz-20ppm-12-5pf/crystal-sm-watch/dp/1278036) | 1 | 1 | Epson Toyocom | FC-135 32.768KHZ | Xtal | 32.768KHz 12.5pf | SMD-2
1650693 (http://uk.farnell.com/jsp/search/productdetail.jsp?sku=1650693) | 1 | 1 | Keystone | 3002 | Battery Holder | Metal frame-only type | 20MM COIN CR2032
9186174 (http://uk.farnell.com/jsp/search/productdetail.jsp?sku=9186174) | 1 | 1 | Mutlicomp | SDBMF-00915B0T2 | SD Card Socket |  | SMD see datasheet
1823479 (http://uk.farnell.com/renata/cr-2032-mfr-1bl/cell-lithium-button-3v/dp/1823479) | 1 | 1 | Renata | CR 2032 MFR (1BL) | Lithium Battery | 3V 20mm
These part numbers are for sdcard_uk.brd only |  |  | The reason for the two designs is we couldn't find a UK source for the parts highlighted here.
Other parts are common to both designs. |  |  | The NZ version was also later updated to use a cheaper barrel type crystal.
 |  |  | The two designs share identical schematic. It's only the PCB layout that differs.

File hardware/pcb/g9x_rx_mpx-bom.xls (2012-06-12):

RX MPX Baord | V1.0
 |  |  | Digi-Key |  |  |  |  | Farnell UK
Digi-Key Part No. | MOQ | Qty | Manufacturer Name | Mfr Part No. | Farnell Part No. | MOQ | Qty | Manufacturer Name | Mfr Part No. | Description | Value | Footprint
445-5122-1-ND (http://search.digikey.com/scripts/DkSearch/dksus.dll?Detail&name=445-5122-1-ND) | 1 | 6 | TDK Corporation (http://digikey.com/Suppliers/us/TDK.page?lang=EN) | C1608X7R1C104M | 1740612 (http://uk.farnell.com/avx/0603yc104jat2a/capacitor-mlcc-0603-16v-100nf/dp/1740612) | 10 | 6 | AVX | 0603YC104JAT2A | Capacitor ceramic | 0.1uF 16V | SM0603
445-5156-1-ND (http://search.digikey.com/scripts/DkSearch/dksus.dll?Detail&name=445-5156-1-ND) | 1 | 1 | TDK Corporation (http://digikey.com/Suppliers/us/TDK.page?lang=EN) | C1608X5R1C105M | 1828801 (http://uk.farnell.com/murata/grm188r61c105ka93d/capacitor-0603-x5r-16v-1uf/dp/1828801) | 10 | 1 | MURATA | GRM188R61C105KA93D | Capacitor ceramic | 1uF 16V | SM0603
587-2253-1-ND (http://search.digikey.com/scripts/DkSearch/dksus.dll?Detail&name=587-2253-1-ND) | 1 | 1 | Taiyo Yuden (http://digikey.com/Suppliers/us/Taiyo-Yuden.page?lang=EN) | EMK316BJ106ML-T | 1463365 (http://uk.farnell.com/kemet/c1206c106k4pac-tu/capacitor-1206-10uf-16v-x5r/dp/1463365) | 1 | 1 | KEMET | C1206C106K4PAC-TU | Capacitor ceramic | 10uF 16V | SM1206
587-1348-1-ND (http://search.digikey.com/scripts/DkSearch/dksus.dll?Detail&name=587-1348-1-ND) | 1 | 1 | Taiyo Yuden (http://digikey.com/Suppliers/us/Taiyo-Yuden.page?lang=EN) | JMK316BJ476ML-T | 1658960 (http://uk.farnell.com/avx/tpsa476k006r0800/capacitor-case-a-47-uf-6-3v/dp/1658960) | 1 | 1 | AVX | TPSA476K006R0800 | Capacitor tant | 47uF 6.3V | SM1206
P200GCT-ND (http://search.digikey.com/scripts/DkSearch/dksus.dll?Detail&name=P200GCT-ND) | 1 | 9 | Panasonic - ECG (http://digikey.com/Suppliers/us/Panasonic-Industrial-Products.page?lang=EN) | ERJ-3GEYJ221V | 1469777 (http://uk.farnell.com/vishay-draloric/crcw0603200rfkea/resistor-0603-200r-1/dp/1469777) | 50 | 9 | VISHAY DRALORIC | CRCW0603200RFKEA | Resistor | 200R | SM0603
P1.0KGCT-ND (http://search.digikey.com/scripts/DkSearch/dksus.dll?Detail&name=P1.0KGCT-ND) | 1 | 1 | Panasonic - ECG (http://digikey.com/Suppliers/us/Panasonic-Industrial-Products.page?lang=EN) | ERJ-3GEYJ103V | 1469740 (http://uk.farnell.com/vishay-draloric/crcw06031k00fkea/resistor-0603-1kr-1-0-1w/dp/1469740) | 50 | 1 | VISHAY DRALORIC | CRCW06031K00FKEA | Resistor | 1K | SM0603
P5.1KGCT-ND (http://search.digikey.com/scripts/DkSearch/dksus.dll?Detail&name=P5.1KGCT-ND) | 1 | 1 | Panasonic - ECG (http://digikey.com/Suppliers/us/Panasonic-Industrial-Products.page?lang=EN) | ERJ-3GEYJ512V | 1469819 (http://uk.farnell.com/vishay-draloric/crcw06035k10fkea/resistor-0603-5-1kr-1/dp/1469819) | 50 | 1 | VISHAY DRALORIC | CRCW06035K10FKEA | Resistor | 5K1 | SM0603
P10KGCT-ND (http://search.digikey.com/scripts/DkSearch/dksus.dll?Detail&name=P10KGCT-ND) | 1 | 1 | Panasonic - ECG (http://digikey.com/Suppliers/us/Panasonic-Industrial-Products.page?lang=EN) | ERJ-3GEYJ103V | 1469748 (http://uk.farnell.com/vishay-draloric/crcw060310k0fkea/resistor-0603-10kr-1-0-1w/dp/1469748) | 50 | 1 | VISHAY DRALORIC | CRCW060310K0FKEA | Resistor | 10K | SM0603
751-1129-ND (http://www.digikey.com/product-detail/en/TLHR4405/751-1129-ND/1681264) | 1 | 1 | Vishay Semiconductors (http://digikey.com/Suppliers/us/Vishay-Semiconductors.page?lang=EN) | TLHR4405 | 2001642 (http://uk.farnell.com/kingbright/l-1334srt/reflector-led-3mm-hyper-red/dp/2001642) | 5 | 1 | KINGBRIGHT | L-1334SRT | LED | Red 3mm | 100mil 2pin
MF-MSMF250/16-2CT-ND (http://www.digikey.com/product-detail/en/MF-MSMF250%2F16-2/MF-MSMF250%2F16-2CT-ND/662851) |  | 2 | Bourns Inc. (http://digikey.com/Suppliers/us/Bourns.page?lang=EN) | MF-MSMF250/16-2 | 1652174 (http://uk.farnell.com/bourns/mf-msmf250-16-2/multifuse-smd-1812-2-5a-16v/dp/1652174) | 5 | 2 | Bournes | MF-MSMF250/16-2 | Fuse | 2.5A 16v | 1812 BIGGER THAN PCB :( @ 1206
ATMEGA328-AU-ND (http://www.digikey.com/product-detail/en/ATMEGA328-AU/ATMEGA328-AU-ND/2271029) | 1 | 1 | Atmel (http://digikey.com/Suppliers/us/Atmel.page?lang=EN) | ATMEGA328-AU | 1972086 (http://uk.farnell.com/atmel/atmega328-au/mcu-8bit-avr-32k-flash-32tqfp/dp/1972086) | 1 | 1 | Atmel | ATMEGA328-AU | IC (MCU) | ATMega328 | TQFP 32 0.8mm
A32705-40-ND (http://www.digikey.com/product-detail/en/9-103323-0/A32705-40-ND/1044432) | 1 | 1 | AMPMODU Mod II (http://www.digikey.com/product-search/en?FV=ffec0eea) | 9-103323-0 | 1098476 (http://uk.farnell.com/te-connectivity-amp/4-103323-1/header-right-angle-1row-40way/dp/1098476?Ntt=4-103323-1) | 1 x 40pin | 1 | TE CONNECTIVITY / AMP | 4-103323-1 | Pin Header | Single row 90 degree | 2.54mm male pins
A34279-40-ND (http://www.digikey.com/product-detail/en/9-103324-0/A34279-40-ND/1126657) | 1 | 1 | AMPMODU Mod II (http://www.digikey.com/product-search/en?FV=ffec0eea) | 9-103324-0 | 1056023 (http://uk.farnell.com/te-connectivity-amp/9-103324-0/header-right-angle-2row-40-40way/dp/1056023) | 1 x 40pin | 1 | TE CONNECTIVITY / AMP | 9-103324-0 | Pin Header | Double row 90 degree | 2.54mm male pins
? | ? | 8 columns | ? | ? | 000539 (http://www.coolcomponents.co.uk/catalog/header-right-angle-rows-pinmale-p-539.html) | 1 x 40pin | 1 | Unknown | Unknown | Pin Header | Triple row 90 degree | 2.54mm male pins
EG4912-ND (http://www.digikey.com/product-detail/en/200USP1T1A1M6RE/EG4912-ND/2498448) | 1 | 2 | E-Switch (http://digikey.com/Suppliers/us/E-Switch.page?lang=EN) | 200USP1T1A1M6RE | 9473017 (http://uk.farnell.com/multicomp/2ms1t2b2m6re/switch-pcb-spdt-horiz/dp/9473017?Ntt=9473017) | 1 | 2 | Multicomp | 2MS1T2B2M6RE | Switch | SPDT 90 degree toggle
CT1952MST-ND (http://www.digikey.com/product-detail/en/195-2MST/CT1952MST-ND/92985) | 1 | 1 | CTS Electrocomponents (http://digikey.com/Suppliers/us/CTS-Corporation-Electrocomponents.page?lang=EN) | 195-2MST | 1255233 (http://uk.farnell.com/multicomp/mcdp02/switch-dil-2way/dp/1255233) | 1 | 1 | Multicomp | MCDP02 | Dip Switch | 2 way | 300mil 4pin DIL
NJM78L05UA-ND (http://search.digikey.com/us/en/products/NJM78L05UA/NJM78L05UA-ND/805773) | 1 | 1 | NJR (http://digikey.com/Suppliers/us/NJR-JRC.page?lang=EN) | NJM78L05UA | 3605772 (http://uk.farnell.com/torex/xc6202p502pr/v-reg-ldo-5-0v-smd-6202-sot893/dp/3605772) | 1 | 1 | TOREX | XC6202P502PR | 5 Volt Regulator | OUT / GND / IN | SOT-89
A100207-ND (http://www.digikey.com/product-detail/en/1-390261-5/A100207-ND/1152553) | 1 | 1 | TE Connectivity (http://digikey.com/Suppliers/us/Tyco-Electronics-Amp.page?lang=EN) | 1-390261-5 | 1101348 (http://uk.farnell.com/te-connectivity-amp/1-390261-5/socket-ic-dil-0-3-18way/dp/1101348) | 5 | 1 | TE CONNECTIVITY / AMP | 1-390261-5 | IC Socket | 18pin | 300mil 18pin DIL
ULN2803APG(ONHZN-ND (http://www.digikey.com/product-detail/en/ULN2803APG%28O,N,HZN/ULN2803APG%28ONHZN-ND/856431) | 1 | 1 | Toshiba (http://digikey.com/Suppliers/us/Toshiba-America-Electronic-Components.page?lang=EN) | ULN2803APG(O,N,HZN | 1652422 (http://uk.farnell.com/texas-instruments/uln2803an/darlington-transistor-array/dp/1652422) | 1 | 1 | TEXAS INSTRUMENTS | ULN2803AN | Octal transistor array | ULN2803 | 300mil 18pin DIL
296-25940-1-ND (http://www.digikey.com/product-detail/en/CD4017BM96/296-25940-1-ND/2254803) | 1 | 1 | Texas Instruments (http://digikey.com/Suppliers/us/Texas-Instruments.page?lang=EN) | CD4017BM96 | 1741256 (http://uk.farnell.com/texas-instruments/cd4017bm/logic-10-out-decade-counter-16soic/dp/1741256) | 1 | 1 | TEXAS INSTRUMENTS | CD4017BM | Decade Counter | 4017 | 16SOIC

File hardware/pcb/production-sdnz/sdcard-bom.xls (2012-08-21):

RTC/SD-card Board v4.2 Bill of Materials
Date | 2011-08-15
Author | Gruvin
Designator | Package | Qty | Designation | Supplier | Supplier Ref | Manufacturer | Manu. Part No. | Description | Value
BT1 | BAT_HLD_2032 | 1 | CR2032 | Digikey | BAT-HLD-001-ND (http://search.digikey.com/scripts/DkSearch/dksus.dll?Detail&name=BAT-HLD-001-ND) | Linx Technologies Inc (http://digikey.com/Suppliers/nz/Linx-Technologies.page?lang=EN) | BAT-HLD-001 | Battery Holder
C1,C2 | SM0603 | 2 | 0u1 | Digikey | 445-5122-1-ND (http://search.digikey.com/scripts/DkSearch/dksus.dll?Detail&name=445-5122-1-ND) | TDK Corporation (http://digikey.com/Suppliers/us/TDK.page?lang=EN) | C1608X7R1C104M | Capacitor | 0.1uF 16v
P1 | SDCARD_SKT | 1 | SDC_MMC_SOCKET | Digikey | 609-3956-1-ND (http://search.digikey.com/scripts/DkSearch/dksus.dll?Detail&name=609-3956-1-ND) | FCI (http://digikey.com/Suppliers/nz/FCI.page?lang=EN) | 10067847-001RLF | SD Card Socket
P2 | CONN_2MM_8x1 | 0 | CONN_8 | N/A | N/A | N/A | N/A | Not installed
R4,R3,R2,R1,R5 | SM0603 | 5 | 10K | Digikey | P10KGCT-ND (http://search.digikey.com/scripts/DkSearch/dksus.dll?Detail&name=P10KGCT-ND) | Panasonic - ECG (http://digikey.com/Suppliers/us/Panasonic-Industrial-Products.page?lang=EN) | ERJ-3GEYJ103V | Resistor | 10K
R8 | SM0603 | 1 | 1K | Digikey | P1.0KGCT-ND (http://search.digikey.com/scripts/DkSearch/dksus.dll?Detail&name=P1.0KGCT-ND) | Panasonic - ECG (http://digikey.com/Suppliers/us/Panasonic-Industrial-Products.page?lang=EN) | ERJ-3GEYJ103V | Resistor | 1K
R9,R7,R6,R10 | SM0603 | 4 | 5K1 | Digikey | P5.1KGCT-ND (http://search.digikey.com/scripts/DkSearch/dksus.dll?Detail&name=P5.1KGCT-ND) | Panasonic - ECG (http://digikey.com/Suppliers/us/Panasonic-Industrial-Products.page?lang=EN) | ERJ-3GEYJ512V | Resistor | 5K1
U1 | SO8E | 1 | DS1338-33 | Digikey | DS1338Z-33+-ND (http://search.digikey.com/scripts/DkSearch/dksus.dll?Detail&name=DS1338Z-33%2B-ND) | Maxim Integrated Products (http://digikey.com/Suppliers/us/Maxim.page?lang=EN) | DS1338Z-33+ | RTC
X1 | CMR200T | 1 | 32768 | Digikey | 300-8340-1-ND (http://www.digikey.com/product-detail/en/CMR200T-32.768KDZF-UT/300-8340-1-ND/862984) | Citizen Finetech Miyota (http://digikey.com/Suppliers/us/Citizen.page?lang=EN) | CMR200T-32.768KDZF-UT | Xtal | 32.768KHz 12.5pf
Loose parts to supply for client assembly / installation
Designator | Package | Qty | Designation | Supplier | Supplier Ref | Manufacturer | Manu. Part No. | Description | Value
Battery |  |  |  | Digikey | P189-ND (http://search.digikey.com/scripts/DkSearch/dksus.dll?Detail&name=P189-ND) | Panasonic - BSG (http://digikey.com/Suppliers/nz/Panasonic-Industrial-Products.page?lang=EN) | CR2032 | Lithium Battery | 3V 20mm

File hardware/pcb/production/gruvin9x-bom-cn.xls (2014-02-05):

 | gruvin9x v4.2d Bill of Materials
 | Designator | Designation | Quantity | Package | Comments | DigiKey Part
 | C1,C11 | 10u 16V | 2 | SM1206_POL | Polarised if tantalum. Ceramic is also OK. | 587-2253-1-ND (http://search.digikey.com/scripts/DkSearch/dksus.dll?Detail&name=587-2253-1-ND)
 | C12,C35,C18,C31 | 47u 6.3V | 4 | SM1206_POL | Polarised. Prefer tantalum. | 587-1348-1-ND (http://search.digikey.com/scripts/DkSearch/dksus.dll?Detail&name=587-1348-1-ND)
 | C13,C14 | 18p | 2 | SM0603 |  | 445-1272-1-ND (http://search.digikey.com/scripts/DkSearch/dksus.dll?Detail&name=445-1272-1-ND)
 | C2,C3,C4,C5,C6,C7,C8,C9,C10,C15,C17,C19,C20,C21,C22,C23,C24,C25,C26,C27,C28,C29,C96,C95,C94,C93,C92,C91,C30,C33,C34,C36,C59,C58,C57,C56,C55,C54,C53,C43,C42,C41,C40,C39,C38,C37,C60,C61,C63,C64,C65 | 0u1 | 51 | SM0603 |  | 445-5122-1-ND (http://search.digikey.com/scripts/DkSearch/dksus.dll?Detail&name=445-5122-1-ND)
 | C32 | 22u 16V | 1 | SM1210_POL | Polarised if tantalum. Ceramic also OK. | 478-1682-1-ND (http://search.digikey.com/scripts/DkSearch/dksus.dll?Detail&name=478-1682-1-ND)
 | C44,C45,C46,C47,C48,C49,C50,C51,C52,C16,C62 | 1u 16V | 11 | SM0603 |  | 445-5156-1-ND (http://search.digikey.com/scripts/DkSearch/dksus.dll?Detail&name=445-5156-1-ND)
 | D1 | DIODESIL | 1 | SM0603_DIODE |  | 641-1002-1-ND (http://search.digikey.com/scripts/DkSearch/dksus.dll?Detail&name=641-1002-1-ND)
 | D16,D17,D5 | DIODESCH | 3 | SM0603_DIODE |  | 641-1006-1-ND (http://search.digikey.com/scripts/DkSearch/dksus.dll?Detail&name=641-1006-1-ND)
 | D2 | 5V1 | 1 | SOD523 |  | EDZTE615.1BCT-ND (http://search.digikey.com/scripts/DkSearch/dksus.dll?Detail&name=EDZTE615.1BCT-ND)
 | D3,D4 | 3V6 | 2 | SOD523 |  | EDZTE613.6BCT-ND (http://search.digikey.com/scripts/DkSearch/dksus.dll?Detail&name=EDZTE613.6BCT-ND)
 | F1 | FUSE | 1 | SM1206 |  | F2110CT-ND (http://search.digikey.com/scripts/DkSearch/dksus.dll?Detail&name=F2110CT-ND)
 | IC1 | ATMEGA2560-A | 1 | TQFP_100 |  | ATMEGA2560-16AU-ND (http://search.digikey.com/scripts/DkSearch/dksus.dll?Detail&name=ATMEGA2560-16AU-ND)
 | J4,J1 | JUMPER_2W | 2 | JUMPER_3PAD |  | P0.0GCT-ND (x2) (http://search.digikey.com/scripts/DkSearch/dksus.dll?Detail&name=P0.0GCT-ND)
 | K1,K2,K5,K6 | JST_2MM_3x1 | 5 | CONN_3 |  | 455-1705-ND (http://search.digikey.com/scripts/DkSearch/dksus.dll?vendor=0&keywords=455-1705-ND)
 | L1,L2 | 10u | 2 | SM0805 |  | 587-2487-6-ND (http://search.digikey.com/scripts/DkSearch/dksus.dll?Detail&name=587-2487-6-ND)
 | P1 | CONN_3X2 | 0.1 | PIN_ARRAY_3X2 | 2.54mm pitch, unshrouded SPLIT FROM 30-POS | SAM1113-15-ND (http://www.digikey.com/product-detail/en/TD-115-G-A/SAM1113-15-ND/1105511)
 | P2,K4 | JST_2MM_5x1 | 2 | CONN_5 |  | 455-1707-ND (http://search.digikey.com/scripts/DkSearch/dksus.dll?Detail&itemSeq=94318860&uq=634281172891716883)
 | P5,P4 | JST_2MM_9x1 | 2 | CONN_9 |  | 455-1711-ND (http://search.digikey.com/scripts/DkSearch/dksus.dll?Detail&name=455-1711-ND)
 | P6,P3 | JST_2MM_6x1 | 2 | CONN_6 |  | 455-1708-ND (http://search.digikey.com/scripts/DkSearch/dksus.dll?Detail&name=455-1708-ND)
 | P7 | JST_2MM_12x1 | 1 | CONN_12 |  | 455-1714-ND (http://search.digikey.com/scripts/DkSearch/dksus.dll?Detail&name=455-1714-ND)
 | P8 | CONN_30_LCD | 1 | CONN30_SMD |  | WM7976CT-ND (http://search.digikey.com/scripts/DkSearch/dksus.dll?detail&name=WM7976CT-ND)
 | P13 | JST_2MM_8x1 | 1 | CONN_8 |  | 455-1710-ND (http://search.digikey.com/scripts/DkSearch/dksus.dll?Detail&name=455-1710-ND)
 | P14,P18 | JST_2MM_2x1 | 2 | CONN_2 |  | 455-1704-ND (http://search.digikey.com/scripts/DkSearch/dksus.dll?vendor=0&keywords=455-1704-ND)
 | P15,P12 | JST_2MM_4x1 | 2 | CONN_4 |  | 455-1706-ND (http://search.digikey.com/scripts/DkSearch/dksus.dll?Detail&itemSeq=101953209&uq=634451471635632513)
 | Q2,Q1,Q4,Q7,Q5,Q8,Q9 | BC847C | 7 | SOT23-BCE |  | 568-1636-1-ND (http://search.digikey.com/scripts/DkSearch/dksus.dll?Detail&name=568-1636-1-ND)
 | Q3 | BC857C | 1 | SOT23-BCE |  | BC857C-FDICT-ND (http://search.digikey.com/scripts/DkSearch/dksus.dll?Detail&name=BC857C-FDICT-ND)
 | Q6,Q10 | Si2319DS | 2 | SOT23GDS |  | SI2319DS-T1-E3CT-ND (http://search.digikey.com/scripts/DkSearch/dksus.dll?Detail&name=SI2319DS-T1-E3CT-ND)
 | R1,R42,R43,R44,R45,R50,R51,R52,R53,R58,R59,R60,R61,R62,R69,R74,R72,R81,R28,R27,R23,R16,R17,R33,R77,R101,R107,R108,R109,R110,R32,R111,R112,R114 | 5K1 | 34 | SM0603 |  | P5.1KGCT-ND (http://search.digikey.com/scripts/DkSearch/dksus.dll?Detail&name=P5.1KGCT-ND)
 | R104,R105 | 68R | 2 | SM0603 |  | P68GCT-ND (http://search.digikey.com/scripts/DkSearch/dksus.dll?Detail&name=P68GCT-ND)
 | R106 | 1K5 | 1 | SM0603 |  | P1.5KGCT-ND (http://search.digikey.com/scripts/DkSearch/dksus.dll?Detail&name=P1.5KGCT-ND)
 | R2 | 2K7 | 1 | SM0603 |  | P2.7KGCT-ND (http://search.digikey.com/scripts/DkSearch/dksus.dll?Detail&name=P2.7KGCT-ND)
 | R25,R35,R46,R47,R48,R49,R54,R55,R56,R57,R63,R64,R65,R66,R67,R118 | 10K | 16 | SM0603 |  | P10KGCT-ND (http://search.digikey.com/scripts/DkSearch/dksus.dll?Detail&name=P10KGCT-ND)
 | R3,R4,R5,R6,R8,R9,R10,R11,R12,R18,R19,R20,R26,R68,R71,R70,R83,R84,R91,R96,R95,R94,R93,R92,R100,R99,R98,R97,R90,R89,R88,R87,R86,R78,R22,R21,R14,R13,R102,R24 | 200R | 40 | SM0603 |  | P200GCT-ND (http://search.digikey.com/scripts/DkSearch/dksus.dll?Detail&name=P200GCT-ND)
 | R30,R29 | 100R | 2 | SM0603 |  | P100GCT-ND (http://search.digikey.com/scripts/DkSearch/dksus.dll?Detail&name=P100GCT-ND)
 | R31,R34,R79 | 10K2 | 3 | SM0603 |  | P10.2KHCT-ND (http://search.digikey.com/scripts/DkSearch/dksus.dll?Detail&name=P10.2KHCT-ND)
 | R36,R15,R85,R113,R115 | 100K | 5 | SM0603 |  | P100KGCT-ND (http://search.digikey.com/scripts/DkSearch/dksus.dll?Detail&name=P100KGCT-ND)
 | R37,R80 | 150K | 2 | SM0603 |  | P150KGCT-ND (http://search.digikey.com/scripts/DkSearch/dksus.dll?Detail&name=P150KGCT-ND)
 | R39,R40 | 0R | 2 | SM0603 |  | P0.0GCT-ND (http://search.digikey.com/scripts/DkSearch/dksus.dll?Detail&name=P0.0GCT-ND)
 | R7 | 180K | 1 | SM0603 |  | P180KGCT-ND (http://search.digikey.com/scripts/DkSearch/dksus.dll?Detail&name=P180KGCT-ND)
 | R73,R75,R82,R103,R117 | 1K | 5 | SM0603 |  | P1.0KGCT-ND (http://search.digikey.com/scripts/DkSearch/dksus.dll?Detail&name=P1.0KGCT-ND)
 | R76 | 3K9 | 1 | SM0603 |  | P3.9KGCT-ND (http://search.digikey.com/fi/en/products/ERJ-3GEYJ392V/P3.9KGCT-ND/135159)
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

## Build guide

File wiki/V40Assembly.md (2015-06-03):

## Previous v4.0 Assembly Information ##

With more people beginning to show an interest in assembling (soldering) their own gruvin9x printed circuit boards, I thought we'd start a wiki page on the topic.

Eventually, this page should contain detailed instructions of where to buy the parts, get the blank PCB board made or purchased ready-made and other relevant information. For now though, ...

Cam (in the UK) has graciously made some videos of his soldering techniques, using a standard iron, which I will here and now formally endorse as the official, 'gruvin9x way'. :-P

Since a picture tells a thousand words and a video streams pictures at 15+ frames per second, here are the links to Cam's two videos ...

[Soldering SMD 0603 sized parts](http://www.youtube.com/watch?v=nMZq0CZ67WY)

[Soldering the TQFP 0.5mm pitch, 100-pin ATmega2560 chip](http://www.youtube.com/watch?v=r69WvRybgCU)

Thanks Cam!

---

There's silk-screen PDFs for the main board and the (gruvin version) sdcard board in `/trunk/pcbv4.0-frozen/assembly` to help with puting the right parts in the right place.

  * [gruvin9x-SilkS\_Front.pdf](http://gruvin9x.googlecode.com/svn/archive/pcb-v4.0-frozen/assembly/gruvin9x-SilkS_Front.pdf)

  * [sdcard-SilkS\_Front.pdf](http://gruvin9x.googlecode.com/svn/archive/pcb-v4.0-frozen/assembly/sdcard-SilkS_Front.pdf)

# Patching PCB v4.0 #

For those who have jumped ahead and got themselves one of the few v4.0 boards we had available, here's the patch work needed (as at 2011-09-21) to make your board v4.1 design compatible -- and in fact required to work with the latest (/trunk) code.

**NOTE** that the BC847 transistor in place of D2 is mounted **UPSIDE-DOWN**

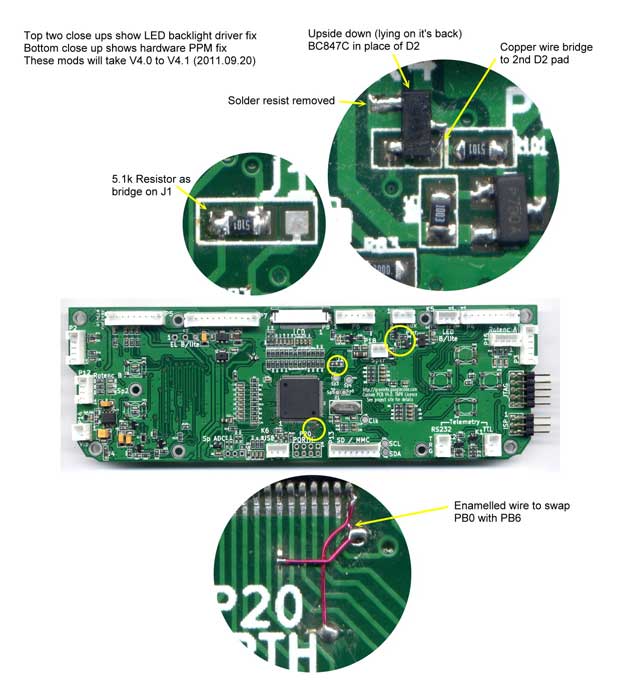
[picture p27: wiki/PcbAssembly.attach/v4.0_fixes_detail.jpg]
<br />
-- Image provided by th9xer. Thanks Cam.

There's another patch required for PPM\_IN (trainer port input). I'm working on a better photo. But for now, this is the best focus I can manage, sorry ...

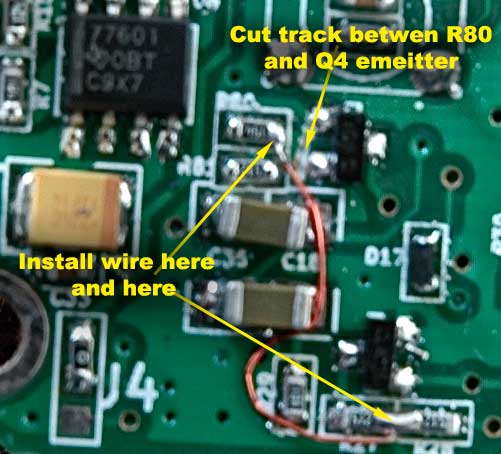
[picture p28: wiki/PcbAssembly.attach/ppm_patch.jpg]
<br />

## Second Version IDL2 / SD\_CS Patch Required ##

Here's a photo showing the latest (revised) IDL2 mod, (See [issue 48](https://code.google.com/p/gruvin9x/issues/detail?id=48).)

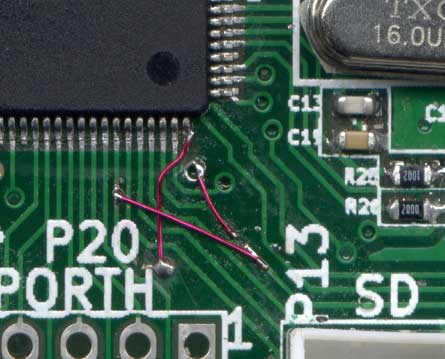
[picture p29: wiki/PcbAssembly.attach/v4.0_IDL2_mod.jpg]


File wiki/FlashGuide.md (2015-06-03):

# This project has been superseded by [opentx](http://opentx.googlecode.com/) #

The following data is likely obsolete, kept here for mostly just for historical record.

# Getting Wired #

**UPDATE** 2011-11-24: Current versions of AVRDUDE do not seem to work well with the Sparkfun USB Pocket Programmer. I have switched to a USBasp based USB programmer and it is now working flawlessly. Original article (to be updated) continues ...

The first thing you will need is one of the many available AVR programmer kits. Perhaps you already have an AVR programmer? I purchased a <a href='http://www.sparkfun.com/commerce/product_info.php?products_id=9825'>USB Pocket Programmer</a> from Spark Fun. It works really well and is not at all expensive. (<a href='http://sparkfun.com'>SparkFun</a> have a some really cool stuff by the way. Stop by for a while and check them out!)<br>
<br>
You'll need to connect your programmer's ICP (In-Circuit Programming) cable to your '9X. There are a few options available.<br>
<br>
An excellent "solder-less" example, using <a href='http://www.sparkfun.com/commerce/product_info.php?products_id=8870'>pogo pins</a>, can be found in the offering from <a href='http://SmartieParts.com'>SmartieParts.com</a> (Steven / s_mack on <a href='http://www.rcgroups.com/forums/'>RCGroups forum</a>). With this option, all you need is a screw-driver! The board includes a USB programming interface and an EL back-light driver for your LCD screen. I believe it even comes with an EL back-light sheet. See <a href='http://www.rcgroups.com/forums/showthread.php?t=1338412#post16549680'>here</a> for detailed information with images, in the form of a mini-review, by Erazz (of ER9X).<br>
<br>
Here, I will discuss the, "soldering wires straight to PCB" method.<br>
<br>
There is an excellent PDF guide for Windows users <a href='http://gruvin9x.googlecode.com/svn/trunk/doc/Flashing%20the%209x.pdf'>http://gruvin9x.googlecode.com/svn/trunk/doc/Flashing%20the%209x.pdf</a>, which also shows how to connect an AVR programmer ribbon cable to the '9X. That guide though seems to rely on a colour coded cable to determine what wire goes where. So I've included a photo below of my 'classic all-grey' ribbon cable installation, with numbered wires, for your convenience.<br>
<br>
When I ordered my SparkFun Pocket Programmer, I had them add a spare programming cable. I cut the two 'remote' connectors off the end of that and used what remained to wire up my radio. Here's a photo of my installation, using a stock SparkFun cable as described ...<br>
<br>
<blockquote><b>IMPORTANT:</b> The picture below shows a typical ‘V2′ transmitter, as has been shipping for a few months as at time of this writing. The V1 unit  had an error on the PCB where the ‘SCK’ programming pad (wire 7 below) was connected one pin too far left on the ATmega64 chip. So watch out for that! If you have a V1 unit, you can still get things going. You just have to careful to get a wire soldered to the right place.</blockquote>

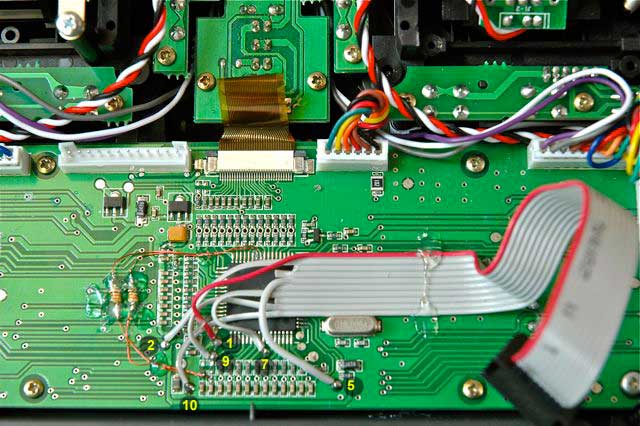
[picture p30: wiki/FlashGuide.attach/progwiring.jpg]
<blockquote></blockquote>

<ul><li><b>NOTE:</b> The two little hot-glued resistors to the left, with their respective fine wires comprise the re-wiring necessary to free up the ATmega serial comms port (RXD/TXD) for telemetry data. Those pins are otherwise connected to the Throttle-Hold and Aileron-DR switches. For telemetry support, the switches get moved to two spare pins (PC6/7). <b>This mod is only necessary if</b> you intend using a Fr-Sky enabled <a href='TrunkBinaries.md'>binary</a> image -- or specifying the EXT=JETI or EXT=FRSKY <code>make</code> attributes, when building from source. <b>See <a href='FrskyInterfacing.md'>here</a> details of what to connect where and how</b>.</li></ul>

<h2>Programmers with 6-pin ISP Connectors</h2>

If you have a more modern AVR programmer with a 6-pin ISP connector, you can find more appropriate wiring information on the <a href='GProg.md'>gProg wiki page</a>.<br>
<br>
<h1>Flashing the Firmware</h1>

<h2>Software</h2>
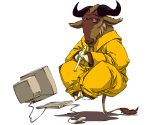
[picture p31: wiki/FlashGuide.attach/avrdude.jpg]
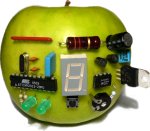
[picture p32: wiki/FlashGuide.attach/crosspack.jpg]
Whilst I'm no stranger to Windows, I strongly prefer using my Mac for all development work. Fortunately, so do many others who work with Atmel AVR chips, so there’s a nice packaged installer named <a href='http://www.obdev.at/products/crosspack/'>CrossPack</a> that has everything you need for cross-compiling C/C++ AVR code on your Mac.<br>
<br>
CrossPack also comes bundled with <a href='http://savannah.nongnu.org/projects/avrdude/'>AVRDUDE</a>, which is used to operate the programmer hardware. Even more conveniently, the 'usbtiny' programmer protocol driver that the SparkFun USB Pocket Programmer I randomly chose is also included and installed, ready-to-run as part of the CrossPack bundle. Very cool! Best of all, you don't have to do any configuring of this software. Just install it and then move on to the steps below.<br>
<br>
And yes, the above software is all free! Aint it great? Be sure to say thanks or drop a donation!<br>
<br>
<h2>Ready-to-Run "binary" firmware</h2>

There are (at the time of this writing) four pre-compiled hex file versions of gruvin9x available and kept up to date. The versions apply to the various different hardware mods/re-wiring you may or may not have chosen to do. You can download the version that is right for you from the <a href='TrunkBinaries.md'>TrunkBinaries</a> page, using same to flash your '9X without having to compile from source.<br>
<br>
<blockquote>See <a href='TrunkBinaries.md'>here</a> to for the binaries download page.</blockquote>

<h2>Flashing Ready-to-Run Firmware</h2>
You can now burn your <code>gruvin9x[-version].hex</code> file using AVRDUDE as follows ...<br>
<br>
<pre><code>avrdude -c usbtiny -p atmega64 -B 1 -U flash:w:gruin9x[-version].hex<br>
</code></pre>

AVRDUDE should find the USB programmer, whatever port it's connected to. If not, try unplugging the programmer and plugging it back in. (You'll probably need to do this at least once after installing CrossPack. No reboots are required! This is NOT Windows :p )<br>
<br>
The flash procedure will completely erase your ATmega64A chip's Flash program memory, write in the new firmware and then read back the code to verify it all went OK. After using gruvin9x for a while, you can take a backup of your model programming data using the following AVRDUDE command ...<br>
<br>
<pre><code>avrdude -c usbtiny -p atmega64 -B 1 -U eeprom:r:models.bin:r<br>
</code></pre>

... and you can restore that model data after any given re-flash using ...<br>
<br>
<pre><code>avrdude -c usbtiny -p atmega64 -B 1 -U eeprom:w:models.bin<br>
</code></pre>

Oh by the way; unless you happen to have a battery connected to the '9X (requires the 12-way back cover connector be installed) then leave the tiny little switch on the programmer PCB set to “Power Target”. The programmer will then power up the 9X -- albeit in a fashion it isn’t used to (some switches disconnected etc) and it will complain bitterly with lots of beeping. Block your ears and ignore those, because the new gruvin9x firmware flashing process will very soon put silence all the racket!<br>
<br>
<h1>What to Expect</h1>

After re-flashing for the first time, you can expect to feel a little anxious! Do not fret! The feeling is completely normal. :D<br>
<br>
Disconnect and tuck your programming cable away, for now, in such a way that allows you to put the rear cover back on the transmitter. You can tidy things up more once you know its all working.<br>
<br>
<blockquote><i>REMEMBER to reconnect the rear-cabinet cable connector! The first time I flicked the power switch after flashing I got absolutely nothing. Not even a beep or a flicker. “Uhoh!” ... then I realised that things would probably go better with the power and other things actually connected! :-P</i></blockquote>

During boot-up, the new firmware checks a few things. You’ll get one or more “alerts” on screen, like “Throttle not set idle” and a message like "Alert! Alarms disabled" — meaning the beeper is turned off, as it will be by default. Also, all switches have to be in the “off” state — that is, all front switches ‘up’ and top switches ‘back’. Oh and don’t worry — all these power-up warnings can be disabled through settings in the new '9X menus if you don’t want them. (I don't!)<br>
<br>
Once you clear the alerts away (by pressing <a href='EXIT.md'>EXIT</a> for each or satisfying the switch positions), you should see the (also optional) 'gruvin9x' splash screen'. From this point, things just get better and better ...<br>
<br>
The first thing you’ll want to do is set the ‘mode’ to ‘Mode 1′, for your throttle on the right, right? — since no one in their right mind would <i>ever</i> use Mode 2 now, would they? :P OK, maybe just a few folk might -- maybe even you. Mode 2 is in fact the default, and I have no plans to change that, actually.<br>
<br>
Oh! To access that system settings menu, press and hold <a href='LEFT.md'>LEFT</a> (original '+') button.<br>
<br>
On that note, now would be a really good time to give the <a href='http://gruvin9x.googlecode.com/svn/trunk/doc/ER9x%20Users%20Guide.pdf'>ER9X Users Guide</a> a thorough once-over. If you haven't already realised, I think you'll be impressed with how powerful this firmware is. It truly does completely transform an otherwise rather average "Chinese '9X" radio into something a lot of fun to own and use.<br>
<br>
<h1>Compiling from Source</h1>

Please see the <a href='CompilingFromSource.md'>Compiling From Source</a> wiki page for details on this subject, including changes to the original Makefile defaults employed by gruvin9x.

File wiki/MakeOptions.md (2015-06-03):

# This project has been superseded by [opentx](http://opentx.googlecode.com/) #

The following data is likely obsolete, kept here for mostly just for historical record.

# Make Options (gruvin9x) #

**ER9X.C/H FILENAME CHANGE NOTICE** -- As of gruvin9x [revision 179](https://code.google.com/p/gruvin9x/source/detail?r=179), all occurrences or 'er9x' have been changed to 'gruvin9x'. I had planned to leave er9x in place, as I figured it did no harm. But things started getting too confusing when switching between versions. I ended up accidentally editing the wrong file in the wrong directory. So it is done.

## Makefile Defaults ##

By default, simply running 'make' from the `src/` directory will build gruvin9x.hex in the configuration preferred/needed by Gruvin -- this project's owner. As of [revision 186](https://code.google.com/p/gruvin9x/source/detail?r=186), running `make` with no arguments is equivalent to ...

```
make EXT=FRSKY BEEPER=SPEAKER USART1=FREED
```

The Makefile also defaults to the 'usbtiny' AVR programmer type, since that's what Gruvin uses. Oh and, it disables flash verification by default also -- to save time.

## Hardware Modification Related Make Options ##

<ul>
<li>EXT=<br>
<br>
Values: STD, FRSKY (default), JETI<br>
<br>
This is for when you've freed ports E0 (ThrCut) and E1 (AilDR) for telemetry data use by moving those two switch inputs to unused pins PC6 and PC7 respectively.<br>
<br>
</li>
<li>BEEPER=<br>
<br>
Values: BUZZER, SPEAKER (default)<br>
<br>
This is for when the stock "on/off" electronic beeper/buzzer has been replaced with a small speaker. This enables varying frequency tones for keypad beeps, alarms, etc.<br>
<br>
</li>
<li>PPMIN=<br>
<br>
Values: STD, MOD1 (default)<br>
<br>
The MOD1 option is needed if the PPM-in compatibility hardware mod has been made on the '9X in question. See <a href='PpmIn.md'>PPM-in Compatability (hack)</a>

</li>
<li>USART1=<br>
<br>
Values: STD, FREED (default)<br>
<br>
This is for if you have freed USART1's TX/RX pins by moving LH_Trim_Up/Dwn switches to spare ports PC0 and PG2, respectively. Gruvin (but no one else to my knowledge) originally performed this hardware mod to free USART1 for use with USB Flash or SDCARD serial-driven interfaces. However, native SDCARD access via the SPI interface on Port B is planned with a new PCB design -- or at least an ATmega2561 upgrade chip on the stock PCB.<br>
<br>
USART1 may still be used at a later date. However, this mod is not compatible with PCB design rev2.11, which currently uses all of Port E (including the USART1 pins) for a 4x4 scanned key-switch interface.<br>
<br>
</li>
</ul>

## Standard TH/ER9X Make Directives ##

All other standard ER9X make commands remain present. Examples include ...

<blockquote><pre>*make wflash* [[PROGRAMMER=usbtiny]] - programs/flashes the ATmega64A using code data from gruvin9x.hex. (With optional programmer type override in [[brackets]] if your is not a 'usbtiny')<br>
<br>
*make reeprom TARGET=models* - reads the ATmega64A EEPROM (models/settings) data into models.bin<br>
<br>
*make weeprom TARGET=models* - writes models.bin to the ATmega64A EEPROM, restoring models/settings<br>
<br>
etc</pre></blockquote>

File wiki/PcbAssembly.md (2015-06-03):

# Building Your Own G9X PC Board #

## Preliminary Information ##

This page has been thrown together quickly to help you get started. The information is probably not well laid out and also incomplete in places.

## Where to get your PCB ##

The V4.1 PCB is now available for purchase at http://gruvin9x.com.

You are also welcome to use the Gerber files from the project source repository and have your own PCB's made.

## Where to get the parts ##

In short, DigiKey or Farnell (element14.com, outside the UK). If you're in the UK, Farnell is probably the cheaper choice (free shipping for online orders.) Everywhere else will probably have better luck with DigiKey.

For parts details, please see the three BOM (bill of materials) files at [archive/pcb-v4.1a-frozen/assembly](../archive/pcb-v4.1a-frozen/assembly). (If you're using just a web browser, you'll need to use the "View raw file" link, found at the lower right of the page, after clicking a BOM file link, to download the Excel spreadsheet file.)

NOTE: The production version **RTC/SD-card board BOM** is included at the bottom of the main board BOM file.

The BOM files are Excel spreadsheet format. You can also view them in Open Office or using Google Docs.

Another (better) way to get the BOM files would be to do an svn check-out of the `pcb-v4.1a-frozen/assembly` folder, using the command (assuming you have Subversion installed) ...

~~```svn co https://gruvin9x.googlecode.com/svn/archive/pcb-v4.1a-frozen/assembly g9x-assembly```~~
```
GitHub path: archive/pcb-v4.1a-frozen/assembly
```

... which ~~will create~~ would have created a local folder named `g9x-assembly`.

## Construction Advice ##

**YOU _can_ solder 0.5mm pitch SMD parts. It's amazingly easy, once you know how!**

These parts were hand soldered in just minutes using an average soldering iron, with a typical hobbyist size tip, ordinary 0.7mm solder wire, no special flux and finally, some de-soldering braid. There's practically no challenge at all in reality, with similar results being easily repeated, time after time. You just need to know how! ...

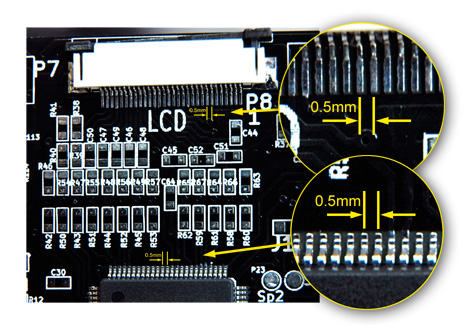
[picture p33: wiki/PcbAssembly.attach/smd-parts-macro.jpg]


(The board was washed with eco-friendly PC board cleaning solution (available from most electronics supply stores) to remove all flux residues. HINT: Don't judge your work until the board has been cleaned!)

**Be sure to watch these two videos, showing how to almost effortlessly solder tiny SMD parts ...**

[Soldering SMD 0603 sized parts](http://www.youtube.com/watch?v=nMZq0CZ67WY)

[Soldering the TQFP 0.5mm pitch, 100-pin ATmega2560 chip](http://www.youtube.com/watch?v=r69WvRybgCU)

There's also a very nicely made [video by Curious Inventor](http://www.youtube.com/watch?v=3NN7UGWYmBY) over at YouTube. The techniques are roughly the same. But some additional options and informational gems are offered.

### Parts Placement Guide ###

Look for PDF files [gruvin9x-SilkS\_Front.pdf](../archive/pcb-v4.1a-frozen/assembly/gruvin9x-SilkS_Front.pdf) and [9xLABEL.pdf](../archive/pcb-v4.1a-frozen/assembly/9xLABEL.pdf) (contributed, colour-coded version) in the [archive/pcb-v4.1a-frozen/assembly](../archive/pcb-v4.1a-frozen%2Fassembly) folder.

Here's a reference photo of Gruvin's 2nd build. (Note that some of the larger capacitors here (22u, 47u) are ceramic, whereas the BOM parts list may call for tantalum. Either will be OK.) **Click the image for full-size view.**

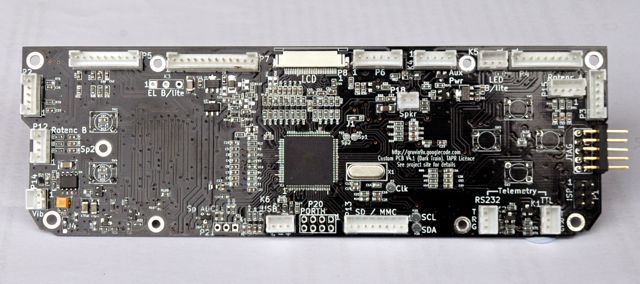
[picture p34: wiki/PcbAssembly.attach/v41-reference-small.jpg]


### LCD Padding Foam ###

No one seems to know where to get the foam used to pad between the PCB and the LCD display. However, the best solution I know of is to simply buy the HobbyKing.com [LCD back-light kits](http://www.hobbyking.com/hobbyking/store/uh_viewItem.asp?idProduct=16720) and use the appropriately thinner foam pad that comes with it. (Also available at HobbyKing in white and green coloured lighting.)

By the way, that is also the LED back-light intended for the upper right connector (K5) on the G9X board, with J1 pads 1&2 bridged, as in the above photo. BE SURE TO USE THE RIGHT-HAND TWO PINS of K5 for the LED back-light. (The left pin is full-current, 5 Volts.)

## AVR Fuse Bits ##

See fuses.txt in the source folder for further details. Briefly, ...

Preferred values for ATmega2560 in this project are:
> lfuse = 0xd7

> hfuse = 0x11

> efuse = 0xfc

There's a nice [online JavaScript AVR fuse calculator](http://www.frank-zhao.com/fusecalc/fusecalc.php?chip=atmega2560&LOW=D7&HIGH=11&EXTENDED=FC&LOCKBIT=FF), which you could use to see details or make any custom changes. (<-- that link loads with the correct fuse bits already pre-selected.)

BE CAREFUL not to select the wrong type of oscillator. You could end up 'bricking' the chip, which requires an external oscillator to be connected to get back to normal operation.

---

v4.2(d) assembly is very similar to the above.

Archived v4.0 PCB assembly notes can be found [here](V40Assembly.md).

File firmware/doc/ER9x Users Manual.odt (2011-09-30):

ER9x Manual

because you asked for it!

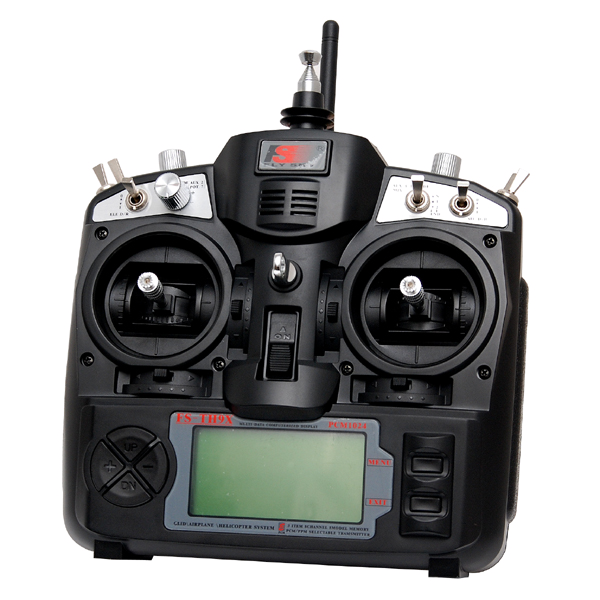
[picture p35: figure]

ER9x

r257 - Nov 5, 2010

# Disclaimer

THIS FIRMWARE IS PROVIDED ON AN "AS-IS" BASIS WITHOUT WARRANTY OF ANY KIND AND ANY EXPRESS OR IMPLIED WARRANTIES, INCLUDING, BUT NOT LIMITED TO, THE IMPLIED WARRANTIES OF MERCHANTABILITY AND FITNESS FOR A PARTICULAR PURPOSE ARE DISCLAIMED. IN NO EVENT SHALL THE DEVELOPER AND/OR AUTHOR BE LIABLE FOR ANY DIRECT, INDIRECT, INCIDENTAL, SPECIAL, EXEMPLARY, OR CONSEQUENTIAL DAMAGES (INCLUDING, BUT NOT LIMITED TO: PERSONAL AND/OR PROPERTY DAMAGE) HOWEVER CAUSED AND ON ANY THEORY OF LIABILITY, WHETHER IN CONTRACT, STRICT LIABILITY, OR TORT (INCLUDING NEGLIGENCE OR OTHERWISE) ARISING IN ANY WAY OUT OF THE USE OF THIS FIRMWARE, EVEN IF THE DEVELOPER AND/OR AUTHOR. HAS BEEN ADVISED BY USER OF THE POSSIBILITY OF SUCH POTENTIAL LOSS OR DAMAGE. USER AGREES TO HOLD THE DEVELOPER AND/OR AUTHOR. HARMLESS FROM AND AGAINST ANY AND ALL CLAIMS, LOSSES, LIABILITIES AND EXPENSES.

Yeah, and no spitting either!

# Introduction

The IMAX/FLYSKY/TURNIGY/EURGLE 9x is a computerized radio from china. The transmitter is outfitted with a 128x64 pixel monochrome LCD, 2-2axis gimbals, 3 variable potentiometers (pots), 6 2-position switches, 1 3-position switch and some funky red trim.

The big thing about this transmitter is the price. At the time of writing radios may cost anywhere from $180 for simple units up to $1000+ for super blinged out bazillion channel super heavyweight monsters.

This one costs $60.

Where's the catch then? (you might ask) The catch is in the software (firmware - FW). The original FW is less-than-perfect. It has bugs, funky navigation and the most annoying beeping I have ever heard. Not good.

However, some neat guy called Thus figured out that the whole radio is made from gimbals, switches, funky trim and a very generic main processing unit that does absolutely everything. He had one of those ah-ha moments where insanity overrides common-sense and decided to completely rewrite the original software and replace it with his own.

At some point I decided that while Thus' FW is great I really wanted more bling for my TX. So in the spirit of open-source Thus' source was stolen and ER9x was born. (Yeah, I was vain. ER are my initials)

You might want to check out Thus' code – it's available here: http://code.google.com/p/th9x/

While you're at it check out RadioClone's code – which also runs on the 9x. While ER9x is based on Thus' code, I have managed to pilfer some of RC's excellent code. His FW is more complex but also more powerful. Check it out here: http://radioclone.org/

Got you all worked up about this? Good. Go now to the kitchen, make yourself a nice cup of coffee. This is a long read. I'll wait here till you're ready. Promise!

## How it works

Pots (P1,P2,P3) Switches Sticks (RUD,THR,ELE,AIL) Trims Calibration Calibration Expo / Dr MIXER Limits Output Bear with me here – some flow charts coming up:

What the heck was that?

The system receives 4 types of inputs:

1. Main Sticks
2. Potentiometers
3. Trims
4. Switches

The analog inputs (sticks and pots) go through a calibration phase. The sticks can also go through Expo and Dr filters before going to the mixer.

The mixer does it all. It directs each input to the desired output (CH1..CH16). It controls how the inputs are added. It also controls the timing of each function.

After the inputs are processed by the mixer they are directed to the relevant output channels. The limit procedure takes over and makes sure no output goes too far.

Finally the channels are encoded and sent to the RF module to take that nice little hike through the air to your model.

## Nomenclature

(just so we understand each other)

Inputs:

1. RUD – Rudder.
2. ELE – Elevator.
3. THR – Throttle.
4. AIL – Aileron.
5. P1/P2/P3 – Pots.
6. Switches:
  1. THR – Throttle cut switch, don't confuse this with the THR stick. The THR switch is located on the back left side.
  2. RUD – Rudder Dr switch.
  3. ELE – Elevator Dr switch.
  4. ID0, ID1, ID2 – Three position switch. These 3 define the 3-position switch. ID0 is the top position, ID1 – mid position and ID2 – bottom position.
  5. AIL – Aileron Dr switch.
  6. GEA – Gear switch.
  7. TRN – Trainer switch. This switch is spring loaded.
  8. SW1..SW6 – Custom switches. More on these later.

It should be stated that every function in this FW is assignable. There are no fixed switches. You can choose the TRN switch to be throttle cut and use the triple switch to control Dr. The names are useful since they are labeled like that on the Tx.

## Edit buttons

There are 6 edit buttons on the Tx. In this manual they are noted with square brackets ([MENU]). Some functions need the button to be pressed and held for a second or so. The are noted as “long” presses like so: [MENU LONG]

Also since the “+” and “-” keys are placed stupidly in the original Tx I've switched their position. So [+] is actually [-] and vice-versa. This is actually more intuitive than the original (trust me, I've tried using them as is).

Since to upload this FW you need to open up your Tx and do some modifications (which void your non-existent warranty FYI) it is highly recommended you switch between the [+] and [-] keys. It's a simple job, so don't skimp, you'll thank me later.

To avoid confusion with people who modded their keys and all the others I'll refer to the [+] and [-] keys as [LEFT] and [RIGHT] from now on. (I hope that left and right are still universal values – you can never tell today)

The “!” sign. Whenever you see the “!” sign you can read that as “not” or “inverted”. Switches can be “normal” or “inverted”. So when choosing the elevator d/r switch ELE is normal operation and !ELE denotes inverted operation.

## Navigation

As a general rule the [UP]/[DOWN]/[LEFT]/[RIGHT] move the cursor appropriately The [MENU] key is used for selection and for editing. The [EXIT] key is used for exiting (surprise). Pressing [EXIT] will generally bring the cursor to the top of the screen. Another press will exit the menu to the main screen. Pressing [EXIT LONG] will exit immediately to the main screen.

Pressing [MENU] from the main screen will take you back to the last menu.

From the main screen you can press [RIGHT LONG] to enter the model setup pages. Pressing [LEFT LONG] will enter the general setup menus.

Once in the menus you can navigate between different screens using the [LEFT]/[RIGHT] keys as long as the cursor is at the top right position of the screen.

## Editing and Saving

As a rule once a value is changed it is saved. You can turn off your Tx and turn it back on and the values will be saved. The values are saved internally in the MCU's eeprom. However there is a slight delay sometimes so it's probably a good idea to wait a couple of seconds before turning off.

There is no undo functionality. Once something is erased/changed it's changed for good.

Generally, when a value is highlighted and you cannot move left or right then pressing [LEFT]/[RIGHT] will change that value.

When moving left or right is possible you need to press [MENU] to edit that value. Edit-mode is displayed by the cursor blinking. To exit edit-mode press either [MENU] or [EXIT].

When editing, pressing both [LEFT] and [RIGHT] simultaneously inverts the value. Try it, it's cool!

Also , with r155 and up it is now possible to change values with the P3 pot (the one at the front of the Tx called PIT. TRIM/AUX 2).

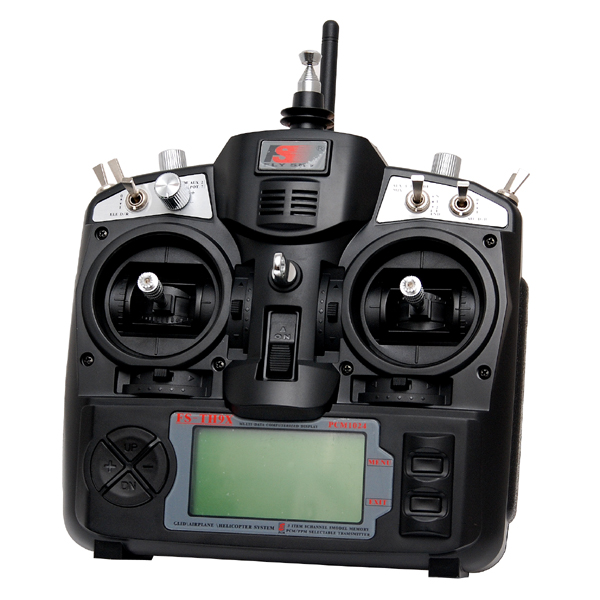
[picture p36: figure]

## P2 RUD SW THR SW P3 GEA SW TRN SW P1 ELE SW Left Stick [DOWN] [LEFT] [RIGHT] [UP] [EXIT] [MENU] Right Stick AIL SW ID0/1/2Transmitter Layout

# Main Screen

GOOFI 8.9 15:00 (Cool back light here, huh?)

## General view

The main view is split into top and bottom. The top contains the following:

- The current model's name. (GOOFI in this case and yes, it's a real airplane)
- The battery voltage.
- Trim increment information.
- Timer and timer trigger information. Pressing [EXIT LONG] resets the timer.
- Throttle trim activation information.

The bottom consists of three screens. You can flip between these with the [UP]/[DOWN] keys.

The 3 screens are:

- Value bars – these show the output values for the first 8 channels.
- Value values – The output values for the first 8 channels.
- Input values – Stick position and switch indicators.

## Statistics Screens Statistics Screens

STAT 08:02 TOT TME 08:02 00:00 TSW STK 00:00 00:00 ST% STAT2 tmr 1Lat max 5 us tmr 1Lat min 5 us tmr 1 Jitter 0 us tmain 6,31 ms

From the main screen pressing [UP LONG]/[DOWN LONG] will enter the statistics screen.

The first shows some available timers and traces the throttle stick as well.

The second shows general timing of the Tx. The value “tmain” shows how long the math takes. This will increase as you add more mixers. It can be very large sometimes depending on eeprom writes. You can reset the timers by pressing [MENU].

# General Settings

From the main screen pressing [LEFT LONG] will enter the general settings menus. Here you can set up settings that will be the same regardless of chosen model.

The menus are as follows:

1. Radio Setup
2. Startup Warnings
3. PPM In Calibration
4. Version Information
5. Diagnostics
6. Analog Inputs
7. Calibration

## Radio Setup (1/6)

RADIO SETUP 1/6 Beeper Quiet Contrast 25 BAT Warning 9,0v Inactivity Alarm 0m Filter ADC SING Mode ↔☼ ↕☼ ☼↕ ☼↔ 2 RUD THR ELE AIL

Use this screen to set up general functions for the Tx:

1. Beeper: Sets Beeping levels
  i. Quiet. No beeping at all. No warning – nada. If the kids are sleeping and you must setup the model in your living room this is the mode to use. Just remember that the Tx will not even warn you when the battery is low. If you're using a Lipo watch out!
  ii. No keys. The beeps are normal but edit keys are silent.
  iii. Normal. Normal beeping.
  iv. Long beeps. For those who want to annoy other people.
  v. Extra long beeps....
2. Contrast: The LCD's contrast. The values can be 20..45. The higher the value the darker the screen.
3. Battery warning: Battery voltage warning. When the connected battery's voltage drops below this voltage the Tx will beep. Though the Tx will continue to function normally it's really advisable to land as it is known that this FW was not able to fix the “zero voltage non-functionality” problem of the original.
4. Inactivity alarm: This will set up a warning that will beep if the Tx is left unattended for the specified amount of time. Values can be from 1 to 250 minutes. To reset the timer simply move one of the sticks.
5. Filter ADC:
  i. SING: Single conversion. This is the fastest conversion but base resolution is 1024.
  ii. OSMP: Oversampling. This uses extra samples to increase resolution to 2048. Just slightly slower than SING.
  iii. FILT: Filtered. This is in case you have excessive noise from the conversion (servo jitters). This will filter the input and prevent that noise. It will, however, increase latency by ~30msec.
6. Throttle reverse: This is for all you wacky people who fly with the throttle backwards (e.i. idle is far from you and full is close to you). Though I personally don't understand how you fly like that it's a nice feature. The reverse will also reverse the throttle warning on startup and some other throttle related functions.
7. Minute beep: Beeps every full minute while the timer is running.
8. Countdown beep: Beeps at 30, 20, 10, 3, 2 and 1 seconds before the timer ends.
9. Flash on beep: Flashes the backlight on timer beeps.
10. Light switch: This chooses a switch which can be used to turn on a backlight if connected.
11. Light off after: When this is not OFF any keypress will turn on the backlight and turn it off after the specified number of seconds.
12. Splash screen: Show the logo on radio startup.
13. Throttle warning: If ON will show a warning when throttle is not at idle when the Tx is turned on. The Tx will not output a signal until the alert is cleared.
14. Switch warning: If ON will show a warning when the switches are not at the default position when the Tx is turned on. The Tx will not output a signal until the alert is cleared.
15. Memory warning: If ON will show a warning when the available eeprom memory is less than 200 bytes when the Tx is turned on. The Tx will not output a signal until the alert is cleared.
16. Alarm warning: This will give you a “heads up” if your beeper is silent. If on and the beeper is set to '0' (Quiet) you will receive a warning on startup. This has been added after a programing session left a user flying on silent. I find it really useful!
17. Mode: Choose between MODE1, MODE2, MODE3 and MODE4.

## PPM In (2/6)

PPMIN 2/6 Cal 0,0 0,0 0,0 0,0 0,0 0,0 0,0 0,0 Multiplier 1,0

This menu allows you to calibrate the mid point for the input PPM channels.

Highlighting “Cal” and pressing [MENU] will calibrate the mid point for all PPM IN channels.

PPM IN is read from the signal at the trainer port of the Tx.

The multiplier does as it's name suggests. It multiplies the ppm Input by a set amount. Great for dealing with different tx's whose makers don't know how to encode PPM :-P.

## Version Info (3/6)

VERSION 3/6 SVN: trunk-r98 VERS: V1.2484-erez DATE: 06.09.2010 TIME: 09:19:32

This screen shows the version information for the current FW:

SVN: The SVN name of the current revision.

DATE: Compile date for the current FW.

TIME: Compile time for current FW.

VERS: Version number.

Since ER9x is OPEN SOURCE I try to help out anyone who has problems. Please feel free to open new issues for defects and/or enhancement requests at the project's code page:

http://code.google.com/p/er9x/issues/list

Your participation is what helps me makes the FW better (and your donations of-course!). Please use the revision number stated in this screen when you state a problem.

## Diagnostics (4/6)

DIAG THR 0 4/6 RUD 0 Left 0 ELE 0 Right 0 ID1 1 Trim- + Up 0 ID2 0 ↔☼ 0 0 Down 0 AIL 0 ↕☼ 0 0 Exit 0 GEA 0 ☼↕ 0 0 Menu 0 TRN 0 ☼↔ 0 0

This menu will help you visualize the current state of the trims, keys and physical switches.

Each Key/Switch/Trim is represented. When pressing a key or switch they are highlighted.

## Analog Inputs (5/6)

ANA A1 0422 0 5/6 A2 0347 63 A3 0466 0 A4 0414 0 A5 07EE -30 A6 0345 -30 A7 06AE 80 A8 028B 8,7v

Here you can see the analog inputs in hexadecimal format to save space and annoy you at the same time.

Values range between 0..0x3FF (0..1023).

A1..A4 are the gimbals (sticks).

A5..A7 are the pots.

A8 is battery voltage. You can press [DOWN] and highlight the battery voltage. Pressing [LEFT]/[RIGHT] will increase and decrease the value and so enable you to calibrate the battery voltage monitor.

## Calibration (6/6)

CALIBRATION 7/7 0355<0422 >033F SetMid 0200<0414 >0353 SetSpan 0302<0410 >0354 Done 0360<0416 >03E0 03B0<0200 >0344 03D0<0233 >03FF 03F0<0268 >03FF

This screen allows you to calibrate the analog channels (A1..A7).

The calibration method goes like this:

1. Press [DOWN] → (SetMid)
2. Set Sticks to center. (Including throttle and pots)
3. Press [DOWN] → (SetSpan)
4. Move sticks and pots through full range.
5. Press [DOWN] → (Done) – Values are saved here.
6. Press [DOWN] (Back to top)

The values are calculated when you press [DOWN].

They are saved when you press [DOWN] to (Done).

(Works surprisingly well for a cheap Chinese Tx)

# Model Setup

From the main screen pressing [LEFT RIGHT] will enter the model select/settings menus. Here you can set up settings that model specific.

The menus are as follows:

1. Model Select
2. Model Setup
3. Expo/Dr
4. Mixer (This is the important one)
5. Limits
6. Curves
7. Custom Switches
8. Templates

## Model Select (1/8)

MODELSEL free 1560 1/8 *01 GOOFI 114 02 YAK 55 60 03 04 05 06

In this screen you can see, select, copy and move models between different memory “slots”. I quote the word “slots” because memory management is dynamic. The available memory is displayed at the top of the screen.

Memory usage for each model is displayed on the right. The more complex your model (mixes/curves/options/limits/etc) the more memory it'll take.

The “*” on the left shows the currently loaded model memory.

Pressing [UP]/[DOWN] will move the cursor between different models.

Pressing [MENU] will highlight the model. Pressing [UP]/[DOWN] with the model highlighted will move it up/down. Pressing [EXIT] will un-highlight the model.

Pressing [EXIT] will load the highlighted model.

Pressing [EXIT LONG] will load and exit to the main screen.

Pressing [MENU LONG] or [RIGHT LONG] will load the model and go to the next screen (Model Setup).

## Model Setup (2/8)

SETUP 01 2/8 Name GOOFI Timer 15:00 Trigger Ths Timer Count Down T-Trim ON T-Expo ON Trim Inc Medium

Lots of options here:

1. Name: Unsurprisingly here you edit the model's name. To edit: scroll down until the name is highlighted and press [MENU]. Once your press [MENU] only one letter will remain highlighted. To change the letter you press [UP]/[DOWN]. To move the cursor press [RIGHT]/[LEFT]. Once done, press [MENU]/[EXIT] to exit the edit.
2. Timer: Here you set the value for the timer. Press [RIGHT]/[LEFT] to choose between minutes and seconds. Press [MENU] and the cursor will blink. To edit use the [UP]/[DOWN]/[RIGHT]/[LEFT] buttons and [MENU]/[EXIT] when done.
3. Trigger: Choose what triggers the timer → (remember – by pressing [LEFT] you'll see the same values with the “!” sign. This means that the usage is inverted)
  1. OFF – timer is off.
  2. ABS – timer is on.
  3. RUs/RU%/ELs/EL%/THs/TH%/ALs/AL% - chooses to activate the timer based on stick position. When a XXs is selected (THs for example) The timer starts whenever the stick is not at zero. The XX% sign is the same except the timer speed is determined by stick position. When at zero, the timer is stopped. When at full the timer goes at normal speed. When midway the timer's speed reflects the sticks position.
  4. Switches – You can specify a switch so whenever that switch is activated the timer counts.
  5. Momentary switches. A switch denoted with “m” (like TRNm) means “momentary”. That means that moving the switch once to the on position and back turns the timer on. Moving it on and off again turns the timer off. (difficult I know, take a sip from your coffee, relax a bit, take a break – it's not difficult once you try it out :) )
4. Timer: Here you can choose whether the timer counts up or down.
5. T-Trim: Throttle trim. This is a nifty feature for power fliers. When activated a couple of things happen. First off the center detent for the throttle trim is removed. Also the throttle's trim will now only affect the “low” side. That means you can use the trim for setting idle while full throttle remains unchanged.
6. T-Expo: 'nother throttle related function. This one makes the throttle stick's expo go from zero to full instead of having a center like all the others. Always the odd kid out this throttle is.
7. Trim Inc: Trim increments:
  1. Exp – Exponential. With this the trims are fine near the center and get progressively coarser farther out.
  2. ExFine – Extra fine – 1 step per click.
  3. Fine – 2 steps per click.
  4. Medium (my personal favorite) – 4 steps per click.
  5. Coarse – 8 steps per click.
8. Trim Sw: Neat little function this is. When in flight if this key is activated it reads the current position of the sticks and trims and copies that into the subtrims. After that it zeros the trims. This is really neat for new models when you might have a hard time taking your hands off the stick and pressing the trims. Simply hold the plane level with the sticks and press the selected trim switch. Voilà – the plane is trimmed. It's magic! No it ain't. It's ER9x!!!
9. Beep Cnt: Beep Center. Here you set center warnings. The string RETA123 corresponds to: RUD, ELE, THR, AIL, P1, P2, P3. When the letter corresponding to the analog channel is highlighted the system checks for center. When the input is at center a short beep will sound enabling you to hear when the input is centered. This is useful for checking the center of the pots without looking.
10. Proto: encoding protocol
  1. PPM – with ppm you can choose how many channels to encode. Anything from 4 to 16 channels. You can also change the pulse spacing. This is useful for systems which might experience jitter. On the whole it might be a good idea to leave it alone.
  2. Other protocols include Silver A/B/C and TRAC09.
11. Shift Sel: Shift select. POS/NEG. Select signal shift. POSitive or NEGative.
12. DELETE MODEL [MENU]: Guess.... This deletes the current model. You need to press [MENU LONG] for that to happen though.

WARNING!

Deleting a model causes the memory to jump to the previous model memory in the list. Do not delete a model memory while you have a model "listening". Always shut down your receiver before deleting a model.

(This all sounds perfectly reasonable until you actually forget to turn off you electric model and have it fly around your house uncontrolled – you've been warned!)

## Expo/Dr (3/8)

EXPO/DR 3/8 exp % sw1 sw2 RUD 0 100 - --- --- H THR 50 100 - --- --- H ELE 0 100 - --- --- H AIL 0 100 - --- --- HThis screen allows you to enter and edit Expo and D/R values for the main controls (RUD/ELE/THR/AIL).

For each control you can input values for Left/Right for both Expo and D/R. To edit expo values highlight the value in the “expo” column and press [MENU]. Once the cursor blinks you can use the [UP]/[DOWN]/[LEFT]/[RIGHT] buttons to change the value. Notice that while there is a telltale that shows you which side of travel you are adjusting:

- "-”: This means both left and right values are equal. Pressing [UP]/[DOWN]/[LEFT]/[RIGHT] will change both values simultaneously.
- "←”, “→” : When moving the stick you can see either of these symbols. When this symbol is visible you are only changing that side of travel.

For each control you can set 2 switches. The main switch changes between high rate/high expo and mid rate. If the main switch is “low” (e.i. mid rate) the second switch can switch between mid and low rate.

At the end of each line there's a telltale that shows you which rate you are on:

- H: High.
- M: Medium.
- L: Low.

Pressing [MENU LONG] while the cursor is on a control will take you to the Edit Expo/Dr screen. In this screen you can adjust the values for that single control. You will also see a graph indicating the action of that control. Press [EXIT] to return to the main Expo/Dr screen.

### Triple Dr Example

The "F.Mode" switch can be used as a triple rate switch for any one axis, or it can be used as a triple rate flight mode switch, controlling rates and expos for some or all of the flight axes at once. To use it as a triple rate/flight mode switch, set sw1 to "!ID2" and sw2 to "!ID1" If you want rudder, elevator, and aileron all assigned to this switch for flight modes, be sure to set sw1 and sw2 as above for each axis. With the switch in the up position, it will be at low rate, as indicated by the "L" at the end of the line. In the mid position, it will be mid rate, and at the down position, it will be at high rate. You can also include throttle if you'd like, to have different expo curves for each of the flight modes.

## Mixer (4/8)

I'm actually writing this last since it's the most important menu. If you're still awake now would be a good time to sip that coffee and wake up. You want to understand ER9x? Understand the mixer and you're very nearly there.

The function of the mixer is to take the inputs, perform some function on them and route them to the output channels. Since selection is totally free you have a very flexible system which is extremely powerful and very quick to boot.

### Main Screen

When you enter the screen for the first time you'll probably see a list like so:

MIXER 4/8 wt src sw crv CH1 100% RUD CH2 100% ELE CH3 100% THR CH4 100% AIL CH5 CH6What this is telling you is that the rudder stick's input is being routed with a weight of 100% to CH1. Same for the elevator, throttle and aileron. Though not visible now you can also see the switch column which will tell you if a switch is assigned to the mix and also a crv (curve) column which tells you what curve is applied to that mix.

When you scroll down you'll see that sometimes the weight is being highlighted and sometimes the channel's number is underlined. When the weight is highlighted, pressing [LEFT]/[RIGHT] will edit that value and pressing [MENU LONG] will enter the Edit Mix screen and allow you to edit that mix.

When the channel's number is underlined, pressing [MENU LONG] will insert a new mix for that channel and take you to the edit mix screen for it.

You can also press [MENU]. This will highlight the mix. Then you can press [UP]/[DOWN] to move or copy the mix. Notice that moving or copying is decided by whether you press up or down on the first press after highlighting the mix. If you first try to move it down it will be copied. Subsequent presses of [UP]/[DOWN] will move the copy up or down until you press [MENU] or [EXIT]. Pressing [UP] will move the mix without copying it. Again, subsequent presses of [UP]/[DOWN] will move the copy up or down until you press [MENU] or [EXIT].

### Edit Mix

EDIT MIX CH1 Source RUD Weight 100 Offset 0 Trim ON Curves c1 Switch --- Warning OFF

In this screen you edit individual mixes.

Here are the available options for each mix:

1. Source: This is the input for the mix. It can be the following:
  i. Stick or pot: Self explanatory.
  ii. MAX: The output is either 0 or the value describes in “weight”. This is controlled by the switch.
  iii. FULL: Same as MAX but the value is “-weight” if the switch is off or “weight” if the switch is on. MAX and FULL can be a little confusing. Look in the examples section for, well, examples :).
  iv. PPM1..PPM8: PPM input channels. These are fed by the ppm input or “trainer port”. You can use these to configure a buddy system or to simply extend your radio with more functions (like head tracking for you FPV guys).
  v. CH1..CH16: These are the outputs of the other mixes. You can use these to chain mixes for very complex behavior.
2. Weight: This value multiplies the value from the input. It can be -125% to 125%.
3. Offset: This value is added to the value from the input. It can be -125% to 125%.
4. Trim: When this is “ON” the trim value (if exists) will be carried on through the mix. When “OFF” it is ignored.
5. Curves:
  i. x>0: The value of the source is carried through only if it is positive (greater than zero). Otherwise it is zero.
  ii. x<0: Same but for negative values.
  iii. |x|: The value is passed as an absolute value.
  iv. f>0: If source is positive then the output value is “+weight” otherwise it is 0.
  v. f<0: If source is negative then the output value is “-weight” otherwise it is 0.
  vi. |f|: Output is either “+weight” or “-weight” depending on the sign of the source.
  vii. c1..c16: custom curves. These are defined in the “CURVES (6/8)” screen. You can also press [MENU] to edit the curve directly.
6. Switch: Here you select the switch that operates the mix. If the switch is not selected then the mix is on by default.
7. Warning: Here you can select an audible warning that will sound whenever a mix is active. (This will only work when a switch is defined). You have an option of 1, 2 or 3 beeps. The warnings will sound in succession so you can hear them individually.
8. Multpx: This value defines how the mix will be added to the channel.
  i. Add: This is the default value. With this value the mix is added to the previous values in the same channel.
  ii. Multiply: Use this to multiply the previous values in the same channel.
  iii. Replace: This value is used in conjunction with a switch. When the switch is off the value is ignored. When the switch is on the value discards the previous values and places it's own value in the channel.
9. Delay Down/Up: Use this to delay use of this channel. Usually used with a switch. When the switch is turned “ON” or “OFF” the mixer will wait the specified number of seconds before changing the value.
10. Slow Down/Up: Slow the rate of change in the channel. When not zero these will determine the maximum speed with which the value can change. The specified value is the number of seconds to go between -100% to 100%.
11. DELETE MIX [MENU]: Pressing [MENU LONG] here will delete the mix and return to the main mix screen.

## Limits (5/8)

LIMITS 5/8 subT min max inv CH1 -5,9 -100→ 100 --- CH2 0,7 -100→ 100 INV CH3 0,0 -95 ← 40 --- CH4 -14,4 -100→ 100 INV CH5 45,9 -100→ 100 INV CH6 0,0 -100→ 100 ---

This is probably the second most important menu.

The limits operate on the output channels (as you can see from the flow chart in the introduction). In the LIMITS menu you can set the center point (subtrim), limits (both left and right) and reverse the channel's output (inv – invert).

Each channel here corresponds to a channel in your receiver. The limits you set will be used on that channel only.

Columns:

1. subT: SubTrim. This sets the channel's center point. HINT: The values of subT can be -100 to 100 with increments of 0.1. This is done so to have excellent resolution when setting the center of each surface. You can use your stick to set the center point as well. While the subT is highlighted hold the stick so that the surface is centered. Press [MENU LONG] and the position will be recorded! It's the magic of ER9x again :).
2. Min/Max: These set the endpoints of the channel. Notice that there's a telltale that hints as to which side is active at the moment. Each limit point can range between -100% to 100%. The limits act both as gains and as absolute limits. The servo will not go beyond the limits you set here.
3. inv: Invert. This function reverses the output of the channel.

## Curves (6/8)

CURVE 6/8 CV1 -75 -40 0 45 75 CV2 0 0 0 0 0 CV3 0 0 0 0 0 CV4 0 0 0 0 0 CV5 0 0 0 0 0 CV6 0 0 0 0 0 CV7 0 0 0 0 0

Surprisingly in this menu you set your custom curves. Curves are nifty things that can tell your servo how to move when you move your stick. In ER9x there are 8 5-point curves and 8 9-point curves.

A 5pt curve is a curve you can edit at position -100%, -50%, 0%, 50%, 100%.

A 9pt curve is a curve you can edit at position -100%, -75%, -50%, -25%, 0%, 25%, 50%, 75%, 100%.

When you enter the menu you see a long list of zeros. Scroll down to the curve you wish to modify and press [MENU] or [RIGHT]. This will bring up the screen for editing the curve. Depending on whether you chose a 5pt or a 9pt curve you will see 5 or 9 editable points. Scroll through the points with [UP]/[DOWN]. Change the value with [LEFT]/[RIGHT].

At the bottom you will see a “preset” entry. Pressing [LEFT]/[RIGHT] on that will populate the values with a linear curve that is a good starting point.

You can also change the curve graphically. Highlight the “EDIT->” line and press [RIGHT]. This will highlight the curve points. Pressing [UP]/[DOWN] will change the values and pressing [LEFT]/[RIGHT] will select a different curve point.

## Custom Switches (7/8)

CSWITCH 7/8 Function V1 V2 01 v<ofs -60 THR 02 AND ID0 ID1 03 ---- 0 ---- 04 ---- 0 ---- 05 ---- 0 ---- 06 ---- 0 ----

I really like this feature.

Custom switches are not really switches at all but rather a set of logical conditions that can be used as switches.

You might have noticed that beyond the physical switches there are 6 switches called SW1..SW6. These correspond to the list you see in this screen. Once the condition defined for the switch is met it's value will be “ON”.

1. First we define the condition. This can be v>offset, v<offset, |v|>offset and |v|<offset, or it can be a logical condition: AND, OR, XOR, or it can be an evaluation between 2 sources.
2. If you've selected a regular condition you need to specify a source and an offset:
  1. The source can be a stick, a pot, a PPM input or an output channel.
  2. An offset can be anywhere between -100 and 100. This will be the test point for the condition.
3. If you've selected a logical condition the switch results the condition applied to the 2 selected switches. For example: OR ID1 ID2 will be “ON” if either ID1 or ID2 is on. Cool, huh?
4. If you've selected an evaluation you (“==”, “>”, “<” etc...) you need to select the 2 sources to evaluate between. For example: Switch on only if CH1 is less than RUD → V1<V2 CH1 RUD

Example:

Say you have a glow plug driver which you want to turn on when the throttle is below 10%:

1. Highlight SW1
2. Select the source as THR.
3. Select the offset as -80 (remember -100 – 100 so 10% from idle is -80).
4. Select the condition as v<ofs.

Now you need to use a mix to run the switch. Go to the mixer menu. Select the CH8 as the channel you want the GP driver to operate on. On that channel select source as “MAX” and Switch as “SW1”.

Now whenever the throttle goes below 10%, CH8 will go to 100%. Cool, huh?

## Templates (8/8)

TEMPLATES 8/8 01 Simple 4-ch 02 T-Cut 03 V-Tail 04 Elevon\Delta 05 eCCPM Channel Order RETA CLEAR MIXES [MENU]

The templates are there to help you get started. When entering the screen you'll see a list of available templates. To choose a template, scroll down to it and press [MEU LONG]. This will add the template to the existing mixes.

Channel order:

This will allow you to set the way the templates are written to the mixers.

RETA means RUD = 1, ELE = 2, THR = 3, AIL = 4.

AETR means AIL = 1, ELE = 2, THR =3, RUD = 4.

(and so forth).

At the bottom you'll see an option called “CLEAR MIXES [MENU]”. Pressing [MENU LONG] on this will clear all the mixes leaving you with a clean slate.

The templates are:

1. Simple 4-CH: Plain vanilla 4-ch airplane.
2. T-Cut: This adds a throttle cut mix on your throttle channel.
3. V-Tail.
4. Elevon\Delta.
5. ECCPM; A generic ECCPM mix.
6. Heli Setup: This will clear your mixes and curves and setup a preliminary eCCPM heli.
7. Servo Test: This will setup a servo test output on CH15. To test your servos choose the mixer's source as CH15. It will cycle slowly between -100 and 100.

# Examples

## Programming a throttle cut

Though you can use a template for this it's instructional to do it via the mixer.

Start off with the default 4 mixes.

Scroll down until CH3 is underlined, like this:

MIXER 4/8 wt src sw crv CH1 100% RUD CH2 100% ELE CH3 100% THR CH4 100% AIL CH5 CH6

Press [MENU LONG] to enter the “Insert/Edit Mix” screen.

EDIT MIX CH3 Source ELE Weight 100 Offset 0 Trim ON Curves --- Switch --- Warning OFF

Change source to “MAX” and Weight to “-100”.

Also set the Switch to THR.Like so:

EDIT MIX CH3 Source MAX Weight -100 Offset 0 Trim ON Curves --- Switch THR Warning OFF

Keep on scrolling down until you reach Multpx.

Change the value to “Replace”

EDIT MIX CH3 Weight -100 Offset 0 Trim ON Curves --- Switch THR Warning OFF Multpx Replace

Now press [EXIT]

You should see the following screen:

MIXER 4/8 wt src sw crv CH1 100% RUD CH2 100% ELE CH3 100% THR R-100% MAX THR CH4 100% AIL CH5

What it tells you is that on CH3 you have 2 mixes defined.

The first takes the value of the throttle stick. The second depends on the THR switch. When the switch is off the mix is ignored so the only value will be the value of the throttle stick. When the switch is on that value will be replaced with -100%.

# Build and Program Instructions

You might want to play with the code and modify it for your own needs. It's really easy if you know a little C.

First, to program the MCU, download the full programing instructions:

Flashing the 9x (http://er9x.googlecode.com/files/Flashing%20the%209x.pdf) by Jon Lowe.

## Building from Source

First checkout using svn: svn checkout http://er9x.googlecode.com/svn/trunk/ er9x
Enter the src/ directory.
To make the standard version type: make
To make the JETI DUPLEX enabled version type: make EXT=JETI

## Flashing

(you may have to run as admin to access the USB port in Linux)

To write the FW: make wflash AVRDUDE_PROGRAMMER=usbasp
To write the EEPROM: make weeprom AVRDUDE_PROGRAMMER=usbasp
To read FW: make rflash AVRDUDE_PROGRAMMER=usbasp TARGET=backupflash
To read the EEPROM: make reeprom AVRDUDE_PROGRAMMER=usbasp TARGET=backupeeprom

Make sure you replace "usbasp" with the name of your programmer.
To list available programmers type: avrdude -c ?

## make targets

- make all (default): build the source
- make clean: Remove compiled files and directories.
- make wflash: Write flash (program) memory.
- make rflash: Read flash memory.
- make weeprom: Write eeprom.
- make reeprom: Read eeprom.
- make coff: Convert ELF to AVR COFF.
- make extcoff: Convert ELF to AVR Extended COFF.
- make debug: Start either simulavr or avarice as specified for debugging, with avr-gdb or avr-insight as the front end for debugging. (for debug info look into the makefile)
- make filename.s: Just compile filename.c into the assembler code only.

## make options

- EXT=JETI: make jeti vesion.
- AVRDUDE_PROGRAMMER: Set avr programmer name - default: usbasp (to list all available: avrdude -c ?)
- TARGET: Set target name - default: er9x
- OPT: Set optimization level - default: s
- FORMAT: Set format (can be srec, ihex, binary) - default: ihex
- MCU: Set MCU - default: atmega64

# MORE

I sincerely hope you enjoy both the ER9x FW and this manual.

I also sincerely hope you're still awake. If you are I applaud you :)

This is an Open Source project. It means that I request no money for it. You are free to look up, download, modify and release the code under the GNU v2 software license.

If you have any questions, requests and/or gaudy compliments I'll be happy to hear them either on the FW's code page:

http://code.google.com/p/er9x/

Or on the following threads in RCG or RCModelReviews:

http://www.rcgroups.com/forums/showthread.php?t=1266162

http://www.rcmodelreviews.com/forum/viewtopic.php?f=47&t=292

Also bug reports and enhancement requests can be reported here:

http://code.google.com/p/er9x/issues/list

eePe and er9x are free to use under the GNU v2.0 License. Feel free to use, copy and modify it as you wish! I have spent a lot of time (and will continue to) to make this software as good as possible. If you feel that this software has been beneficial to you please show your support by donating 5$USD. This will be greatly appreciated and you'll be added to the "contributors" list in the code (optional of-course).

If you feel you'd like to contribute time, software code, documentation, tutorials, examples and/or money (I like money :) Please feel free to email me at: erez.raviv@gmail.com

Please tell your friends about this cheapie $60 Chinese Tx. I bet They'll roll their eyes up and tell you to go buy a *real* system. That's o.k. You'll have more money for *real* models!

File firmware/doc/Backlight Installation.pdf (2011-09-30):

# LCD Backlight for TH9X Transmitter

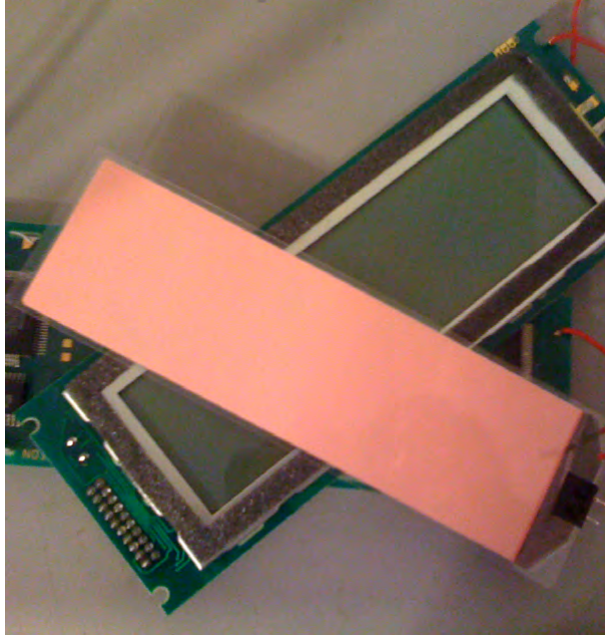
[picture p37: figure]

This is an easy modification to install a backlight into your transmitter. The EL panel can be scavenged from a surplus or even new graphics or alphanumeric unit. I had a few in my junk box, so I was lucky.

Here is an inexpensive source for the EL backlight high voltage. Mine was less than $10 with shipping. Here is the URL.

http://www.coolight.com/product-p/cl-sic-12v-35-50ft.htm

Digikey has the FET's to turn the backlight on/off with software. Here is the URL.

http://search.digikey.com/scripts/DkSearch/dksus.dll?Detail&name=BS170_D27ZCT-ND

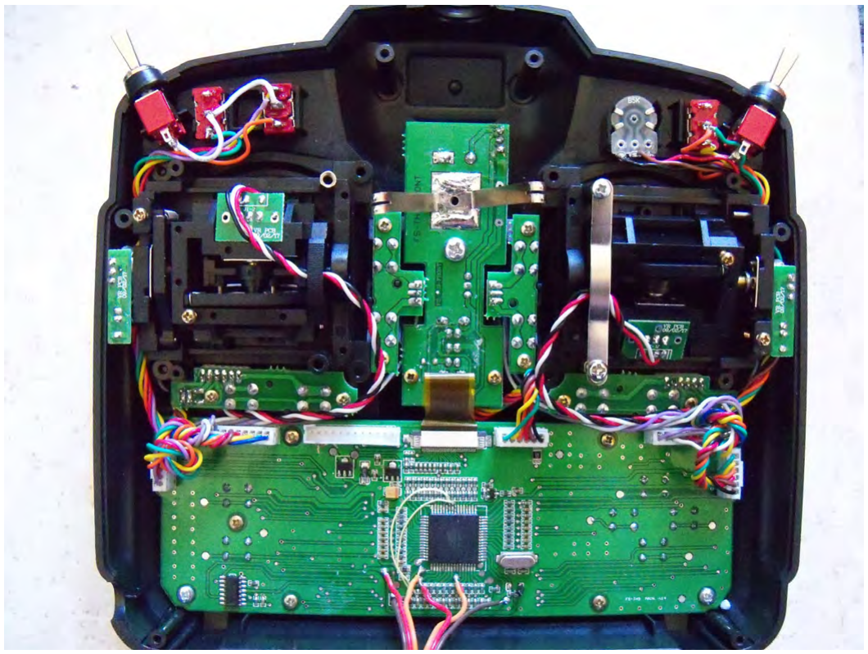
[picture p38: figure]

Open the TX by removing the 6 screws on the back and unplugging the front section connector,

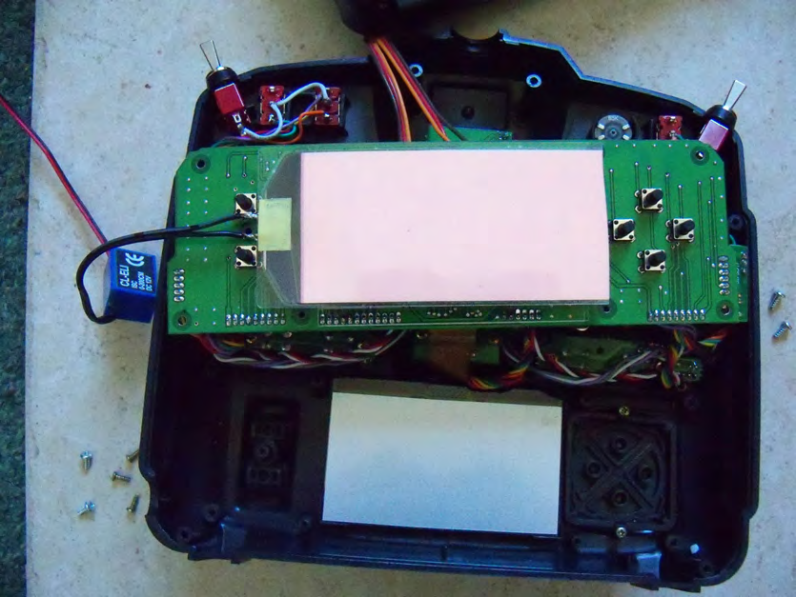
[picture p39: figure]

The LCD display board has 9 screws to remove. Pay attention to the screws because there are two different sizes !
Bend the board up and place the EL panel with 2wires onto the black foam with the light side up.
You may trim the panel to size with scissors. You don't want to block the mounting hole or the switch buttons.

Here is a closeup of the FET switch turned on or off by software.
In the corner of
the main CPU
is a solder pad.
That is where
the center of the
FET goes.

With the flat
side up, the left
pin goes to a
ground pad as
shown.
The right pin

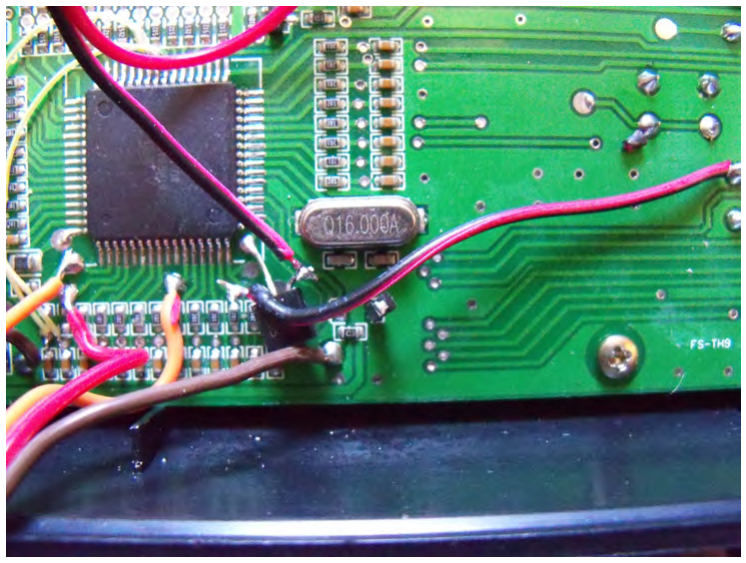
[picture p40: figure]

connects to the NEGITIVE input of the inverter. The positive of the inverter goes to the 12 CDC at the main switch.

The other wires seen are for the programming plug.

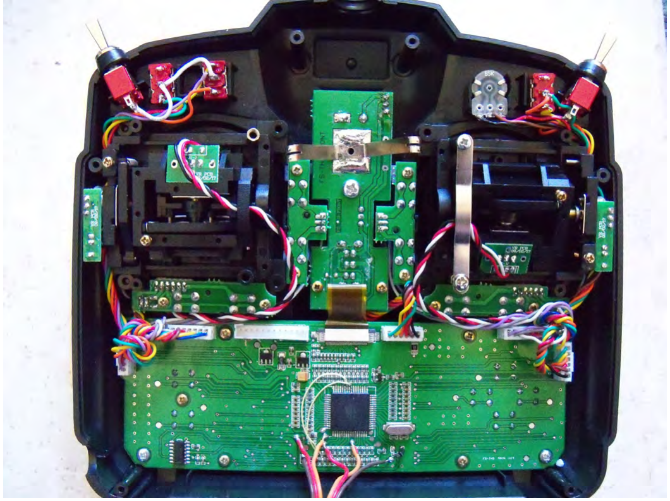
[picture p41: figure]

### Put the panel back in place carefully, covering the

actual LCD fully.

### Remember, the two different screw sizes. I struggled with this until I realized the screws went into the different size holes!

That's it ! Pretty easy.....

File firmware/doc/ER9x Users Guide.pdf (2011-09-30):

# ER9x Manual

### because you asked for it!

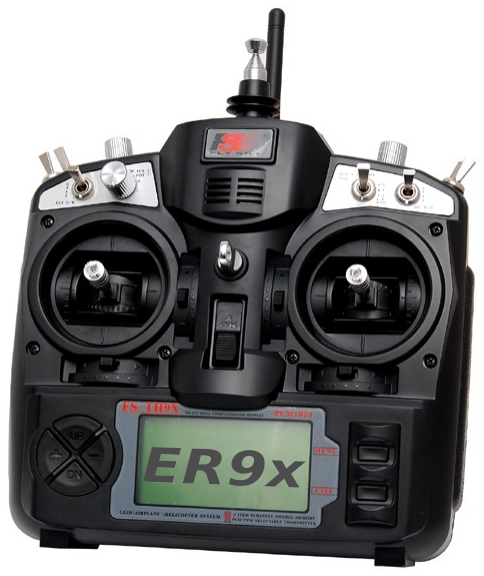
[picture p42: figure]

### r257 - Nov 5, 2010

## Table of Contents

## Disclaimer

### THIS FIRMWARE IS PROVIDED ON AN "AS-IS" BASIS WITHOUT WARRANTY OF ANY KIND AND ANY EXPRESS OR IMPLIED WARRANTIES, INCLUDING, BUT NOT LIMITED TO, THE IMPLIED WARRANTIES OF MERCHANTABILITY AND FITNESS FOR A PARTICULAR PURPOSE ARE DISCLAIMED. IN NO EVENT SHALL THE

DEVELOPER AND/OR AUTHOR BE LIABLE FOR ANY DIRECT, INDIRECT, INCIDENTAL, SPECIAL, EXEMPLARY, OR CONSEQUENTIAL DAMAGES (INCLUDING,

BUT NOT LIMITED TO: PERSONAL AND/OR PROPERTY DAMAGE) HOWEVER CAUSED AND ON ANY THEORY OF LIABILITY, WHETHER IN CONTRACT, STRICT LIABILITY, OR TORT (INCLUDING NEGLIGENCE OR OTHERWISE) ARISING IN ANY WAY OUT OF THE USE OF THIS FIRMWARE, EVEN IF THE DEVELOPER AND/OR AUTHOR. HAS BEEN ADVISED BY USER OF THE POSSIBILITY OF SUCH POTENTIAL LOSS OR DAMAGE. USER AGREES TO HOLD THE DEVELOPER

AND/OR AUTHOR. HARMLESS FROM AND AGAINST ANY AND ALL CLAIMS, LOSSES, LIABILITIES AND EXPENSES.

### Yeah, and no spitting either!

## Introduction

The IMAX/FLYSKY/TURNIGY/EURGLE 9x is a computerized radio from china. The transmitter is outfitted with a 128x64 pixel monochrome LCD, 2-2axis gimbals, 3 variable potentiometers (pots), 6 2-position switches, 1 3-position switch and some funky red trim.

The big thing about this transmitter is the price. At the time of writing radios may cost anywhere from $180 for simple units up to $1000+ for super blinged out bazillion channel super heavyweight monsters.

This one costs $60.

Where's the catch then? (you might ask) The catch is in the software (firmware - FW). The original FW is less-than-perfect. It has bugs, funky navigation and the most annoying beeping I have ever heard. Not good.

However, some neat guy called Thus figured out that the whole radio is made from gimbals, switches, funky trim and a very generic main processing unit that does absolutely everything. He had one of those ah-ha moments where insanity overrides common-sense and decided to completely rewrite the original software and replace it with his own.

At some point I decided that while Thus' FW is great I really wanted more bling for my TX. So in the spirit of open-source Thus' source was stolen and ER9x was born. (Yeah, I was vain. ER are my initials)

You might want to check out Thus' code – it's available here: http://code.google.com/p/th9x/

While you're at it check out RadioClone's code – which also runs on the 9x. While ER9x is based on Thus' code, I have managed to pilfer some of RC's excellent code. His FW is more complex but also more powerful. Check it out here: http://radioclone.org/

Got you all worked up about this? Good. Go now to the kitchen, make yourself a nice cup of coffee. This is a long read. I'll wait here till you're ready. Promise!

How it works

Bear with me here – some flow charts coming up:

Pots

(P1,P2,P3) | Switches Sticks
(RUD,THR,ELE,AIL) | Trims
Calibration | Calibration
| Expo / Dr

MIXER

Limits

Output

What the heck was that?
The system receives 4 types of inputs:
1. Main Sticks
2. Potentiometers
3. Trims
4. Switches

The analog inputs (sticks and pots) go through a calibration phase. The sticks can also go through Expo and Dr filters before going to the mixer.

The mixer does it all. It directs each input to the desired output (CH1..CH16). It controls how the inputs are added. It also controls the timing of each function.

After the inputs are processed by the mixer they are directed to the relevant output channels. The limit procedure takes over and makes sure no output goes too far.

Finally the channels are encoded and sent to the RF module to take that nice little hike through the air to your model.

Nomenclature
(just so we understand each other)

Inputs:
1. RUD – Rudder.
2. ELE – Elevator.
3. THR – Throttle.
4. AIL – Aileron.
5. P1/P2/P3 – Pots.
6. Switches:
1. THR – Throttle cut switch, don't confuse this with the THR stick. The THR switch is located on the back left side.
2. RUD – Rudder Dr switch.
3. ELE – Elevator Dr switch.
4. ID0, ID1, ID2 – Three position switch. These 3 define the 3-position switch. ID0 is the top position, ID1 – mid position and ID2 – bottom position.
5. AIL – Aileron Dr switch.
6. GEA – Gear switch.
7. TRN – Trainer switch. This switch is spring loaded.
8. SW1..SW6 – Custom switches. More on these later.

It should be stated that every function in this FW is assignable. There are no fixed switches. You can choose the TRN switch to be throttle cut and use the triple switch to control Dr. The names are useful since they are labeled like that on the Tx.

Edit buttons
There are 6 edit buttons on the Tx. In this manual they are noted with square brackets ([MENU]). Some functions need the button to be pressed and held for a second or so. The are noted as “long” presses like so: [MENU LONG]

Also since the “+” and “-” keys are placed stupidly in the original Tx I've switched their position. So [+] is actually [-] and vice-versa. This is actually more intuitive than the original (trust me, I've tried using them as is).

Since to upload this FW you need to open up your Tx and do some modifications (which void your non-existent warranty FYI) it is highly recommended you switch between the [+] and [-] keys. It's a simple job, so don't skimp, you'll thank me later.

To avoid confusion with people who modded their keys and all the others I'll refer to the [+] and [-] keys as [LEFT] and [RIGHT] from now on. (I hope that left and right are still universal values – you can never tell today)

The “!” sign. Whenever you see the “!” sign you can read that as “not” or “inverted”. Switches can be “normal” or “inverted”. So when choosing the elevator d/r switch ELE is normal operation and !ELE denotes inverted operation.

Navigation
As a general rule the [UP]/[DOWN]/[LEFT]/[RIGHT] move the cursor appropriately The [MENU] key is used for selection and for editing. The [EXIT] key is used for exiting (surprise). Pressing [EXIT] will generally bring the cursor to the top of the screen. Another press will exit the menu to the main screen. Pressing [EXIT LONG] will exit immediately to the main screen.

Pressing [MENU] from the main screen will take you back to the last menu.

From the main screen you can press [RIGHT LONG] to enter the model setup pages. Pressing [LEFT LONG] will enter the general setup menus.

Once in the menus you can navigate between different screens using the [LEFT]/[RIGHT] keys as long as the cursor is at the top right position of the screen.

Editing and Saving
As a rule once a value is changed it is saved. You can turn off your Tx and turn it back on and the values will be saved. The values are saved internally in the MCU's eeprom. However there is a slight delay sometimes so it's probably a good idea to wait a couple of seconds before turning off.
There is no undo functionality. Once something is erased/changed it's changed for good.

Generally, when a value is highlighted and you cannot move left or right then pressing [LEFT]/ [RIGHT] will change that value.
When moving left or right is possible you need to press [MENU] to edit that value. Edit-mode is displayed by the cursor blinking. To exit edit-mode press either [MENU] or [EXIT].

When editing, pressing both [LEFT] and [RIGHT] simultaneously inverts the value. Try it, it's cool! Also , with r155 and up it is now possible to change values with the P3 pot (the one at the front of the Tx called PIT. TRIM/AUX 2).

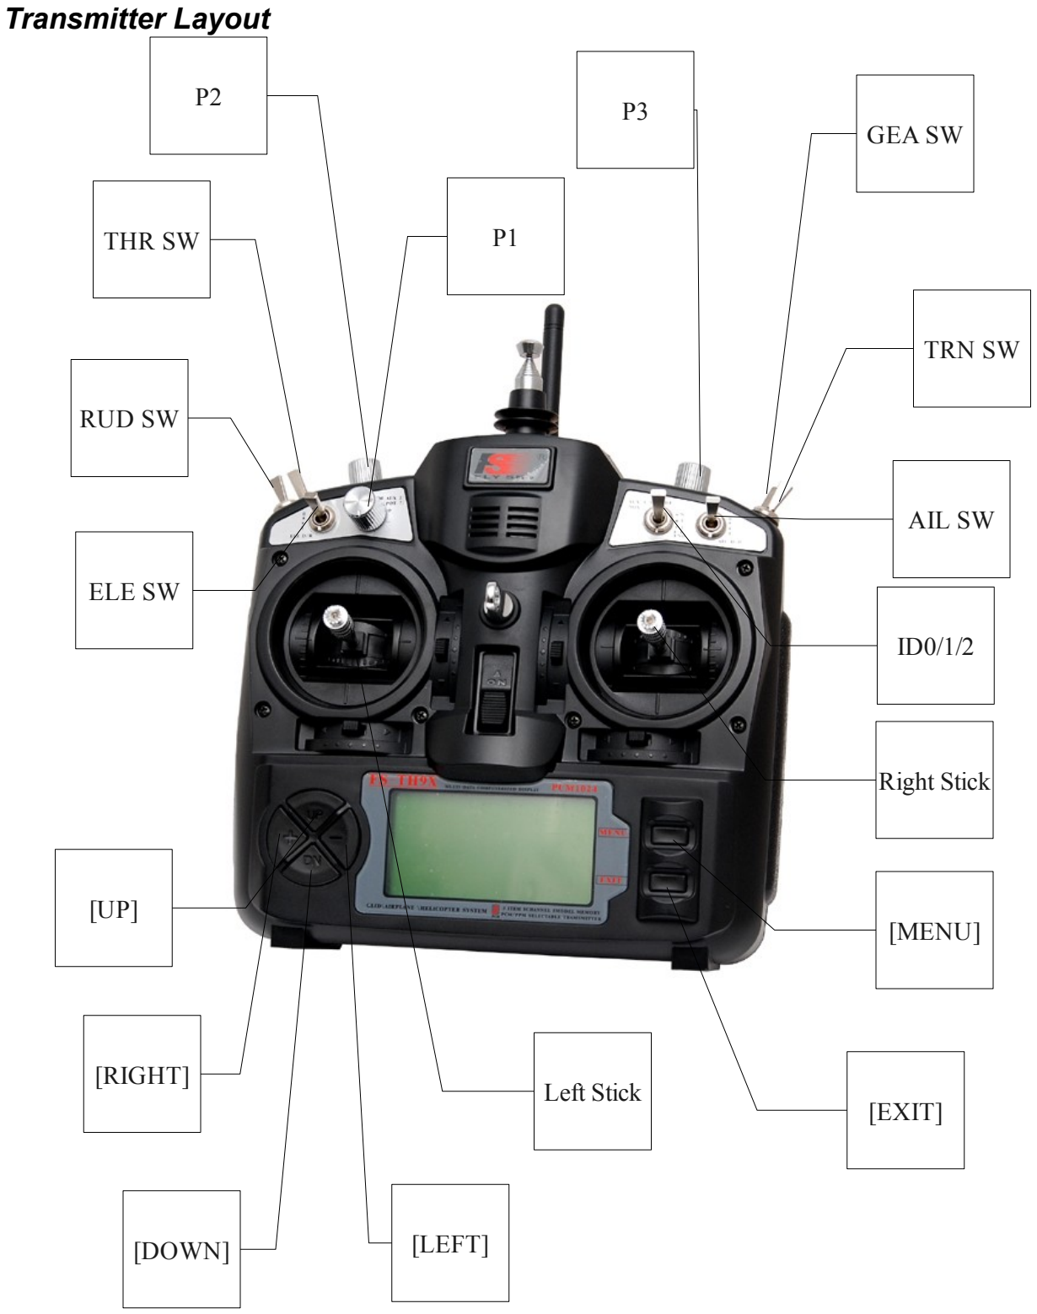
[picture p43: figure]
Transmitter Layout; RUD SW; THR SW; GEA SW; TRN SW; ELE SW; Left Stick; [DOWN]; [LEFT]; [RIGHT]; [EXIT]; [MENU]; Right Stick; AIL SW

## Main Screen

(Cool back light here, huh?)

General view
The main view is split into top and bottom. The top contains the following:
- The current model's name. (GOOFI in this case and yes, it's a real airplane)
- The battery voltage.
- Trim increment information.
- Timer and timer trigger information. Pressing [EXIT LONG] resets the timer.
- Throttle trim activation information.

The bottom consists of three screens. You can flip between these with the [UP]/[DOWN] keys. The 3 screens are:
- Value bars – these show the output values for the first 8 channels.
- Value values – The output values for the first 8 channels.
- Input values – Stick position and switch indicators.

# GOOFI

8.9 15:00

Statistics Screens Statistics Screens

From the main screen pressing [UP LONG]/[DOWN LONG] will enter the statistics screen.

The first shows some available timers and traces the throttle stick as well.

The second shows general timing of the Tx. The value “tmain” shows how long the math takes. This will increase as you add more mixers. It can be very large sometimes depending on eeprom writes. You can reset the timers by pressing [MENU].

## STAT2 tmr 1Lat max 5 us tmr 1Lat min 5 us tmr 1 Jitter 0 us

tmain | 6,31 ms
STAT | 08:02 TOT

## TME 08:02 00:00 TSW STK 00:00 00:00 ST%

## General Settings

From the main screen pressing [LEFT LONG] will enter the general settings menus. Here you can set up settings that will be the same regardless of chosen model.
The menus are as follows:
1. Radio Setup
2. Startup Warnings
3. PPM In Calibration
4. Version Information
5. Diagnostics
6. Analog Inputs
7. Calibration

Radio Setup (1/6)

Use this screen to set up general functions for the Tx:
1. Beeper: Sets Beeping levels
i. Quiet. No beeping at all. No warning – nada. If the kids are sleeping and you must setup the model in your living room this is the mode to use. Just remember that the Tx will not even warn you when the battery is low. If you're using a Lipo watch out!
ii. No keys. The beeps are normal but edit keys are silent.
iii. Normal. Normal beeping.
iv. Long beeps. For those who want to annoy other people.
v. Extra long beeps....
2. Contrast: The LCD's contrast. The values can be 20..45.
The higher the value the darker the screen.
3. Battery warning: Battery voltage warning. When the connected battery's voltage drops below this voltage the Tx will beep. Though the Tx will continue to function normally it's really advisable to land as it is known that this FW was not able to fix the “zero voltage non-functionality” problem of the original.
4. Inactivity alarm: This will set up a warning that will beep if the Tx is left unattended for the specified amount of time.
Values can be from 1 to 250 minutes. To reset the timer simply move one of the sticks.
5. Filter ADC:
i. SING: Single conversion. This is the fastest conversion but base resolution is 1024.
ii. OSMP: Oversampling. This uses extra samples to increase resolution to 2048. Just slightly slower than SING.
iii. FILT: Filtered. This is in case you have excessive noise from the conversion (servo jitters). This will filter the input and prevent that noise. It will, however, increase latency by ~30msec.
6. Throttle reverse: This is for all you wacky people who fly with the throttle backwards (e.i. idle is far from you and full is close to you). Though I personally don't understand how you fly like that it's a nice feature.
The reverse will also reverse the throttle warning on startup and some other throttle related functions.
7. Minute beep: Beeps every full minute while the timer is running.
8. Countdown beep: Beeps at 30, 20, 10, 3, 2 and 1 seconds before the timer ends.
9. Flash on beep: Flashes the backlight on timer beeps.
RADIO SETUP | 1/6
Beeper | Quiet
Contrast | 25
BAT Warning | 9,0v
Inactivity Alarm | 0m
Filter ADC | SING

## Mode ↔☼ ↕☼ ☼↕ ☼↔ 2 RUD THR ELE AIL

10. Light switch: This chooses a switch which can be used to turn on a backlight if connected.
11. Light off after: When this is not OFF any keypress will turn on the backlight and turn it off after the specified number of seconds.
12. Splash screen: Show the logo on radio startup.
13. Throttle warning: If ON will show a warning when throttle is not at idle when the Tx is turned on. The Tx will not output a signal until the alert is cleared.
14. Switch warning: If ON will show a warning when the switches are not at the default position when the Tx is turned on. The Tx will not output a signal until the alert is cleared.
15. Memory warning: If ON will show a warning when the available eeprom memory is less than 200 bytes when the Tx is turned on. The Tx will not output a signal until the alert is cleared.
16. Alarm warning: This will give you a “heads up” if your beeper is silent. If on and the beeper is set to '0' (Quiet) you will receive a warning on startup. This has been added after a programing session left a user flying on silent. I find it really useful!
17. Mode: Choose between MODE1, MODE2, MODE3 and MODE4.

PPM In (2/6)

This menu allows you to calibrate the mid point for the input PPM channels.
Highlighting “Cal” and pressing [MENU] will calibrate the mid point for all PPM IN channels. PPM IN is read from the signal at the trainer port of the Tx.
The multiplier does as it's name suggests. It multiplies the ppm Input by a set amount. Great for dealing with different tx's whose makers don't know how to encode PPM :-P.

Version Info (3/6)

This screen shows the version information for the current FW: SVN: The SVN name of the current revision.
DATE: Compile date for the current FW.
TIME: Compile time for current FW.
VERS: Version number.

Since ER9x is OPEN SOURCE I try to help out anyone who has problems. Please feel free to open new issues for defects and/or enhancement requests at the project's code page: http://code.google.com/p/er9x/issues/list
Your participation is what helps me makes the FW better (and your donations of-course!). Please use the revision number stated in this screen when you state a problem.
PPMIN | 2/6

## Cal 0,0 0,0 0,0 0,0

| 0,0 0,0 0,0 0,0

## Multiplier 1,0

VERSION | 3/6

## SVN: trunk-r98 VERS: V1.2484-erez DATE: 06.09.2010 TIME: 09:19:32

Diagnostics (4/6)

This menu will help you visualize the current state of the trims, keys and physical switches. Each Key/Switch/Trim is represented. When pressing a key or switch they are highlighted.

Analog Inputs (5/6)

Here you can see the analog inputs in hexadecimal format to save space and annoy you at the same time.
Values range between 0..0x3FF (0..1023).

A1..A4 are the gimbals (sticks).
A5..A7 are the pots.
A8 is battery voltage. You can press [DOWN] and highlight the battery voltage. Pressing [LEFT]/ [RIGHT] will increase and decrease the value and so enable you to calibrate the battery voltage monitor.
DIAG | THR 0 | 4/6
| RUD 0

## Left 0 ELE 0 Right 0 ID1 1 Trim- + Up 0 ID2 0 ↔☼ 0 0 Down 0 AIL 0 ↕☼ 0 0 Exit 0 GEA 0 ☼↕ 0 0 Menu 0 TRN 0 ☼↔ 0 0

ANA A1 0422 | 0 5/6
A2 0347 | 63
A3 0466 | 0
A4 0414 | 0
A5 07EE | -30
A6 0345 | -30
A7 06AE | 80
A8 028B | 8,7v

Calibration (6/6)

This screen allows you to calibrate the analog channels (A1..A7).

The calibration method goes like this:
1. Press [DOWN] → (SetMid)
2. Set Sticks to center. (Including throttle and pots)
3. Press [DOWN] → (SetSpan)
4. Move sticks and pots through full range.
5. Press [DOWN] → (Done) – Values are saved here.
6. Press [DOWN] (Back to top)
The values are calculated when you press [DOWN]. They are saved when you press [DOWN] to (Done). (Works surprisingly well for a cheap Chinese Tx)
CALIBRATION | 7/7
0355<0422 >033F

## SetMid 0200<0414 >0353 SetSpan 0302<0410 >0354 Done 0360<0416 >03E0

03B0<0200 >0344

## 03D0<0233 >03FF 03F0<0268 >03FF

## Model Setup

From the main screen pressing [LEFT RIGHT] will enter the model select/settings menus. Here you can set up settings that model specific.
The menus are as follows:
1. Model Select
2. Model Setup
3. Expo/Dr
4. Mixer (This is the important one)
5. Limits
6. Curves
7. Custom Switches
8. Templates

Model Select (1/8)

In this screen you can see, select, copy and move models between different memory “slots”. I quote the word “slots” because memory management is dynamic. The available memory is displayed at the top of the screen.
Memory usage for each model is displayed on the right. The more complex your model (mixes/curves/options/limits/etc) the more memory it'll take.

The “*” on the left shows the currently loaded model memory.
Pressing [UP]/[DOWN] will move the cursor between different models.

Pressing [MENU] will highlight the model. Pressing [UP]/[DOWN] with the model highlighted will move it up/down. Pressing [EXIT] will un-highlight the model.

Pressing [EXIT] will load the highlighted model.
Pressing [EXIT LONG] will load and exit to the main screen.
Pressing [MENU LONG] or [RIGHT LONG] will load the model and go to the next screen (Model Setup).

## MODELSEL free 1560 1/8

*01 GOOFI | 114
02 YAK 55 | 60
03
04
05
06

Model Setup (2/8)

Lots of options here:
1. Name: Unsurprisingly here you edit the model's name. To edit: scroll down until the name is highlighted and press [MENU].
Once your press [MENU] only one letter will remain highlighted. To change the letter you press [UP]/[DOWN]. To move the cursor press [RIGHT]/[LEFT].
Once done, press [MENU]/[EXIT] to exit the edit.
2. Timer: Here you set the value for the timer.
Press [RIGHT]/[LEFT] to choose between minutes and seconds.
Press [MENU] and the cursor will blink. To edit use the [UP]/[DOWN]/[RIGHT]/[LEFT] buttons and [MENU]/[EXIT] when done.
3. Trigger: Choose what triggers the timer → (remember – by pressing [LEFT] you'll see the same values with the “!” sign. This means that the usage is inverted)
1. OFF – timer is off.
2. ABS – timer is on.
3. RUs/RU%/ELs/EL%/THs/TH%/ALs/AL% - chooses to activate the timer based on stick position. When a XXs is selected (THs for example) The timer starts whenever the stick is not at zero.
The XX% sign is the same except the timer speed is determined by stick position. When at zero, the timer is stopped. When at full the timer goes at normal speed. When midway the timer's speed reflects the sticks position.
4. Switches – You can specify a switch so whenever that switch is activated the timer counts.
5. Momentary switches. A switch denoted with “m” (like TRNm) means “momentary”. That means that moving the switch once to the on position and back turns the timer on. Moving it on and off again turns the timer off. (difficult I know, take a sip from your coffee, relax a bit, take a break – it's not difficult once you try it out :) )
4. Timer: Here you can choose whether the timer counts up or down.
5. T-Trim: Throttle trim. This is a nifty feature for power fliers. When activated a couple of things happen. First off the center detent for the throttle trim is removed. Also the throttle's trim will now only affect the “low” side. That means you can use the trim for setting idle while full throttle remains unchanged.
6. T-Expo: 'nother throttle related function. This one makes the throttle stick's expo go from zero to full instead of having a center like all the others. Always the odd kid out this throttle is.
7. Trim Inc: Trim increments:
SETUP 01 | 2/8
Name | GOOFI
Timer | 15:00
Trigger | Ths
Timer | Count Down
T-Trim | ON
T-Expo | ON
Trim Inc | Medium

1. Exp – Exponential. With this the trims are fine near the center and get progressively coarser farther out.
2. ExFine – Extra fine – 1 step per click.
3. Fine – 2 steps per click.
4. Medium (my personal favorite) – 4 steps per click.
5. Coarse – 8 steps per click.
8. Trim Sw: Neat little function this is. When in flight if this key is activated it reads the current position of the sticks and trims and copies that into the subtrims. After that it zeros the trims. This is really neat for new models when you might have a hard time taking your hands off the stick and pressing the trims. Simply hold the plane level with the sticks and press the selected trim switch. Voilà – the plane is trimmed. It's magic! No it ain't. It's ER9x!!!
9. Beep Cnt: Beep Center. Here you set center warnings. The string RETA123 corresponds to: RUD, ELE, THR, AIL, P1, P2, P3.
When the letter corresponding to the analog channel is highlighted the system checks for center. When the input is at center a short beep will sound enabling you to hear when the input is centered. This is useful for checking the center of the pots without looking.
10. Proto: encoding protocol
1. PPM – with ppm you can choose how many channels to encode. Anything from 4 to 16 channels. You can also change the pulse spacing. This is useful for systems which might experience jitter. On the whole it might be a good idea to leave it alone.
2. Other protocols include Silver A/B/C and TRAC09.
11. Shift Sel: Shift select. POS/NEG. Select signal shift. POSitive or NEGative.
12. DELETE MODEL [MENU]: Guess....
This deletes the current model. You need to press [MENU LONG] for that to happen though.

WARNING!
Deleting a model causes the memory to jump to the previous model memory in the list. Do not delete a model memory while you have a model "listening". Always shut down your receiver before deleting a model.
(This all sounds perfectly reasonable until you actually forget to turn off you electric model and have it fly around your house uncontrolled – you've been warned!)

Expo/Dr (3/8)

This screen allows you to enter and edit Expo and D/R values for the main controls (RUD/ELE/THR/AIL).

For each control you can input values for Left/Right for both Expo and D/R. To edit expo values highlight the value in the “expo” column and press [MENU]. Once the cursor blinks you can use the [UP]/[DOWN]/[LEFT]/[RIGHT] buttons to change the value. Notice that while there is a telltale that shows you which side of travel you are adjusting:
- "-”: This means both left and right values are equal. Pressing [UP]/[DOWN]/[LEFT]/[RIGHT] will change both values simultaneously.
- "←”, “→” : When moving the stick you can see either of these symbols. When this symbol is visible you are only changing that side of travel.

For each control you can set 2 switches. The main switch changes between high rate/high expo and mid rate. If the main switch is “low” (e.i. mid rate) the second switch can switch between mid and low rate.
At the end of each line there's a telltale that shows you which rate you are on:
- H: High.
- M: Medium.
- L: Low.

Pressing [MENU LONG] while the cursor is on a control will take you to the Edit Expo/Dr screen. In this screen you can adjust the values for that single control. You will also see a graph indicating the action of that control. Press [EXIT] to return to the main Expo/Dr screen.
Triple Dr Example
The "F.Mode" switch can be used as a triple rate switch for any one axis, or it can be used as a triple rate flight mode switch, controlling rates and expos for some or all of the flight axes at once. To use it as a triple rate/flight mode switch, set sw1 to "!ID2" and sw2 to "!ID1" If you want rudder, elevator, and aileron all assigned to this switch for flight modes, be sure to set sw1 and sw2 as above for each axis. With the switch in the up position, it will be at low rate, as indicated by the "L" at the end of the line. In the mid position, it will be mid rate, and at the down position, it will be at high rate. You can also include throttle if you'd like, to have different expo curves for each of the flight modes.
EXPO/DR | | 3/8
exp | % | sw1 sw2
RUD | 0 100 - --- --- H

## THR 50 100 - --- --- H

ELE | 0 100 - --- --- H
AIL | 0 100 - --- --- H

Mixer (4/8)
I'm actually writing this last since it's the most important menu. If you're still awake now would be a good time to sip that coffee and wake up. You want to understand ER9x? Understand the mixer and you're very nearly there.

The function of the mixer is to take the inputs, perform some function on them and route them to the output channels. Since selection is totally free you have a very flexible system which is extremely powerful and very quick to boot.

Main Screen
When you enter the screen for the first time you'll probably see a list like so:

What this is telling you is that the rudder stick's input is being routed with a weight of 100% to CH1. Same for the elevator, throttle and aileron. Though not visible now you can also see the switch column which will tell you if a switch is assigned to the mix and also a crv (curve) column which tells you what curve is applied to that mix.

When you scroll down you'll see that sometimes the weight is being highlighted and sometimes the channel's number is underlined. When the weight is highlighted, pressing [LEFT]/[RIGHT] will edit that value and pressing [MENU LONG] will enter the Edit Mix screen and allow you to edit that mix. When the channel's number is underlined, pressing [MENU LONG] will insert a new mix for that channel and take you to the edit mix screen for it.

You can also press [MENU]. This will highlight the mix. Then you can press [UP]/[DOWN] to move or copy the mix. Notice that moving or copying is decided by whether you press up or down on the first press after highlighting the mix. If you first try to move it down it will be copied. Subsequent presses of [UP]/[DOWN] will move the copy up or down until you press [MENU] or [EXIT]. Pressing [UP] will move the mix without copying it. Again, subsequent presses of [UP]/[DOWN] will move the copy up or down until you press [MENU] or [EXIT].

MIXER | 4/8 wt src sw crv

## CH1 100% RUD CH2 100% ELE CH3 100% THR CH4 100% AIL

CH5
CH6

Edit Mix

In this screen you edit individual mixes.
Here are the available options for each mix:
1. Source: This is the input for the mix. It can be the following:
i. Stick or pot: Self explanatory.
ii. MAX: The output is either 0 or the value describes in “weight”. This is controlled by the switch.
iii. FULL: Same as MAX but the value is “-weight” if the switch is off or “weight” if the switch is on.
MAX and FULL can be a little confusing. Look in the examples section for, well, examples :).
iv. PPM1..PPM8: PPM input channels. These are fed by the ppm input or “trainer port”. You can use these to configure a buddy system or to simply extend your radio with more functions (like head tracking for you FPV guys).
v. CH1..CH16: These are the outputs of the other mixes. You can use these to chain mixes for very complex behavior.
2. Weight: This value multiplies the value from the input. It can be -125% to 125%.
3. Offset: This value is added to the value from the input. It can be -125% to 125%.
4. Trim: When this is “ON” the trim value (if exists) will be carried on through the mix. When “OFF” it is ignored.
5. Curves:
i. x>0: The value of the source is carried through only if it is positive (greater than zero). Otherwise it is zero.
ii. x<0: Same but for negative values.
iii. |x|: The value is passed as an absolute value.
iv. f>0: If source is positive then the output value is “+weight” otherwise it is 0.
v. f<0: If source is negative then the output value is “-weight” otherwise it is 0.

## EDIT MIX CH1 Source RUD Weight 100 Offset 0 Trim ON Curves c1 Switch ---Warning OFF

vi. |f|: Output is either “+weight” or “-weight” depending on the sign of the source.
vii. c1..c16: custom curves. These are defined in the “CURVES (6/8)” screen. You can also press [MENU] to edit the curve directly.
6. Switch: Here you select the switch that operates the mix. If the switch is not selected then the mix is on by default.
7. Warning: Here you can select an audible warning that will sound whenever a mix is active. (This will only work when a switch is defined). You have an option of 1, 2 or 3 beeps. The warnings will sound in succession so you can hear them individually.
8. Multpx: This value defines how the mix will be added to the channel.
i. Add: This is the default value. With this value the mix is added to the previous values in the same channel.
ii. Multiply: Use this to multiply the previous values in the same channel.
iii. Replace: This value is used in conjunction with a switch. When the switch is off the value is ignored. When the switch is on the value discards the previous values and places it's own value in the channel.
9. Delay Down/Up: Use this to delay use of this channel. Usually used with a switch. When the switch is turned “ON” or “OFF” the mixer will wait the specified number of seconds before changing the value.
10. Slow Down/Up: Slow the rate of change in the channel. When not zero these will determine the maximum speed with which the value can change. The specified value is the number of seconds to go between -100% to 100%.
11. DELETE MIX [MENU]: Pressing [MENU LONG] here will delete the mix and return to the main mix screen.

Limits (5/8)

This is probably the second most important menu.
The limits operate on the output channels (as you can see from the flow chart in the introduction). In the LIMITS menu you can set the center point (subtrim), limits (both left and right) and reverse the channel's output (inv – invert).

Each channel here corresponds to a channel in your receiver. The limits you set will be used on that channel only.

Columns:
1. subT: SubTrim. This sets the channel's center point.
HINT: The values of subT can be -100 to 100 with increments of 0.1. This is done so to have excellent resolution when setting the center of each surface. You can use your stick to set the center point as well. While the subT is highlighted hold the stick so that the surface is centered. Press [MENU LONG] and the position will be recorded! It's the magic of ER9x again :).
2. Min/Max: These set the endpoints of the channel. Notice that there's a telltale that hints as to which side is active at the moment. Each limit point can range between -100% to 100%.
The limits act both as gains and as absolute limits. The servo will not go beyond the limits you set here.
3. inv: Invert. This function reverses the output of the channel.
LIMITS | 5/8

## subT min max inv

CH1 -5,9 -100→ 100 ---
CH2 | 0,7 -100→ 100 INV
CH3 | 0,0 -95 ← 40 ---

## CH4 -14,4 -100→ 100 INV CH5 45,9 -100→ 100 INV

CH6 0,0 -100→ 100 ---

Curves (6/8)

Surprisingly in this menu you set your custom curves. Curves are nifty things that can tell your servo how to move when you move your stick. In ER9x there are 8 5-point curves and 8 9-point curves.

A 5pt curve is a curve you can edit at position -100%, -50%, 0%, 50%, 100%.
A 9pt curve is a curve you can edit at position -100%, -75%, -50%, -25%, 0%, 25%, 50%, 75%, 100%.

When you enter the menu you see a long list of zeros. Scroll down to the curve you wish to modify and press [MENU] or [RIGHT]. This will bring up the screen for editing the curve. Depending on whether you chose a 5pt or a 9pt curve you will see 5 or 9 editable points. Scroll through the points with [UP]/[DOWN]. Change the value with [LEFT]/[RIGHT].
At the bottom you will see a “preset” entry. Pressing [LEFT]/[RIGHT] on that will populate the values with a linear curve that is a good starting point.

You can also change the curve graphically. Highlight the “EDIT->” line and press [RIGHT]. This will highlight the curve points. Pressing [UP]/[DOWN] will change the values and pressing [LEFT]/ [RIGHT] will select a different curve point.

CURVE | | | | 6/8
CV1 -75 -40 0 45 75
CV2 | 0 | 0 0 | 0 | 0
CV3 | 0 | 0 0 | 0 | 0
CV4 | 0 | 0 0 | 0 | 0
CV5 | 0 | 0 0 | 0 | 0
CV6 | 0 | 0 0 | 0 | 0
CV7 | 0 | 0 0 | 0 | 0

Custom Switches (7/8)

I really like this feature.
Custom switches are not really switches at all but rather a set of logical conditions that can be used as switches.

You might have noticed that beyond the physical switches there are 6 switches called SW1..SW6. These correspond to the list you see in this screen. Once the condition defined for the switch is met it's value will be “ON”.

1. First we define the condition. This can be v>offset, v<offset, |v|>offset and |v|<offset, or it can be a logical condition: AND, OR, XOR, or it can be an evaluation between 2 sources.
2. If you've selected a regular condition you need to specify a source and an offset:
1. The source can be a stick, a pot, a PPM input or an output channel.
2. An offset can be anywhere between -100 and 100. This will be the test point for the condition.
3. If you've selected a logical condition the switch results the condition applied to the 2 selected switches.
For example: OR ID1 ID2 will be “ON” if either ID1 or ID2 is on. Cool, huh?
4. If you've selected an evaluation you (“==”, “>”, “<” etc...) you need to select the 2 sources to evaluate between.
For example: Switch on only if CH1 is less than RUD → V1<V2 CH1 RUD

Example:
Say you have a glow plug driver which you want to turn on when the throttle is below 10%:
1. Highlight SW1
2. Select the source as THR.
3. Select the offset as -80 (remember -100 – 100 so 10% from idle is -80).
4. Select the condition as v<ofs.

Now you need to use a mix to run the switch. Go to the mixer menu. Select the CH8 as the channel you want the GP driver to operate on. On that channel select source as “MAX” and Switch as “SW1”. Now whenever the throttle goes below 10%, CH8 will go to 100%. Cool, huh?

CSWITCH | 7/8

## Function V1 V2

01 v<ofs | -60 THR
02 AND | ID0 ID1
03 ---- | 0 ----
04 ---- | 0 ----
05 ---- | 0 ----
06 ---- | 0 ----

Templates (8/8)

The templates are there to help you get started. When entering the screen you'll see a list of available templates. To choose a template, scroll down to it and press [MEU LONG]. This will add the template to the existing mixes.

Channel order:
This will allow you to set the way the templates are written to the mixers. RETA means RUD = 1, ELE = 2, THR = 3, AIL = 4.
AETR means AIL = 1, ELE = 2, THR =3, RUD = 4.
(and so forth).

At the bottom you'll see an option called “CLEAR MIXES [MENU]”. Pressing [MENU LONG] on this will clear all the mixes leaving you with a clean slate.

The templates are:
1. Simple 4-CH: Plain vanilla 4-ch airplane.
2. T-Cut: This adds a throttle cut mix on your throttle channel.
3. V-Tail.
4. Elevon\Delta.
5. ECCPM; A generic ECCPM mix.
6. Heli Setup: This will clear your mixes and curves and setup a preliminary eCCPM heli.
7. Servo Test: This will setup a servo test output on CH15.
To test your servos choose the mixer's source as CH15. It will cycle slowly between -100 and 100.
TEMPLATES | 8/8

## 01 Simple 4-ch 02 T-Cut 03 V-Tail 04 Elevon\Delta 05 eCCPM Channel Order RETA CLEAR MIXES [MENU]

## Examples

Programming a throttle cut
Though you can use a template for this it's instructional to do it via the mixer. Start off with the default 4 mixes.
Scroll down until CH3 is underlined, like this:

Press [MENU LONG] to enter the “Insert/Edit Mix” screen.

Change source to “MAX” and Weight to “-100”. Also set the Switch to THR.Like so:

MIXER | 4/8 wt src sw crv

## CH1 100% RUD CH2 100% ELE CH3 100% THR CH4 100% AIL

CH5
CH6

## EDIT MIX CH3 Source ELE Weight 100 Offset 0 Trim ON Curves ---Switch ---Warning OFF

## EDIT MIX CH3 Source MAX Weight -100 Offset 0 Trim ON Curves ---Switch THR Warning OFF

Keep on scrolling down until you reach Multpx. Change the value to “Replace”

Now press [EXIT]
You should see the following screen:

What it tells you is that on CH3 you have 2 mixes defined.
The first takes the value of the throttle stick. The second depends on the THR switch. When the switch is off the mix is ignored so the only value will be the value of the throttle stick. When the switch is on that value will be replaced with -100%.

## EDIT MIX CH3 Weight -100 Offset 0 Trim ON Curves ---Switch THR Warning OFF Multpx Replace

MIXER | 4/8 wt src sw crv

## CH1 100% RUD CH2 100% ELE CH3 100% THR R-100% MAX THR CH4 100% AIL

CH5

## Build and Program Instructions

You might want to play with the code and modify it for your own needs. It's really easy if you know a little C.

First, to program the MCU, download the full programing instructions:
Flashing the 9x (http://er9x.googlecode.com/files/Flashing%20the%209x.pdf) by Jon Lowe.

Building from Source

First checkout using svn: svn checkout http://er9x.googlecode.com/svn/trunk/ er9x Enter the src/ directory.
To make the standard version type: make
To make the JETI DUPLEX enabled version type: make EXT=JETI

Flashing
(you may have to run as admin to access the USB port in Linux)
To write the FW: make wflash AVRDUDE_PROGRAMMER=usbasp
To write the EEPROM: make weeprom AVRDUDE_PROGRAMMER=usbasp
To read FW: make rflash AVRDUDE_PROGRAMMER=usbasp TARGET=backupflash
To read the EEPROM: make reeprom AVRDUDE_PROGRAMMER=usbasp TARGET=backupeeprom

Make sure you replace "usbasp" with the name of your programmer.
To list available programmers type: avrdude -c ?

make targets
- make all (default): build the source
- make clean: Remove compiled files and directories.
- make wflash: Write flash (program) memory.
- make rflash: Read flash memory.
- make weeprom: Write eeprom.
- make reeprom: Read eeprom.
- make coff: Convert ELF to AVR COFF.
- make extcoff: Convert ELF to AVR Extended COFF.
- make debug: Start either simulavr or avarice as specified for debugging, with avr-gdb or avr-insight as the front end for debugging. (for debug info look into the makefile)
- make filename.s: Just compile filename.c into the assembler code only.

make options
- EXT=JETI: make jeti vesion.
- AVRDUDE_PROGRAMMER: Set avr programmer name - default: usbasp (to list all available: avrdude -c ?)
- TARGET: Set target name - default: er9x
- OPT: Set optimization level - default: s
- FORMAT: Set format (can be srec, ihex, binary) - default: ihex
- MCU: Set MCU - default: atmega64

## MORE

I sincerely hope you enjoy both the ER9x FW and this manual.
I also sincerely hope you're still awake. If you are I applaud you :)

This is an Open Source project. It means that I request no money for it. You are free to look up, download, modify and release the code under the GNU v2 software license.

If you have any questions, requests and/or gaudy compliments I'll be happy to hear them either on the FW's code page:
http://code.google.com/p/er9x/

Or on the following threads in RCG or RCModelReviews: http://www.rcgroups.com/forums/showthread.php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

Also bug reports and enhancement requests can be reported here: http://code.google.com/p/er9x/issues/list

eePe and er9x are free to use under the GNU v2.0 License. Feel free to use, copy and modify it as you wish! I have spent a lot of time (and will continue to) to make this software as good as possible. If you feel that this software has been beneficial to you please show your support by donating 5$USD. This will be greatly appreciated and you'll be added to the "contributors" list in the code (optional of-course).

If you feel you'd like to contribute time, software code, documentation, tutorials, examples and/or money (I like money :) Please feel free to email me at: erez.raviv@gmail.com

Please tell your friends about this cheapie $60 Chinese Tx. I bet They'll roll their eyes up and tell you to go buy a *real* system. That's o.k. You'll have more money for *real* models!

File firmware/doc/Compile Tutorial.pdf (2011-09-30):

### Simple guide to downloading and compiling firmware files in Windows by Telemachus

(This assumes WINAVR has already been installed)

1) Install Tortoise SVN control from this site:

http://tortoisesvn.net/downloads

2) Restart computer
3) Go to the directory where you want to download files to compile.
4) RIGHT CLICK anywhere in that directory. You will see an action item on the RIGHT CLICK dialog that now says: SVN CHECKOUT.

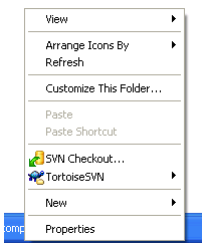
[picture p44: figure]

5) Add the following repository:

http://er9x.googlecode.com/svn/trunk

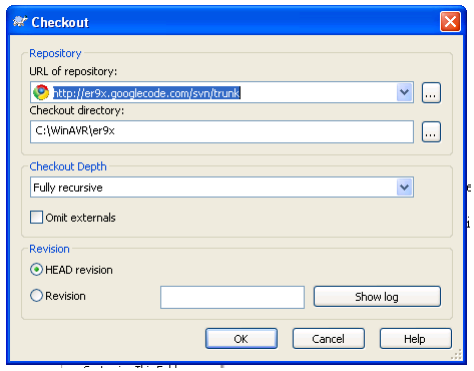
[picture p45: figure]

6) Click “OK” and let it go! It should now create an ER9x directory.
7) Go into that directory and enter the SRC directory.
8) Copy the batch file included in this archive named Compile.bat to this directory, or if you would rather, create a .bat file with just the word MAKE inside of it.
9) Click on the “Compile” icon and it will make your firmware. The appropriate .hex file will be in the SRC directory as a .hex file.
10) When you want to newest release, follow steps 4, 5 and 9 again and it will download and compile the newest version for you.

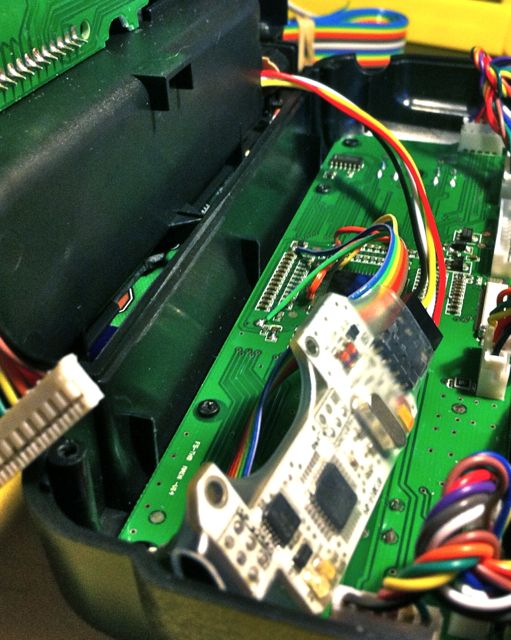
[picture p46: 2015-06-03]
wiki/GProg.attach/gprog-stock-installation.jpg

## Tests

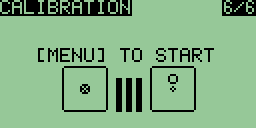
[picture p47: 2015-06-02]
wiki/Features.attach/calibration_01.png

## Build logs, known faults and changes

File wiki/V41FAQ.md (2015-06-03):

# Custom Board v4.x FAQ #
<b>F</b>requently <b>A</b>sked <b>Q</b>uestions

## G9X v4.x BOARD DISCONTINUED but still fully supported ##

See the [project home page](http://gruvin9x.googlecode.com) for details. More also at the online store [product page](http://gruvin9x.com/shop/gruvin9x/22-gruvin9x-v41-pcb-fully-assembled.html).

---

There is NO PARTICULAR ORDER to this list. **Please read the entire Q and A to get all required information**. If you can't find what you need, either contact Gruvin personally (via Google Code links elsewhere or the [gruvin9x.com](http://gruvin9x.com) contact form) or make a post a question at [9xforums.com](http://9xforums.com). Thanks.

---

**Q**. How do I install my new v4 board?

**A**. General installation is fairly simple. The approximate steps are ...

  1. **Always observe anti-static precautions with electronic parts.**
  1. Remove the six screws from the transmitter casing and split the two halves.
  1. Unplug the wire loom connecting the rear half of the casing to the front
  1. Unplug all of the white (JST) connectors from the stock controller board
  1. **CAREFULLY** unlock the LCD ribbon cable socket by pushing the locking clip (usually black or brown, plastic) away from the board, one end at a time, with a small screwdriver. **BE ESPECIALLY CAREFUL** to operate the tool such that no movement greater than a millimetre (1/16 inch) or so can happen at any time, just in case the clip suddenly gives way. (It is quite easy to break the clip if that occurs.) DO NOT wedge a tool between the main body of the socket and the lock or you'll almost certainly break a clip off the end of the socket.
  1. Remove the nine screws that hold the board into the transmitter casing. Do this with the casing laid out flat on a soft piece of foam or similar, because the LCD screen beneath the board is secured in place only by the main controller board itself -- you do not want it falling out. Place the removed, stock board to one side.
  1. Check that the two front panel buttons to ensure they are properly seated. These are on your left, assuming the bottom of the casing is facing you. The other set of four buttons are held in place by two screws, so nothing should be required there.
  1. Install a previously prepared LED back-light and stick the foam spacer pad to your new v4 controller board, using the white rectangle drawn on the back as a placement guide -- OR -- if you are not installing an LED back-light, you will need to somehow arrange a 6mm thick, SOFT foam spacer pad. IT MUST BE SOFT, to allow easy compression over its entire area. Use the foam on the stock board as a guide. Colour of the foam is not too important, though black is probably best. (It is possible, with a sharp, rounded-end hobby knife, considerable patience and care, to remove the padding from the stock board and transfer it to the new board. At a pinch, several small foam pieces stuck in the corners, center and long-side mid-points will suffice.) You can also (mostly) avoid this entire problem by simply hot-gluing the LCD glass panel into place at its four corners. I do this with the LCD back-light, since it saves a bunch of hassle.
  1. Carefully lower the new board into place, painstakingly moving all the connector plugs out of the way as you go. You will need to do this whilst keeping the board fairly horizontal, in order to have the push-buttons line up with the front panel button inserts. In practice, you can more or less just drop the board rough in place, then move it about side to side to get the buttons to drop into place.
  1. BEFORE PUTTING ANY SCREWS IN ... hold the board firmly in place with one hand and check for proper mechanical operation of all six front panel push-buttons. (You will need to move your grip to over the appropriate buttons as you test each side. Careful -- those pins can draw blood! :P) If one or more buttons do not operate freely, with a definite 'click clack' action, then you might need to check their PCB alignment (home made board) or file down the black button stalks slightly. (All assembled v4 boards from the gruinv9x.com store have already been installed and adjusted in this regard. However, your casing or PCB mounting hole alignment may differ slightly.)
  1. Re-install the nine PCB mounting screws, noting that the four larger screws go in the four extreme corners. DO NOT OVER TIGHTEN. Just snug and a micro-nip more is sufficient.
  1. Double check proper mechanical 'click-click' of all six front panel buttons before continuing. If there's a problem, remove the nine screws and take action to remedy the problem.
  1. Plug in the several white JST connector plugs, leaving the loom from the rear-casing and the LCD ribbon cable, for now.
  1. Open the LCD socket lock and insert the LCD ribbon cable. This could be a little tricky. GENTLE use of a pair of tweezers, acting in small increments on each side of the cable, usually gets the job done. (DO NOT TOUCH the exposed LCD ribbon cable contacts for ANY reason with your fingers!) Once the cable is fully inserted, use either your index finger and thumb on one side and tweezers or _small_ pliers on the other -- or two pairs of tweezers -- to clamp the LCD socket's lock tightly closed. This action requires a delicate balance of force and patience. For newer sockets, you might need to work in smaller increments, one side at a time, so as to reduce total force required and thus avoid breaking something.
  1. If installed, connect the LED back-light 3-pin JST plug to the LED B/L socket in the upper right of the board. BE VERY CAREFUL to ensure that the left hand pin is NOT connected to anything here. Only the center (Gnd) and right (+5 current limited) pins are used.
  1. Hold the rear casing over the front casing, somewhat to the left, off center to give enough working slack on the wire loom, allowing it to be firmly plugged back into the 12 pin JST socket.
  1. Align the two halves of the casing, lock them together and set about re-installing the six case screws, which are all the same size.
  1. Take a moment to admire your fine work -- and how nothing seems different, from the outside. SUCCESS!

---

**Q**. **What CAD software did you use for the board design?**

**A**. [KiCAD](http://en.wikipedia.org/wiki/KiCad) (wikipedia link).

---

**Q**. **Why KiCAD' and not the ever popular Cadsoft Eagle suite?**

**A**. Apart from actually liking KiCAD, this is an open and more importantly FREE for ALL project. KiCAD does everything we need and is free and open source. Eagle on the other hand, demands a hugely expensive (minimum USD$1,145 ATOW) "Pro" license for boards of this size and complexity. So really, it's a no-brainer. Eagle is of no practical use to us what-so-ever.

KiCAD was chosen over another alternative because we (well, gruvin) found that it is easy to download and install on both Linux and Windows (the latter still being the most commonly used platform, for who on Earth knows why, right? :P)

---

**Q**. How do I get a local copy of the PCB design files?

**A**. Install [Subversion](http://subversion.apache.org/), then "check out" (download) the entire pcb-v4.1-frozen directory.

Instructions for doing that (command line version) are on the standard Google "Source" page (see menu, above.) You'll need to change the source path though, as follows.

**For the v4.1(a) files** ...
```
    svn checkout https://gruvin9x.googlecode.com/svn/archive/pcb-v4.1a-frozen g9x-pcb-v4.1
```

That will create a directory named `g9x-pcb-v4.1/`, containing all the files and subdirectories. You can of course use whatever folder name you please. Various bill-of-materials (BOM) files can be found in the `assembly/` sub-folder.

**For the v4.2 files** ...
```
    svn checkout https://gruvin9x.googlecode.com/svn/archive/pcb-v4.2-frozen g9x-pcb-v4.2
```

The RTC/SD-card and prototype receiver multiplexer files are not included in the v4.2 archive, for some unknown reason. Please refer to `/trunk/hardwardware/pcb` in the meantime. The BOM files were also moved to the main PCB directory.

---

**Q**. Where do I find v4.1 board construction tips and advice?

**A**. There's a separate [Build Your Own Board](PcbAssembly.md) wiki page for that, [here](PcbAssembly.md). What follows in this FAQ is more aimed at completed v4.1 boards, being installed into a '9X transmitter housing.

---

**Q**. The JST PH connectors are fiddly to make! Is there an easier way?

**A**. Yes! We found [this eBay store](http://stores.ebay.com/HobbyMart-Shop/2-0-PH-Connector-/_i.html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), which has ready-made JST 2.0mm connectors (2, 3, 4, 5, 6, 7 and 8 pin) with wires attached and at very good prices.

You can probably find the same products in other eBay store languages / locations. Search for "JST Micro 2.0."

---

**Q**. **How do I connect an LED back-light to connector K5?**

**A**. **VERY CAREFULLY** Seriously. The centre pin is GND and the RIGHT-hand pin (labelled '1') is +ve output power for an LED back-light. It includes a 200 ohm series current limiting resistor, which gives a comfortable and practical brightness on the HobbyKing LED back-light module.

If you need a different brightness, you could use your own series current limiting resistor off the left hand pin (3), which is a switched 5V output, utilising its own dedicated regulator as well as a safety fuse. The regulator is rated at _maximum_ 100mA and fused for safety at 250mA (if it gets fried and shorts out, it shouldn't take out the radio. This has not been tested.)

**CAUTION**: There is no series current limiting resistor on the the left-hand, pin-3!

---

**Q**. **How do I use an electro luminescent (EL) back-light?**

**A**. You will need a [SmartieParts](http://www.smartieparts.com/shop/index.php?main_page=product_info&cPath=3&products_id=333) or equivalent EL driver board, to provide the correct type of power for an electro luminescent (EL) back-light.

There are three terminals labelled 'EL B/lite', in the upper left area of the main board. These were originally designed to allow the SmartieParts EL driver board to be mounted directly over them, using individual header pins as dual-purpose stand-off and electrical connections. The board is placed such that the right-hand three driver board pads are soldered to the header stand-off pins, as viewed with the pads at the top of the board. Clear as mud? ... I'll try to draw it ...
```
+-----------+
| o o o o o |
.     1 2 3 .
.           .
.           .
+-----------+
```
Pads labelled 1, 2 & 3 in the above EL board diagram connect via header pins to the v4.1 main board. The left-hand two pads on the driver board go to the EL back-light itself.

The driver board should sit about **5mm above the main board** -- **not** down on the header-pin insulators -- so that it remains well clear of the MENU/EXIT push button leads sticking up from the board.

Header pins are made of high-tensile metal, so the board should be held quite rigidly in place. If you use some other kind of connecting wire instead, then you may need to use something like thick, double-sided adhesive tape to secure and insulate the EL board -- or simply mount it somewhere else entirely.

---

**Q**. **How should I set jumpers J1 (back-light control) and J4 (Vibrator control)?**

**A**. By default, pins 1 & 2 are shorted together on both J1 and J4. For J1, that's the left hand two pads. For J4, it's the upper two pads.

You may want to refer to the circuit schematic to learn what the other positions might be good for.

---

**Q**. **Why doesn't the internal piezo beeper work?**

**A**. Because open9x firmware currently only supports a 'speaker' (usually a cheap headphone element) connected to the 'Spkr' port on the PCB. This is the 2-pin header, labelled 'Spkr' if the upper center-right area of the PC board.

The factory installed piezo beeper (shrieker in some cases! :p) should work just fine, once code exists to turn it on and off. We're hoping to see this added by the open9x team soon. (Time of writing, 2012-09-04.)

---

**Q**. **What type of 'speaker' element should I use?**

**A**. This one can actually be a bit of a problem, as it turns out.

The first few headphone elements used by Gruvin, over several prototype builds, all produced plenty of audio volume. He thus concluded that this would be the most common case. However since then, we have all (including Gruvin) had difficulty finding new elements that make enough noise. We now realise that Gruvin's junk box contained several seemingly uncommon 24ohm headphone elements, whereas those commonly available new are all 32ohm. Doh.

That said, the 'speaker' element used for the prototype was salvaged from one side of a pair of cheap audio headphones. These are the commonly used, roughly 1-inch (25mm) diameter types, with the clear plastic diaphragm and are to be found in most computer or portable music headphones -- the _outside-your-ear_ type, of course. Some (but not all) of the really cheap versions are _far_ too quiet for our purposes. So be prepared from some experimentation. (Ideally, you will find a 24ohm version. (see above). If you do find a stockist for these, please let gruvin know. Thanks! )

There are also two 200-ohm resistors near the 'Spkr' socket on the v4.x boards. These are wired in parallel, to provide 100-ohms total. The idea here was, somewhat ironically as it turns out, to allow simply removal of one resistor to _reduce_ the volume. Hmmm! In practice,  you'll probably want to short the resistors out with a fine wire link over either one of them, to get maximum sound output.

A long term solution for this is still, 'being formulated' (kicked around, aimlessly?) One solution would be to go back to using the factory supplied piezo beeper -- at least for important alarm sounds -- since the piezo is almost always _much_ louder. We're hoping open9x will add a feature for this, perhaps by way of a menu selectable system, similar to the optional haptic (vibrator) device.

---

**Q**. **How are the rotary encoders supposed to be wired?**

**A**. Viewed from the back of the encoder, the wires going to controller board pin numbers 1, 2, 3 and 4 should look something like this ...

```
  3   2
  | | |
     \
  |   |
  4   1
```

... where the upper-middle terminal is connected to the lower right terminal, as shown. (This is the GND or 0V wire.)

The above wiring will make it such that pushing the top of the encoder knob away from you will increase its value -- the same for both left and right encoders. If you prefer to have the encoders operate in the opposite direction, then swap wires 2 & 3. Might I also suggest wiring as follows, ...
```
  2   3
  | | |
   /
  |   |
  1   4
```
... to keep cable flat, with no twists, should you be using ribbon cable. (It doesn't really matter for individual wires as shown in the images below.)

Here are some images of Cam's nice and tidy installation ...

(Please note that wire colours may differ ... so use the diagrams above as the definitive reference.)

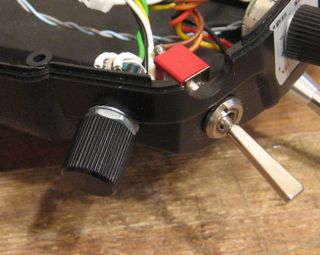
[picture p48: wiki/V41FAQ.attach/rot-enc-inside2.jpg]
|  |
|:---|:---|
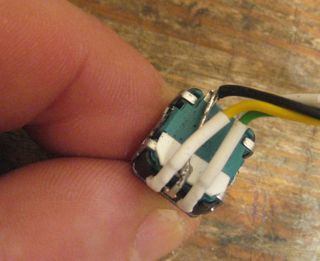
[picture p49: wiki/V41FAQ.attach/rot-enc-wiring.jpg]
|  |

---



**Q**. **How should I install the RTC/SD-card Board?**

**A**. Any way you like, really. But [please see here](SdcardBoard.md) for how Gruvin does it.

---

**Q**. **How to install the gProg board and associated USB socket?**

**A**. The gProg USBasp AVR programmer has its own wiki page, [here](GProg.md).

---

**Q**. **I have a Fr-Sky DHT DIY module. Where are the signals I need?**

**A**. You'll find the most conveniently located GND, BATT+ and PPM connections on the 9X's rear case PCB. Here's an image showing which pin is what ...

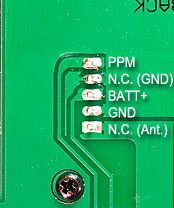
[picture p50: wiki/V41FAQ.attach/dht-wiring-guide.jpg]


Use the 3-pin pseudo-RS232 (left hand one, at the lower right of the G9X board) to connect to GND, Txd and Rxd on the DHT module for telemetry, assuming you have the newer two-way version.

The following images relate to the DJT, external module, but should suffice to add clarity for the DHT as well ...

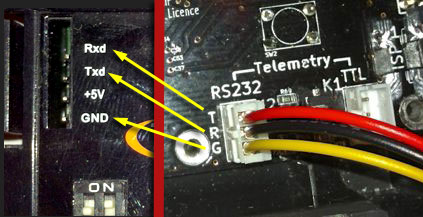
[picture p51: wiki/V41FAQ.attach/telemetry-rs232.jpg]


Gruvin uses an external DJT module, with two wire links added inside, to link pins 2 and 5 of the module socket to _Rxd_ and _Txd_ of the Fr-Sky data port, respectively. Inside the '9X case, on the rear PCB, things look like this ...

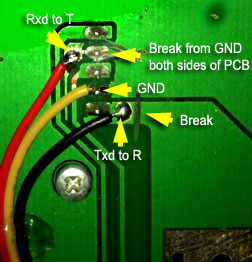
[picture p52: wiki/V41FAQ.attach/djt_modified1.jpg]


**Note that pin 2 has to be broken from the ground plane on this PCB on BOTH sides of the PCB**, as noted in the above image. First, remove the board. On the under-side, where the pins protrude outside the case, temporarily slide the black plastic pin holder bar up the pins (it's quite tight, so ease it a little at a time from each end) then make the break on each side of the pin, then slide the bar back into place and re-fit the board.

**Using TTL** -- others have found the 3.3V TTL lines inside the DJT module and connected to those directly, presumably with something like 1K5 series resistors inline and connect those to the TTL telemetry socket on the G9X main board. I (gruvin) have not tried this, so cannot advise further. Pseudo RS-232 and the method described above, works fine for me.

---

**Q**. **How do I set the v4 board's ATmega2560 MCU option fuses, before the first Flash programming?**

**A**. If you have purchased a ready-made board, the fuses will already be set correctly.

If you have built your own board and assuming you have the cross-compiler environment and project source code installed, along with a `Makefile` set up for your particular AVRDUDE programming device, then you can execute the following command from the `src/` directory ...

> `$ make wfuses`

If you wish to install a pre-compiled .HEX binary firmware version, rather than building from source, you can use AVRDUDE manually to set  MCU fuses, in a similar way to the following ...

> `$ avrdude -c usbasp -P usb -p atmega2560 -U hfuse:w:0x11:m -U lfuse:w:0xd7:m -U efuse:w:0xfc:m`

---

**Q**. **How to fix intermittent power lock-on problem?**

**A**. **This fault was remedied on the v4.2 boards.** For v4.1 board owners, ...

There is a small design flaw in the v4.1 soft-off circuitry that can sometimes cause the radio to lock in the power-on state, after turning off the power switch.

> _This fault can, quite literally, come and go with changes in the weather, moisture levels in the air, local static-electric fields, etc. Thus, not all radios will be affected and some that have been fine for weeks could begin to exhibit the unwanted behaviour later on._

The fix is to solder a 10K resistor across (or on top of) C63, which is located 2 components to the right of the (lower) 3.3V regulator and directly beneath transistor Q9. (Board viewed with LCD screen socket at the "top".)

Note that it is also possible for certain types of system crash to cause this problem. This though is theoretically very unlikely, due to watchdog timer configuration. Never the less, if you have soldered in the new resistor but still have the problem, please let us know.

---

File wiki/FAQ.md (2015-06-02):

# This project has been superseded by [opentx](http://opentx.googlecode.com/) #

The following data is likely obsolete, kept here for mostly just for historical record.

# G9X FAQ #
<b>F</b>requently <b>A</b>sked <b>Q</b>uestions

---

**Q.** **How do I delete a DR/EXPO, MIXER line or model?**

**A.** Click `[MENU]` once on the line/model you want to delete, so that is becomes 'selected', as if you were going to copy or move it. Then, while it is still selected, press `[EXIT LONG]`.

This same procedure should work for deleting lines in all similar menus. In the models menu, you get an 'Are you sure?' type pop-up, for extra safety.

NOTE: You cannot delete the currently active model. (It's a safety feature.)

---

**Q.** **Is there a support forum for gruvin9x?**

**A.** No and there never will be. But there is a [gruvin9x email list](http://groups.google.com/group/gruvin9x-discuss) hosted by Google Groups.

The reason for no forum is that we intend to create a structured,  online help section using the project wiki -- as well as a PDF user manual, which we believe will be hugely more efficient for the intended purpose.

---

**Q.** **Where is the updated PDF user manual for gruvin9x?**

**A.** It's still under development. No time frame for a first edition is yet known.

In the mean time, please refer to this FAQ or consult the members of the gruvin9x Google discussion group (email <i>gruvin9x-discuss</i> `[at]` <i>google</i>`[delete_no_spam]`<i>groups.com</i>) for answers to any mysteries.

As a filler or for different wording on the same topic of how the multiplexing mixer stuff works you could refer to [this forum post](http://www.parkflyers.org.nz/modules/newbb/viewtopic.php?post_id=48056#forumpost48056) (by Gruvin). Skip past the heli-setup part.

---

**Q.** **How do I calibrate the '9X battery voltage reading? It's reading half a volt or more off what it should!**

**A.** Some variance from radio to radio in this respect is normal and to be expected. Just like the sticks and pot's, **you need to calibrate the battery voltage reading**.

On the ANA screen -- in the set-up menus accessed from `[LEFT long]` -- if you press `[DOWN]`, you'll end up at the battery voltage (not labelled so) down the bottom of the screen. You can then adjust the value up and down to have it match what your volt meter says the battery voltage really is.

It's a good idea to take a backup of the EEPROM (which includes this calibration setting) straight away. If you're using eePe or companion9x for model configuration etc, then you should take care to use this most recent backup as the base for all your future EEPROM data. If in doubt later on, get your volt meter out and check the calibration again.

---

**Q.** **How to use the Telemetry A1/2. It's Confusing!**

**A.** Yes, it is confusing. We're working on it, slowly. There's no offset capability however (for going down into negative numbers.)

We intend changing to the simple system currently used by the open9x project, where MaxV etc are replaced by just two fields, "Range" and "Offset".

So for example, if you had a gadget that converts Km/h wind speed over a range of zero to 100Km/hr, to a voltage between 0V and 3.3V, then you'd simply set the range to 100 and offset to 0.

Another example could be temperature, where the sensor might out voltage from 0V to 3.3V over the range -20C to +80C. This would equate to a settings of range = 100 with an offset = -20.

---

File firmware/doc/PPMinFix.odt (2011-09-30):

Fixing the 9x PPM in problem

Problem:

A few folks have found out that when connecting two Turnigy/FS-TH 9x radios for training purposes, sometimes the trainer radio cannot receive the ppm signal. Similar problem exits when the radio is used with a simulator.

I have two this type of radios, with two different RF modules: one is FlySky version B, the other is Corona DSSS v2. If I use a radio with the Corona RF module as the trainee, the trainer can receive the ppm signal OK; if I use a radio with the FlySky RF module as the trainee, the trainer cannot receive the ppm signal.

Existing methods to handle this problem:

As a few folks have already figured out, the problem is caused by the attachment of the RF module to the trainee radio. In the training mode, the trainee radio cuts off the power to the RF module, but the ppm signal remains sent. A couple of existing methods to handle this problem include: a. removing the RF module from the radio when used as trainee or the control for a simulator, b. adding a switch to cut off the ppm signal to the RF module manually, and c. adding a relay to cut off the ppm signal to the RF module automatically.

An easy method to handle this problem:

Here I will provide an easy method to handle this problem.

Before talking about the easy method, let's take a look at the deeper reason of the problem. In a modern digital RF module, there is a micro-controller to handle the ppm input as well as other tasks. Many micro-controllers have a kind of high voltage protection to the input pins, which is basically a diode connected between an input pin and the power supply. When the power supply of the RF module is cut off, the ppm signal will be providing power to the micro-controller (or even the whole module) through this diode. As a result, the ppm signal sent to the trainer radio will have a very low level which is lower than the required and cannot be detected.

The above mentioned three existing methods will all effectively cut off the current flow to the RF module and maintain the voltage level of the ppm signal to the trainer. Hence they all work.

The ppm signal is from a pin of a micro-controller, which can provide about 20 mA current. If you put a resistor in the path where you want the switch or relay to be, this will solve the problem. A 1 kohm resistor will work fine, as explained below:

1. It will provide the required voltage level to the trainer even if the ppm signal is short-circuited by the RM module. The pin which produce the ppm signal usually has a output resistance about 200 ohm. When the ppm signal is shorted to ground, the level of the ppm signal sent to the trainer is still very high, 1000 / (1000 + 200) percent by using voltage divider, which is good enough for the trainer.

2. It will provide the required voltage level to the RF module if the RM module is on. The reason is that when the RF module is powered, the input resistance of the ppm input pin will be very high, and 1 kohm resistance will not have noticeable effect.

You may ask if I have tried the easy method already. The answer is yes. I just did both of my two radios, and they are all working fine with whatever RF module.

A picture can be posted at a later time if it is needed.

Cheers,
JH

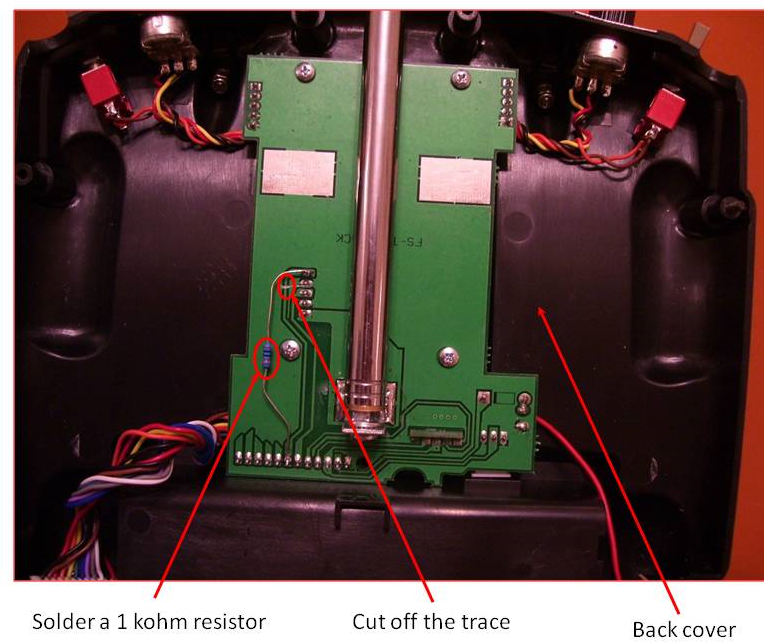
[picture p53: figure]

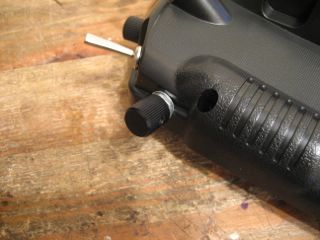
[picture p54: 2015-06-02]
wiki/V41FAQ.attach/rot-enc-outside.jpg

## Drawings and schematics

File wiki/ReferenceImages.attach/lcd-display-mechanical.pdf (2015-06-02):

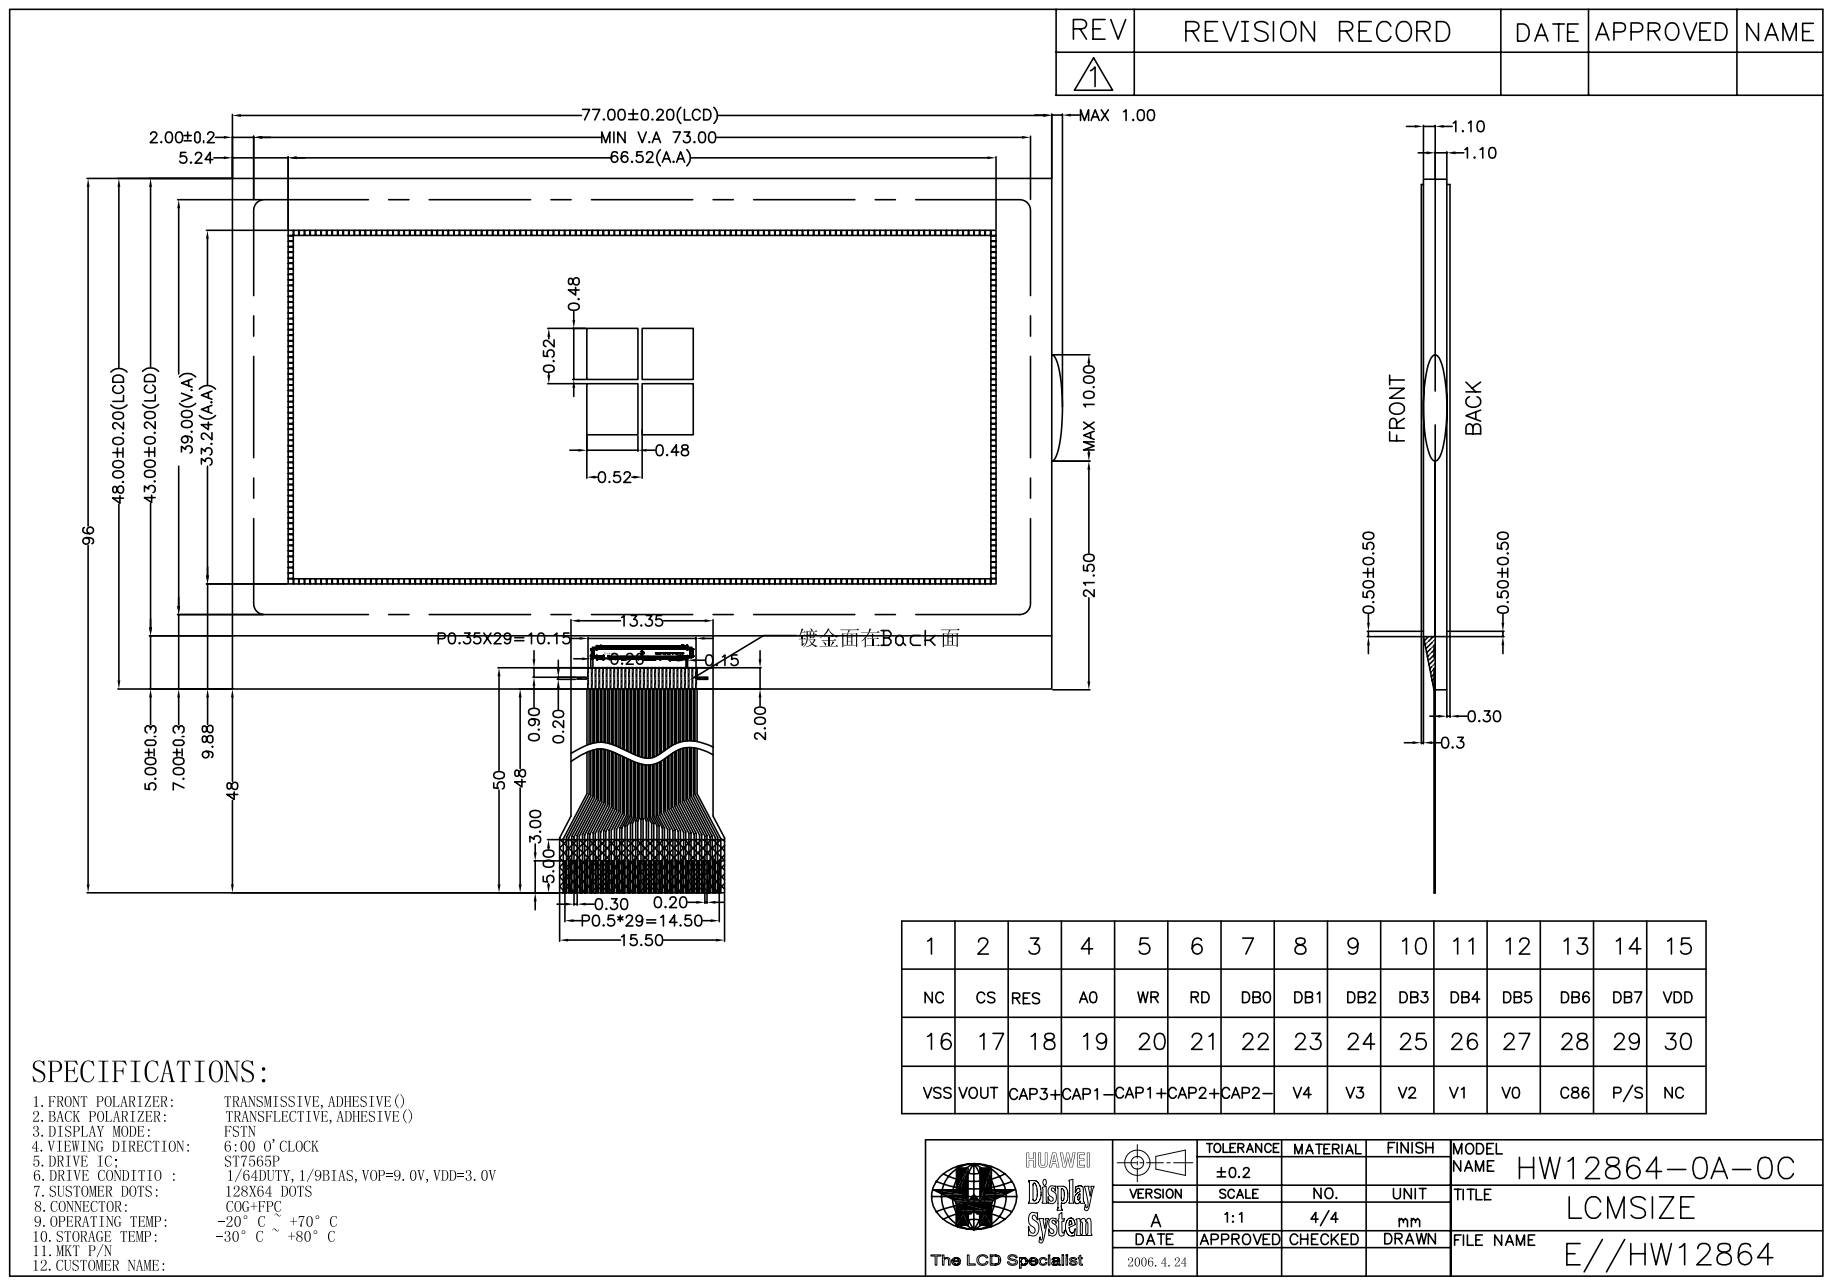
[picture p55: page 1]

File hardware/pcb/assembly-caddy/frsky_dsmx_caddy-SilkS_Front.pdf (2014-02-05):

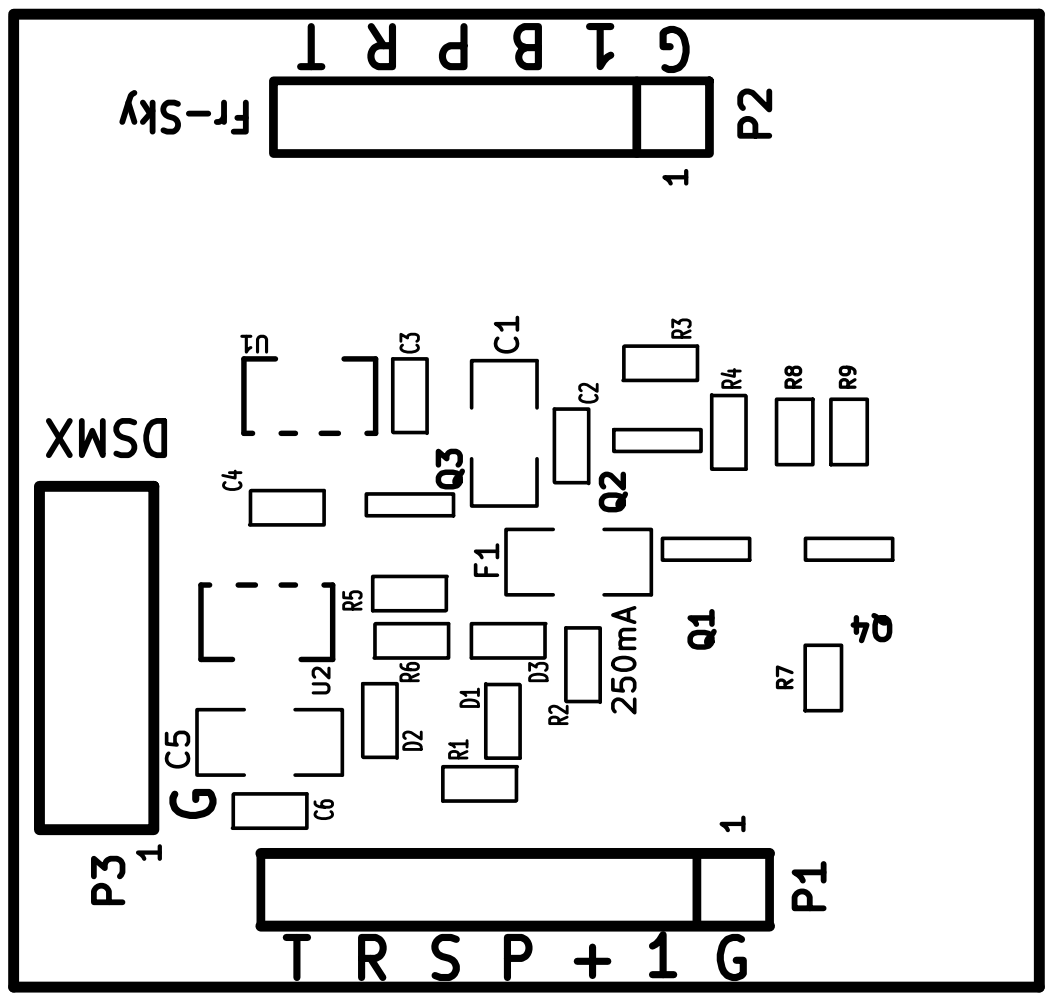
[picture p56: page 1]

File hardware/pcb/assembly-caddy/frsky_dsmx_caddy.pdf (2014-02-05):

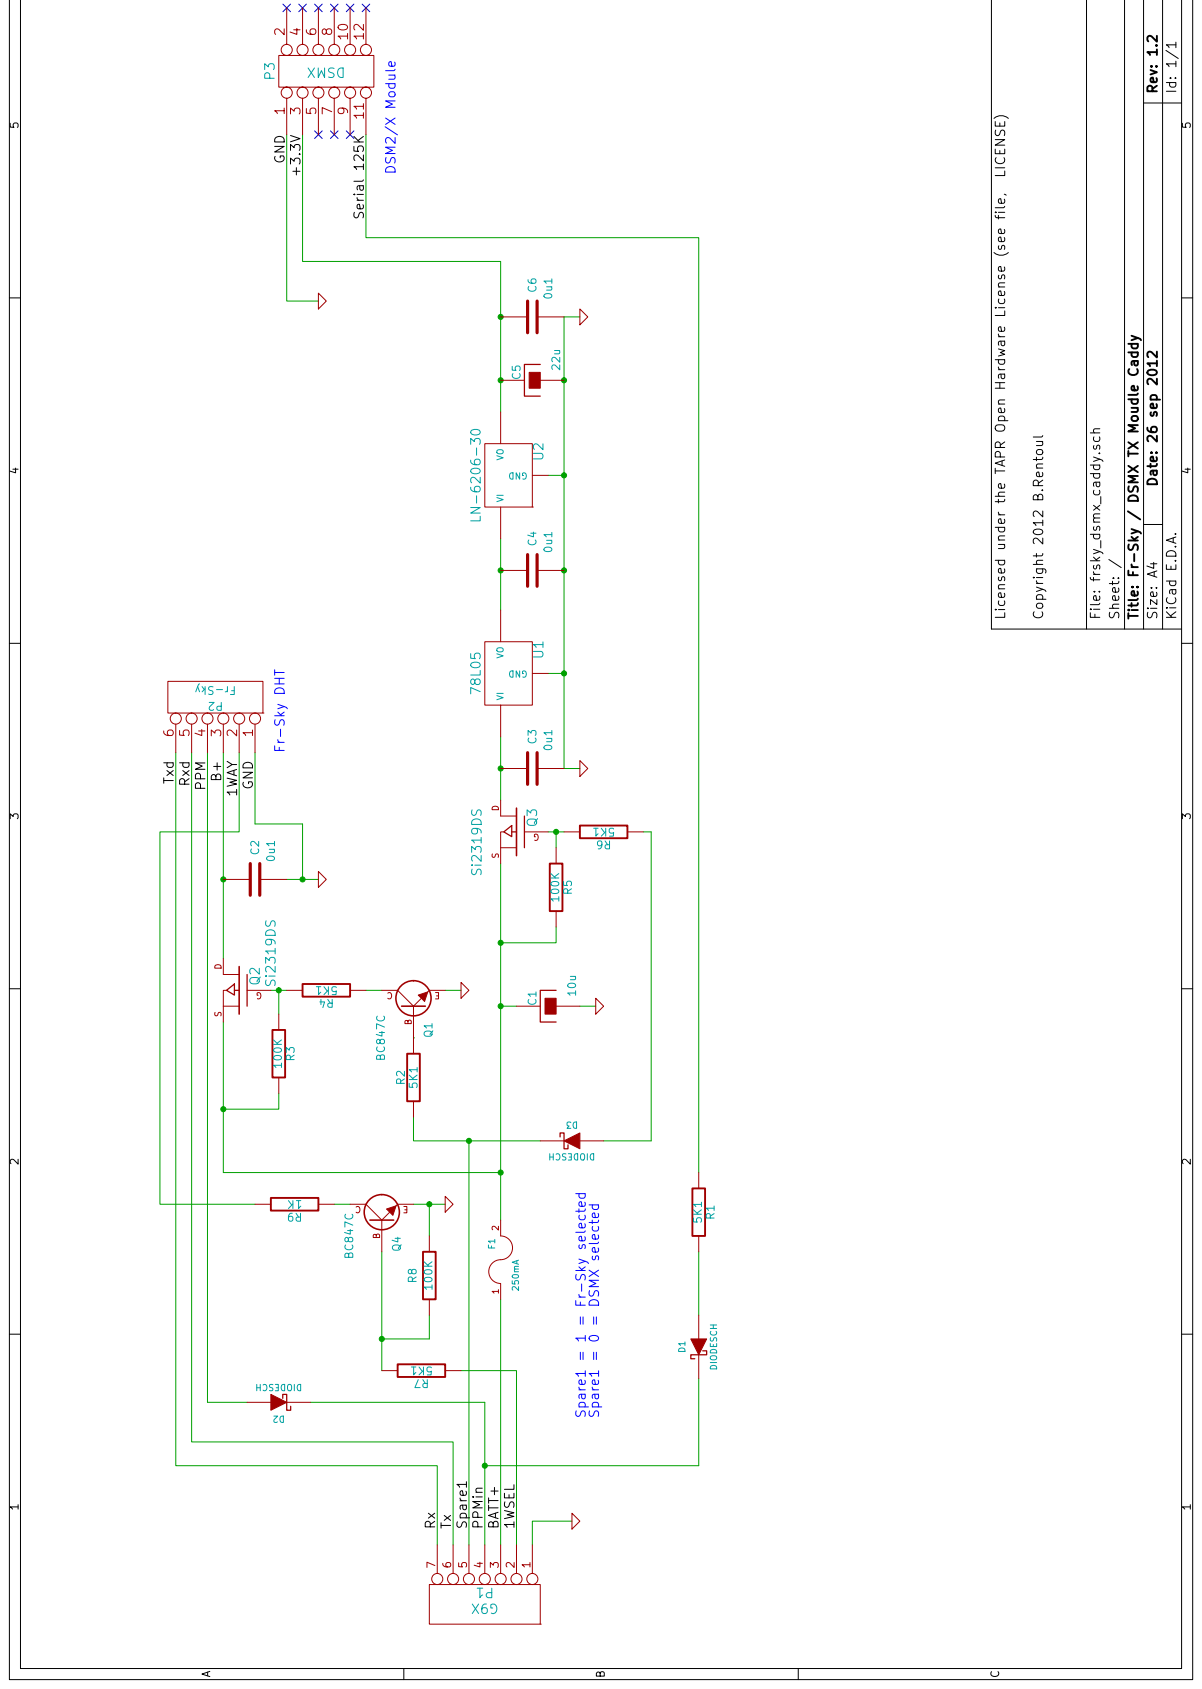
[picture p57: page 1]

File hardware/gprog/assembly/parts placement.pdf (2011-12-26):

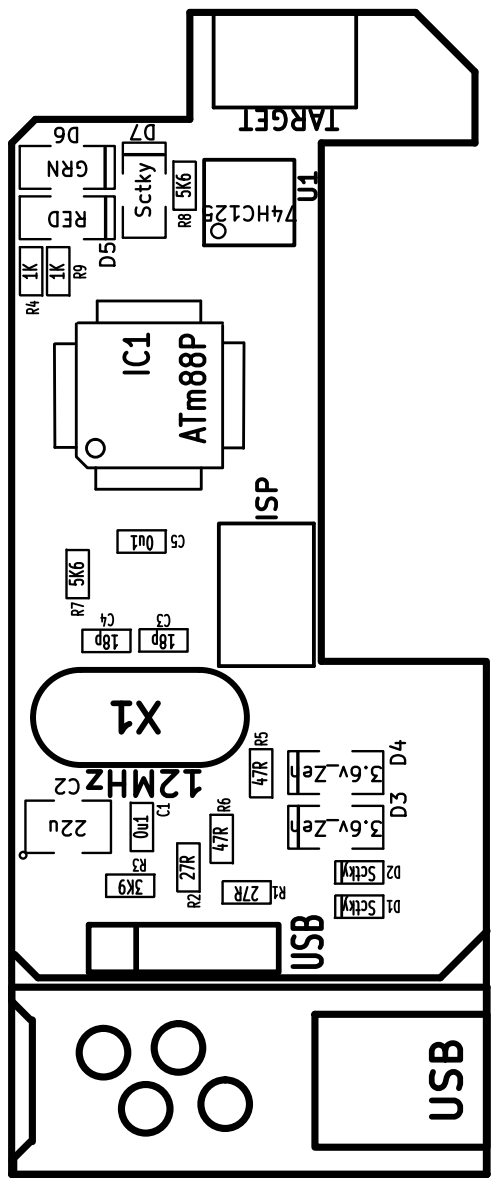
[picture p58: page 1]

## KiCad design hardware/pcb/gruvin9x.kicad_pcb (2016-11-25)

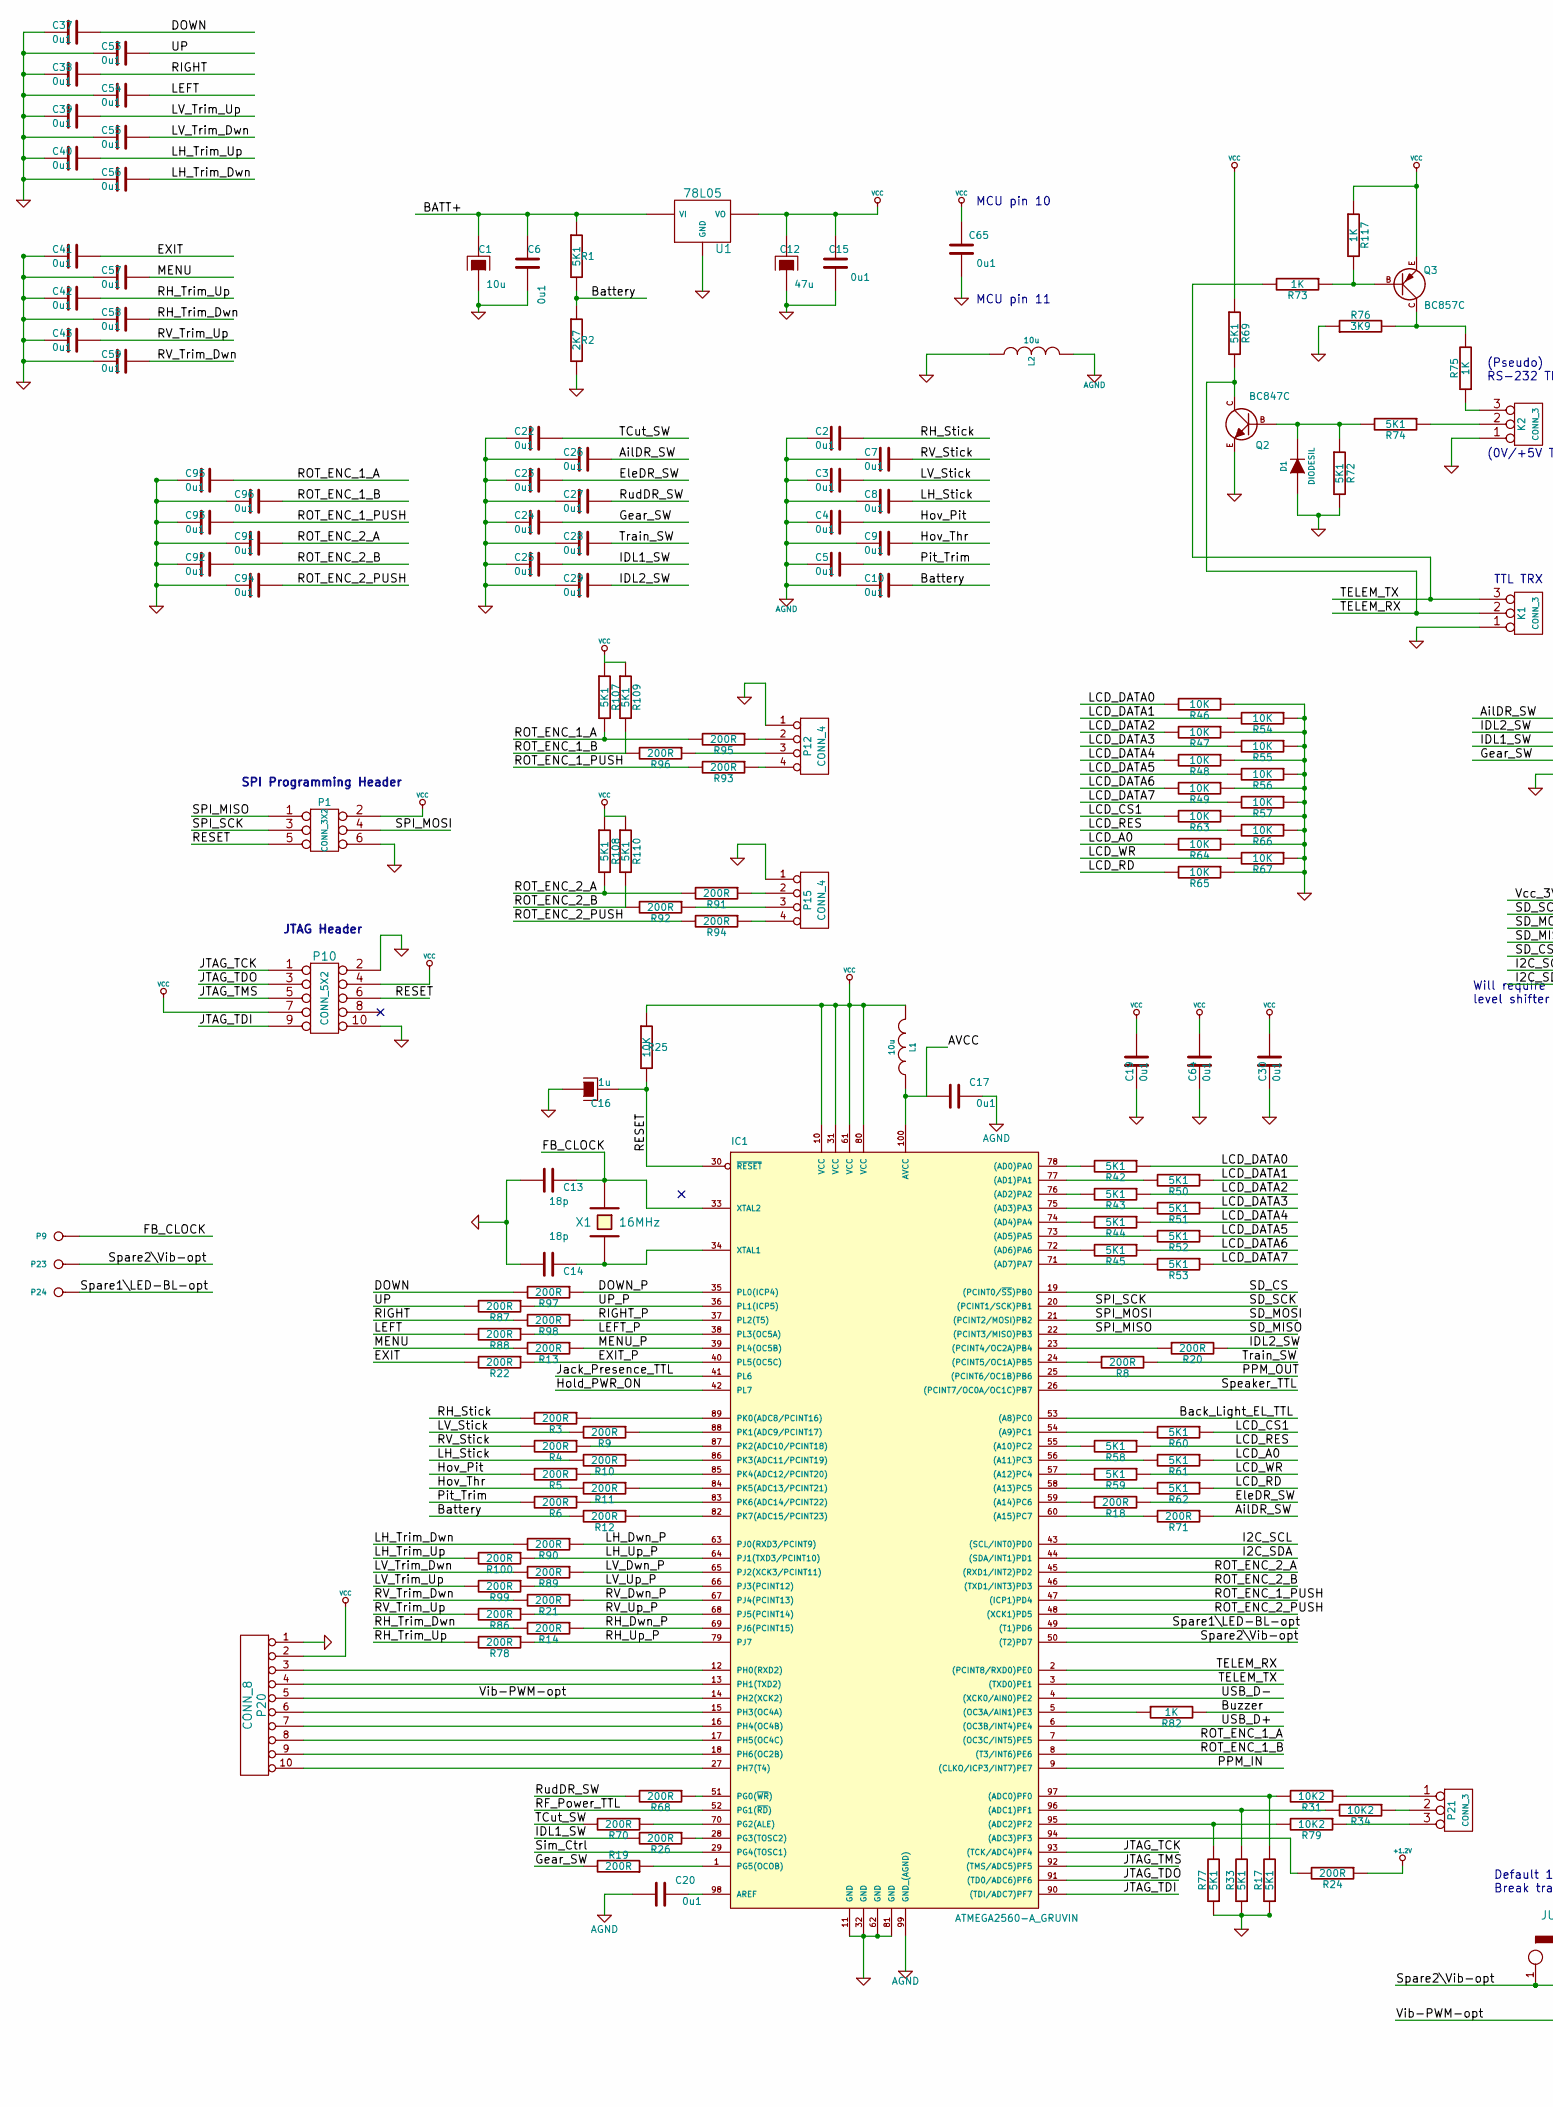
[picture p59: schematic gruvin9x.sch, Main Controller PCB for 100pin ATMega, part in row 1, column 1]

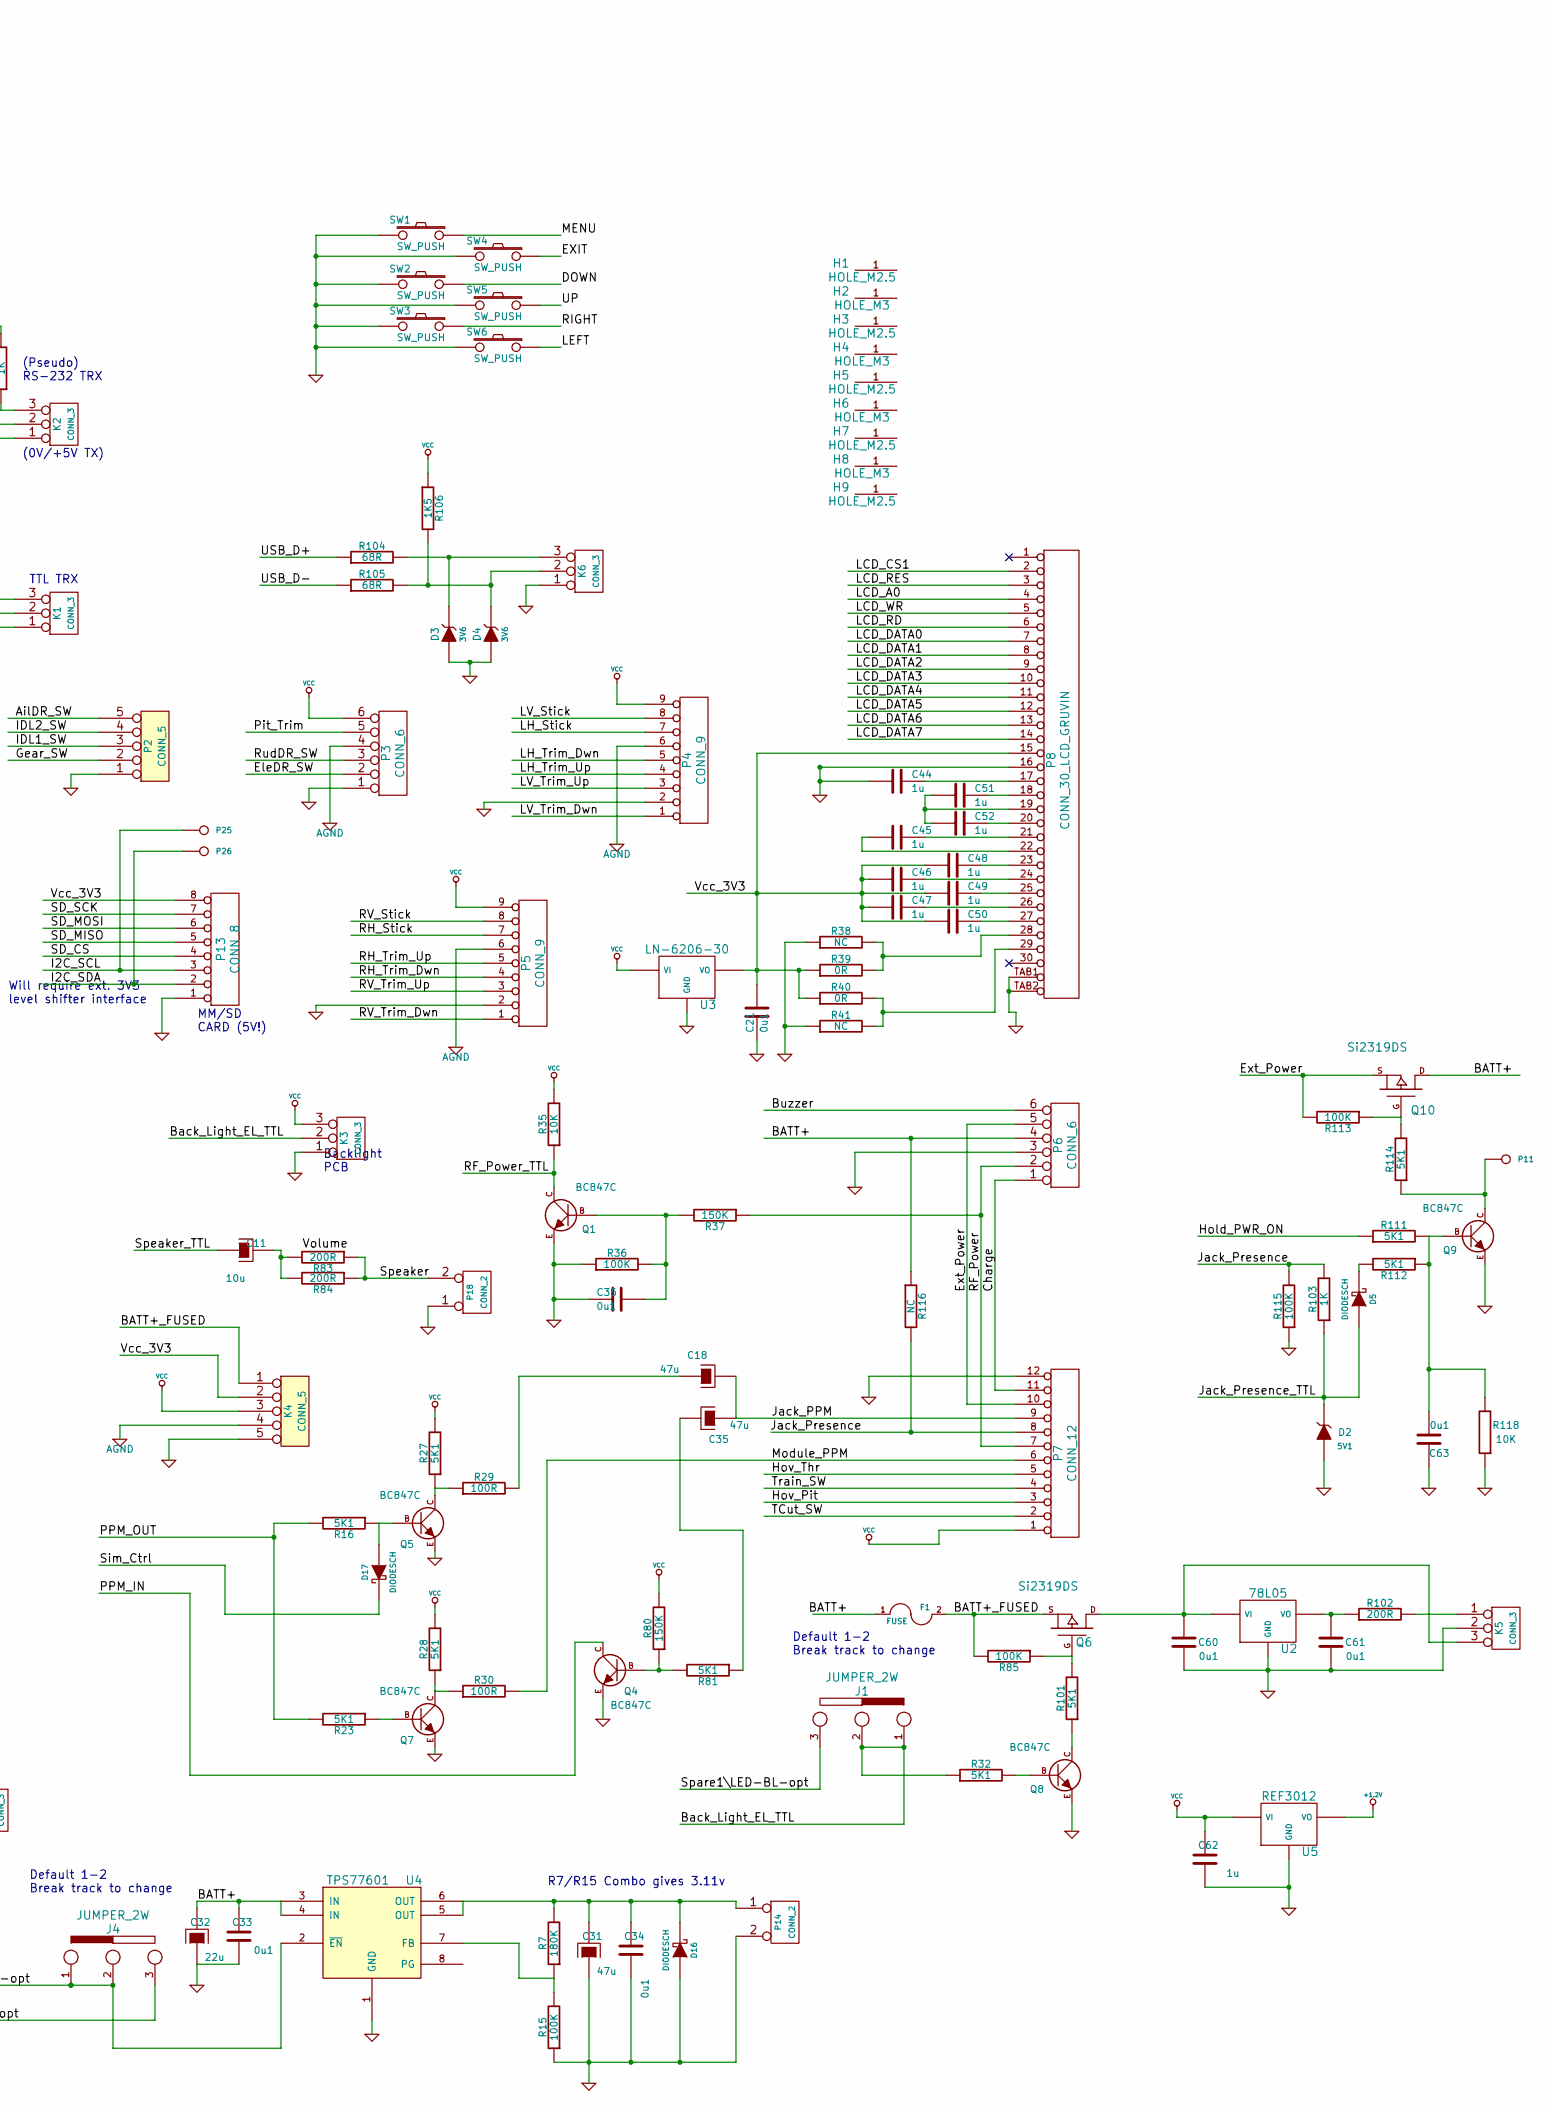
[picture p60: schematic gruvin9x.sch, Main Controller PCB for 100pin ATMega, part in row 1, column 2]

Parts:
C1, C11: 10u
C2, C3, C4, C5, C6, C7, C8, C9, C10, C15, C17, C19, C20, C21, C22, C23, C24, C25, C26, C27, C28, C29, C30, C33, C34, C36, C37, C38, C39, C40, C41, C42, C43, C53, C54, C55, C56, C57, C58, C59, C60, C61, C63, C64, C65, C91, C92, C93, C94, C95, C96: 0u1
C12, C18, C31, C35: 47u
C13, C14: 18p
C16, C44, C45, C46, C47, C48, C49, C50, C51, C52, C62: 1u
C32: 22u
D1: DIODESIL
D2: 5V1
D3, D4: 3V6
D5, D16, D17: DIODESCH
F1: FUSE
H1, H3, H5, H7, H9: HOLE_M2.5
H2, H4, H6, H8: HOLE_M3
IC1: ATMEGA2560-A_GRUVIN; TQFP100
J1, J4: JUMPER_2W
K1, K2, K3, K5, K6: CONN_3
K4: CONN_5
L1, L2: 10u
P1: CONN_3X2
P2: CONN_5
P3, P6: CONN_6
P4, P5: CONN_9
P7: CONN_12
P8: CONN_30_LCD_GRUVIN
P9, P11, P23, P24, P25, P26: CONN_1
P10: CONN_5X2
P12, P15: CONN_4
P13, P20: CONN_8
P14: CONN_2
P18: CONN_2; CONN_2MM_2x1
P21: CONN_3
Q1, Q2, Q4, Q5, Q7, Q8, Q9: BC847C; SOT23-BCE
Q3: BC857C; SOT23-BCE
Q6, Q10: Si2319DS
R1, R16, R17, R23, R27, R28, R32, R33, R42, R43, R44, R45, R50, R51, R52, R53, R58, R59, R60, R61, R62, R69, R72, R74, R77, R81, R101, R107, R108, R109, R110, R111, R112, R114: 5K1
R2: 2K7
R3, R4, R5, R6, R8, R9, R10, R11, R12, R13, R14, R18, R19, R20, R21, R22, R24, R26, R68, R70, R71, R78, R83, R84, R86, R87, R88, R89, R90, R91, R92, R93, R94, R95, R96, R97, R98, R99, R100, R102: 200R
R7: 180K
R15, R36, R85, R113, R115: 100K
R25, R35, R46, R47, R48, R49, R54, R55, R56, R57, R63, R64, R65, R66, R67, R118: 10K
R29, R30: 100R
R31, R34, R79: 10K2
R37, R80: 150K
R38, R41, R116: NC
R39, R40: 0R
R73, R75, R82, R103, R117: 1K
R76: 3K9
R104, R105: 68R
R106: 1K5
SW1, SW2, SW3, SW4, SW5, SW6: SW_PUSH
U1, U2: 78L05; SOT89
U3: LN-6206-30; SOT89
U4: TPS77601
U5: REF3012; SOT89
X1: 16MHz

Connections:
+1.2V: R24.1, U5.VO
/AVCC: C17.2, IC1.100 (AVCC), L1.1
/AilDR_SW: C26.1, P2.5, R71.1
/BATT+: C1.2, C6.2, C32.2, C33.2, F1.1, P6.4, Q10.D, R1.1, R116.1, U1.VI, U4.3 (IN), U4.4 (IN)
/BATT+_FUSED: F1.2, K4.1, Q6.S, R85.2
/Back_Light_EL_TTL: IC1.53 ((A8)PC0), J1.1, J1.2, K3.2 (PM), R32.1
/Battery: C10.1, R1.2, R2.1, R12.2
/Buzzer: P6.6, R82.2
/Charge: P6.1, P7.11
/DOWN: C37.1, R97.2, SW2.1
/DOWN_P: IC1.35 (PL0(ICP4)), R97.1
/EXIT: C41.1, R22.2, SW4.1
/EXIT_P: IC1.40 (PL5(OC5C)), R22.1
/EleDR_SW: C23.1, P3.2, R18.2
/Ext_Power: P6.5, P7.10, Q10.S, R113.2
/FB_CLOCK: C13.1, IC1.33 (XTAL2), P9.1, X1.1
/Gear_SW: C24.1, P2.2, R19.2
/Hold_PWR_ON: IC1.42 (PL7), R111.1
/Hov_Pit: C4.1, P7.3, R5.2
/Hov_Thr: C9.1, P7.5, R11.2
/I2C_SCL: IC1.43 ((SCL/INT0)PD0), P13.3, P25.1
/I2C_SDA: IC1.44 ((SDA/INT1)PD1), P13.2, P26.1
/IDL1_SW: C25.1, P2.3, R26.2
/IDL2_SW: C29.1, P2.4, R20.2
/JTAG_TCK: IC1.93 ((TCK/ADC4)PF4), P10.1
/JTAG_TDI: IC1.90 ((TDI/ADC7)PF7), P10.9
/JTAG_TDO: IC1.91 ((TD0/ADC6)PF6), P10.3
/JTAG_TMS: IC1.92 ((TMS/ADC5)PF5), P10.5
/Jack_PPM: C18.2, C35.1, P7.9
/Jack_Presence: P7.8, R103.2, R115.2, R116.2
/Jack_Presence_TTL: D2.2 (K), D5.1 (A), IC1.41 (PL6), R103.1
/LCD_A0: P8.4, R61.1, R64.2
/LCD_CS1: P8.2, R60.1, R63.2
/LCD_DATA0: P8.7, R42.1, R46.2
/LCD_DATA1: P8.8, R50.1, R54.2
/LCD_DATA2: P8.9, R43.1, R47.2
/LCD_DATA3: P8.10, R51.1, R55.2
/LCD_DATA4: P8.11, R44.1, R48.2
/LCD_DATA5: P8.12, R52.1, R56.2
/LCD_DATA6: P8.13, R45.1, R49.2
/LCD_DATA7: P8.14, R53.1, R57.2
/LCD_RD: P8.6, R62.1, R65.2
/LCD_RES: P8.3, R58.1, R66.2
/LCD_WR: P8.5, R59.1, R67.2
/LEFT: C54.1, R88.2, SW6.1
/LEFT_P: IC1.38 (PL3(OC5A)), R88.1
/LH_Dwn_P: IC1.63 (PJ0(RXD3/PCINT9)), R90.1
/LH_Stick: C8.1, P4.7, R10.2
/LH_Trim_Dwn: C56.1, P4.5, R90.2
/LH_Trim_Up: C40.1, P4.4, R100.2
/LH_Up_P: IC1.64 (PJ1(TXD3/PCINT10)), R100.1
/LV_Dwn_P: IC1.65 (PJ2(XCK3/PCINT11)), R89.1
/LV_Stick: C3.1, P4.8, R9.2
/LV_Trim_Dwn: C55.1, P4.1, R89.2
/LV_Trim_Up: C39.1, P4.3, R99.2
/LV_Up_P: IC1.66 (PJ3(PCINT12)), R99.1
/MENU: C57.1, R13.2, SW1.1
/MENU_P: IC1.39 (PL4(OC5B)), R13.1
/Module_PPM: P7.6, R30.2
/PPM_IN: IC1.9 ((CLKO/ICP3/INT7)PE7), Q4.C
/PPM_OUT: IC1.25 ((PCINT6/OC1B)PB6), R16.2, R23.2
/Pit_Trim: C5.1, P3.5, R6.2
/RESET: C16.2, IC1.30 (~RESET), P1.5, P10.6, R25.2
/RF_Power: P6.2, P7.7, R37.1
/RF_Power_TTL: IC1.52 (PG1(~RD~)), Q1.C, R35.1
/RH_Dwn_P: IC1.69 (PJ6(PCINT15)), R14.1
/RH_Stick: C2.1, P5.7, R3.2
/RH_Trim_Dwn: C58.1, P5.4, R14.2
/RH_Trim_Up: C42.1, P5.5, R78.2
/RH_Up_P: IC1.79 (PJ7), R78.1
/RIGHT: C38.1, R98.2, SW3.1
/RIGHT_P: IC1.37 (PL2(T5)), R98.1
/ROT_ENC_1_A: C95.1, IC1.7 ((OC3C/INT5)PE5), R95.2, R107.2
/ROT_ENC_1_B: C96.1, IC1.8 ((T3/INT6)PE6), R96.2, R109.2
/ROT_ENC_1_PUSH: C93.1, IC1.47 ((ICP1)PD4), R93.2
/ROT_ENC_2_A: C91.1, IC1.45 ((RXD1/INT2)PD2), R91.2, R108.2
/ROT_ENC_2_B: C92.1, IC1.46 ((TXD1/INT3)PD3), R92.2, R110.2
/ROT_ENC_2_PUSH: C94.1, IC1.48 ((XCK1)PD5), R94.2
/RV_Dwn_P: IC1.67 (PJ4(PCINT13)), R21.1
/RV_Stick: C7.1, P5.8, R4.2
/RV_Trim_Dwn: C59.1, P5.1, R21.2
/RV_Trim_Up: C43.1, P5.3, R86.2
/RV_Up_P: IC1.68 (PJ5(PCINT14)), R86.1
/RudDR_SW: C27.1, P3.3, R68.2
/SD_CS: IC1.19 ((PCINT0/~SS~)PB0), P13.4
/SD_MISO: IC1.22 ((PCINT3/MISO)PB3), P1.1, P13.5
/SD_MOSI: IC1.21 ((PCINT2/MOSI)PB2), P1.4, P13.6
/SD_SCK: IC1.20 ((PCINT1/SCK)PB1), P1.3, P13.7
/Sim_Ctrl: D17.2 (K), IC1.29 (PG4(TOSC1))
/Spare1\LED-BL-opt: IC1.49 ((T1)PD6), J1.3, P24.1
/Spare2\Vib-opt: IC1.50 ((T2)PD7), J4.1, J4.2, P23.1, U4.2 (~EN)
/Speaker: P18.2 (PM), R83.1, R84.1
/Speaker_TTL: C11.1, IC1.26 ((PCINT7/OC0A/OC1C)PB7)
/TCut_SW: C22.1, P7.2, R70.2
/TELEM_RX: IC1.2 ((PCINT8/RXD0)PE0), K1.2 (PM), Q2.C, R69.2
/TELEM_TX: IC1.3 ((TXD0)PE1), K1.3, R73.2
/Train_SW: C28.1, P7.4, R8.2
/UP: C53.1, R87.2, SW5.1
/UP_P: IC1.36 (PL1(ICP5)), R87.1
/USB_D+: IC1.6 ((OC3B/INT4)PE4), R104.1
/USB_D-: IC1.4 ((XCK0/AIN0)PE2), R105.1
/Vcc_3V3: C21.1, C46.2, C47.2, C48.2, C49.2, C50.2, K4.2, P8.15, P13.8, R39.1, R40.1, U3.VO
/Vib-PWM-opt: IC1.14 (PH2(XCK2)), J4.3, P20.5
AGND: C2.2, C3.2, C4.2, C5.2, C7.2, C8.2, C9.2, C10.2, C17.1, C20.2, IC1.99 (GND_(AGND)), K4.4, L2.2, P3.4, P4.6, P5.6
GND: C1.1, C6.1, C12.1, C13.2, C14.2, C15.1, C16.1, C19.2, C21.2, C22.2, C23.2, C24.2, C25.2, C26.2, C27.2, C28.2, C29.2, C30.2, C31.1, C32.1, C33.1, C34.1, C36.2, C37.2, C38.2, C39.2, C40.2, C41.2, C42.2, C43.2, C44.2, C53.2, C54.2, C55.2, C56.2, C57.2, C58.2, C59.2, C60.1, C61.1, C62.1, C63.1, C64.2, C65.1, C91.2, C92.2, C93.2, C94.2, C95.2, C96.2, D1.1 (A), D2.1 (A), D3.1 (A), D4.1 (A), D16.1 (A), IC1.11 (GND), IC1.32 (GND), IC1.62 (GND), IC1.81 (GND), K1.1, K2.1, K3.1, K4.5, K5.2 (PM), K6.1, L2.1, P1.6, P2.1, P3.1, P4.2, P5.2, P6.3, P7.12, P8.16, P8.TAB1, P8.TAB2, P10.2, P10.10, P12.1, P13.1, P14.2 (PM), P15.1, P18.1, P20.1, Q1.E, Q2.E, Q4.E, Q5.E, Q7.E, Q8.E, Q9.E, R2.2, R15.1, R17.1, R33.1, R36.1, R38.1, R41.1, R46.1, R47.1, R48.1, R49.1, R54.1, R55.1, R56.1, R57.1, R63.1, R64.1, R65.1, R66.1, R67.1, R72.2, R76.1, R77.1, R115.1, R118.1, SW1.2, SW2.2, SW3.2, SW4.2, SW5.2, SW6.2, U1.GND, U2.GND, U3.GND, U4.1 (GND), U5.GND
unnamed: IC1.15 (PH3(OC4A)), P20.6
unnamed: IC1.13 (PH1(TXD2)), P20.4
unnamed: IC1.18 (PH6(OC2B)), P20.9
unnamed: IC1.27 (PH7(T4)), P20.10
unnamed: IC1.17 (PH5(OC4C)), P20.8
unnamed: IC1.16 (PH4(OC4B)), P20.7
unnamed: P12.4, R93.1
unnamed: P12.3, R96.1
unnamed: P12.2, R95.1
unnamed: C11.2, R83.2, R84.2
unnamed: P15.4, R94.1
unnamed: P15.3, R92.1
unnamed: P15.2, R91.1
unnamed: C61.2, R102.1, U2.VO
unnamed: Q6.G, R85.1, R101.2
unnamed: Q8.C, R101.1
unnamed: K5.1, R102.2
unnamed: R7.1, R15.2, U4.7 (FB)
unnamed: IC1.12 (PH0(RXD2)), P20.3
unnamed: IC1.5 ((OC3A/AIN1)PE3), R82.1
unnamed: C18.1, R29.2
unnamed: P21.1, R31.1
unnamed: P21.2 (PM), R34.1
unnamed: C31.2, C34.2, D16.2 (K), P14.1, R7.2, U4.5 (OUT), U4.6 (OUT)
unnamed: Q7.B, R23.1
unnamed: Q7.C, R28.1, R30.1
unnamed: D17.1 (A), Q5.B, R16.1
unnamed: Q5.C, R27.1, R29.1
unnamed: P8.29, R40.2, R41.2
unnamed: C44.1, P8.17
unnamed: C52.1, P8.20
unnamed: C45.2, P8.22
unnamed: C45.1, P8.21
unnamed: C48.1, P8.23
unnamed: C49.1, P8.25
unnamed: C46.1, P8.24
unnamed: C47.1, P8.26
unnamed: C50.1, P8.27
unnamed: C51.1, P8.18
unnamed: IC1.59 ((A14)PC6), R18.1
unnamed: IC1.1 (PG5(OCOB)), R19.1
unnamed: IC1.24 ((PCINT5/OC1A)PB5), R8.1
unnamed: IC1.23 ((PCINT4/OC2A)PB4), R20.1
unnamed: IC1.28 (PG3(TOSC2)), R26.1
unnamed: IC1.82 (PK7(ADC15/PCINT23)), R12.1
unnamed: IC1.83 (PK6(ADC14/PCINT22)), R6.1
unnamed: IC1.84 (PK5(ADC13/PCINT21)), R11.1
unnamed: IC1.86 (PK3(ADC11/PCINT19)), R10.1
unnamed: IC1.87 (PK2(ADC10/PCINT18)), R4.1
unnamed: IC1.88 (PK1(ADC9/PCINT17)), R9.1
unnamed: IC1.85 (PK4(ADC12/PCINT20)), R5.1
unnamed: IC1.89 (PK0(ADC8/PCINT16)), R3.1
unnamed: C14.1, IC1.34 (XTAL1), X1.2
unnamed: C20.1, IC1.98 (AREF)
unnamed: IC1.60 ((A15)PC7), R71.2
unnamed: IC1.58 ((A13)PC5), R62.2
unnamed: IC1.57 ((A12)PC4), R59.2
unnamed: IC1.56 ((A11)PC3), R61.2
unnamed: IC1.55 ((A10)PC2), R58.2
unnamed: IC1.54 ((A9)PC1), R60.2
unnamed: IC1.70 (PG2(ALE)), R70.1
unnamed: Q4.B, R80.1, R81.2
unnamed: C35.2, R81.1
unnamed: K2.2 (PM), R74.1
unnamed: IC1.51 (PG0(~WR~)), R68.1
unnamed: K2.3, R75.1
unnamed: IC1.75 ((AD3)PA3), R51.2
unnamed: IC1.74 ((AD4)PA4), R44.2
unnamed: IC1.73 ((AD5)PA5), R52.2
unnamed: IC1.72 ((AD6)PA6), R45.2
unnamed: IC1.71 ((AD7)PA7), R53.2
unnamed: C36.1, Q1.B, R36.2, R37.2
unnamed: IC1.76 ((AD2)PA2), R43.2
unnamed: IC1.77 ((AD1)PA1), R50.2
unnamed: IC1.78 ((AD0)PA0), R42.2
unnamed: P8.28, R38.2, R39.2
unnamed: C51.2, C52.2, P8.19
unnamed: Q10.G, R113.1, R114.2
unnamed: D5.2 (K), R112.2
unnamed: Q3.B, R73.1, R117.2
unnamed: D4.2 (K), K6.2 (PM), R105.2, R106.2
unnamed: D3.2 (K), K6.3, R104.2
unnamed: IC1.94 ((ADC3)PF3), R24.2
unnamed: Q8.B, R32.2
unnamed: C60.2, K5.3, Q6.D, U2.VI
unnamed: Q3.C, R75.2, R76.2
unnamed: P11.1, Q9.C, R114.1
unnamed: P21.3, R79.1
unnamed: C63.2, Q9.B, R111.2, R112.1, R118.2
unnamed: D1.2 (K), Q2.B, R72.1, R74.2
unnamed: IC1.95 ((ADC2)PF2), R77.2, R79.2
unnamed: IC1.96 ((ADC1)PF1), R33.2, R34.2
unnamed: IC1.97 ((ADC0)PF0), R17.2, R31.2
VCC: C12.2, C15.2, C19.1, C30.1, C62.2, C64.1, C65.2, IC1.10 (VCC), IC1.31 (VCC), IC1.61 (VCC), IC1.80 (VCC), K3.3, K4.3, L1.2, P1.2, P3.6, P4.9, P5.9, P7.1, P10.4, P10.7, P20.2, Q3.E, R25.1, R27.2, R28.2, R35.2, R69.1, R80.2, R106.1, R107.1, R108.1, R109.1, R110.1, R117.1, U1.VO, U3.VI, U5.VI

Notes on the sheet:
Default 1-2 Break track to change
MCU pin 11
MCU pin 10
R7/R15 Combo gives 3.11v
JTAG Header
Backlight PCB
Will require ext. 3V3 level shifter interface
MM/SD CARD (5V!)
(0V/+5V TX)
TTL TRX
(Pseudo) RS-232 TRX
SPI Programming Header

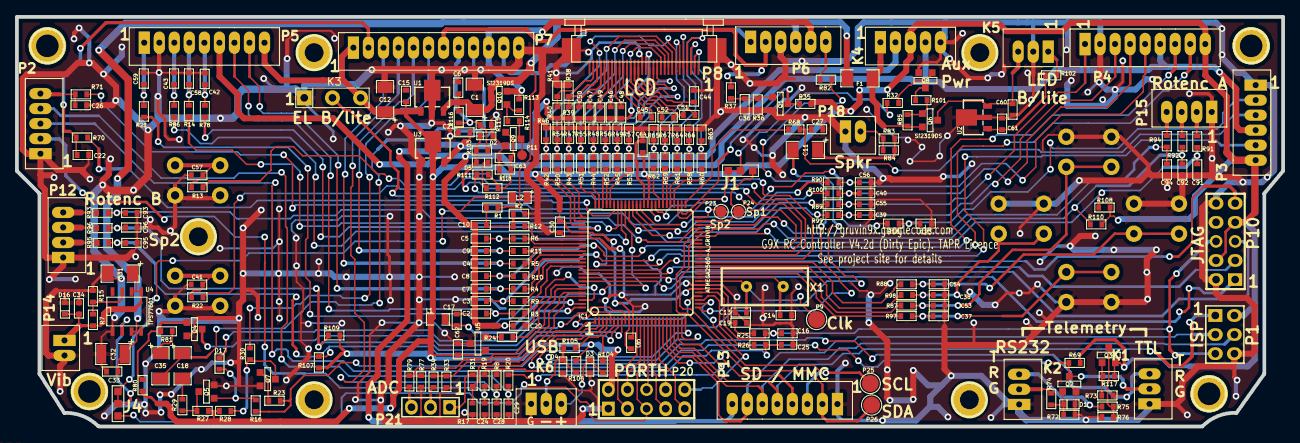
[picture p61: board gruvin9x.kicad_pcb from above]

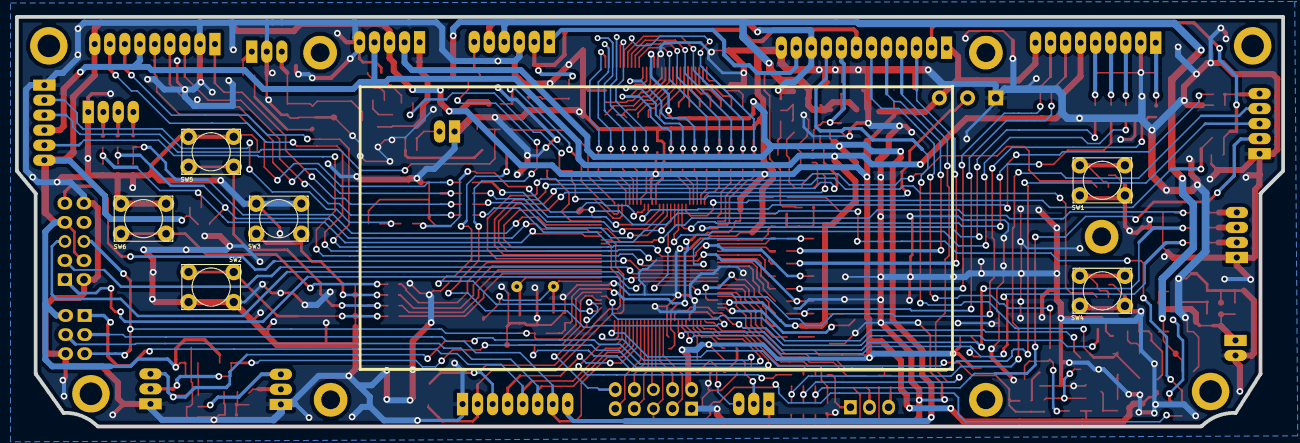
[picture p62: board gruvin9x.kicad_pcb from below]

Board: 2 copper layers, 168.5 x 54.5 mm, 261 parts (6 on the bottom side), 199 nets.

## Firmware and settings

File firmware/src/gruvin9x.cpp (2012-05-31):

/*
 * Authors (alphabetical order)
 * - Bertrand Songis <bsongis@gmail.com>
 * - Bryan J. Rentoul (Gruvin) <gruvin@gmail.com>
 *
 * gruvin9x is based on code named er9x by
 * Author - Erez Raviv <erezraviv@gmail.com>, which is in turn
 * was based on the original (and ongoing) project by Thomas Husterer,
 * th9x -- http://code.google.com/p/th9x/
 *
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
 */

#include "gruvin9x.h"

const pm_uchar splashdata[] PROGMEM = { 'S','P','S',0,
#if defined (PCBV4)
#include "s9xsplashv4.lbm"
#else
#include "s9xsplash.lbm"
#endif
       'S','P','E',0};
const pm_uchar * s9xsplash = splashdata+4;

#include "menus.h"
#include <stdlib.h>

// MM/SD card Disk IO Support
#if defined (PCBV3)
#include "integer.h"
#include "diskio.h"
gtime_t g_unixTime; // Global date/time register, incremented each second in per10ms()
#endif

/*
mode1 rud ele thr ail
mode2 rud thr ele ail
mode3 ail ele thr rud
mode4 ail thr ele rud
*/

EEGeneral  g_eeGeneral;
ModelData  g_model;

uint8_t g_tmr1Latency_max;
uint8_t g_tmr1Latency_min;
uint16_t g_timeMain;
uint16_t g_time_per10;

#if defined (PCBSTD) && defined (BEEPSPKR)
uint8_t toneFreq = BEEP_DEFAULT_FREQ;
uint8_t toneOn = false;
#endif

bool warble = false;

uint8_t heartbeat;

const pm_char modi12x3[] PROGMEM =
  "RUD ELE THR AIL "
  "RUD THR ELE AIL "
  "AIL ELE THR RUD "
  "AIL THR ELE RUD ";

const pm_char s_charTab[] PROGMEM = "_-.,";

//R=1
//E=2
//T=3
//A=4
const pm_uint8_t chout_ar[] PROGMEM = { //First number is 0..23 -> template setup,  Second is relevant channel out
                                      1,2,3,4 , 1,2,4,3 , 1,3,2,4 , 1,3,4,2 , 1,4,2,3 , 1,4,3,2,
                                      2,1,3,4 , 2,1,4,3 , 2,3,1,4 , 2,3,4,1 , 2,4,1,3 , 2,4,3,1,
                                      3,1,2,4 , 3,1,4,2 , 3,2,1,4 , 3,2,4,1 , 3,4,1,2 , 3,4,2,1,
                                      4,1,2,3 , 4,1,3,2 , 4,2,1,3 , 4,2,3,1 , 4,3,1,2 , 4,3,2,1    };

const pm_uint8_t modn12x3[] PROGMEM = {
    1, 2, 3, 4,
    1, 3, 2, 4,
    4, 2, 3, 1,
    4, 3, 2, 1 };

#ifdef TRANSLATIONS
int8_t char2idx(char c)
{
  if (c==' ') return 0;
  if (c>='A' && c<='Z') return 1+c-'A';
  if (c>='a' && c<='z') return -1-c+'a';
  if (c>='0' && c<='9') return 27+c-'0';
  for (int8_t i=0;;i++) {
    char cc = pgm_read_byte(s_charTab+i);
    if(cc==c) return 37+i;
    if(cc==0) return 0;
  }
}
#endif

char idx2char(int8_t idx)
{
  if (idx == 0) return ' ';
  if (idx < 0) {
    if (idx > -27) return 'a' - idx - 1;
    idx = -idx;
  }
  if (idx < 27) return 'A' + idx - 1;
  if (idx < 37) return '0' + idx - 27;
  if (idx <= ZCHAR_MAX) return pgm_read_byte(s_charTab+idx-37);
  return ' ';
}

PhaseData *phaseaddress(uint8_t idx)
{
  return &g_model.phaseData[idx];
}

ExpoData *expoaddress(uint8_t idx )
{
  return &g_model.expoData[idx];
}

MixData *mixaddress(uint8_t idx)
{
  return &g_model.mixData[idx];
}

LimitData *limitaddress(uint8_t idx)
{
  return &g_model.limitData[idx];
}

int16_t intpol(int16_t x, uint8_t idx) // -100, -75, -50, -25, 0 ,25 ,50, 75, 100
{
#define D9 (RESX * 2 / 8)
#define D5 (RESX * 2 / 4)
  bool    cv9 = idx >= MAX_CURVE5;
  int8_t *crv = cv9 ? g_model.curves9[idx-MAX_CURVE5] : g_model.curves5[idx];
  int16_t erg;

  x+=RESXu;
  if(x < 0) {
    erg = (int16_t)crv[0] * (RESX/4);
  } else if(x >= (RESX*2)) {
    erg = (int16_t)crv[(cv9 ? 8 : 4)] * (RESX/4);
  } else {
    int16_t a,dx;
    if(cv9){
      a   = (uint16_t)x / D9;
      dx  =((uint16_t)x % D9) * 2;
    } else {
      a   = (uint16_t)x / D5;
      dx  = (uint16_t)x % D5;
    }
    erg  = (int16_t)crv[a]*((D5-dx)/2) + (int16_t)crv[a+1]*(dx/2);
  }
  return erg / 25; // 100*D5/RESX;
}

int16_t applyCurve(int16_t x, uint8_t idx, uint8_t srcRaw)
{
  switch(idx) {
  case 0:
    return x;
  case 1:
    if (srcRaw == MIX_FULL) { //FULL
      if (x<0 ) x=-RESX;   //x|x>0
      else x=-RESX+2*x;
    }
    else {
      if (x<0) x=0;   //x|x>0
    }
    return x;
  case 2:
    if (srcRaw == MIX_FULL) { //FULL
      if (x>0) x=RESX;   //x|x<0
      else x=RESX+2*x;
    }
    else {
      if (x>0) x=0;   //x|x<0
    }
    return x;
  case 3:       // x|abs(x)
    return abs(x);
  case 4:       //f|f>0
    return x>0 ? RESX : 0;
  case 5:       //f|f<0
    return x<0 ? -RESX : 0;
  case 6:       //f|abs(f)
    return x>0 ? RESX : -RESX;
  }
  return intpol(x, idx-7);
}

// expo-funktion:
// ---------------
// kmplot
// f(x,k)=exp(ln(x)*k/10) ;P[0,1,2,3,4,5,6,7,8,9,10,11,12,13,14,15,16,17,18,19,20]
// f(x,k)=x*x*x*k/10 + x*(1-k/10) ;P[0,1,2,3,4,5,6,7,8,9,10]
// f(x,k)=x*x*k/10 + x*(1-k/10) ;P[0,1,2,3,4,5,6,7,8,9,10]
// f(x,k)=1+(x-1)*(x-1)*(x-1)*k/10 + (x-1)*(1-k/10) ;P[0,1,2,3,4,5,6,7,8,9,10]

uint16_t expou(uint16_t x, uint16_t k)
{
  // k*x*x*x + (1-k)*x
  return ((unsigned long)x*x*x/0x10000*k/(RESXul*RESXul/0x10000) + (RESKul-k)*x+RESKul/2)/RESKul;
}

int16_t expo(int16_t x, int16_t k)
{
  if(k == 0) return x;
  int16_t   y;
  bool    neg =  x < 0;
  if(neg)   x = -x;
  if(k<0){
    y = RESXu-expou(RESXu-x,-k);
  }else{
    y = expou(x,k);
  }
  return neg? -y:y;
}

#ifdef EXTENDED_EXPO
/// expo with y-offset
class Expo
{
  uint16_t   c;
  int16_t    d,drx;
public:
  void     init(uint8_t k, int8_t yo);
  static int16_t  expou(uint16_t x,uint16_t c, int16_t d);
  int16_t  expo(int16_t x);
};
void    Expo::init(uint8_t k, int8_t yo)
{
  c = (uint16_t) k  * 256 / 100;
  d = (int16_t)  yo * 256 / 100;
  drx = d * ((uint16_t)RESXu/256);
}
int16_t Expo::expou(uint16_t x,uint16_t c, int16_t d)
{
  uint16_t a = 256 - c - d;
  if( (int16_t)a < 0 ) a = 0;
  // a x^3 + c x + d
  //                         9  18  27        11  20   18
  uint32_t res =  ((uint32_t)x * x * x / 0x10000 * a / (RESXul*RESXul/0x10000) +
                   (uint32_t)x                   * c
  ) / 256;
  return (int16_t)res;
}
int16_t  Expo::expo(int16_t x)
{
  if(c==256 && d==0) return x;
  if(x>=0) return expou(x,c,d) + drx;
  return -expou(-x,c,-d) + drx;
}
#endif


void applyExpos(int16_t *anas, uint8_t phase)
{
  static int16_t anas2[4]; // values before expo, to ensure same expo base when multiple expo lines are used
  memcpy(anas2, anas, sizeof(anas2));

  if (phase == 255)
    phase = getFlightPhase();

  int8_t cur_chn = -1;
  for (uint8_t i=0; i<DIM(g_model.expoData); i++) {
    ExpoData &ed = g_model.expoData[i];
    if (ed.mode==0) break; // end of list
    if (ed.chn == cur_chn)
      continue;
    if (ed.phase != 0) {
      if (ed.negPhase) {
        if (phase+1 == -ed.phase)
          continue;
      }
      else {
        if (phase+1 != ed.phase)
          continue;
      }
    }
    if (getSwitch(ed.swtch, 1)) {
      int16_t v = anas2[ed.chn];
      if((v<0 && ed.mode&1) || (v>=0 && ed.mode&2)) {
        cur_chn = ed.chn;
        int16_t k = ed.expo;
        v = expo(v, k);
        if (ed.curve) v = applyCurve(v, ed.curve > 10 ? ed.curve + 4 : ed.curve, 0);
        v = ((int32_t)v * ed.weight) / 100;
        anas[cur_chn] = v;
      }
    }
  }
}

bool s_noStickInputs = false;
FORCEINLINE int16_t getValue(uint8_t i)
{
    if(i<NUM_STICKS+NUM_POTS) return (s_noStickInputs ? 0 : calibratedStick[i]);
    else if(i<MIX_FULL/*srcRaw is shifted +1!*/) return 1024; //FULL/MAX
    else if(i<PPM_BASE+NUM_CAL_PPM) return (g_ppmIns[i-PPM_BASE] - g_eeGeneral.trainer.calib[i-PPM_BASE])*2;
    else if(i<PPM_BASE+NUM_PPM) return g_ppmIns[i-PPM_BASE]*2;
    else if(i<CHOUT_BASE+NUM_CHNOUT) return ex_chans[i-CHOUT_BASE];
#ifdef FRSKY
    else if(i<CHOUT_BASE+NUM_CHNOUT+NUM_TELEMETRY) return frskyTelemetry[i-CHOUT_BASE-NUM_CHNOUT].value;
#endif
    else return 0;
}

volatile uint16_t s_last_switch_used;
volatile uint16_t s_last_switch_value;
bool __getSwitch(int8_t swtch)
{
  bool result;

  if (swtch == 0)
    return s_last_switch_used & (1<<15);

  uint8_t cs_idx = abs(swtch);

  if (cs_idx == MAX_SWITCH) {
    result = true;
  }
  else if (cs_idx < MAX_SWITCH-NUM_CSW) {
    result = keyState((EnumKeys)(SW_BASE+cs_idx-1));
  }
  else {
    cs_idx -= MAX_SWITCH-NUM_CSW;
    volatile CustomSwData &cs = g_model.customSw[cs_idx];
    if (cs.func == CS_OFF) return false;

    uint8_t s = CS_STATE(cs.func);
    if (s == CS_VBOOL) {
      uint16_t mask = (1 << cs_idx);
      if (s_last_switch_used & mask) {
        result = (s_last_switch_value & mask);
      }
      else {
        s_last_switch_used |= mask;
        bool res1 = __getSwitch(cs.v1);
        bool res2 = __getSwitch(cs.v2);
        switch (cs.func) {
          case CS_AND:
            result = (res1 && res2);
            break;
          case CS_OR:
            result = (res1 || res2);
            break;
          // case CS_XOR:
          default:
            result = (res1 ^ res2);
            break;
        }
      }
      if (result)
        s_last_switch_value |= (1<<cs_idx);
      else
        s_last_switch_value &= ~(1<<cs_idx);
    }
    else {
      int16_t x = getValue(cs.v1-1);
      int16_t y;
      if (s == CS_VOFS) {
#ifdef FRSKY
        if (cs.v1 > CHOUT_BASE+NUM_CHNOUT)
          y = 125+cs.v2;
        else
#endif
          y = calc100toRESX(cs.v2);

        switch (cs.func) {
          case CS_VPOS:
            result = (x>y);
            break;
          case CS_VNEG:
            result = (x<y);
            break;
          case CS_APOS:
            result = (abs(x)>y);
            break;
          // case CS_ANEG:
          default:
            result = (abs(x)<y);
        }
      }
      else {
        y = getValue(cs.v2-1);

        switch (cs.func) {
          case CS_EQUAL:
            result = (x==y);
            break;
          case CS_NEQUAL:
            result = (x!=y);
            break;
          case CS_GREATER:
            result = (x>y);
            break;
          case CS_LESS:
            result = (x<y);
            break;
          case CS_EGREATER:
            result = (x>=y);
            break;
          // case CS_ELESS:
          default:
            result = (x<=y);
        }
      }
    }
  }

  return swtch > 0 ? result : !result;
}

bool getSwitch(int8_t swtch, bool nc)
{
  s_last_switch_used = (nc<<15);
  return __getSwitch(swtch);
}

uint8_t getFlightPhase()
{
  for (uint8_t i=1; i<MAX_PHASES; i++) {
    PhaseData *phase = &g_model.phaseData[i];
    if (phase->swtch && getSwitch(phase->swtch, 0)) {
      return i;
    }
  }
  return 0;
}

int16_t getTrimValue(uint8_t phase, uint8_t idx)
{
  PhaseData *p = phaseaddress(phase);
  return (((int16_t)p->trim[idx]) << 2) + ((p->trim_ext >> (2*idx)) & 0x03);
}

void setTrimValue(uint8_t phase, uint8_t idx, int16_t trim)
{
  PhaseData *p = phaseaddress(phase);
  p->trim[idx] = (int8_t)(trim >> 2);
  p->trim_ext = (p->trim_ext & ~(0x03 << (2*idx))) + (((trim & 0x03) << (2*idx)));
  STORE_MODELVARS;
}

uint8_t getTrimFlightPhase(uint8_t idx, uint8_t phase)
{
  for (uint8_t i=0; i<MAX_PHASES; i++) {
    if (phase == 0) return 0;
    int16_t trim = getTrimValue(phase, idx);
    if (trim <= TRIM_EXTENDED_MAX) return phase;
    uint8_t result = trim-TRIM_EXTENDED_MAX-1;
    if (result >= phase) result++;
    phase = result;
  }
  return 0;
}

#if defined (PCBV3) && !defined (PCBV4)
// The ugly scanned keys thing should be gone for PCBV4+. In the meantime ...
uint8_t keyDown()
{
  uint8_t in;
  PORTD = ~1; // select KEY_Y0 row (Bits 3:2 EXIT:MENU)
  _delay_us(1);
  in = (~PIND & 0b11000000) >> 5;
  PORTD = ~2; // select Y1 row. (Bits 3:0 Left/Right/Up/Down)
  _delay_us(1);
  in |= (~PIND & 0xf0) >> 1;
  PORTD = 0xff;
  return (in);
}
#else
inline uint8_t keyDown()
{
#if defined (PCBV4)
  return (~PINL) & 0x3F;
#else
  return (~PINB) & 0x7E;
#endif
}
#endif

void clearKeyEvents()
{
#ifdef SIMU
    while (keyDown() && main_thread_running) sleep(1/*ms*/);
#else
    while(keyDown());  // loop until all keys are up
#endif
    putEvent(0);
}

void doSplash()
{
    if(!g_eeGeneral.disableSplashScreen)
    {
      if(getSwitch(g_eeGeneral.lightSw,0) || g_eeGeneral.lightAutoOff)
        BACKLIGHT_ON;
      else
        BACKLIGHT_OFF;

      lcd_clear();
      lcd_img(0, 0, s9xsplash,0,0);
      refreshDisplay();
      lcdSetRefVolt(g_eeGeneral.contrast);
      clearKeyEvents();

#ifndef SIMU
      for(uint8_t i=0; i<32; i++)
        getADC_filt(); // init ADC array
#endif

#define INAC_DEVISOR 256   // Bypass splash screen with stick movement
      uint16_t inacSum = 0;
      for(uint8_t i=0; i<4; i++)
        inacSum += anaIn(i)/INAC_DEVISOR;

      uint16_t tgtime = get_tmr10ms() + SPLASH_TIMEOUT;  //2sec splash screen
      while(tgtime != get_tmr10ms())
      {
#ifdef SIMU
        if (!main_thread_running) return;
        sleep(1/*ms*/);
#else
        getADC_filt();
#endif
        uint16_t tsum = 0;
        for(uint8_t i=0; i<4; i++)
          tsum += anaIn(i)/INAC_DEVISOR;

        if(keyDown() || (tsum!=inacSum))   return;  //wait for key release

        if(getSwitch(g_eeGeneral.lightSw,0) || g_eeGeneral.lightAutoOff)
          BACKLIGHT_ON;
        else
          BACKLIGHT_OFF;
      }
    }
}

void checkLowEEPROM()
{
  if(g_eeGeneral.disableMemoryWarning) return;
  if(EeFsGetFree() < 200)
  {
    alert(PSTR("EEPROM low mem"));
  }
}

void alertMessages( const pm_char * s, const pm_char * t )
{
  lcd_clear();
  lcd_putsAtt(64-5*FW,0*FH,PSTR("ALERT"),DBLSIZE);
  lcd_puts_P(0,4*FH,s);
  lcd_puts_P(0,5*FH,t);
  lcd_puts_P(0,6*FH,  PSTR("Press any key to skip") ) ;
  refreshDisplay();
  lcdSetRefVolt(g_eeGeneral.contrast);

  clearKeyEvents();
}

void checkTHR()
{
  if(g_eeGeneral.disableThrottleWarning) return;

  int thrchn=(2-(g_eeGeneral.stickMode&1));//stickMode=0123 -> thr=2121

  int16_t lowLim = THRCHK_DEADBAND + g_eeGeneral.calibMid[thrchn] - g_eeGeneral.calibSpanNeg[thrchn];
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
int main(void)
{
  // G: The WDT remains active after a WDT reset -- at maximum clock speed. So it's
  // important to disable it before commencing with system initialisation (or
  // we could put a bunch more wdt_reset()s in. But I don't like that approach
  // during boot up.)
#if defined (PCBV3)
  mcusr_mirror = MCUSR; // save the WDT (etc) flags
  MCUSR = 0; // must be zeroed before disabling the WDT 
#else
  mcusr_mirror = MCUCSR;
  MCUCSR = 0;
#endif
  wdt_disable();

#if defined (PCBV4)
  // Initialise g_powerState or catch power down time-out and kill the power
  if (MCUSR & (1<<PORF)) g_powerState = PWR_STATE_RUNNING; // if powering up
  else if ((MCUSR & (1<<WDRF)) && (g_powerState == PWR_STATE_GOINGDOWN)) // if WDT during power down state
  {
    set_pwr_off();
    exit(1);
  }
#endif

  // Set up I/O port data directions and initial states
  DDRA = 0xff;  PORTA = 0x00; // LCD data

#if defined (PCBV4)
  DDRB = 0b11000111;  PORTB = 0b00111111; // 7:SPKR, 6:PPM_OUT,  5:TrainSW,  4:IDL2_SW, SDCARD[3:MISO 2:MOSI 1:SCK 0:CS]
  DDRC = 0x3f;  PORTC = 0xc0; // 7:AilDR, 6:EleDR, LCD[5,4,3,2,1], 0:BackLight
  DDRD = 0x00;  PORTD = 0b11111100; // 7/6:Spare3/4, 5:RENC2_PUSH, 4:RENC1_PUSH, 3:RENC2_B, 2:RENC2_A, 1:I2C_SDA, 0:I2C_SCL
  DDRE = 0b00001010;  PORTE = 0b11110100; // 7:PPM_IN, 6: RENC1_B, 5:RENC1_A, 4:USB_D+, 3:BUZZER, 2:USB_D-, 1:TELEM_TX, 0:TELEM_RX(pull-up off)
  DDRF = 0x00;  PORTF = 0x00; // 7-4:JTAG, 3:ADC_REF_1.2V input, 2-0:ADC_SPARE_2-0
  DDRG = 0b00010000;  PORTG = 0xff; // 7-6:N/A, 5:GearSW, 4: Sim_Ctrl[out], 3:IDL1_Sw, 2:TCut_Sw, 1:RF_Power[in], 0: RudDr_Sw 
  DDRH = 0b00110000;  PORTH = 0b11011111; // 7:0 Spare port [6:SOMO14D-BUSY 5:SOMO14D-DATA 4:SOMO14D-CLK] [2:VIB_OPTION -- setting to input for now]
  DDRJ = 0x00;  PORTJ = 0xff; // 7-0:Trim switch inputs
  DDRK = 0x00;  PORTK = 0x00; // anain. No pull-ups!
  DDRL = 0x80;  PORTL = 0x7f; // 7: Hold_PWR_On (1=On, default Off), 6:Jack_Presence_TTL, 5-0: User Button inputs
#else
#  if defined (PCBV3)
  DDRB = 0x97;  PORTB = 0x1e; // 7:AUDIO, SD_CARD[6:SDA 5:SCL 4:CS 3:MISO 2:MOSI 1:SCK], 0:PPM_OUT
  DDRC = 0x3f;  PORTC = 0xc0; // PC0 used for LCD back light control
  DDRD = 0x0F;  PORTD = 0xff; // 7:4=inputs (keys/trims, pull-ups on), 3:0=outputs (keyscan row select)
#  else
  DDRB = 0x81;  PORTB = 0x7e; //pullups keys+nc
  DDRC = 0x3e;  PORTC = 0xc1; //pullups nc
  DDRD = 0x00;  PORTD = 0xff; //pullups keys
#  endif
  DDRE = (1<<OUT_E_BUZZER);  PORTE = 0xff-(1<<OUT_E_BUZZER); //pullups + buzzer 0
  DDRF = 0x00;  PORTF = 0x00; //anain
  DDRG = 0x10;  PORTG = 0xff; //pullups + SIM_CTL=1 = phonejack = ppm_in
#endif

  lcd_init();

  ADMUX=ADC_VREF_TYPE;
  ADCSRA=0x85; // ADC enabled, pre-scaler division=32 (no interrupt, no auto-triggering)
#if defined (PCBV4)
  ADCSRB=(1<<MUX5);
#endif

  /**** Set up timer/counter 0 ****/
#if defined (PCBV3)
  /** Move old 64A Timer0 functions to Timer2 and use WGM on OC0(A) (PB7) for spkear tone output **/

  // TCNT0  10ms = 16MHz/1024/156(.25) periodic timer (100ms interval)
  //        cycles at 9.984ms but includes 1:4 duty cycle correction to /157 to average at 10.0ms
  TCCR2B  = (0b111 << CS20); // Norm mode, clk/1024 (differs from ATmega64 chip)
  OCR2A   = 156;
  TIMSK2 |= (1<<OCIE2A) |  (1<<TOIE2); // Enable Output-Compare and Overflow interrrupts

  // Set up Phase correct Waveform Gen. mode, at clk/64 = 250,000 counts/second
  // (Higher speed allows for finer control of frquencies in the audio range.)
  // Used for audio tone generation
  TCCR0B  = (1<<WGM02) | (0b011 << CS00);
  TCCR0A  = (0b01<<WGM00);

#else

# if defined (BEEPSPKR)
  // TCNT0  10ms = 16MHz/1024/2(/78) periodic timer (for speaker tone generation)
  //        Capture ISR 7812.5/second -- runs per-10ms code segment once every 78
  //        cycles (9.984ms). Timer overflows at about 61Hz or once every 16ms.
  TCCR0  = (0b111 << CS00);//  Norm mode, clk/1024
  OCR0 = 2;
# else
  // TCNT0  10ms = 16MHz/1024/156 periodic timer (9.984ms)
  // (with 1:4 duty at 157 to average 10.0ms)
  // Timer overflows at about 61Hz or once every 16ms.
  TCCR0  = (0b111 << CS00);//  Norm mode, clk/1024
  OCR0 = 156;
# endif

  TIMSK |= (1<<OCIE0) |  (1<<TOIE0); // Enable Output-Compare and Overflow interrrupts
  /********************************/

#endif

  // TCNT1 2MHz counter (auto-cleared) plus Capture Compare int.
  //       Used for PPM pulse generator
  TCCR1B = (1 << WGM12) | (2<<CS10); // CTC OCR1A, 16MHz / 8
  // not here ... TIMSK1 |= (1<<OCIE1A); ... enable immediately before mainloop

  // TCNT3 (2MHz) used for PPM_IN pulse width capture
#if defined (PPMIN_MOD1) || (defined (PCBV3) && !defined (PCBV4)) 
  // Noise Canceller enabled, pos. edge, clock at 16MHz / 8 (2MHz)
  TCCR3B  = (1<<ICNC3) | (1<<ICES3) | (0b010 << CS30);
#else
  // Noise Canceller enabled, neg. edge, clock at 16MHz / 8 (2MHz) (Correct for PCB V4.x+ also)
  TCCR3B  = (1<<ICNC3) | (0b010 << CS30);
#endif

#if defined (PCBV3)
  TIMSK3 |= (1<<ICIE3);         // Enable Timer 3 (PPM_IN) capture event interrupt
#else
  ETIMSK |= (1<<TICIE3);
#endif


  // Init Stack while interrupts are disabled
#define STACKPTR     _SFR_IO16(0x3D)
  {
    unsigned char *p ;
    unsigned char *q ;

    p = (unsigned char *) STACKPTR ;
    q = &__bss_end ;
    p -= 2 ;
    while ( p > q )
    {
      *p-- = 0x55 ;
    }
  }

  g_menuStack[0] = menuMainView;
  g_menuStack[1] = menuProcModelSelect;

  lcdSetRefVolt(25);

  sei(); // interrupts needed for FRSKY_Init and eeReadAll.

#if defined (FRSKY) and !defined (DSM2)
  FRSKY_Init();
#endif

#if defined (DSM2) and !defined (FRSKY)
  DSM2_Init();
#endif

#ifdef JETI
  JETI_Init();
#endif

  eeReadAll();

  uint8_t cModel = g_eeGeneral.currModel;


  if (~mcusr_mirror & (1 << WDRF)) { // Avoid splash screen etc if reset was caused by WDT
    doSplash();
    checkLowEEPROM();

    getADC_single();
    checkTHR();

    checkSwitches();
    checkAlarm();
  } 

  clearKeyEvents(); //make sure no keys are down before proceeding

  perOut(g_chans512, getFlightPhase());

  lcdSetRefVolt(g_eeGeneral.contrast);
  g_LightOffCounter = g_eeGeneral.lightAutoOff*500; //turn on light for x seconds - no need to press key Issue 152

  if(cModel!=g_eeGeneral.currModel) eeDirty(EE_GENERAL); // if model was quick-selected, make sure it sticks

#if defined (PCBV3)
// Initialise global unix timestamp with current time from RTC chip on SD card interface
  RTC rtc;
  struct gtm utm;
  rtc_gettime(&rtc);
  utm.tm_year = rtc.year - 1900;
  utm.tm_mon =  rtc.month - 1;
  utm.tm_mday = rtc.mday;
  utm.tm_hour = rtc.hour;
  utm.tm_min =  rtc.min;
  utm.tm_sec =  rtc.sec;
  utm.tm_wday = rtc.wday - 1;
  g_unixTime = mktime(&utm);
#endif

#if defined (PCBV4)
  /***************************************************/
  /* Rotary encoder interrupt set-up (V4 board only) */

  // All external interrupts initialise to disabled. But maybe not after 
  // a WDT or BOD event? So to be safe ...
  EIMSK = 0; // disable ALL external interrupts.

  // encoder 1
  EICRB = (1<<ISC60) | (1<<ISC50); // 01 = interrupt on any edge
  EIFR = (3<<INTF5); // clear the int. flag in case it got set when changing modes

  // encoder 2
  EICRA = (1<<ISC30) | (1<<ISC20); // do the same for encoder 1
  EIFR = (3<<INTF2);

  EIMSK = (3<<INT5) | (3<<INT2); // enable the two rot. enc. ext. int. pairs.
  /***************************************************/
#endif

  startPulses();

  wdt_enable(WDTO_500MS);
/*** Keep this code block directly before the main loop ****/
/***********************************************************/

#if defined (PCBV4)
  set_pwr_on(); // lock power on for soft-off operation
#endif

  uint8_t pwrDebounce = 0;
  while(1){
    uint16_t t0 = getTmr16KHz();
    getADC[g_eeGeneral.filterInput]();
    getADC_bandgap();
    perMain();
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

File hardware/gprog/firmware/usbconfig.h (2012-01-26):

/* Name: usbconfig.h
 * Project: AVR USB driver
 * Author: Christian Starkjohann, Thomas Fischl
 * Creation Date: 2005-04-01
 * Tabsize: 4
 * Copyright: (c) 2005 by OBJECTIVE DEVELOPMENT Software GmbH
 * License: GNU GPL v2 (see License.txt) or proprietary (CommercialLicense.txt)
 */

#ifndef __usbconfig_h_included__
#define __usbconfig_h_included__

/*
General Description:
This file contains parts of the USB driver which can be configured and can or
must be adapted to your hardware.

Please note that the usbdrv contains a usbconfig-prototype.h file now. We
recommend that you use that file as a template because it will always list
the newest features and options.
*/

/* ---------------------------- Hardware Config ---------------------------- */

#define USB_CFG_IOPORTNAME      B
/* This is the port where the USB bus is connected. When you configure it to
 * "B", the registers PORTB, PINB and DDRB will be used.
 */
#define USB_CFG_DMINUS_BIT      0
/* This is the bit number in USB_CFG_IOPORT where the USB D- line is connected.
 * This may be any bit in the port.
 */
#define USB_CFG_DPLUS_BIT       1
/* This is the bit number in USB_CFG_IOPORT where the USB D+ line is connected.
 * This may be any bit in the port. Please note that D+ must also be connected
 * to interrupt pin INT0!
 */
#define USB_CFG_CLOCK_KHZ  12000
/* Clock rate of the AVR in MHz. Legal values are 12000, 16000 or 16500.
 * The 16.5 MHz version of the code requires no crystal, it tolerates +/- 1%
 * deviation from the nominal frequency. All other rates require a precision
 * of 2000 ppm and thus a crystal!
 * Default if not specified: 12 MHz
 */

/* ----------------------- Optional Hardware Config ------------------------ */

/* #define USB_CFG_PULLUP_IOPORTNAME   D */
/* If you connect the 1.5k pullup resistor from D- to a port pin instead of
 * V+, you can connect and disconnect the device from firmware by calling
 * the macros usbDeviceConnect() and usbDeviceDisconnect() (see usbdrv.h).
 * This constant defines the port on which the pullup resistor is connected.
 */
/* #define USB_CFG_PULLUP_BIT          4 */
/* This constant defines the bit number in USB_CFG_PULLUP_IOPORT (defined
 * above) where the 1.5k pullup resistor is connected. See description
 * above for details.
 */

/* --------------------------- Functional Range ---------------------------- */

#define USB_CFG_HAVE_INTRIN_ENDPOINT    0
/* Define this to 1 if you want to compile a version with two endpoints: The
 * default control endpoint 0 and an interrupt-in endpoint 1.
 */
#define USB_CFG_HAVE_INTRIN_ENDPOINT3   0
/* Define this to 1 if you want to compile a version with three endpoints: The
 * default control endpoint 0, an interrupt-in endpoint 1 and an interrupt-in
 * endpoint 3. You must also enable endpoint 1 above.
 */
#define USB_CFG_IMPLEMENT_HALT          0
/* Define this to 1 if you also want to implement the ENDPOINT_HALT feature
 * for endpoint 1 (interrupt endpoint). Although you may not need this feature,
 * it is required by the standard. We have made it a config option because it
 * bloats the code considerably.
 */
#define USB_CFG_INTR_POLL_INTERVAL      10
/* If you compile a version with endpoint 1 (interrupt-in), this is the poll
 * interval. The value is in milliseconds and must not be less than 10 ms for
 * low speed devices.
 */
#define USB_CFG_IS_SELF_POWERED         0
/* Define this to 1 if the device has its own power supply. Set it to 0 if the
 * device is powered from the USB bus.
 */
#define USB_CFG_MAX_BUS_POWER           50
/* Set this variable to the maximum USB bus power consumption of your device.
 * The value is in milliamperes. [It will be divided by two since USB
 * communicates power requirements in units of 2 mA.]
 */
#define USB_CFG_IMPLEMENT_FN_WRITE      1
/* Set this to 1 if you want usbFunctionWrite() to be called for control-out
 * transfers. Set it to 0 if you don't need it and want to save a couple of
 * bytes.
 */
#define USB_CFG_IMPLEMENT_FN_READ       1
/* Set this to 1 if you need to send control replies which are generated
 * "on the fly" when usbFunctionRead() is called. If you only want to send
 * data from a static buffer, set it to 0 and return the data from
 * usbFunctionSetup(). This saves a couple of bytes.
 */
#define USB_CFG_IMPLEMENT_FN_WRITEOUT   0
/* Define this to 1 if you want to use interrupt-out (or bulk out) endpoint 1.
 * You must implement the function usbFunctionWriteOut() which receives all
 * interrupt/bulk data sent to endpoint 1.
 */
#define USB_CFG_HAVE_FLOWCONTROL        0
/* Define this to 1 if you want flowcontrol over USB data. See the definition
 * of the macros usbDisableAllRequests() and usbEnableAllRequests() in
 * usbdrv.h.
 */

/* -------------------------- Device Description --------------------------- */
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

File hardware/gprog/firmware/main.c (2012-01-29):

/*
 * USBasp - USB in-circuit programmer for Atmel AVR controllers
 *
 * Thomas Fischl <tfischl@gmx.de>
 *
 * License........: GNU GPL v2 (see Readme.txt)
 * Target.........: ATMega88 at 12 MHz
 * Creation Date..: 2005-02-20
 * Last change....: 2009-02-28
 *
 * PC2 SCK speed option.
 * GND  -> slow (8khz SCK),
 * open -> software set speed (default is 375kHz SCK)
 */

#include <avr/io.h>
#include <avr/interrupt.h>
#include <avr/pgmspace.h>
#include <avr/wdt.h>

#include "usbasp.h"
#include "usbdrv.h"
#include "isp.h"
#include "clock.h"

static uchar replyBuffer[8];

static uchar prog_state = PROG_STATE_IDLE;
static uchar prog_sck = USBASP_ISP_SCK_AUTO;

static uchar prog_address_newmode = 0;
static unsigned long prog_address;
static unsigned int prog_nbytes = 0;
static unsigned int prog_pagesize;
static uchar prog_blockflags;
static uchar prog_pagecounter;

static uchar isp_status = 0; // 1 = ISP connection established. Used to change green LED behaviour

uchar usbFunctionSetup(uchar data[8]) {

	uchar len = 0;

	if (data[1] == USBASP_FUNC_CONNECT) {

          /*
		// set SCK speed
		if ((PINC & (1 << PC2)) == 0) {
			ispSetSCKOption(USBASP_ISP_SCK_8);
		} else {
			ispSetSCKOption(prog_sck);
		}
          */
                ispSetSCKOption(prog_sck);

		/* set compatibility mode of address delivering */
		prog_address_newmode = 0;

		//ledGreenOn(); // it pulses on and off in idle mode, so make it on for sure here.
                isp_status = 1;
                bufferOn();
                while (--len); // delay
		ispConnect();
		ledRedOn();

	} else if (data[1] == USBASP_FUNC_DISCONNECT) {
		ispDisconnect();
                while (--len); // delay
                bufferOff();
		ledRedOff();
                isp_status = 0;

	} else if (data[1] == USBASP_FUNC_TRANSMIT) {
		replyBuffer[0] = ispTransmit(data[2]);
		replyBuffer[1] = ispTransmit(data[3]);
		replyBuffer[2] = ispTransmit(data[4]);
		replyBuffer[3] = ispTransmit(data[5]);
		len = 4;

	} else if (data[1] == USBASP_FUNC_READFLASH) {

		if (!prog_address_newmode)
			prog_address = (data[3] << 8) | data[2];

		prog_nbytes = (data[7] << 8) | data[6];
		prog_state = PROG_STATE_READFLASH;
		len = 0xff; /* multiple in */

	} else if (data[1] == USBASP_FUNC_READEEPROM) {

		if (!prog_address_newmode)
			prog_address = (data[3] << 8) | data[2];

		prog_nbytes = (data[7] << 8) | data[6];
		prog_state = PROG_STATE_READEEPROM;
		len = 0xff; /* multiple in */

	} else if (data[1] == USBASP_FUNC_ENABLEPROG) {
		replyBuffer[0] = ispEnterProgrammingMode();
		len = 1;

	} else if (data[1] == USBASP_FUNC_WRITEFLASH) {

		if (!prog_address_newmode)
			prog_address = (data[3] << 8) | data[2];

		prog_pagesize = data[4];
		prog_blockflags = data[5] & 0x0F;
		prog_pagesize += (((unsigned int) data[5] & 0xF0) << 4);
		if (prog_blockflags & PROG_BLOCKFLAG_FIRST) {
			prog_pagecounter = prog_pagesize;
		}
		prog_nbytes = (data[7] << 8) | data[6];
		prog_state = PROG_STATE_WRITEFLASH;
		len = 0xff; /* multiple out */

	} else if (data[1] == USBASP_FUNC_WRITEEEPROM) {

		if (!prog_address_newmode)
			prog_address = (data[3] << 8) | data[2];

		prog_pagesize = 0;
		prog_blockflags = 0;
		prog_nbytes = (data[7] << 8) | data[6];
		prog_state = PROG_STATE_WRITEEEPROM;
		len = 0xff; /* multiple out */

	} else if (data[1] == USBASP_FUNC_SETLONGADDRESS) {

		/* set new mode of address delivering (ignore address delivered in commands) */
		prog_address_newmode = 1;
		/* set new address */
		prog_address = *((unsigned long*) &data[2]);

	} else if (data[1] == USBASP_FUNC_SETISPSCK) {

		/* set sck option */
		prog_sck = data[2];
		replyBuffer[0] = 0;
		len = 1;
	}

	usbMsgPtr = replyBuffer;

	return len;
}

uchar usbFunctionRead(uchar *data, uchar len) {

	uchar i;

	/* check if programmer is in correct read state */
	if ((prog_state != PROG_STATE_READFLASH) && (prog_state
			!= PROG_STATE_READEEPROM)) {
		return 0xff;
	}

	/* fill packet */
	for (i = 0; i < len; i++) {
		if (prog_state == PROG_STATE_READFLASH) {
			data[i] = ispReadFlash(prog_address);
		} else {
			data[i] = ispReadEEPROM(prog_address);
		}
		prog_address++;
	}

	/* last packet? */
	if (len < 8) {
		prog_state = PROG_STATE_IDLE;
	}

	return len;
}

uchar usbFunctionWrite(uchar *data, uchar len) {

	uchar retVal = 0;
	uchar i;

	/* check if programmer is in correct write state */
	if ((prog_state != PROG_STATE_WRITEFLASH) && (prog_state
			!= PROG_STATE_WRITEEEPROM)) {
		return 0xff;
	}

	for (i = 0; i < len; i++) {

		if (prog_state == PROG_STATE_WRITEFLASH) {
			/* Flash */

			if (prog_pagesize == 0) {
				/* not paged */
				ispWriteFlash(prog_address, data[i], 1);
			} else {
				/* paged */
				ispWriteFlash(prog_address, data[i], 0);
				prog_pagecounter--;
				if (prog_pagecounter == 0) {
					ispFlushPage(prog_address, data[i]);
					prog_pagecounter = prog_pagesize;
				}
			}

		} else {
			/* EEPROM */
			ispWriteEEPROM(prog_address, data[i]);
		}

		prog_nbytes--;

		if (prog_nbytes == 0) {
			prog_state = PROG_STATE_IDLE;
			if ((prog_blockflags & PROG_BLOCKFLAG_LAST) && (prog_pagecounter
					!= prog_pagesize)) {

				/* last block and page flush pending, so flush it now */
				ispFlushPage(prog_address, data[i]);
			}

			retVal = 1; // Need to return 1 when no more data is to be received
		}

		prog_address++;
	}

	return retVal;
}
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

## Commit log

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2011-10-21 Very first draft of the new Rx de-multiplexer board. This is designed for model boat people to enable them to split one channel into eight at the expense of latency.
    It has 8 outputs to drive servos, and 8 500mA digital outputs (of which 4 are PPM capable). It will only be an 8 channel de-multiplexer so servo output 1 and digital output 1 will be controlled by the same input, etc.
    I have done it this way to avoid having to have a de-multiplexer board for digital and one for servos.
    You can drive the digital and servo outputs from the Rx battery or another battery, selected via switches.
    This design may change a lot at this stage, it needs to be tested, and so far no firmware exists !
    TOD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
    [g9x_rx_mpx.brd, g9x_rx_mpx.sch]
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2011-11-08 Correction for issue 69 ported in trunk. The other bug in DR/EXPOS screen will follow to-morrow.
    [gruvin9x.cpp]
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2011-11-16 I rename the 2 pointers to pulses2MHz array: pulses2MHzWPtr for write (producer), pulses2MHz for read (and send to OCR1A/OCR1B, consumer). And I changed the condition for filling again the array (don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
    [pulses.cpp]
2011-11-18 Some RAM saved in getADC functions (port from er9x). Work preparation for the 2nd timer. Reverse throttle issue 14 solved. Bug in mixer delays. PPM frame length configurable.
    [gruvin9x.cpp, pulses.cpp]
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2011-11-21 Revert the ASM code before Bryan gets up ;) Some more changes in DSM2 code for Cam
    [pulses.cpp]
2011-11-22 Smooth transition between flight phases was not working. Default flight mode is called FP0, not FP1.
    [gruvin9x.cpp]
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2011-11-23 Minor correction to GPRO v1.0 Schematic and component library.
    [gprog.sch]
2011-11-24 As advised by JWB, corrected GPROG (USBasp) programmer circuit.
    Only pull-up D- to tell USB host we are a slow speed device. Changed resistor
    to 3K6 from 5K6 for better voltage matching, in theory.
    [gprog.sch]
2011-11-25 Issues with current model during copy / move operations in MODELSEL menu.
    [gruvin9x.cpp, gtests.cpp]
2011-11-25 EEPROM async write on simu... the remaining bug has been tracked and found with it.
    [drivers.cpp, gruvin9x.h, gtests.cpp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]
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2011-11-26 gPROG: Fixed errors in schematic. Completed PCB to 'final draft'.
    [$savepcb.brd, gprog.brd, gprog.sch]
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2011-11-27 gPROG: Definitely not the final version. How could it be? It never is. :-/
    (Lower right screw hole was too close to board edge. Extended edge down slightly.
    [gprog.brd]
2011-11-29 Increased bandgap reference read delay for stock 9Xs. See Issue 76
    [gruvin9x.cpp]
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2011-12-08 Minor changes to avoid infinite loops inside companion9x
    [gruvin9x.cpp, simpgmspace.h]
2011-12-08 Issue 80 solved. To be improved later in trunk.
    [gruvin9x.cpp]
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2011-12-12 Non regression test for 0 division issue in flight phases switch
    [gtests.cpp, simpgmspace.h]
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2011-12-13 Major changes to gprog, after prototype revealed multiple problems. Also reverted to TQFP-32 package instead of QFN/MLF.
    [$savepcb.brd, gprog.brd, gprog.sch]
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2011-12-14 Added a SIMU_EXCEPTIONS definition for allowing asserts (and on Linux all SIGFPE/SIGSGF ...) to be displayed in c9x as errors in a MessageBox. It's better than crashing the whole tool and will allow 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
    [simpgmspace.h]
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2011-12-20 GPROG: Auxilary access corrected for Gerber output. Production files generated and sent to supplier for 40-off quote.
    [gprog-Back.gbl, gprog-Front.gtl, gprog-Mask_Back.gbs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]
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2011-12-23 gprog: OK. I give up. This is probably still not the final. But it will get frozen soon, once I've sent the actual order off. :-D +5V tracks for MCU widened. COuple of vias moved to give better clear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
    bootloader: Must have forgotten to commit the v4.1 soft-off patch. Here it is.
    [gprog.brd]
2011-12-25 gprog: This won't be the final version. No way. Not gonna happen. There'll be more changes, for sure.
    Moved a via slightly further away from a widened track.
    [gprog.brd]
2011-12-26 GPROG: version 1.00 has finally been frozen and sent to factory for fabrication. Let's hope I didn't mess anything up.
    [gprog-Back.gbl, gprog-Front.gtl, gprog-Mask_Back.gbs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]
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2012-01-09 Correction to lfuse 'default' value (bit 7 of lfuse was inverted.) Thanks to Martial Guex for the heads up!
    (I've actually changed it from 62 to 0xd7. I cannot fathom now where 0x62 came
    from. Perhaps other inverted bits. In any case, 0xd7 is what I use.)
    No actual changes to gprog.brd. Ignore it for this commit.
    [gprog.brd]
2012-01-09 DSM2 - APM dsm2_bind[] array should be read using pgm_read_byte() otherwise bind wasn't working. Need to implement model match currently everything is model 0. Also need to allow throttle position th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
    [pulses.cpp]
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2012-01-09 DSM2 - Fail safe and model match working. Point of notes: 1) The Rx channel order needs to be TAER, certainly the throttle needs to be first for the failsafe to work. 2) The model number is really th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
    [pulses.cpp]
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2012-01-23 Hmmm. Just in case I didn't save this file before committing last time.
    [gprog.brd]
2012-01-25 gPROG: Latest code for the current PCB. Alas, actual programming is not working. But at least the USB part is doing its thing now.
    The problem is most likely the buffer chip -- somehow. When I've had some
    sleep, I try bipassing it. In fact, my vote is to remove it entirely,
    since it's just not needed -- becasue the ATmega48/88 chips seem do a
    fine job of going high-Z when powered off, all by themselves.
    This version has fancy blinky LED status stuff going on, which came about
    mostly for debugging purposes.
    The USB 'Manufacturer' data has been change to gruvin9x.googlecode.com.
    [isp.c, main.c, usbasp.h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]
2012-01-26 gPROG: Had to revert USB Manufacturer(Vendor) Name back so that AVRDUDE will recognise us as a USBasp
    PCB -- added a big, fat "+" symbol to pin 1 of the USB pin header.
    [gprog.brd, gprog.sch]
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2012-01-26 gprog: Added delay after bufferOn/Off() calls to allow logic levels to settle. Seems to have improved short read operations, but still no joy with flash programming.
    [main.c]
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2012-01-29 gprog schematic, PCB & firmware updated to v1.2 -- final release candidate 2
    This is the version with the fixes to the moumental screw-ups made
    by myself, as discovered 2012-01-29. This should now be the final
    prodcution version.
    [gprog.brd, gprog.sch]
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2012-02-01 v4.1 PCB [trunk] -- Cam: Please check my work. Had to move some tracks. PBS pad size/holes increased to 2.2 x 1.1mm to allow installation of switches without pin flattening/pliers/etc (factory). Vers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
    (These holes were always too small, requiring work with pliers to make
    the pins fit (snuggly!) I had not considered the problem this might
    be for a factory production team, because I frankly never believed
    we'd get that far. Go figure! :-)
    [gruvin9x.brd]
2012-02-09 Finally getting around to working on the SD card logging system.
    I've made a number of changes to the telemtry display, as well as changing some
    logging related variable names and text to my personally preferred English
    variants.
    At present, enough has been done to prove that there is no apparent harm (lag
    etc) to PPM control when a log file is being written to once every
    perMain(). This is obviously pleasing. But further testing -- with longer log
    line and computation/string mannipulation and all that being done, instead of
    just writing a short line each time around.
    If anyone wants to test this for themselves, you just need to have your
    FAT16/32 formatted SD/MMC card installed and assign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
    [gruvin9x.cpp, gruvin9x.h]
2012-02-09 #include <logs.h> was called twice in the same file. I suppose that you wanted to remove the second. Now companion9x compiles and gruvin9x should not be broken. But it still misses the logs.h file!
    [gruvin9x.h]
2012-02-11 PROGMEM fix to support newer AVR-GCC versions, thanks to @mihlit.
    See Issue 90 Comment #9 (http://code.google.com/p/gruvin9x/issues/detail?id=90#c9)
    for full details.
    Following is a record of the patch application and the resulting (still) clean compile ...
    ----
    trunk$ patch -p0 < ~/Desktop/pgmfix.patch
    patching file firmware/src/lcd.cpp
    patching file firmware/src/simpgmspace.h
    patching file firmware/src/general_menus.cpp
    patching file firmware/src/menus.cpp
    patching file firmware/src/s9xsplashv4.lbm
    patching file firmware/src/lcd.h
    patching file firmware/src/font_dblsize.lbm
    patching file firmware/src/sticks.lbm
    patching file firmware/src/font.lbm
    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
    [drivers.cpp, gruvin9x.cpp, gruvin9x.h]
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2012-02-13 Minor changes (mostly comments).
    Change DSM2_Init to enable, not disable the RX data pin pull-up resistor.
    Never leave an input pin floating. Noise on such pins can cause the MCU to
    crash. I also have plans to use this as a digital input to activate
    range-check mode, using the button in my DSM2 module. More on that later.
    [pulses.cpp]
2012-02-14 Addresed the following error compiling SIMU
    gruvin9x.cpp:475:17: error: invalid suffix "b11000000" on integer constant
    Simu now compiles on my systems without error BUT, it doesn't seem to
    acknowledge any key-presses any more -- specifically the cursor keys
    for [UP] ... [EXIT] etc. :/ The line I change relates to keyboard input.
    But I cannot see how it would affect anything going on in Simu itself. If
    it does, well, it shouldn't, I guess. How to fix?
    - - - -
    Removed over 60 occuraences of CR (^M) at line ends in gruvin9x.cpp.
    Windows users PLEASE don't use editors that insert CR's at the end of lines.
    All source files are to have LF only. (If it looks right in Notepad --
    then it's W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
    [gruvin9x.cpp]
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2012-02-15 Makefile.dist changed (again) to fix oversight by Gruvin is last change. Subversion revision reports can have M and/or S appended -- not only M. So now we simply accept any number (including zero) of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
    pulses.cpp ... nothing changed? Not sure why it's included here.
    [pulses.cpp]
2012-02-15 Main PCB version bumped to v4.2. Changes to pseudo RS-232 buffer circuit around Q2 and Q3.
    Changes (tested) have been made to imporve output waveform shapes at higher
    baudrates, such as that used for DSM2 (125,000 Baud.) This only affects the use
    of the pseudo RS-232 output, as opposed to the TTL output. This is desired when
    both Fr-Sky and DSM2 external plug-in modules are used and one doesn't want to
    have to modify the Fr-Sky module internally. In other words, both modules can
    be operated off the same (pseudo) RS-232 TX.RX port. (The DSM2 module requires
    an additional (preferably high-speed) transistor to re-invert and level shift
    serial data to 3.3V TTL. Gruvin got away with a carefully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
    [gruvin9x.brd, gruvin9x.sch]
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2012-02-21 Stock re-ordering time for SD card boards. Created new production files to include the recent (minor) corrections. (Didn't want to create a whole new archive 'frozen' folder just for this. So left th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
    [sdcard-Back.gbl, sdcard-Front.gtl, sdcard-Mask_Back.gbs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]
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2012-04-01 Hmmm ... "Save before exit?" ... I may have not saved the last changes to the v4.2 board before the previous commit. I really must get into the habit of closing work files before I commit, to prevent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
    [gruvin9x.brd]
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2012-04-03 Removed bad code causing low bat alarm to not sound under 4.9V.
    Will now check brancehs/frsky for smae fault and raise a new issue if found.
    [gruvin9x.cpp]
2012-04-03 Bandgap and low batt alarm improvements ported work on same in branches/frsky. TEST=DEBUG option added to make directives to effect a -DDEBUG in CPPDEFs. (Couldn't use DEBUG= as it's used for other t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
    [gruvin9x.cpp, gruvin9x.h]
2012-04-03 MAIN BOARD v4.2 CHANGES (continued)
    . USB connector K6 flipped to make pin 1 GND
    PCB
    ===
    . PORTH 'hack pads' (P20) upgraded to 10-pin IDC header. Required significant re-working of components to the left to provide room.
    . 'Fat track thermal sink' issues address over the entire board (reduced track thickness to small part pads where practical.)
    . Several cases of 'ground looping' resolved. (Use single, common tie points instead of 'loops' whenever possible.)
    . A number of right-angle track bends resolved to 45-degrees. (Sharp corners can cause problems with copper etching.)
    . GND and VCC via drill size increased to 0.7mm and updated across the board, where practical. (Bound to have missed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
    [gruvin9x.brd, gruvin9x.sch]
2012-04-04 Corrections to make the board pass DRC and copper re-pour. Also D4 was missing a GND connection.
    [gruvin9x.brd]
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2012-04-05 MAIN BOARD v4.2
    A few minor tweaks -- some ground plane vias fixed. No doubt still some minor
    issues to be found and rememedied.
    Right now, I'm now at all confident to run this new version straight to the
    factory. With the number of changes, the potential for an unseen error is just
    too great. So I need to push for a v4.2-frozen over the coming week and get
    some boards ordered, for a manual build.
    Yay \o/ :/ At least I'm better set up for it now, compared to in the past. Will
    still be agood 5 to 7 hours though. So tempting to just trust my work and go to
    production.
    Any votes the other way, anyone? We've actaully never had a board design fault
    in the past -- only schematic changes, which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
    [gruvin9x.brd]
2012-04-05 From Farnell, via Mr. Kaban ...
    ...
    Original Product
    Product Notification Reason NO LONGER STOCKED
    Farnell Order Code 1679975
    Product Description DIODE, ZENER, SOD-523, 3.6V
    Manufacturer/Brand Name ROHM
    Manufacturer Part No. EDZTE613.6B
    Purchase Order Number 57/01/2012 11:36
    Date of Your Last Order 10/01/2012
    Qty Ordered Last 6 Months 5
    Stock Availability 1545
    There is no suitable alternative for this product.
    ...
    "...no replacement...". Hmmm. Rubbish. They're being lazy is all. For now, I've just
    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
    [gruvin9x-bom.xls]
2012-04-13 Rx MPX board - The reason the PCB's hadn't arrived were the PCB house spotted some mistakes (then forgot to mention them).
    Some of the new through hole components for this board had no solder resist mask, the 3mm LED and the dip switches. The LED is a stock KiCAD library item to !
    [g9x_rx_mpx-Back.gbl, g9x_rx_mpx-Front.gtl, g9x_rx_mpx-Mask_Back.gbs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]
2012-04-16 MAIN BOARD v4.2
    - Corrected NZ element14 BOM JST header/housing parts (v4.1a frozen)
    - Added NZ element14 BOM (v4.2 assembly)
    - Updated v4.2 board silk screen to read v4.2 (instead of v4.1)
    [V4_2 BOM-e14nz.xls, gruvin9x.brd]
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2012-04-25 PCB v4.1a frozen: Updated/Corrected main XLS BOM
    PCM v4.2: Updated main XLS BOM to include note about recently found eBay seller with
    JST PH 2.0mm pre-wired connectors.
    [gruvin9x-bom.xls]
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2012-05-17 Apparently, my previous commit of the v4.2 frozen folder did not complete successfully, but I didn't realise. :/ This is a recommit of that -- but with changes as follows ...
    . Added R118 in series with C63 to fix intermittent fault with soft-off
    circuitry. (Credit and thanks to x3mfly for this discovery and debug.)
    . Added the AGND 'component' to the gruvin.lib shared module library. It
    was missing for some reason, which was noticed when the net name for
    AGND didn't seem to exist in PCBNEW, which in turn caused some brief
    confusion when re-laying tracks for R118.
    . The above was all done in the so-called 'frozen' folder, s the changes
    were copied back to our current trunk/hardwa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
    [gruvin9x-bom.xls, gruvin9x.brd, gruvin9x.sch]
2012-05-18 Pad added to allow easier connection to C-of-Q9 for short-to-ground power-on at trainer jack, should it be required.
    Production files including updated BOM (for R118) still to come.
    [gruvin9x-bom.xls, gruvin9x.brd, gruvin9x.sch]
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2012-05-29 Fixed watch dog timer reset event's failure to reboot properly. (This remains a problem in the current 'stable' release and probably open9x as well.)
    The cause of the WDT reset fault turned out to be how the WDT is automatically
    reset to "active with minimum time period" when the reset occurs. This resulted
    in the WDT reset re-firing continuously, before we got around to setting it to
    500ms period. I guess the last time I tested this, there must have been not
    quite so many C variables begin cleared and what have you, so we snuck in under
    the time limit. (It was a long time ago.)
    Started soft-off implementation. It just powers off immediately at present. I
    haven't looked at how it was done i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
    [gruvin9x.cpp, gruvin9x.h]
2012-05-29 Soft-off fully implemented. Features include ...
    + Power switch indicator flags are debounced.
    + "MESSAGE -- Powering off ..." displays for 1.3s.
    + User can abort the power down by reconnecting/switching power
    (full WDT timer reset used to ensure full system initialisation).
    + Watchdog timer allows 2 seconds before giving up waiting for file
    closure, to ensure power goes off no matter.
    CAVEAT: EEPROM writes are not actually checked for completion. Rather, it is
    assumed that 1.3 seconds will always be long enough. I'd like to improve this
    -- because I know that copying large models for example can take longer -- but
    don't yet know ow to check for EEPROM write activity.
    BTW -- I did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
    [drivers.cpp, gruvin9x.cpp, gruvin9x.h]
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2012-05-31 Started work on showing GPS distance from origin.
    Also ...
    + Fixed centering of "MESSAGE" on message screen. *shrug*
    + Changed centering and look of "1" in double size font.
    TODOs:
    + Test strange Fr-Sky dddmm.mmmm lat/long format to decimal degrees
    conversion (and compelte related code with origin, once available.)
    + Add "Reset origin" by pressing [MENU] (probably) on GPS screen. This
    will include GPS altitude at the same time. (Maybe it should also
    reset barometric sensor altitude. But that doesn't work at all right
    onmy system anyway. ("Bryan's satellite" still flies! :-/)
    + Add bearing calculation (compass bearing from origin to model's
    current GPS position. Not same as "hea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
    [gruvin9x.cpp]
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2012-07-19 Oops. Ran DRC and fixed zone fill. Tired. Need sleep. No -- need food, then sleep! *sigh*
    [sdcard-Back.gbl, sdcard-Front.gtl, sdcard-Mask_Back.gbs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]
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2012-08-15 SDCARD v4.2 Updates
    I'm preparing to get quotes from China to build the RTC/SD-card interface
    board -- hopefully much cheaper. Part of this required doing a proper job
    of the CMR200T barrel type xtal, so that part placement positioning data
    would be correct. Also tidied up the PCB design further. (There were some
    crazy, unneccesary vias done on my part previously -- confusion over what
    is and isn't in the way on the two layers.)
    I also consolidated file names and paths as well as splitting the sdcard
    BOM into two separate files, to be less confusing, hopefully.
    I'm going to get quotes for both the RTC/SD and gProg boards -- full
    assembly. Whether it works out ecconimical or sensible f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
    [gruvin9x-bom-ele14.xls, sdcard(uk+std)-bom.xls, sdcard-bom.xls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]
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2012-08-19 Bootloader now exiting to main application correctly. NOW can I start testing the USB stuff? :P
    [bootloaderconfig.h, main.c]
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2012-08-19 Some progress here ... but having problems with progmem access in usbdrv, I think.
    [bootloaderconfig.h, main.c, usbconfig.h]
2012-08-19 BOOTLOADER ready for prime time (I think)
    The bootloader finally works properly, having struggled half a day
    to figure out some bug in the V-USB USBaspBootloader original code,
    at least as far as larger than 64Kbyte Flash chips go. Yay \o/
    I've got the LCD display showing some status and current/last
    address, etc., which is kind of nice.
    So yeah ... so long as this bootloader is installed in the '2560 and
    protected, I no longer need the external gPro (USBasp) programmer. AND
    this one goes much faster. Cool.
    To use this thing, you just have to change the 0x11 fuse to 0x10 (to enable
    bootloader reset vector) then program the MCU with bootloader/main.hex.
    Now hold down [UP] and [DOWN] wh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
    [bootloaderconfig.h, main.c]
2012-08-19 BOOTLOADER
    The display problem was due to not even setting the contrast ref
    voltage. Oops.
    Added contrast up/down and back=light toggle to user interface.
    I think it's finally ready. More testing over time first though, of course.
    [main.c]
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2012-09-09 Fr-Sky / DSMX Caddy Board
    The intention here is to change from swapping TX modules on the back of the 9X
    to permanently installed Fr-Sky and DSMX modules, with two separate antennas
    mounted, one either side of the turret housing.
    @Cam -- any comments / suggestions / notes of error in design?
    [frsky_dsmx_caddy.sch]
2012-09-10 Fixed G9X v4.2 (trunk) 3D-setting for the six push button switches. *shrug*
    Started TX MOudle Caddy PCB layout.
    [frsky_dsmx_caddy.sch, gruvin9x.brd]
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2012-09-16 ================================ = Differences V4.1a to V4.2b/c = ================================
    -- Gruvin --
    . Added tracks to links pins 1 & 2 on both J1 and J4. In the unlikely event
    anyone ever wants the opposite option for either jumper, they can break the
    track. This will save time as well as the slightly unsightly solder-blob
    bridges I've been doing on all the retail boards to date.
    . v4.2c -- changed solder mask clearance to 0.0000, having been advised to
    let the factory use their own process-ideal clearances. This will mostly
    help for the 0.5mm pitch MCU and LCD socket parts.
    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
    [gruvin9x.brd, gruvin9x.sch]
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2012-09-17 DigiKey notifed obsolete part used in our BOM.
    NJM78L05UA-ND IC REG LDO 5V .1A SOT-89 NJR
    ... now replaced with ...
    296-13531-1-ND IC REG LDO 5V .1A SOT-89 TEXAS INSTRUMENTS
    [gruvin9x-bom.xls]
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2012-09-26 Mostly TX caddy work. This version is larger and facilitates mounting the DSMX module such that it lays over top of the caddy board, rather than floating off the end. This will use up less space. I a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
    There was also an error (missing track) in the v1.0 prototype. I
    decided not to bother building the circuit yet and will instead
    wait for the v1.1 boards to arrive. Fingers crossed for luck.
    I considered adding a little more circuitry to allow controlling
    the Fr-Sky 'togle switch' options, namely F/W Upgrade, One-way and
    Two-way modes. Probably shoul dhave done this now, rather than
    later ... but I just didn't.
    Added a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
    [frsky_dsmx_caddy-Back.gbl, frsky_dsmx_caddy-Drawings.gbr, frsky_dsmx_caddy-Front.gtl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]
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2012-10-24 TX_CADDY changes to v1.4.
    Essentially, this project is a right, royal FAILURE at this time. However,
    the circuitry as presented in this commit _appears_ to function correctly
    electrically, I have been unable to get the only available DSMX module
    to operate. I am unwillingly to break my working DSM2 module in order
    to test that it works -- though I presume it would, if the CRO readings
    are to be believed.
    [frsky_dsmx_caddy.brd, frsky_dsmx_caddy.sch]
2012-10-26 TX_CADDY (the saga continues)
    The comedy of oversights, stuff-ups and general failures to get a rediculously
    simple circuit to work properly continues. This time we introduce a 5V reg
    that can actually handle the task reliably. :-/
    [frsky_dsmx_caddy.brd, frsky_dsmx_caddy.sch]
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2012-12-04 Bootloader update to stop haptic motor running and to stop SOMO audio module saying the wrong phrase at transition from bootloader to main program.
    [bootloaderconfig.h]
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2013-08-05 Long overdue and now most likely pointless corrections to JST modules and 3D files.
    (I was designing yet another board using JST sockets and finally got sick
    of them being all out of whack! :-P)
    [gruvin9x.brd]
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

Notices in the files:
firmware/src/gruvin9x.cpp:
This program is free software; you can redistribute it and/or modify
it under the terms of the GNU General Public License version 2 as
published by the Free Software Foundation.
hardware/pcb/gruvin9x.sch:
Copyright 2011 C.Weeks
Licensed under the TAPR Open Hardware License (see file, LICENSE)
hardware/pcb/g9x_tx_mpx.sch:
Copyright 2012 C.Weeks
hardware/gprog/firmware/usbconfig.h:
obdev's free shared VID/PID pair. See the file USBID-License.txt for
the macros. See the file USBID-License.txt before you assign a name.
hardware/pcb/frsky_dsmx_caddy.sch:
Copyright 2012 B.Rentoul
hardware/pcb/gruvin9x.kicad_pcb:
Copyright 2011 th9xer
